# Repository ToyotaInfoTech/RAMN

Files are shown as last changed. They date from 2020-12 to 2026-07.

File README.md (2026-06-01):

# RAMN



RAMN (Resistant Automotive Miniature Network) is a miniature CAN/CAN-FD testbed of four Electronic Control Units (ECUs) consiting solely of Printed Circuit Boards. The ECUs can be programmed to emulate the same network traffic as [PASTA](https://github.com/pasta-auto/PASTA1.0), another project from our team. RAMN is powered over USB and can be recognized as a standard CAN adapter. It can be connected in closed-loop with the autonomous driving simulator [CARLA](https://github.com/carla-simulator/carla). What happens to the virtual vehicle has an impact on the physical CAN/CAN-FD bus, and vice versa. RAMN can be expanded with many stackable expansions, ranging from external quadSPI memories to Trusted Platform Modules (TPMs).

Please check the [Documentation](https://ramn.readthedocs.io/) for demonstrations and details.



## Fabricating RAMN boards

This project is open-source and RAMN boards can be fabricated by most PCB assembly prototyping services.

We have setup 're-orders' at PCBWay. 
Please [see the docs 'PCB Ordering' for more details](https://ramn.readthedocs.io/page/hardware/Fabrication/ordering.html).
You can also request a prototype from any PCB manufacturer, using the Gerber files and BOM in the Hardware folder. 

Feel free to [contact us](mailto:camille.gay@toyota.global) if you need assistance to fabricate or sell RAMN boards.

Because component availability is subject to change, we are periodically updating the hardware.
The original RAMN hardware data is available in misc/RAMN_V1_reference_PCB.zip, and is recommended for academic purposes.

## Project structure
### Hardware folder
Contains design files, from KiCAD project files to Gerber files and BOM.

### Scripts folder

Contains various scripts to interact with the ECUs:
- Driving Simulator
- Diagnostics (UDS/KWP2000/XCP)
- Hardware Bootloader
- Connection to a virtual CAN Network

### Firmware folder
Contains firmware source code for RAMN's ECUs.

## License
Please check the LICENSE.md file for more details.

## Contact
Feel free to [contact us](mailto:camille.gay@toyota.global) if you have questions.
Videos available [here](https://twitter.com/ramn_auto).

Copyright (c) 2026 TOYOTA MOTOR CORPORATION. ALL RIGHTS RESERVED.

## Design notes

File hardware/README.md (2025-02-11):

Please [see the docs 'Hardware' for more details](https://ramn.readthedocs.io/page/hardware.html).

# Creating New Orders from Updated Design Files

The PCBWay re-orders in the docs are based on the design files in this repo at commit dca0831d852cdd53b45b3e2c7c4c0430066c91ad . When changes are made to the design files here and new orders need to be made, the following procedure should be followed to created updated versions of the files in `orders/`:

[Install `kikit`](https://yaqwsx.github.io/KiKit/latest/installation/intro/) and run the script `make_orders.{bat|sh}` here from within KiCad 7.0 shell or [KiCad 7.0](https://yaqwsx.github.io/KiKit/latest/installation/intro/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) and follow the manual steps required printed to the console.

# Design Files

This project contains KiCAD projects for RAMN's hardware.

'Mainboard':
* 0_ramn

and 'Expansions':
* 1_screens
* 2_chassis
* 3_powertrain
* 4_body
* 5_debugger

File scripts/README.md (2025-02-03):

# Scripts

## Content

This folder contains various scripts to interact with RAMN over USB.

- the **build** folder contains scripts to automatically compile firmware for all 4 ECUs.
- the **carla** folder contains scripts to connect RAMN to the driving simulator CARLA.
- the **diagnostics** folder contains scripts to interact with RAMN's ECU over UDS, KWP and XCP.
- the **firmware** folder contains most recently built firmware files.
- the **settings** folder contains environment settings (e.g., serial port name, paths, etc.).
- the **STBootloader** folder contains scripts to interact with STM32 hardware bootloader.
- the **tests** folder contains scripts to perform reliability tests.
- the **vcand** folder contains scripts scripts to connect RAMN to a socketCAN virtual network (Linux only).

## Usage

Modify files in the **settings** folder to match your environment. After that, it should be possible to run the scripts without any argument.

*Copyright (c) 2025 TOYOTA MOTOR CORPORATION. ALL RIGHTS RESERVED.*

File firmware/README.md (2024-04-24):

# RAMN Firmware

This folder contains the firmware for RAMN V1. 
Documentation is available [here](https://ramn.readthedocs.io/en/latest/).

Copyright (c) 2024 TOYOTA MOTOR CORPORATION. ALL RIGHTS RESERVED.

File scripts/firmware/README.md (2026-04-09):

# Firmware

This folder contains firmware files for RAMNs ECUs. By default, this folder is used as output for the **build** scripts, and as input by the reprogram/verify **diagnostics** scripts.

## Variant firmware

Pre-built `.hex` files for firmware variants are available in subdirectories:

| Directory | Description |
|---|---|
| `gsusb/`  | GS_USB (candleLight) mode enabled on ECU A |
| `kwp/` | KWP2000 protocol enabled |
| `uart/` | UART enabled (CDC & USB disabled) |
| `watchdog/` | Hardware watchdog enabled |
| `no_uds/` | UDS and reprogramming disabled |
| `no_extras/` | J1979, MiniCTF, CHIP8, screen, SPI disabled |
| `no_debug/` | USB debug, joystick, screen, CHIP8, runtime stats disabled |
| `no_dynamic_bitrate/` | Dynamic CAN bitrate switching disabled |

Each subdirectory contains `ECUA.hex` through `ECUD.hex` for that variant configuration.
These files are automatically updated by CI on every push to `main`.

*Copyright (c) 2021 STMicroelectronics. All rights reserved.*
*Copyright (c) 2021 TOYOTA MOTOR CORPORATION. ALL RIGHTS RESERVED.*

**This software component is licensed by ST under BSD 3-Clause license, the "License"; You may not use this file except in compliance with the License. You may obtain a copy of the License at: opensource.org/licenses/BSD-3-Clause**

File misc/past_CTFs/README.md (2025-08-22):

# PAST CTFs DATA

This folder contains data to replay past CTFs that used RAMN as a platform for some of their challenges.

Write-ups are available in [RAMN's documentation](https://ramn.readthedocs.io/en/latest/ctf_writeups.html). 

# Recommended Order

If you are new to CTFs, we recommend that you tackle past CTFs in the following order:

- Automotive CTF Japan 2024 (Mostly Easy to Medium).
- Automotive CTF 2024 (Mostly Medium to Difficult).
- CHV2024 (Mostly Difficult to Very Difficult).
- ESV2025 (Mostly Difficult, not automotive related).
- ESV2024 (Mostly Very Difficult, not automotive related).

# Required Tools

A few challenges may require external hardware to complete (such as a CAN adapter, a UART/SPI/I2C/JTAG adapter, or a logic analyzer).
You can identify such challenges by their tags (e.g., "Hardware", "UART", "I2C", etc.).

# How To Flash CTF Firmware

Replace ``scripts/firmware`` with the ``firmware`` folder inside the CTF folder that you want to replay, then reflash the board using the scripts in ``scripts/STbootloader``.
On Linux, you may need to convert the ECUA.hex file to a .bin file (e.g., using ``objcopy -I ihex -O binary ECUA.hex ECUA.bin``).

The CTF firmware for ECU A may not have the abilitity to flash other ECUs, therefore **you must flash ECU B/C/D first, then flash ECU A**
(ECU A must be flashed with the original firmware to enable it to flash other ECUs).

# How To Revert RAMN to its Original Firmware

Firmware files have been recompiled in order to allow ECU A to go back to DFU mode and allow USB reflashing (a feature that was disabled during actual events).
To reset your RAMN board to the original firmware, revert ``scripts/firmware`` to its original content, then use the scripts in  ``scripts/STbootloader`` to reflash the ECUs.
**You must reflash ECU A first**.

**The ESV firmware does not start in slcan mode - you must first open a USB serial terminal and type ``selfdestruct``, which will put ECU A back in DFU mode**.

# About Memory Protection

To prevent flag dumping, STM32's (temporary) memory protection was typically activated for every ECU during the events. 
You can enable memory protection with the following commands, but note that **this is not required.** 

```
python ..\canboot.py AUTO B -rp
python ..\canboot.py AUTO C -rp
python ..\canboot.py AUTO D -rp --reset
```

You can use ``scripts/STbootloader/windows/Unlock_BCD.bat`` to remove that protection.
A JTAG adapter is required if you want to enable/disable memory protection for ECU A.

# About File Attachments

Some challenges have ECU firmware with redacted flags as an attachment.
As explained above, ECU A firmware was recompiled to allow it to revert to DFU mode. However, attachments correspond to the original firmware used in the event.
As a result, the redacted firmware files provided as attachments may not exactly match the flashed firmware files.

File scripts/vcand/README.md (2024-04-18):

# RAMN VCAND

This folder contains experimental scripts to connect RAMN to a socketCAN virtual CAN Network, while keeping the original serial interface accessible.

This feature is only available on Linux. It is similar to [slcand](https://github.com/linux-can/can-utils/blob/master/slcand.c), but with additional features:
- Supports CAN-FD
- Can forward the original serial I/O to one or two virtual serial port(s) (e.g., */dev/pts/x*)

Refer to [RAMN's documentation](https://ramn.readthedocs.io/) for details.

# Other

*Copyright (c) 2024 TOYOTA MOTOR CORPORATION. ALL RIGHTS RESERVED.*

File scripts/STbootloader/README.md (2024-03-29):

# Canboot

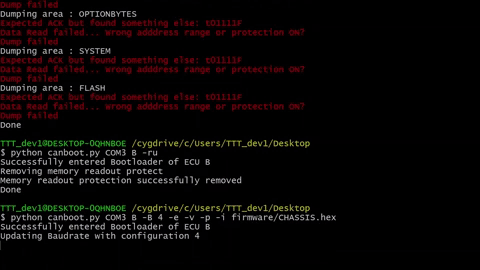
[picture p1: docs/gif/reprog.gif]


Canboot is a tool written in python to reprogram RAMN's ECUs over CAN using STM32's built-in CAN or CAN-FD bootloader. 

It can be used to reprogram ECUs B, C, and D. 

ECU A can be reprogrammed using DFU over USB.

Check the [Documentation](https://ramn.readthedocs.io/en/latest/hardware/Fabrication/flashing.html) for details.

## Usage

Usage is described in the help command of the script.

```
$python canboot.py --help
```

Helper scripts are located in **linux** and **windows** folder, to reprogram ECUs with the firmware files located  in the **firmware** folder. They require to input the serial port manually.

## Details

Microcontrollers of the STM32L5 family can be reprogrammed over CAN-FD based on STMicroelectronics [AN5405](https://www.st.com/resource/en/application_note/dm00660346-fdcan-protocol-used-in-the-stm32-bootloader-stmicroelectronics.pdf).  

Microcontrollers of the STM32L4 family can be reprogrammed over CAN based on STMicroelectronics [AN3154](st.com/resource/en/application_note/cd00264321-can-protocol-used-in-the-stm32-bootloader-stmicroelectronics.pdf). Script for classic CAN is located in the BETA folder.

Microcontrollers of the STM32L4/STM32L5 can be reprogrammed over USB (DFU) based on STMicroelectronics [AN3156](https://www.st.com/resource/en/application_note/cd00264379-usb-dfu-protocol-used-in-the-stm32-bootloader-stmicroelectronics.pdf).

## DFU (ECU A)

Script ECUA_goToDFU.py can be used to ask ECU A to go into DFU mode.

```
$python ECUA_goToDFU.py <serial_port>
```

ECU A can then be reprogrammed on Linux with dfu-util, or on Windows with STM32_Programmer_CLI.exe

### Linux

```
$dfu-util  -d 0x0483:0xdf11 -c1 -a0 -D ECUA.bin --dfuse-address 0x08000000:leave	
```

### Windows

```
$STM32_Programmer_CLI.exe -c port=usb1 pid=0xdf11 vid=0x0483 -d ECUA.hex --verify --start 0x08000000 
```

## Other

*Copyright (c) 2024 TOYOTA MOTOR CORPORATION. ALL RIGHTS RESERVED.*

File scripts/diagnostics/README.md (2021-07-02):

# Diagnostics Tools

This folder contains various Python scripts to interact with RAMN's Diagnostics interface: UDS, KWP2000 and XCP.

## Usage

Modify either **settings/linux.ini** or **settings/windows.ini** based on your platform.

Scripts may be run without arguments.

## Example Scripts

### UDS

Following example scripts can be used to test UDS features:

- **UDS_DumpMemory.py** dumps RAMN's ECUs' readable areas of memory (RAM and FLASH)  into a single hex file, and various .bin files located in individual folders.
- **UDS_LoadTest.py** sends large ISO-TP frames back and forth between RAMN's ECUs to ensure that high speed communication is reliable.
- **UDS_PrintInfo.py** prints information of RAMN ECUs that can be obtained with ReadDataByIdentifier (VIN, Firmware Compile Time, Microcontroller Serial Number, Memory CRC, etc.).
- **UDS_Reprogram.py** reprograms RAMN's ECUs with the firmware files, which path is provided in the .ini fils.
- **UDS_Verify.py** verifies that the firmware files which path is provided in the .ini file, are correctly flashed in RAMN's ECUs.
- **UDS_WriteVIN.py** writes the VIN provided inside the python script in RAMN's ECUs.

### KWP2000

Following example scripts can be used to test KWP2000 features:

- **KWP_DisableNormalTransmission.py** disables periodic sending of CAN messages for RAMN ECUs.
- **KWP_EnableNormalTransmission.py** re-enables periodic sending of CAN messages for RAMN ECUs. Especially, it may prove useful if a previous script that turned off communications was interrupted before it was able to re-enable communications.
- **KWP_TesterPresent.py** sends and receives a Tester Present Frame.

### XCP

Following example scripts can be used to test XCP features:

- **XCP_DumpMemory.py** uses the SET_MTA and UPLOAD commands to dump readable areas of RAMN ECU's memory. Areas dumped are identical to those dumped by **UDS_DumpMemory.py**.
- **XCP_ReadECUInfo.py** uses XCP commands to readout XCP information from RAMN's ECUs.

### CAN

Following script is provided for convenience:

- **CAN_ResetRXFilter.py** resets the CAN filter of ECU A. Can be useful if a script that uses a specified filter was interrupted before it had to reset the filter itself.

## Other

*Copyright (c) 2021 TOYOTA MOTOR CORPORATION. ALL RIGHTS RESERVED.*

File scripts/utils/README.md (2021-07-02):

# Utils

This folder contains various helper scripts used by other scripts.

*Copyright (c) 2021 TOYOTA MOTOR CORPORATION. ALL RIGHTS RESERVED.*

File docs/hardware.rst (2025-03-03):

.. _hardware:

Hardware
========

This page gives details about RAMN's hardware.
If you need help designing your own hardware expansion, check the :ref:`creating_expansion` section.

.. toctree::
   :maxdepth: 2

   hardware/overview
   hardware/expansions
   hardware/fabrication
   hardware/schematics

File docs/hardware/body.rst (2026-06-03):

.. _body_expansion:

Body
====

The BODY expansion is the expansion associated with ECU D, and is used to realize two simple functions usually in the BODY domain of a car:

* Engine Key
* Lights

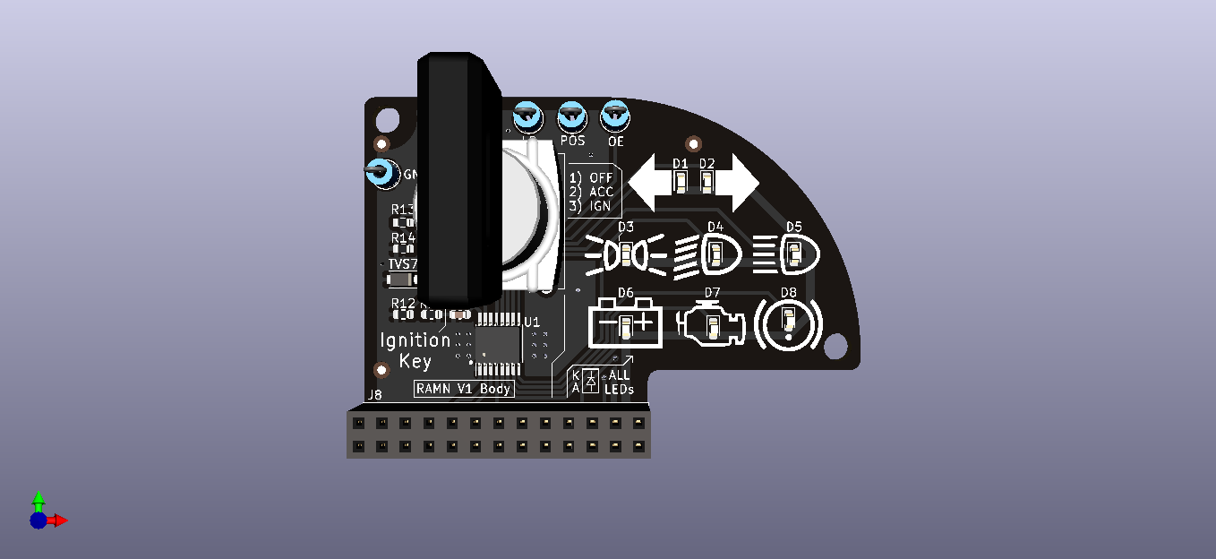
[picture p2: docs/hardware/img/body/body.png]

   
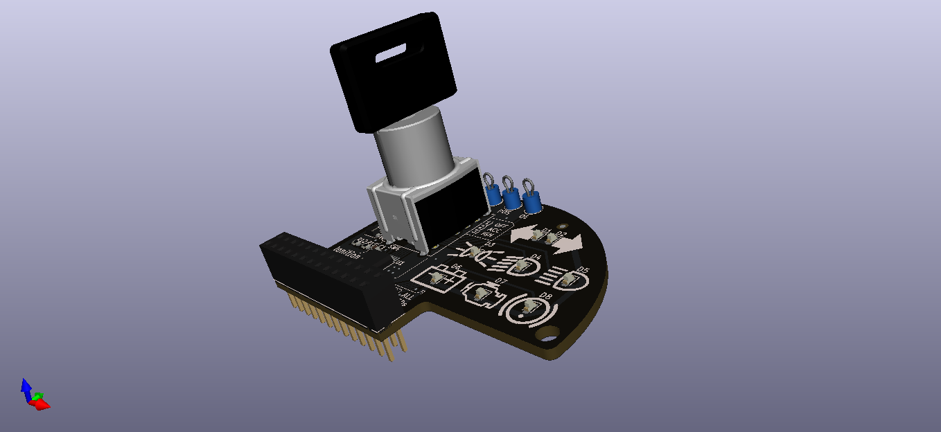
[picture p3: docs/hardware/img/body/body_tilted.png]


Engine Key
----------

The Engine key has three positions which are assigned to:

* Engine OFF
* Accessory
* Ignition

The engine key is simulated by a `SK14EG13 <https://www.nkkswitches.com/pdf/SK_PCBmountMiniature.pdf>`_ from NKK switches. The SK14EG13 is an `SP3T switch <https://en.wikipedia.org/wiki/Switch#Contact_terminology>`_ (Single Pole, Triple Throw).
The schematic is therefore rather simple:

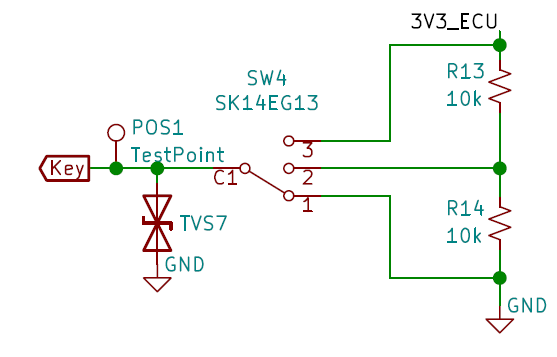
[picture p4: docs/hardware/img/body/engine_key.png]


	Schematic of the Engine Key circuitry

The rotation of the key selects a point from a `voltage divider <https://en.wikipedia.org/wiki/Voltage_divider>`_ (Position 1 -> 0V, Position 2 -> 1.65V, Position 3 -> 3.3V), which is measured by an ADC on the ECU.
A `TVS diode <https://en.wikipedia.org/wiki/Transient-voltage-suppression_diode>`_ is used for ESD protection, since the key is expected to be manipulated by the user.

Lights
------

The lights are simulated by 8 LEDs (D1~D8) located near silkscreen markings resembling dashboard symbols:

* Left Turn Indicator *(D1 - Output 6)*
* Right Turn Indicator *(D2 - Output 7)*
* Tail Lamp *(D3 - Output 3)*
* Low Beam *(D4 - Output 4)*
* High Beam *(D5 - Output 5)*
* Battery Warning *(D6 - Output 0)*
* Check Engine *(D7 - Output 1)*
* Parking Brake *(D8 - Output 2)*

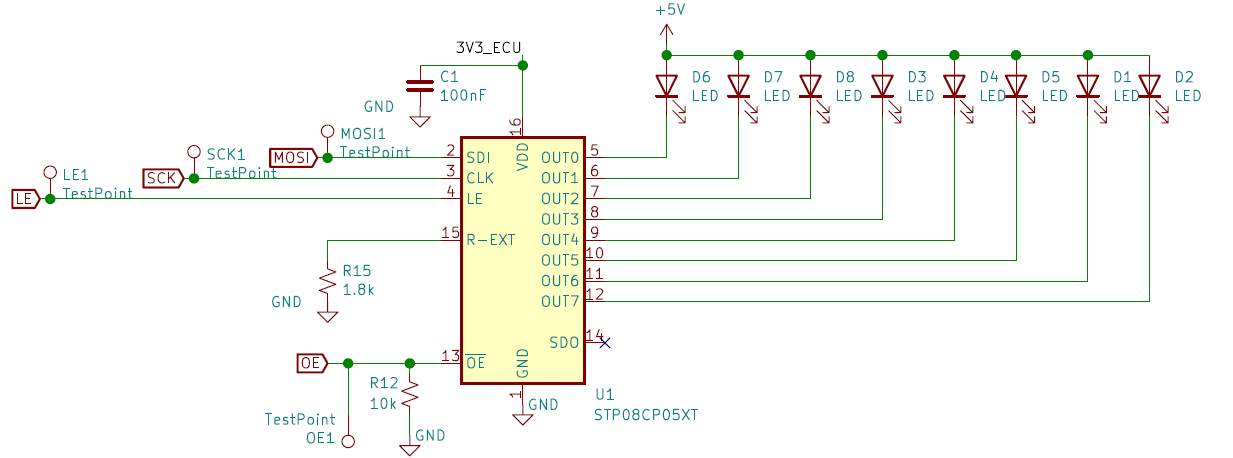
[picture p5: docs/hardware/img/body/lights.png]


	Schematic of the Lights circuitry

The LEDs are driven by a `STP08CP05 <https://www.st.com/resource/en/datasheet/stp08cp05.pdf>`_ IC. The STP08CP05 is an LED driver controlled by a simple `shift-register <https://en.wikipedia.org/wiki/Shift_register>`_ circuit. In practice, the STP08CP05 is controlled by the SPI output of ECU D, and is multiplexed with other SPI devices. The SPI signals can easily be accessed through external probes.

Communications are done in 3.3V, but the LEDs are powered from the 5V line. R15 is used to set the current (~10mA). 

The Output Enable (OE) pin is pulled-down, so the STP08CP05 is active from start-up, which may result in some flickering when powering-up. This behavior is preferable to losing a GPIO from the ECU.

LEDs are in a 0603 package. LEDs in this type of package are available in many colors.

.. note:: Although LEDs are available in many different colors, LEDs of different color typically require different currents to reach the same intensity (even if they come from the same series). When selecting LEDs of different colors, please check the recommended current and ensure they are close enough.

Pinout
------

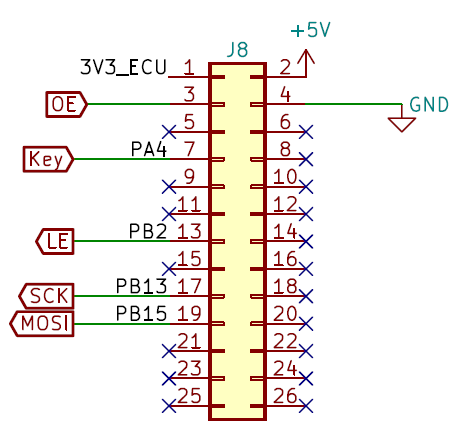
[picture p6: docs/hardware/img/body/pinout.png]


	Pinout of the BODY expansion's connector

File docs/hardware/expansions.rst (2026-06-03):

.. _expansions:

Expansion Port
==============

The ECU expansion port is a 26-pin socket:

- RAMN's main PCB main uses **M20-7831346** connectors (2.54mm pitch, two 13-pin rows).
- ECU A expansion (connected vertically) uses an **Amphenol 68021-226HLF** connector.
- ECU B, C, and D expansions (connected horizontally) use **SAMTEC SSQ-113-03-G-D** connectors (SSQ-113-23-L-D, SSQ-113-23-F-D, SSQ-113-23-T-D should also be compatible).

All ECUs share a common hardware peripheral configuration, so that programming is easier and misconfigurations are less likely to happen.
For example, the PA1 pin is always configured as an ADC. In the chassis expansion, it is connected to the steering wheel potentiometer.
In the powertrain expansion, it is connected to the brake potentiometer. Each expansion has different sensors and circuitry, but the ECUs still share the same peripheral configuration.
This also means that binary inputs (such as the side-brake) are treated as ADC inputs instead of simple GPIO inputs.

Designing a Custom Expansion
----------------------------

You can use **SAMTEC SSQ-113-03-G-D** connectors to create new expansions stackable with other expansions (see :ref:`expansions_demo`), as long as you avoid conflicts.
To get started, we recommend that you make a copy of the debugger expansion in the `hardware/V1_revB/5_debugger` folder and modify it with `KiCAD <https://www.kicad.org/>`_.
This expansion uses the stackable **SAMTEC SSQ-113-03-G-D** connector, and already features all possible signals - simply delete what you do not need.

The following pins are connected to power supplies:

- **Pin 1:** 3V3 (unique per ECU).
- **Pin 2:** 5V (directly connected to USB, common to all ECUs).
- **Pin 4:** Ground.

The following pins are **actively used** by the original RAMN expansions:

- **Pin 3  (PA1):** ADC (ECU B, C, D) - *connected but unused by ECU D*.
- **Pin 7  (PA4):** ADC (ECU B, C, D).
- **Pin 8  (PA5):** ADC (ECU B, C).
- **Pin 13 (PB2):** CS pin for SPI2 communications (ECU A display or ECU D LED driver).
- **Pin 16 (PB12):** GPIO output, ST7789 display DC pin (ECU A) or LED driver LE pin (ECU D).
- **Pin 17 (PB13):** SPI2 SCK (ECU A, D).
- **Pin 18 (PB14):** SPI2 MISO (ECU A) - *currently unused but reserved for future use*.
- **Pin 19 (PB15):** SPI2 MOSI (ECU A, D).

The following pins are always **free and can be used to create new expansions** compatible with any RAMN ECU.
**Some pins are pre-configured for your convenience, but you may use them in any configuration you want:**

- **Pin 5 (PA2):** 	free, pre-configured as LPUART1_TX.
- **Pin 6 (PA3):** 	free, pre-configured as LPUART1_RX.
- **Pin 9 (PA6):** 	free.
- **Pin 10 (PA7):** 	free.
- **Pin 11 (PB0):** 	free.
- **Pin 12 (PB1):** 	free.
- **Pin 14 (PB10):** 	free, pre-configured as I2C2_SCL.
- **Pin 15 (PB11):** 	free, pre-configured as I2C2_SDA.
- **Pin 20 (PA8):** 	free, pre-configured as additional SPI CS pin.

Although **PB13**, **PB14**, and **PB15** are already used, SPI protocol supports multiplexing, so you can reuse them for your expansion too, but only for SPI communications.
You only need to assign one **CS pin** per SPI device that you want to connect, and reuse the already defined **SPI2 SCK (PB13)**, **SPI2 MOSI (PB15)**, and **SPI2 MISO (PB14)** pins.
Note that for ECU A and D, you will need to share the SPI bandwidth, but it is possible to limit the original expansions' bandwidth to a minimum).

**If you need help selecting pins, read** :ref:`creating_expansion`.
Refer to the `STML552 datasheet <https://www.st.com/resource/en/datasheet/stm32l552cc.pdf>`_ (Table 21) for pin capabilities.
Typically, you can use the following interfaces:

- **LPUART1** (UART interface).
- **I2C2** (I2C interface, master or device).
- **SPI2** (SPI interface. On ECU A and D, you must share the bus with the existing application).
- **OCTOSPI1** (**NOT** regular SPI, but an interface typically used for external flash).
- **ADCs** (Analog-to-digital converters)
- **Timers/PWMs** (input or output).
- **GPIOs** (input or output).
- **External interrupts**.

.. warning::

	Although most interfaces are available simultaneously, there are a few conflicts, so remember to check for compatibility issues (see :ref:`creating_expansion`):
	
	- OCTOSPI1 cannot be used simultaneously with I2C2.
	- For ECU A and D, SPI2 can only be used in master mode.
	- If you want to use the (currently unused) SD Card reader on ECU A's screen expansion, you need to use PB10 as the SD Card SPI CS pin.

If the available pins are not enough, **consider making expansions compatible with only one ECU** (e.g., you can make an expansion that reassigns **PA1**, **PA2** and **PA5**, but that expansion will only be compatible with ECU A, and you will need to use a different peripheral configuration for ECU A).

.. warning::

	Avoid drawing more than a few mA from the 3V3 pin, because it is directly connected to the power supply of the ECU, which has limited capacity.
	Instead, you should draw power from the 5V pin, which is directly connected to the USB 5V line.

.. _expansion_pinout:

Pinout
------

The expansion port pinout is shown below.

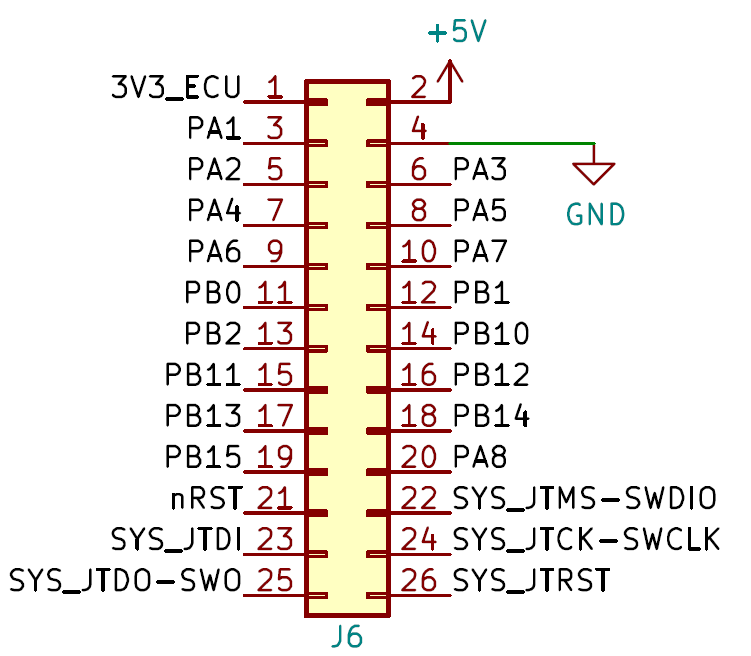
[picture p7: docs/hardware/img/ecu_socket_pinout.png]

   
   ECUs expansion port connections.

The pinout is the same for all ECUs. They are oriented differently depending on their location on the board.
Refer to the following KiCAD screenshots to ensure that you have the correct orientation.

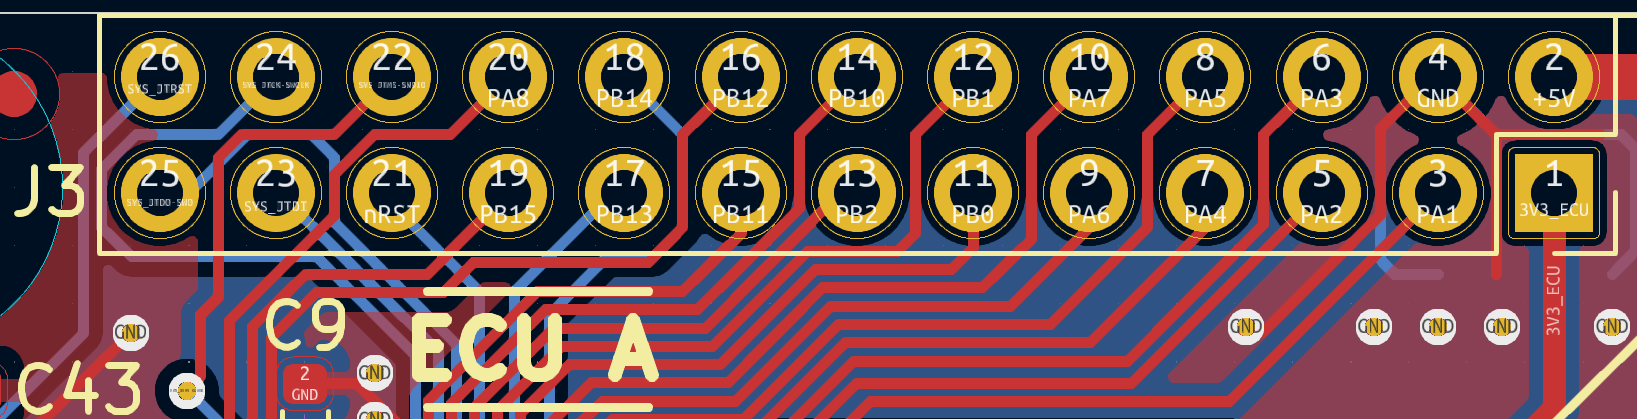
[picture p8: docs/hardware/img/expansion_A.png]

   
   Layout of ECU A's expansion port.

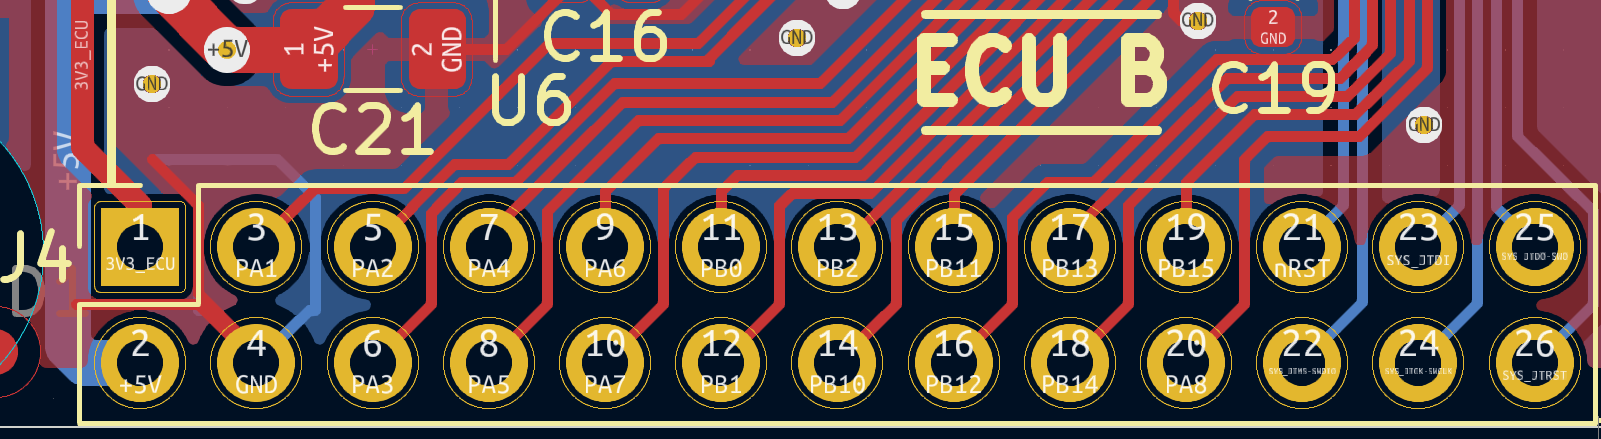
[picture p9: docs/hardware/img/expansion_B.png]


   Layout of ECU B's expansion port.

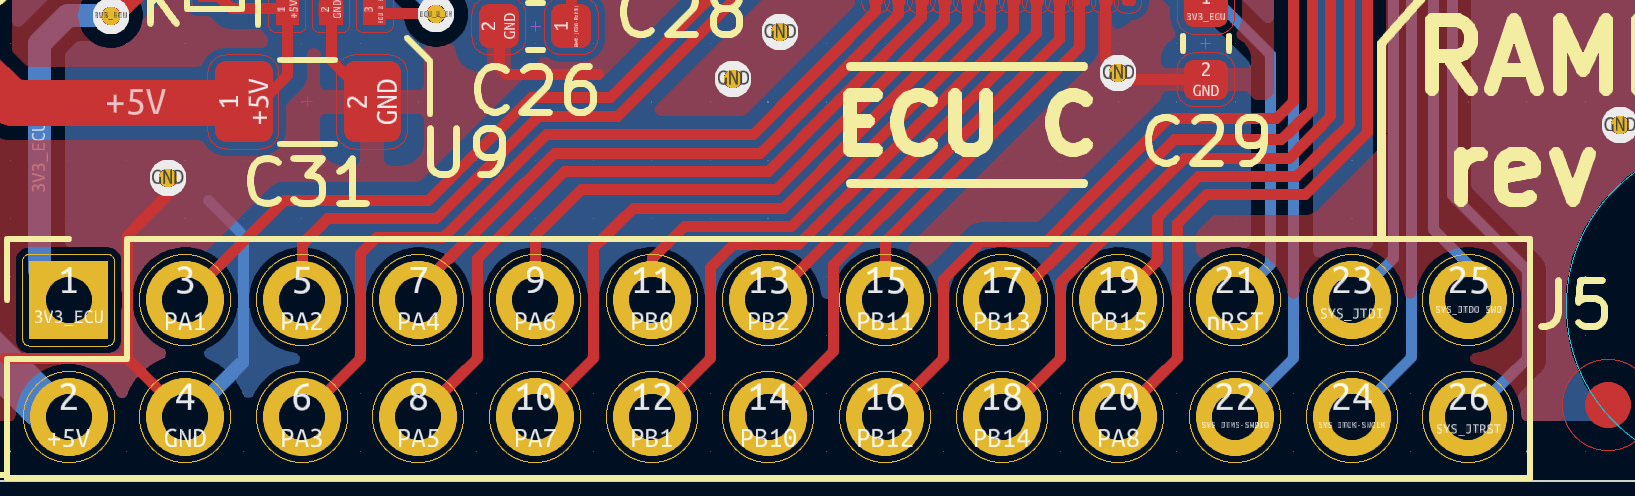
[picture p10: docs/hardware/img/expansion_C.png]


   Layout of ECU C's expansion port.

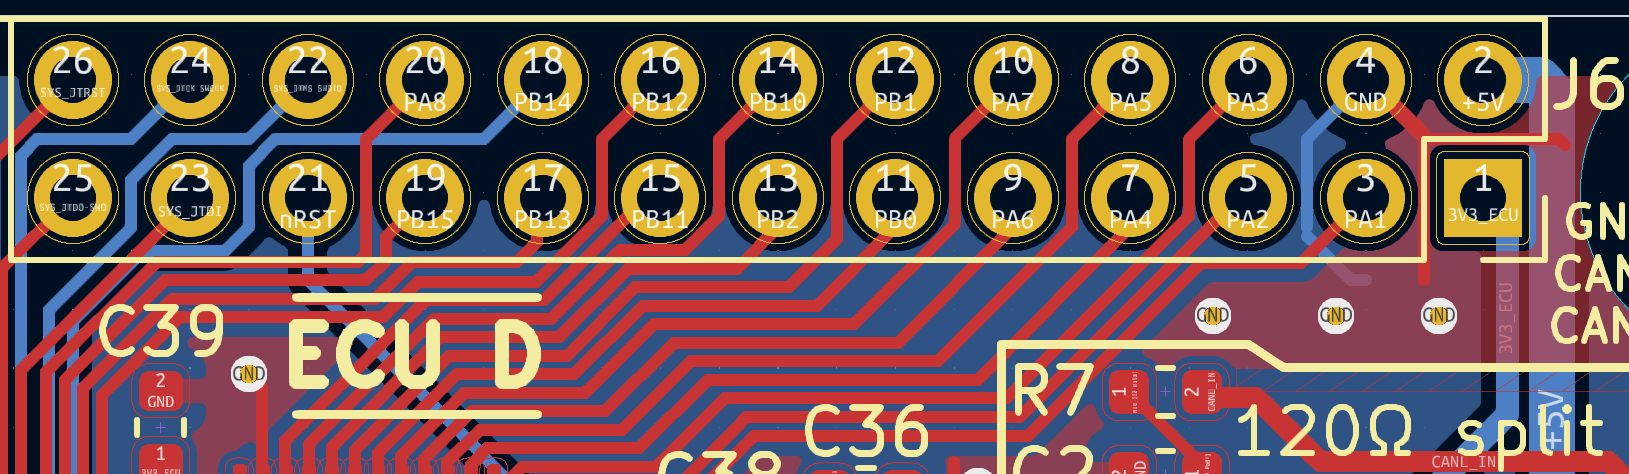
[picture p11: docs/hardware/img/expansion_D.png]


   Layout of ECU D's expansion port.

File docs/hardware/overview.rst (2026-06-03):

.. _hardware_overview:

Overview
========

CAD Software
------------

PCBs are designed using `KiCAD <https://kicad.org/>`_, which is an open-source tool for PCB design.
Design files can be found in the `hardware/V1_revB` folder of the `Github repository <https://github.com/ToyotaInfoTech/RAMN>`_:

- `0_ramn` contains design data for RAMN's main PCB.
- `1_screens` to `5_debuggers` contain design data for RAMN's expansions.



   PCB CAD view of RAMN in KiCAD

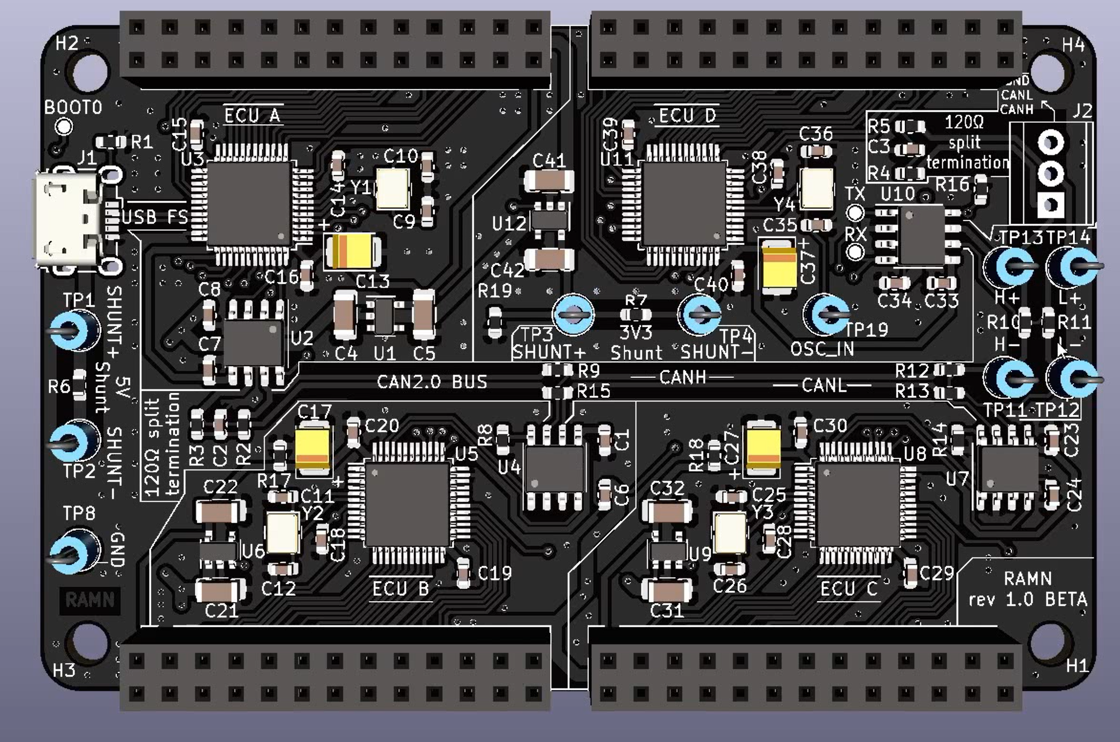
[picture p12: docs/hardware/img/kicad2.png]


   3D view of RAMN in KiCAD

Design
------

RAMN's main board is a credit-card size PCB with 4 ECUs, a CAN FD bus and a USB port.

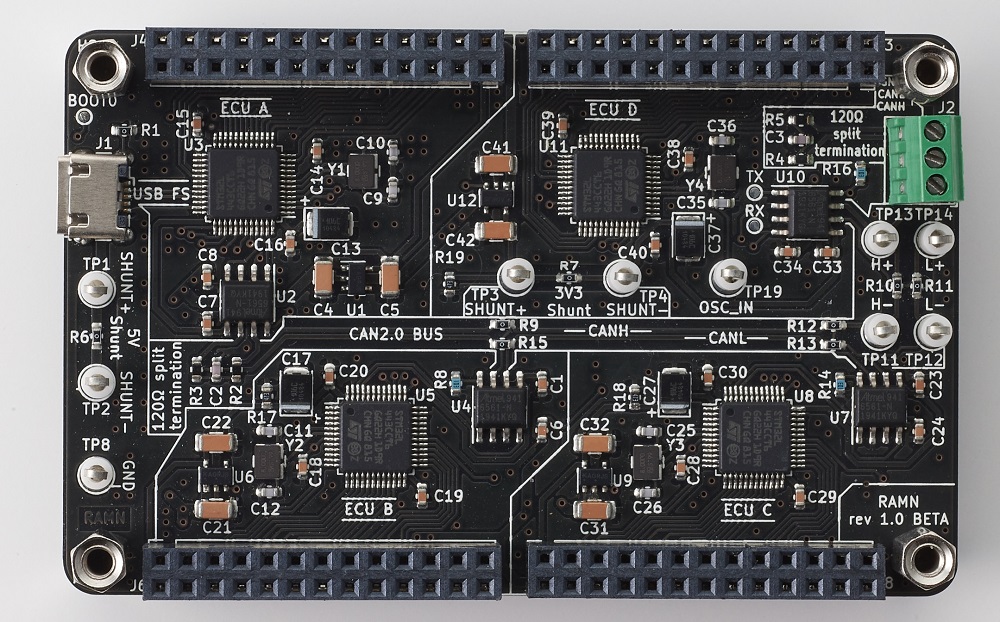
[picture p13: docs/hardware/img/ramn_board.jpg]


   Main board of RAMN

RAMN's main board can be expanded with expansions boards to add features such as sensors and actuators.

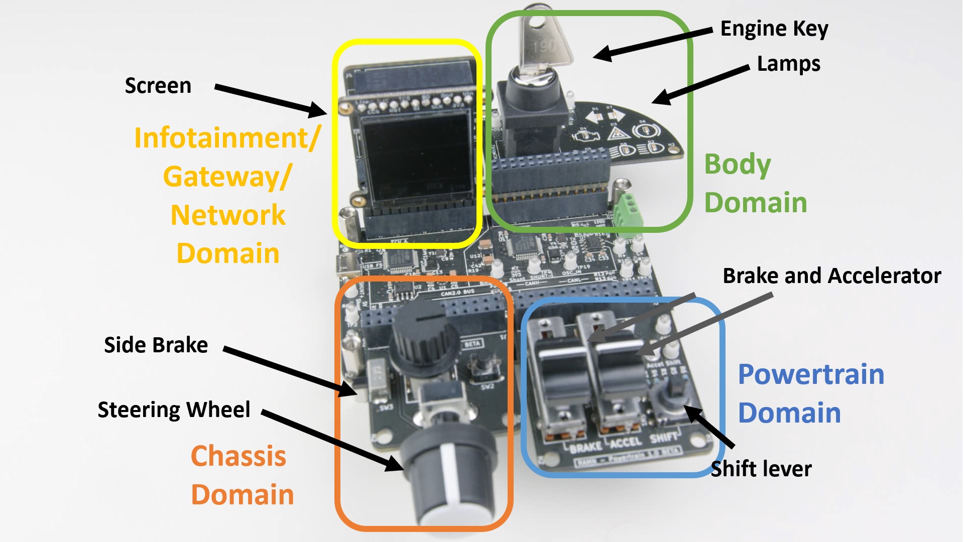
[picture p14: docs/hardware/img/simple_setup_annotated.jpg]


   Simple setup of RAMN with 4 expansions: SCREENS (GATEWAY), CHASSIS, POWERTRAIN, BODY.

ECUs (Electronic Control Units)
*******************************

There are 4 ECUs on RAMN (ECU A, ECU B, ECU C, and ECU D), and they all share a common design:

* :ref:`An individual power supply <powersupply>`
* :ref:`A Microcontroller <microcontroller>`
* :ref:`A CAN FD transceiver <canphy>`
* :ref:`An expansion port <expansions>`

ECU A additionally features a USB connection. The USB port is the main 5V power supply for the whole board, and is also used as a means to reprogram all ECUs.
ECU A has 6 `GPIOs <https://en.wikipedia.org/wiki/General-purpose_input/output>`_ that are used to control:

* The power supply of ECU B, ECU C, and ECU D
* The boot mode (BOOT0 pin) of ECU B, ECU C, and ECU D

ECU D has an additional `shunt resistor <https://en.wikipedia.org/wiki/Shunt_(electrical)#Use_in_current_measuring>`_ and clip-on probes for easier measurements.

CAN/CAN FD bus
**************

RAMN features a `CAN FD <https://en.wikipedia.org/wiki/CAN_FD>`_ bus that connects the 4 ECUs and is terminated on both sides by `120 ohm split-terminations <https://e2e.ti.com/blogs_/b/industrial_strength/posts/the-importance-of-termination-networks-in-can-transceivers>`_.

**By default, RAMN only uses classic CAN messages and can be used with classic CAN controllers.**

The CAN FD bus features `shunt resistors <https://en.wikipedia.org/wiki/Shunt_(electrical)#Use_in_current_measuring>`_ and clip-on probes for easier measurements as well.

The CAN FD bus can be accessed from outside through a `terminal block <https://en.wikipedia.org/wiki/Screw_terminal>`_.

Block Diagrams
**************

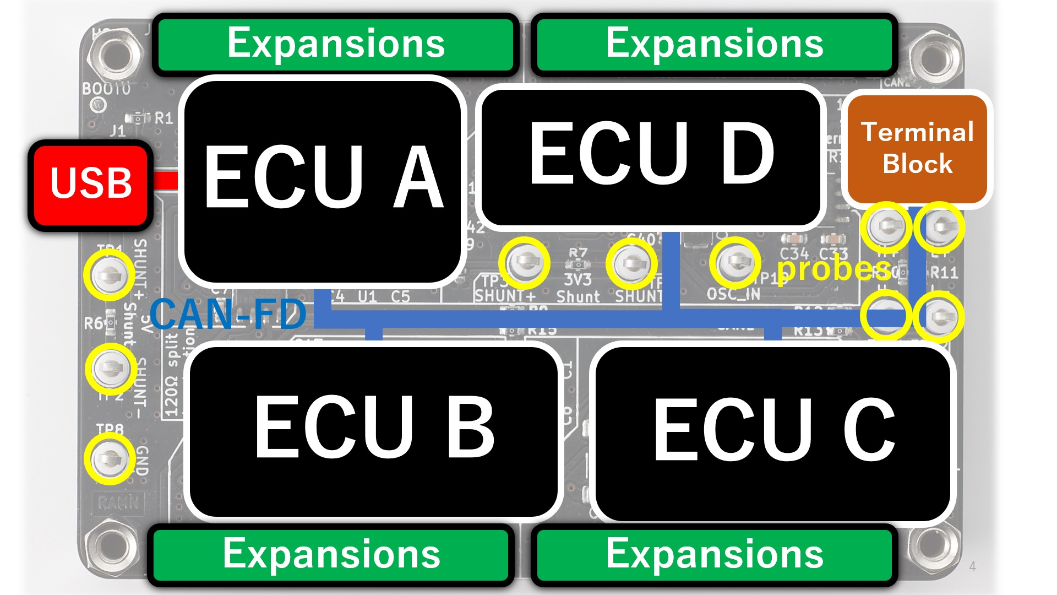
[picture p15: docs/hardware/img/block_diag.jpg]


   Simple Block diagram of RAMN's main board.

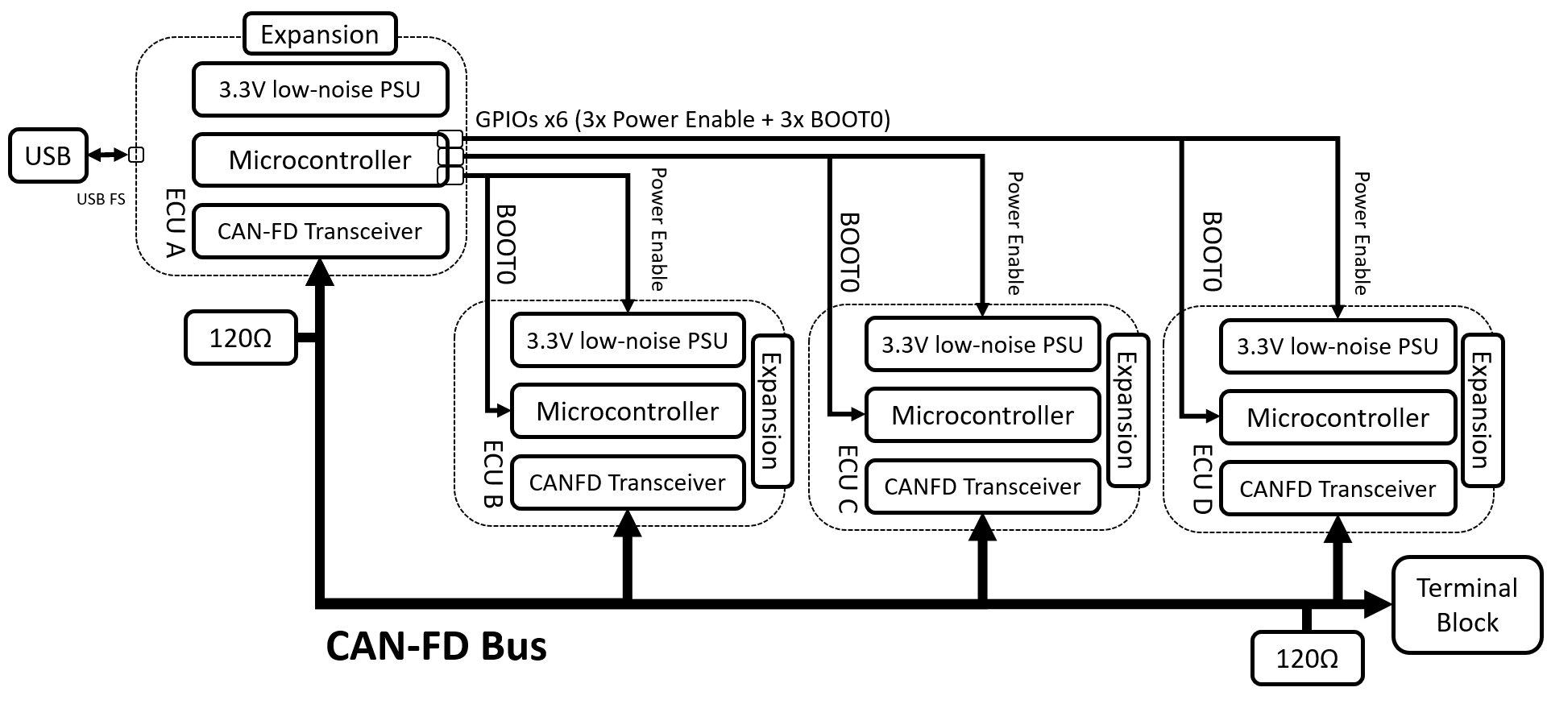
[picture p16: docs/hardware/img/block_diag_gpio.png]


   Block Diagram of RAMN showing connection between ECUs.

Hardware Design Rules
---------------------

Guidelines
**********

RAMN aims to promote education and research in automotive systems. To stay close to automotive electronics, we use AEC-Qxxx grade 0 (or equivalent) components for the ECU network board. To keep the board small and affordable, many protections (e.g. ESD protection, pull-up/pull-down resistors, etc.) are omitted, and the board would not meet reliability levels required in safety-critical systems.



   Picture of RAMN PCB's front side, before components soldering.

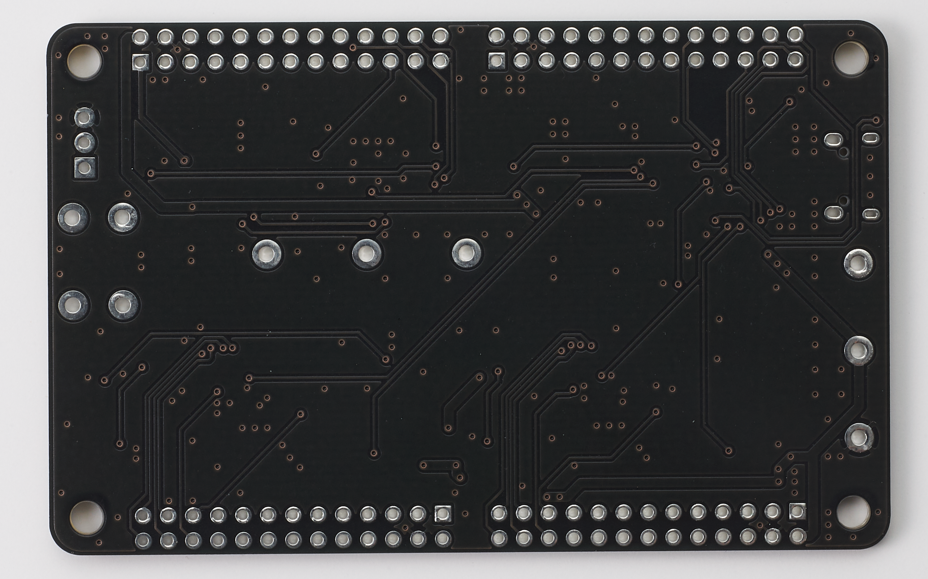
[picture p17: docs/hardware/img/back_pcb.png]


   Picture of RAMN's PCB's back side, before components soldering.

All boards are designed using only two layers, with all components on the same side. 
The boards have large manufacturing tolerances (e.g. large track width and clearance), and we restrict components to those with visible external pins, unless there really is no viable alternative.
All those elements ensure that the PCBs can be manufactured and assembled at a low cost. The board is also accessible to hobbyists who would like to fabricate and solder the board themselves.



   Design tolerances for RAMN's PCB.

.. _impedance_matching:

Impedance Matching
******************

Since frequencies involved in RAMN are relatively low, proper impedance matching is not a high priority. However, good design guidelines are followed when possible.

CAN/CAN-FD Bus
^^^^^^^^^^^^^^

Although the quality of the CAN/CAN-FD bus line is limited by the tight layout, the many connections, and the use of only 2 layers, we tried to keep a 120 ohm differential impedance on the CAN-FD bus.
More precisely, we used a trace width of 0.45mm and a spacing of 0.2mm, which according to `EEWeb's Edge Coupled Microstrip Impedance calculation tool <http://eeweb.com/tools/edge-coupled-microstrip-impedance/>`_, should lead to a 120 ohm differential impedance on a standard 35um copper 1.6mm FR-4 thick layout.

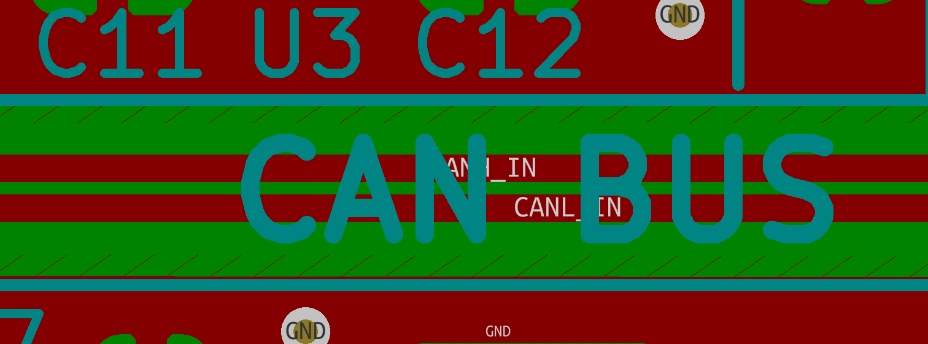
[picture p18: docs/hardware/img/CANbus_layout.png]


   Layout of the CAN-FD bus.

USB
^^^

For the USB line, no impedance matching is attempted. Instead, we follow `FTDI's recommendations for USB hardware design <http://ftdichip.com/Documents/AppNotes/AN_146_USB_Hardware_Design_Guidelines_for_FTDI_ICs.pdf>`_:

* Equal length for D+ and D-
* Ground plane under the D+ and D-
* Etc.

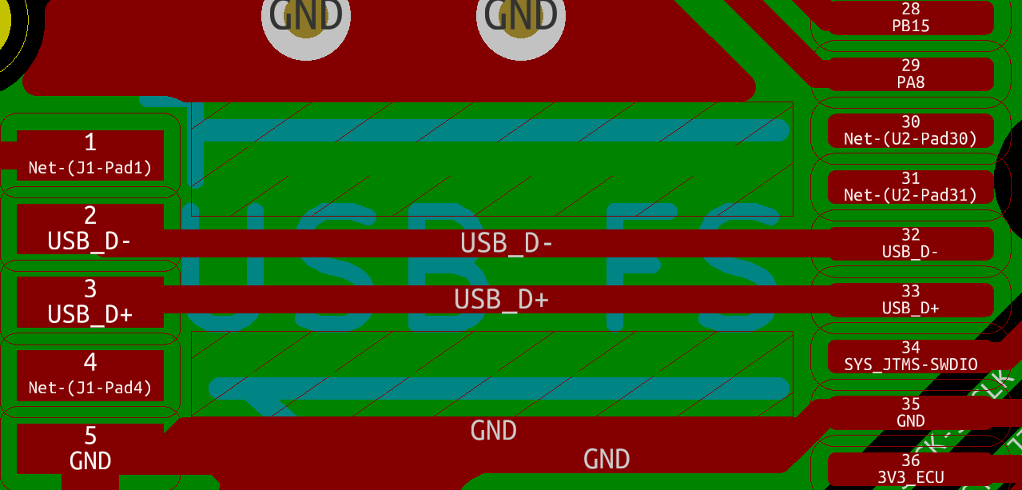
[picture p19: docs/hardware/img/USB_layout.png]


   Layout of the USB connection.

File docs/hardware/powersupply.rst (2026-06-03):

.. _powersupply:

Power Supply
============

All ECUs have their own independent power supply, but all power supplies share this common design.

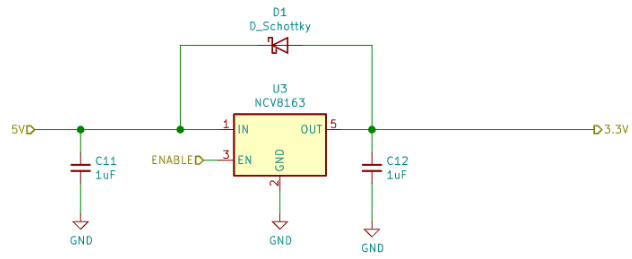
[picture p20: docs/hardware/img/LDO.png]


   Power supply used by ECUs. 

The power supply block transforms the USB 5V power supply into a 3.3V power line that is used to power the STM32L5 microcontroller of the ECU.

This operation is achieved using an `NCV8163 <https://www.onsemi.com/pdf/datasheet/ncv8163-d.pdf>`_, an `LDO <https://en.wikipedia.org/wiki/Low-dropout_regulator>`_ from ON Semiconductor.
The NCV8163 only requires 1uF capacitors at its input and output. It also features an **ENABLE** pin, which can be used to power ON and OFF ECUs individually.

The NCV8163 is an Ultra-Low Noise regulator qualified for automotive use, making it a perfect choice for studying side-channel analysis of ECUs. 
While it is designed to handle a maximum 250 mA output current, the small package (TSOP-5) and the layout of RAMN make it unlikely that it could handle the power dissipation associated with high currents. As such, the NCV8163 is only used to power the microcontroller of the ECU. 

.. warning:: Although the 3.3V line is available on the expansions pin header of each ECU, it is not advised to draw too much current from it. 
   When a 3.3V power supply is needed on an expansion board, we usually add another NCV8163 dedicated to it, ensuring stacking many boards would not lead to over-temperature conditions.

During our evaluation tests, we did not notice abnormal temperature increase, even at full CPU speed and many peripherals activated. The NCV8163 features protection against current overload, output short-circuit and overheating.
According to the `datasheet's recommendations <https://www.onsemi.com/pdf/datasheet/ncv8163-d.pdf#page=14>`_, we added an external Schottky diode to protect the NCV8163 against reverse currents. 

.. note::  Except for ECU A, all power supplies have their ENABLE pin pulled-down (= power supply OFF). ECU A must actively enable the power supply of ECU B, C, and D. ECU B, C, and D will stay unpowered if ECU A is not programmed correctly.

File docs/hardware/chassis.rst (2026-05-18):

Chassis
=======

The CHASSIS expansion is used to simulate some functions usually found in the Chassis domain of a car:

* Steering Wheel
* Parking Brake

Although not traditionally part of the Chassis domain, the lighting switch is also present in the Chassis domain.

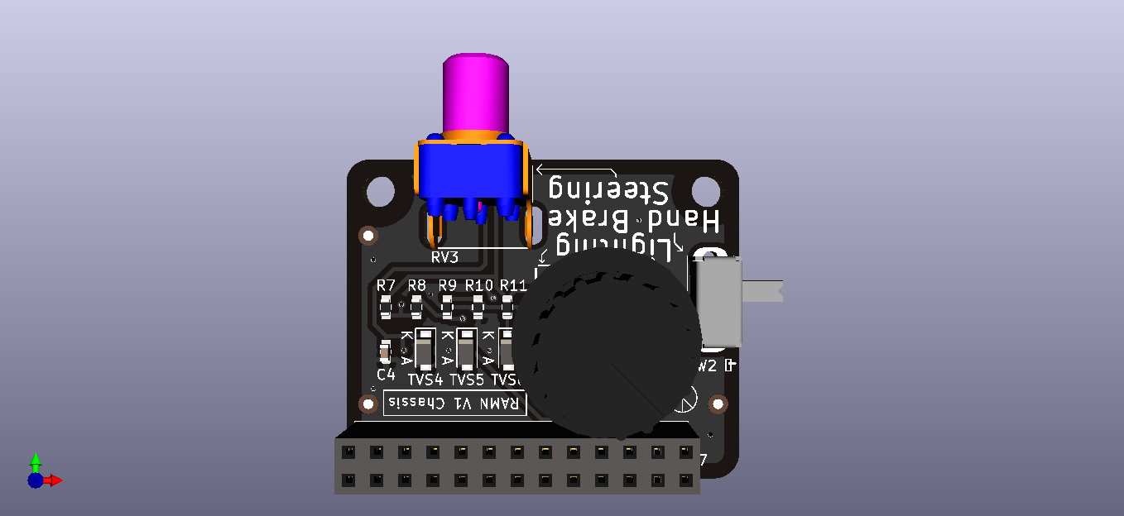
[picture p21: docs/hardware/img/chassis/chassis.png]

   
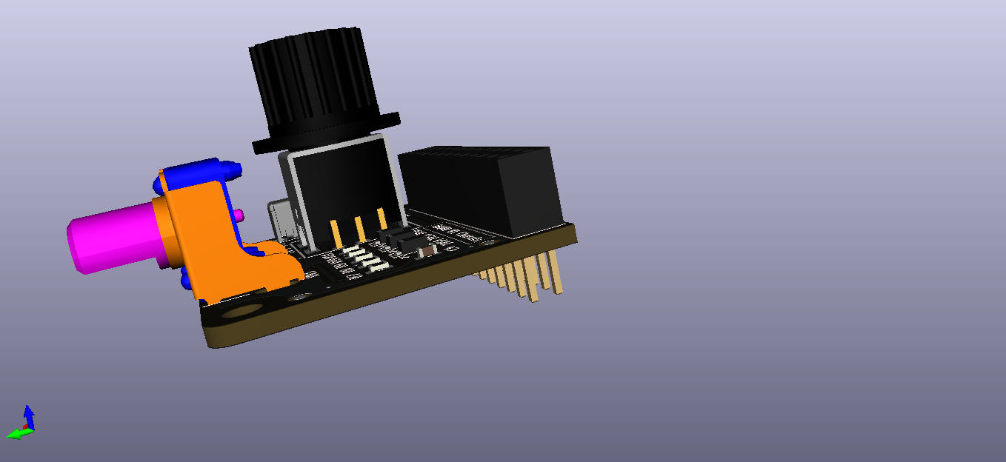
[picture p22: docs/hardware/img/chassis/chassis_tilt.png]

   
Steering Wheel
--------------

The Steering wheel is simulated by a rotating potentiometer. A `TVS diode <https://en.wikipedia.org/wiki/Transient-voltage-suppression_diode>`_ is used for ESD protection, and a capacitor also protects the ECU input from chattering.

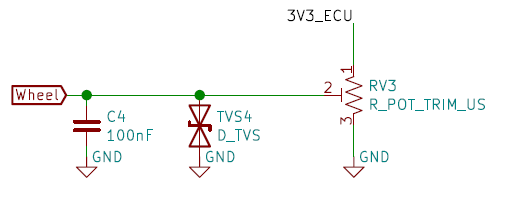
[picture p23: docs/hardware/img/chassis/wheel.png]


	Schematic of the Steering wheel circuitry
	
Parking Brake
-------------

The parking brake is simulated by a pulled-up sliding switch. A `TVS diode <https://en.wikipedia.org/wiki/Transient-voltage-suppression_diode>`_ is used for ESD protection.

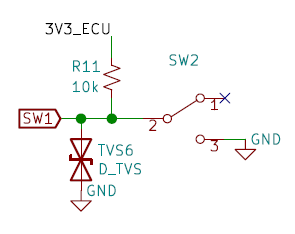
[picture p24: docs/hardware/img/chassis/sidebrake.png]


	Schematic of the Parking Brake circuitry
	
Lighting Switch
---------------

The lighting switch is simulated by a rotating switch from the `NR01 series <https://www.nkkswitches.com/pdf/NR01%20Rotaries.pdf>`_ of NKK switches. A `TVS diode <https://en.wikipedia.org/wiki/Transient-voltage-suppression_diode>`_ is used for ESD protection.
The rotation of the switch selects a point from a `voltage divider <https://en.wikipedia.org/wiki/Voltage_divider>`_ , which is measured by an ADC on the ECU.



	Schematic of the Lighting switch circuitry

Pinout
------



	Pinout of the CHASSIS expansion's connector

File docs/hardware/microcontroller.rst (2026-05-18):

.. _microcontroller:

Microcontroller
===============

.. _microcontroller_sel:

Microcontroller selection
-------------------------

The microcontrollers compatible with the most recent RAMN firmware are:

- **STM32L562CET6** (512kB flash, with hardware cryptography).
- **STM32L552CET6** (512kB flash, no hardware cryptography).
- **STM32L552CCT6** (256kB flash, no hardware cryptography).

Because STM32L552CCT6 only has 256kB flash, it does not support UDS reprogramming, but it supports other reprogramming interfaces.
The same firmware is used for all the microcontrollers above; RAMN automatically detects how much flash is available, and does not use hardware cryptography.

**RAMN's firmware does not support STM32L4 microcontrollers anymore**, but the PCB is still compatible with them. 
Old source code for STM32L4 family, used in the BETA version of RAMN, is available on request but is not maintained and has very limited features.

**RAMN is not "officially" compatible with STM32U5 microcontrollers**.
If you want to use STM32U5 microcontrollers, the only change needed is to update the PCB to add capacitors to the PB11 pins (which became "VCAP" in STM32U5 series).
The source code is mostly compatible, but many of the code generation features used with STM32L5 are unavailable with STM32U5, so some porting work is needed.
**Binary files are not compatible (you cannot flash an STM32L5 firmware to a STM32U5 device)**.
Feel free to contact us if you need guidance on how to use STM32U5 microcontrollers.

.. note:: For `STM32L microcontrollers <https://www.st.com/resource/en/datasheet/stm32l562ce.pdf#page=336>`_, the last four letters of the part number are used to specify:

   * Pin count (C -> 48 pins)
   * Flash Memory size (C -> 256 KB, E -> 512 KB)
   * Package ( T -> LQFP)
   * Temperature range (3 -> from -40 to 125 degrees C, 6 -> from -40 to 85 degrees C)

   RAMN's PCB requires the microcontrollers to be in a LQFP48 package.

Surrounding circuitry
---------------------



   Circuitry surrounding the ECUs' microcontroller.
   
As much as possible, we try to follow the `hardware design guidelines <https://www.st.com/resource/en/application_note/dm00532722-getting-started-with-stm32l5-series-hardware-development-stmicroelectronics.pdf>`_ of STMicroelectronics. 
The microcontroller VDD pins are connected to individual 100nF `decoupling capacitors <https://en.wikipedia.org/wiki/Decoupling_capacitor>`_, and a common 10uF capacitor. The RST pin is also connected to a 100nF capacitor.
To save space, the VDDA pin is **NOT** connected to external decoupling capacitors and ferrite beads. Similarly, VBAT does not feature a decoupling capacitor.

Clock
*****

A crystal from the NX3225GD is selected as the clock source of the microcontroller. The `NX3225GD family <https://www.ndk.com/en/products/search/crystal/1189074_1494.html>`_ is automotive-grade, is 	present on the `STM32 compatible crystals list <https://www.st.com/resource/en/application_note/cd00221665-oscillator-design-guide-for-stm8afals-stm32-mcus-and-mpus-stmicroelectronics.pdf>`_ and has also been selected on some `Nucleo designs <https://www.st.com/resource/en/user_manual/dm00231744-stm32-nucleo32-boards-mb1180-stmicroelectronics.pdf>`_ .
NX3225GD crystals are widely available in 8MHz and 10MHz versions. RAMN can be used with both, but because of the internal PLL circuitry, the 8MHz does not allow reaching the maximum system clock of 110MHz for the STM32L5 family. Therefore, the 10MHz crystal is preferred.

The NX3225GD crystal has a load capacitance of 8pF, which is relatively low compared to similar products. Assuming a stray capacitance of 3pF, two external 10pF capacitors were selected to approximate a 8pF load (3 + 10/2 = 8).

Although not ideal, the layout follows best practice by keeping the crystal close to the microcontrollers, and shielding the clock lines from other signals.



   Clock circuitry on every ECU.

Boot Selection Resistors
************************

There are boot selection resistors, because RAMN used to be compatible with both STM32L4 and STM32L5, which have different boot sequences.

On STM32L4 and STM32L5 families, the BOOT0 pin is used by default to specify in which mode the microcontroller should start.
Resistors R8 and R9 can be used to select the BOOT0 pin state of ECU A. Only ONE of those resistors should be populated at a time.



   Boot mode selection resistors of ECU A.

The `boot patterns <https://www.st.com/resource/en/application_note/cd00167594-stm32-microcontroller-system-memory-boot-mode-stmicroelectronics.pdf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>`_ are different for STM32L4 (Pattern 6) and STM32L5 (Pattern 12)

STM32L4 will start the embedded bootloader when the flash memory is unprogrammed. This means a freshly-made board can directly be programmed over USB, no matter the state of BOOT0.
Therefore, we use R9 to pull the BOOT0 pin down, and R8 is not populated. On the first connection, ECU A will start in DFU mode and be ready for programming over USB. Once ECU A is programmed, and because BOOT0 is pulled down, the board will launch the programmed firmware from the next reboot.

STM32L5 will **NOT** start the embedded bootloader even if the flash memory is unprogrammed. To ensure a fresh board can be programmed over USB, we therefore need to use R8 to pull the BOOT0 pin up and force the ECU to start in DFU bootloader. R9 is left unpopulated.
This means that ECU A will **always** start in STM32 bootloader mode, until the option bytes are overwritten with new values forcing another boot process.

The BOOT0 pin of ECU A can be accessed externally through a test pad next to the USB port.
However, the BOOT0 pin is ignored by ECU A once a valid firmware has been flashed.



   ECU A Boot0 test pad.

The BOOT0 pin of ECUs B, C, and D are controlled by ECU A. ECU A should ensure the BOOT0 pin of each ECU is properly set before activating its power supply.

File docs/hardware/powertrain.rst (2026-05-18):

.. _powertrain_details:

Powertrain
==========

The POWERTRAIN expansion is used to simulate some functions usually found in the Powertrain domain of a car:

* Accelerator
* Brake
* Shift lever


   

   
Accelerator
--------------

The accelerator is simulated by a sliding potentiometer. A `TVS diode <https://en.wikipedia.org/wiki/Transient-voltage-suppression_diode>`_ is used for ESD protection, and a capacitor also protects the ECU input from chattering.



	Schematic of the Accelerator circuitry
	
Brake
-----

The brake is simulated by a sliding potentiometer, with the same circuitry as the accelerator. A `TVS diode <https://en.wikipedia.org/wiki/Transient-voltage-suppression_diode>`_ is used for ESD protection, and a capacitor also protects the ECU input from chattering.



	Schematic of the Brake circuitry
	
Shift lever
-----------

The shift lever is simulated by a 4-direction joystick, with a center-push function. The selected component is a `SKRHADE010 <https://tech.alpsalpine.com/prod/e/html/multicontrol/switch/skrh/skrhade010.html>`_ from Alps Alpine.

We originally selected the SKQUCAA010, also from Alps Alpine, which is easier to manipulate, but that part is reaching its `EOL <https://en.wikipedia.org/wiki/End-of-life_product>`_ and might not be easy to find soon.

The motion of the joystick selects a point from a `voltage divider <https://en.wikipedia.org/wiki/Voltage_divider>`_ , which is measured by an ADC on the ECU. A `TVS diode <https://en.wikipedia.org/wiki/Transient-voltage-suppression_diode>`_ is used for ESD protection.



	Schematic of the Shift Lever circuitry

Pinout
------



	Pinout of the POWERTRAIN expansion's connector

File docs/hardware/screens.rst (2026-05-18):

Screens (Gateway/Infotainment)
==============================

The SCREENS expansion is used to add a screen to an ECU. Although it can be used on any ECU, it is by default the expansion we use for ECU A (Gateway ECU). 


   

   
This expansion features various `pin sockets <https://en.wikipedia.org/wiki/Pin_header>`_ to connect screens from `Adafruit <https://www.adafruit.com/>`_.
Our preferred choice is the 240x240 TFT color screen `Adafruit 4313 <https://www.adafruit.com/product/4313>`_, since it has a good balance between size, readability, and cost.

We selected those screens mainly because they can be powered by 5V but controlled by 3.3V logic, without external components.

.. warning:: We only tested screens for the J5 pin sockets. Other screens are not guaranteed to work.

Compatible Screens
------------------

J5
******

* `Adafruit 4383 <https://www.adafruit.com/product/4383>`_
* `Adafruit 4313 <https://www.adafruit.com/product/4313>`_
* `Adafruit 4311 <https://www.adafruit.com/product/4311>`_
* `Adafruit 3533 <https://www.adafruit.com/product/3533>`_



J2 (Untested)
*************

* `Adafruit 1431 <https://www.adafruit.com/product/1431>`_
* `Adafruit 1673 <https://www.adafruit.com/product/1673>`_

J3 (Untested)
*************

* `Adafruit 4086 <https://www.adafruit.com/product/4086>`_
* `Adafruit 4197 <https://www.adafruit.com/product/4197>`_
* `Adafruit 4098 <https://www.adafruit.com/product/4098>`_
* `Adafruit 4196 <https://www.adafruit.com/product/4196>`_
* `Adafruit 3625 <https://www.adafruit.com/product/3625>`_

J4 (Untested)
*************

* `Adafruit 326 <https://www.adafruit.com/product/326>`_
* `Adafruit 938 <https://www.adafruit.com/product/938>`_

Pinout
------



	Pinout of the SCREENS expansion's connector

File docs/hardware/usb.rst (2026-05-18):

USB
==========

USB is used for two purposes:

* Power supply of 5V to all ECUs and expansions.
* Communication between ECU A and USB host.

Designing a device suitable for `USB-IF certification <https://www.usb.org/compliance>`_ requires following `many guidelines <https://www.ftdichip.com/Documents/AppNotes/AN_146_USB_Hardware_Design_Guidelines_for_FTDI_ICs.pdf>`_.
Since RAMN is not meant to be used as a "proper" USB device (such as a keyboard, mouse, etc.) we do not attempt to fulfill all USB-IF requirements. Concretely, this means there is no "VBUS filter" on the board (ferrite beads, etc.)

The USB connection circuit simply features an RC filter between SHIELD and GROUND. A `Shunt resistor <https://en.wikipedia.org/wiki/Shunt_(electrical)#Use_in_current_measuring>`_ can be used for simple power analysis. It is also possible to replace the shunt resistor with a `polyfuse <https://en.wikipedia.org/wiki/Resettable_fuse>`_.



   USB connection circuitry.
   
.. warning:: Unless you replace the shunt resistor by a fuse, RAMN assumes that the USB host is protected against failures of its loads (short-circuits, etc.). There is no special ESD protection except for a simple RC filter.

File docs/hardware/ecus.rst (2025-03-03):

ECUs
====

There are 4 ECUs on RAMN's main board, and they all share a common design and pin assignment, which is detailed below.

.. toctree::
   :maxdepth: 3
   
   powersupply
   microcontroller
   canphy



   Annotated close-up picture of ECU C.

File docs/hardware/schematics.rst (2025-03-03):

.. _schematics_details:

Schematics Details
==================

.. toctree::
   :maxdepth: 1
   :caption: RAMN main board:

   ecus
   canbus
   usb

.. toctree::
   :maxdepth: 1
   :caption: Expansions:

   screens
   chassis
   powertrain
   body
   debugger

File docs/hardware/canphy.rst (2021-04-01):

.. _canphy:

CAN-FD Transceiver
==================

All ECUs feature the same CAN-FD PHY (Physical layer) design, which is a simple CAN-FD transceiver IC, supported by bypass capacitors. The transceiver draws its power from the 5V line (VDD), but uses 3.3V for communication (Vio).



   CAN-FD PHY used by ECUs. 
   
Most CAN transceiver ICs use identical packages and layout, and are therefore interchangeable. We built prototypes with either of the following components:

* `ATA6561-GAQW-N <https://ww1.microchip.com/downloads/en/DeviceDoc/20005991B.pdf>`_ (BETA). It is qualified for automotive use (AEC-Q100), but its bitrate is limited to 5 Mbps.
* `MCP2558FD-H/SN <https://ww1.microchip.com/downloads/en/DeviceDoc/20005533A.pdf>`_ (V1). It has a maximum bitrate of 8 Mbps, but is still pending AEC-Q100 qualification (?). 

MCP2558FD-H/SN is our preferred choice, since it has a higher maximum bitrate.

The PHY Chip features a "STBY" (Standby) or "S" (Silent) pin to disable the transceiver:

* When STBY/S is HIGH, the transceiver is disabled and the ECU is unable to communicate on the CAN-FD bus.
* When STBY/S is LOW, the transceiver is enabled and the ECU can communicate on the CAN-FD bus

The STBY/S pin features an `internal pull-up <https://en.wikipedia.org/wiki/Pull-up_resistor>`_, meaning that the STBY/S pin must be actively set to LOW to enable communications. 
On a typical design, it is preferable to leave STBY/S pulled-up to make sure an unprogrammed ECU will not interfere with the CAN-FD bus. 
However, since RAMN uses the CAN-FD bus to program the ECUs from their (unprogrammed) factory state, the STBY/S pin is pulled-down externally, to allow the hardware built-in bootloader to communicate over CAN-FD.

.. note:: When an ECU is not used, It is preferable to program it to disable its CAN-FD transceiver.

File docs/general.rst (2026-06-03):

General Information
===================
	
What is RAMN?
-------------



RAMN (Resistant Automotive Miniature Network) is a credit-card-sized ECU testbed for safely studying and researching automotive systems.

RAMN is a set of PCBs (Printed Circuit Boards) that can be used together to simulate a CAN or CAN-FD network of ECUs (Electronic Control Units).

Main Features
-------------

ECU Network Simulation
**********************

RAMN simulates a CAN/CAN-FD network of 4 ECUs.
By default, network traffic specifications only use classic CAN messages, and are identical to those of `PASTA <https://github.com/pasta-auto/PASTA1.0>`_. 



Interactive
***********

RAMN can be expanded with boards using Arduino-style pin headers. You can add sensors and actuators, and physically interact with the ECUs.



Plug and Learn
**************

RAMN implements the slcan protocol over USB. It is recognized as a standard CAN-to-USB adapter. No need to buy and connect other tools, just plug RAMN into a USB port to get started.



.. _expansions_demo:

Expansions
**********

You can stack expansion boards to add new features, such as Trusted Platform Modules (TPM), external memories, and JTAG debuggers.



Drive it
********

RAMN can be connected in closed-loop with the open-source autonomous driving simulator `CARLA <https://carla.org/>`_. Values from the virtual world, such as car speed and throttle control, take a physical form on the CAN/CAN-FD bus and inside the ECUs. You can drive the car yourself, or let a self-driving algorithm do the job.



Programmable
************

All four ECUs can be reprogrammed over USB using the microcontrollers’ built-in hardware bootloader: no need for a JTAG programmer.



Easy Layout
************

RAMN only consists of Printed Circuit Boards designed with high tolerances. PCBs only have two layers, with SMD components on the same side. All components can be soldered by hand, which makes RAMN accessible to beginners in electronics.



Built with Open-Source Tools
****************************

All PCBs are designed with the open-source CAD tool `KiCad <https://kicad.org/>`_. The firmware of the microcontrollers is based on the open-source RTOS `FreeRTOS <https://www.freertos.org/>`_, and the open-source library STM32 HAL.



Usage Examples
--------------

We make RAMN open source in the hope of facilitating education and research of automotive systems. RAMN could be used:

* When providing training in electronics and automotive systems.
* When developing and evaluating automotive technologies.
* For research, especially if temperature and manufacturing tolerances matter.
* For CTF and bug bounty programs that require hardware.
* And more!
	
Education
*********

RAMN tries to employ as many popular technologies as possible – not just CAN/CAN-FD. Expansion boards feature clip-on probes to observe important signals, and can be used to study analog circuits, SPI, I2C, UART, etc.



Research
*********

RAMN has the size of a credit card. It is inexpensive and is ideal for situations that require many boards, for example when evaluating the impact of manufacturing tolerances on a technology, or when subjecting the testbed to conditions likely to break it.
Real ECUs are different from popular development boards because they are designed to resist the harsh environment in which they operate. RAMN is mostly made of automotive-grade components that are designed to operate from -40 to 150 degrees Celsius. The microcontrollers are not automotive grade, but they can operate from -40 to 85 degrees Celsius. RAMN tries to keep a balance between open-source, cost, and fidelity to real ECU networks. The expansion boards are not automotive grade.
A terminal block at the end of the CAN/CAN-FD bus lets you add other nodes. It can be used to develop and evaluate ECUs. One limitation though: the CAN/CAN-FD bus is terminated, so it cannot be connected to a real car.

Contact
-------

Refer to the contact section of the `RAMN Github repository <https://github.com/ToyotaInfoTech/RAMN?tab=readme-ov-file#contact>`_.

License
-------

RAMN is open-source, with permissive licenses. Please check the `license file <https://github.com/ToyotaInfoTech/RAMN/blob/main/LICENSE.md>`_ for more information.



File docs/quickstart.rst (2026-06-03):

.. _quickstart_guide:

Quick Start Guide
=================

Understanding The Board
-----------------------

To start using RAMN, you need the main board, with the four ECUs on it.

You can identify the ECUs on the board from the silkscreen:

- ECU A is at the top left, next to the USB connector.
- ECU B is below ECU A.
- ECU C is to the right of ECU B.
- ECU D is to the right of ECU A.



Adding Expansions
-----------------

To physically interface with the ECUs, you can add expansions to each ECU.
These expansions should be connected as shown in the animation below.

.. note::
    If you do not plan to use the controls (for example, if you only want to try UDS commands), the expansions are not required.



You can look at the silkscreen to identify the role of each control:

- ECU A has a screen on which it can display information about the CAN bus.
- ECU B has a rotating potentiometer to simulate the steering wheel, a two-position switch to simulate the parking brake, and a rotating four-position switch to simulate the lighting controls.
- ECU C has a sliding potentiometer to simulate the accelerator pedal, another sliding potentiometer to simulate the brake pedal, and a joystick to simulate the gear stick. This joystick can be pressed up/down to request a gear change, right/left to control the turn indicators, and middle-pressed to simulate a horn press.
- ECU D has an engine key and eight LEDs. The engine key has three positions: OFF, ACC (Accessory), and IGN (Ignition).

.. _try_out_controls:

Trying Out Controls
-------------------

Before going any further, you should verify that your board works correctly. Connect your board to the USB port of your computer, or to a USB power supply that can provide more than 300mA. The status of each control should be displayed at the bottom of the screen of ECU A.
Move each control and verify that its status is updated on the screen (and LEDs, when applicable).
If that is not the case, you may need to reflash your board (See :ref:`flashing`).
The LEDs on ECU D's expansion simulate a simple dashboard. They can help you verify that each control is working correctly.
By default, the CAN bus is always active when the power is on, so you may leave the controls in whatever state you prefer (e.g., engine key OFF).

You can switch between ECU A's screens by pressing LEFT or RIGHT on ECU C's "SHIFT" joystick.
On some screens, you can further interact by pressing UP, DOWN, or CENTER.

- LED D1 is the left turn indicator. It should start blinking if you left-press the joystick of ECU C.
- LED D2 is the right turn indicator. It should start blinking if you right-press the joystick of ECU C.
- LED D3, D4, and D5 represent the clearance light, the lo-beam, and the hi-beam, respectively. They should light up in order when you turn the lighting control switch on ECU B.
- LED D6 is the "battery" indicator. By default, it is ON when the engine key is either on "ACC" or "IGN".
- LED D7 is the "check engine" indicator. By default, it is ON when the self-driving algorithm is used and the steering wheel potentiometer is not centered. It is used to indicate that the self-driving algorithm commands are currently ignored, and the current position of the steering wheel potentiometer is applied instead.
- LED D8 is the "parking brake" LED. It is ON when the parking brake is active. Contrary to a real vehicle, this LED is also ON when the brake pedal is pressed.

.. note::
    Although the "battery" and "check engine" are scary in a real vehicle, they do not indicate a problem or failure with your RAMN board.

.. warning::
    If the screen does not say "STEER 0%" when you center the steering wheel, it means that you have installed a logarithmic firmware for a board with linear potentiometers, or vice-versa.
    The board is still usable as is, but you will probably need to update the firmware of ECU B if you want to drive a vehicle in the simulator.

The caps of the Lighting switch and Steering potentiometer may fall off during rough handling - be sure not to lose them. 
Be also careful with the screen, which is rather fragile.

Choosing Your CAN Adapter & Tools
---------------------------------

To interact with RAMN's CAN bus, you have two options for adapters:

1. Use your own adapter, e.g., publicly available CAN adapters such as CANtact, and software such as savvyCAN.
2. Use RAMN built-in adapter (RAMN itself acts as an "slcan" adapter over USB, so if your software is compatible with slcan you do not need to connect any hardware).

And also two options for (software) tools:

1. Use your own tools, e.g., SavvyCAN, BUSMaster, scapy-automotive, your own python-can scripts.
2. Use the Linux command line tools (i.e. can-utils).

If you want to use your own adapter, you only need to connect the "CANH" and "CANL" wires of your adapter to the terminal block of the CAN bus of RAMN, located at the top right of the board.
Each pin of the terminal block consists of a large round hole, and a smaller rectangular hole. You should insert the wire that you want to connect in the round hole, and an internal spring will lock it in place.
To remove a wire, insert something in the rectangular hole (e.g., a precision screw driver) and pull the wire.
The terminal block has three pins, and the corresponding signals are labeled on the silkscreen next to it:

- Top pin is GND (Ground).
- Middle pin is CANL (CAN Low).
- Bottom pin is CANH (CAN High).

You only need to connect the CANH and CANL pins of RAMN to the CANH and CANL pins of your CAN adapter.
After that, you should be ready to use your favorite set of tools. The CAN bus is always active as long as the RAMN board is powered.

The rest of this documentation focuses on the built-in RAMN adapter and built-in Linux tools.

Using Built-in Tools
--------------------

To get started with CAN bus analysis on RAMN, we recommend that you prepare a Linux environment (virtual or native) with can-utils.

.. _install_linux:

Preparing a Linux Machine with can-utils
^^^^^^^^^^^^^^^^^^^^^^^^^^^^^^^^^^^^^^^^

Windows
"""""""

On Windows, we recommend that you install VirtualBox and use a Linux distribution image.
A common choice by car enthusiasts is Kali Linux\ [#f1]_.

- `Download and install VirtualBox <https://www.virtualbox.org/wiki/Downloads>`_.
- `Download a Kali Linux Pre-built Virtual Machine <https://www.kali.org/get-kali/#kali-virtual-machines>`_.
- Unzip the 7z image using `7zip <https://www.7-zip.org/>`_.
- Double-click the vbox file to open it with VirtualBox. If you encounter USB issues, open Settings > USB and try USB 2.0 or USB 3.0 (virtual machine must be powered off).
- Login with username kali (password kali).

From here, you should be able to follow the Linux instructions below.

.. [#f1] If you cannot (or will not) run Linux in a VM for can-utils, we recommend learning and using the platform-independent python-can which will work on all (python) platforms, including Windows.

Linux
"""""

- Open a terminal window (e.g., right-click the desktop and click "Open Terminal here").
- Type the following commands to install can-utils:

.. code-block:: bash

    $ sudo apt-get update
    $ sudo apt-get install can-utils

.. _end_install_linux:

USB Connection
^^^^^^^^^^^^^^

Connect your board to your computer using a USB cable. On Windows, it should appear as a "USB Serial Device" (or Composite Device) and be attributed a COM port number (e.g., COM1).
If that is not the case, you may need to install `STM32 Virtual COM Port Drivers <https://www.st.com/en/development-tools/stsw-stm32102.html>`_.

Once the board is recognized by Windows, you must forward the USB port to Virtual Box. Select Devices > USB and click Toyota Motor Corporation RAMN.
You can open Devices > USB > USB Settings..., then click the + icon to add RAMN so that Virtual Box will always automatically forward the USB port.

On Linux, RAMN should appear at the end of the dmesg command, and be attributed a device file (typically, /dev/ttyACM0).
If you encounter issues, see :ref:`unreliable_usb`.

Starting slcand
^^^^^^^^^^^^^^^

By default, RAMN acts as an slcan adapter. You can use the slcand command to start RAMN as a native Linux CAN interface.

.. code-block:: bash

    $ sudo slcand -o -c /dev/ttyACM0 && sudo ip link set up can0

Replace /dev/ttyACM0 with the device file that was attributed by your computer.

After executing this command, you should be able to see the CAN interface as "can0" using ifconfig:

.. code-block:: bash

    $ ifconfig

Observing CAN Traffic with Cansniffer
^^^^^^^^^^^^^^^^^^^^^^^^^^^^^^^^^^^^^

To observe the most recent CAN message for each identifier and highlight bit changes, you can use the following command:

.. code-block:: bash

    $ cansniffer -c can0

The first two bytes of each message represent the status of something on the board. Try moving controls and observe how these values change.
The following two bytes represent a message counter, and the last four bytes represent the CRC32 of the first four bytes.

Dumping CAN Traffic
^^^^^^^^^^^^^^^^^^^

If you want to see all CAN frames instead of the most recent frame for each identifier, you can use the candump command.

.. code-block:: bash

    $ candump can0

This command will dump all CAN frames, which can be overwhelming.
You can use filters to only display specific CAN IDs. To add a filter, add ",<filter>:<mask>" after the name of your can interface.
For example, to only display ID 0x150, use the following command:

.. code-block:: bash

    $ candump can0,150:7ff

This command should only show CAN frames with ID 0x150. Move the lighting control switch on ECU B expansion and observe how the first byte changes.
This should allow you to understand how ECU B transmits the status of this switch on the CAN bus.

Sending CAN Frames
^^^^^^^^^^^^^^^^^^

You can use the cansend command to send CAN messages.
Make sure the lighting LEDs (LEDs D3 to D5 on the Body ECU expansion) are OFF by moving the Lighting controls switch on ECU B to the leftmost position.
You can send the following message to "spoof" the lighting controls:

.. code-block:: bash

    $ cansend can0 150#02
    $ cansend can0 150#03
    $ cansend can0 150#04

You should be able to briefly control the status of LEDs on the Body expansion from your terminal.
But only briefly, because ECU B is still sending CAN frames, overwriting your CAN messages. In fact, you may see an error message on ECU A indicating anomalies with the CAN bus, because two ECUs are sending CAN frames with the same ID.
To address this issue, you need to prevent ECU B from sending CAN messages. A quick method to do this is to use UDS.

Sending UDS Commands
^^^^^^^^^^^^^^^^^^^^

`UDS <https://en.wikipedia.org/wiki/Unified_Diagnostic_Services>`_ is a set of standard diagnostic commands that can be sent using the `ISO-TP <https://en.wikipedia.org/wiki/ISO_15765-2>`_ transport layer.
You can use the isotpsend, isotprecv, and isotpdump commands to easily interact with these layers.

Type the following command to dump CAN messages containing UDS commands:

.. code-block:: bash

    $ candump can0,7e0:7F0

This command will dump messages with IDs ranging from 0x7e0 to 0x7eF, which correspond to the IDs used by the UDS layer of RAMN.
It should show nothing now as no UDS messages are being sent.

Open another terminal, and type the following command:

.. code-block:: bash

    $ isotpdump -s 7e1 -d 7e9 -c -u -a can0

This command will dump and parse UDS commands for ECU B, which accepts commands at ID 0x7e1 and answers at ID 0x7e9.
This command should also show nothing for now.

Open yet another terminal, and type the following command:

.. code-block:: bash

    $ isotprecv -s 7e1 -d 7e9 -l can0

This command will receive and display the answers to the UDS commands that you send to ECU B.

Finally, open a fourth terminal and type the following command to send your first UDS command to ECU B:

.. code-block:: bash

    $ echo "3E 00" | isotpsend -s 7e1 -d 7e9 can0

This command sends the 2-byte command "3E 00" to ECU B, which corresponds to the "Tester Present" command.
This is an optional command to let the ECU know that you are currently diagnosing it and that it should wait for your commands.
You should see on your "isotprecv" terminal that ECU B has answered "7E 00", which means the command was accepted.
You can look at your "isotpdump" terminal and observe the corresponding interaction in color (red is the request, blue is the answer).
If you look at your "candump" terminal, you will observe the corresponding CAN messages. Notice that they are actually 3-bytes long: this is because the first byte is used to specify the length of the UDS payload, which is 2 bytes.

You can use UDS to send and receive large payloads. For example, use the "Read Data By Identifier" service (0x22) to ask the ECU its compile time (argument 0xF184):

.. code-block:: bash

    $ echo "22 F1 84" | isotpsend -s 7e1 -d 7e9 can0

You should see in your "isotprecv" terminal that you have received a large answer, that should be interpreted by your "isotpdump" terminal.
In your "candump" terminal, you can observe that many CAN messages have been exchanged. This corresponds to the ISO-TP layer, which allows sending large messages using only CAN frames with less than 8 bytes each.
Isotpdump, isotpsend, and isotprecv make this layer transparent to you.

Finally, you can use RAMN custom routine controls (UDS service 0x31) to ask ECU B to stop sending CAN messages (Routine 0x0200).

.. code-block:: bash

    $ echo "31 01 02 00" | isotpsend -s 7e1 -d 7e9 can0

Move the lighting switch and observe how the LEDs of ECU D do not change anymore.
You can now control the lighting switch with the following commands, without ECU B being in your way.

.. code-block:: bash

    $ cansend can0 150#02
    $ cansend can0 150#03
    $ cansend can0 150#04

Congratulations, you are now a CAN bus expert. Follow the full :ref:`userguide` to learn more.

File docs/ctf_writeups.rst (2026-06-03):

.. _ctf_writeups:

CTF Write-ups
=============

This page contains write-ups of past CTFs featuring RAMN. 
You can download past CTF firmware and challenge prompts from the `misc folder <https://github.com/ToyotaInfoTech/RAMN/tree/main/misc/past_CTFs>`_ of the GitHub repository.
Feel free to contact us to add or remove your own write-ups.

DEFCON Embedded Systems Village 2024
------------------------------------

Participant Write-ups:

-  https://justinapplegate.me/2024/esvctf-playagame/

DEFCON Car Hacking Village 2024
-------------------------------

Flag format is flag{xxxx}. Ten RAMN boards were made available on a table at the CHV.
It was specified that each ECU had a different diagnostics interface (either USB, UDS, KWP2000, or XCP).
It was noted that the Flash address range is 0x08000000-0x08040000 and that the RAM address range is 0x20000000-0x20040000.

This page contains simple write-ups. A jupyter notebook with very detailed solutions is available `in the misc folder <https://github.com/ToyotaInfoTech/RAMN/tree/main/misc/jupyter_notebooks>`_. 

[A] Secret Menu
^^^^^^^^^^^^^^^

.. code-block:: text

	Challenge Description: Look away while I input my password!
	Attachment: ECUA_REDACTED.elf

It can be immediately identified that ECU A is the one with the USB diagnostics interface because it is the only one with USB.
By browsing screens, we can identify that there is a debug screen waiting for a secret code.



We can load the provided firmware file in Ghidra. Because it is a .elf file with debug symbols, it is easy to reverse engineer.

Using Window > Defined Strings and looking for the "Awaiting secret code" string, then following references, we can identify that the debug mode is unlocked when the DEBUG_MODE_UNLOCKED variable is set to 1.

Following WRITE references, we can identify that this variable is set to 1 if the verify_secret_input function returns 1.


   
By analyzing the verify_secret_input function, we can identify which RAMN inputs will unlock the debug mode.



With help from cansniffer (or RAMN's CAN RX MONITOR screen), we can identify which CAN ID corresponds to each control, by physically moving controls and observing which CAN ID has a payload that changes accordingly.
We can then set RAMN's inputs as specified by the verify_secret_input.



The debug screen now shows that a new USB command interface can be accessed by typing "#", and that the current username has an incorrect CRC.


   
By typing "#" then "help" in the USB interface, we find that there is a "username" command that accepts one argument.  

By entering "default_user" into https://crccalc.com/ and finding the algorithm that yields C862ED4F, we identify that the CRC algorithm used is CRC-32/ISO-HDLC.
The flag can be retrieved by inputting a username with a CRC of 0xDA5D344D, which can be computed using tools such as `CRC RevEng <https://reveng.sourceforge.io/>`_ or `crchack <https://github.com/resilar/crchack>`_.





[B] Sit Next To Me
^^^^^^^^^^^^^^^^^^

.. code-block:: text

	Challenge Description: You wouldn't download a byte. 
	(Note: Flag will be transmitted once on ID 0x777 when the challenge is solved.)
	
It can be identified that ECU B has an active XCP interface (at CAN IDs 0x552/0x553) by using scanning tools such as caringcaribou:

.. code-block:: bash

	caringcaribou xcp discovery -autoblacklist 10
	


Further probing with caringcaribou reveals that CAL/PAG resource is available but requires authentication.

.. code-block:: bash

	caringcaribou xcp info 0x552 0x553


	
The command ``caringcaribou xcp commands 0x552 0x553`` can be used to identify that available commands are GET_STATUS, SYNCH, GET_SEED, UNLOCK, SET_MTA, UPLOAD, and DOWNLOAD.

It can be inferred from the prompt and from the information gathered so far that the flag will be transmitted with CAN ID 0x777 if the DOWNLOAD command (0xF0) is used - but this command requires authentication (using GET_SEED and UNLOCK).
	
We can use SET_MTA and UPLOAD commands to dump memory from the ECU. It can be observed with ``caringcaribou xcp dump 0x552 0x553 0x08000000 256`` that the flash range is not accessible, but that the RAM range is accessible (e.g., with ``caringcaribou xcp dump 0x552 0x553 0x20000000 256``). Note that some versions of caringcaribou might have bugs that will prevent this command from succeeding.

Caringcaribou does not support XCP authentication, so next steps should be done by directly sending CAN messages, following XCP specifications. A seed can be requested with ``cansend can0 552#f80001``.



This reveals that the seed is 6 bytes.
We can use the dump command to dump the full RAM address range (0x20000000-0x20040000) and search for the seed in it.
**Caringcaribou shouldn't be used (without modification) because it resets the XCP connection with each command, which resets the seed. The seed may be found at several locations (e.g., in the TRNG buffer), so all locations should be checked.**

To dump the RAM with XCP, we can use SET_MTA (0xF6) and UPLOAD (0xF5). For example, to dump 6 bytes from 0x20000000, we use:

.. code-block:: bash

	cansend can0 552#f6000020000000
	cansend can0 552#f506

Each successive call to UPLOAD will dump the next addresses (e.g., address 0x20000006 for the example above).
By dumping the whole RAM for different seeds, we can identify that the seed is consistently located near 0x20033f50.
It can also be observed that there is another 6-byte variable that changes just next to it. This can be identified as the potential expected answer to the seed. There is no authentication attempt limit, so we are free to try different permutations.



Flag can be read by requesting a seed, dumping the RAM to read the expected answer, unlocking the ECU with that answer, and using the DOWNLOAD command to ask the ECU to transmit the flag.



[C] Come again?
^^^^^^^^^^^^^^^

.. code-block:: text

	Challenge Description: The 2000s called; they want their ECU back.

The challenge prompt suggests that ECU C uses KWP2000. We can use caringcaribou to find ECUs using UDS and KWP2000:

.. code-block:: bash

	caringcaribou uds discovery --autoblacklist 10
	

	
From RAMN's documentation, we can identify that 7e3 corresponds to ECU D's UDS interface and that 7e6 corresponds to ECU C's KWP2000 interface (and this can be confirmed by reading info with ReadDataByIdentifier).
For this challenge, we focus on 7e6/7ee (ECU C's KWP2000 interface).

Caringcaribou's service discovery reveals that many services are available:

.. code-block:: bash

	caringcaribou uds services 0x7e6 0x7ee



The presence of service 0x1a indicates that this interface is KWP2000 and not UDS. Service 0x29 does not correspond to AUTHENTICATION, because this is not a UDS interface (and we technically shouldn't be using caringcaribou for it).

Trying to read all DIDs with ReadDataByIdentifier reveals that DID 0x0000 returns a "Security Access Denied". It can be inferred that the goal of the challenge is to bypass that security access.


   
Trying to request a seed with the default session will return error 0x80, which for KWP2000 means that the service is not supported in current session.
We can bruteforce all sessions and observe that session 0x92 (KWP2000 extended session) is available.
We may however get other errors when requesting Security Access seeds: either "Time delay not required" (meaning we have to wait for the bruteforce protection timer to expire) or "Subfunction not supported".

By bruteforcing all security levels, we observe that security level 0x05 exists and returns a 16-bit seed:



We can request as many seeds as we like, and they appear to be random.
Because the seed is only 16-bit long, bruteforcing appears to be the easiest approach.
However, the ECU will limit the number of attempts:



Fortunately, it can be observed by poking around that the ECU resets the number of attempts whenever the "Diagnostic Session Control" service is called to request a new session, allowing us to try as many attempts as we want without having to reset the ECU.

We can therefore use the following script, which repetitively asks for a new seed and tries the answer "1234" (and should be stopped once it eventually gets lucky and unlocks the ECU).

.. code-block:: bash

	timeout 1000s bash -c 'while [ $SECONDS -lt 1000 ]; \
	do \
	echo "10 92" | isotpsend can0 -s 7e6 -d 7ee; \
	echo "27 05" | isotpsend can0 -s 7e6 -d 7ee; \
	echo "27 06 12 34" | isotpsend can0 -s 7e6 -d 7ee; \
	sleep 0.001
	done' 
	
(Note that this script is very slow but functional; it was expected from participants to write a more efficient script.)
After a few minutes, the ECU should be unlocked and the flag can be read with ReadDataByIdentifier with DID 0x0000:

.. code-block:: bash

	echo "22 00 00" | isotpsend can0 -s 7e6 -d 7ee



[D] Light the way
^^^^^^^^^^^^^^^^^

.. code-block:: text

	Challenge Description: These LEDs were made for lighting.
	(Hint: dumpable firmware size is 0x0c548 bytes, don't spend your time looking for more.)
	
From the previous challenges, we know that ECU D has a UDS interface at 7e3/7eb.
We can use caringcaribou to scan available services:
	
.. code-block:: bash

	caringcaribou uds services 0x7e3 0x7eb



We can use the dump_dids module to read all DIDs:

.. code-block:: bash

	caringcaribou uds dump_dids 0x7e3 0x7eb
	

   
We can observe that WriteDataByIdentifier is active, and that the only DID that can be written to is DID 0x0207, with what appears to be an address in RAM.
We can try slightly modifying that value, and we observe that the LEDs on RAMN change as a result.
Because DID 0x206 says "LED CONTROL POINTER", and because the prompt and title suggest that the LEDs are involved, we can understand that this DID is used to specify the address in memory that is displayed on the LEDs.
We can also observe that it is possible to make that value point to flash addresses.

.. code-block:: bash

	echo "2E 02 07 20 02 00 00" | isotpsend can0 -s 7e3 -d 7eb 
	echo "2E 02 07 08 00 00 04" | isotpsend can0 -s 7e3 -d 7eb
	
We can therefore expect to be able to display the value of the flag, byte by byte, on the RAMN LEDs.
However, we still do not know the address of the flag.

We can observe that the REQUEST_UPLOAD and TRANSFER_DATA are active, which allow us to dump the firmware (see :ref:`request_upload`). The size of the firmware is specified in the challenge prompt: 0x0c548 bytes.

After dumping the firmware, we can open it in Ghidra (using the same settings as the one provided for ECUA_REDACTED.elf). Searching for "flag", we can find the string ``Loaded FLAG from private flash at address %p``, where %p is replaced by "0x0803e000".
We can therefore conclude that the flag is at 0x0803e000, and all we need to do is dump it byte by byte using the Write Data By Identifier service (The documentation can immediately identify which LED represents which bit, see :ref:`body_expansion`).

.. code-block:: bash

	# Point LEDs to first byte of flag
	echo "2E 02 07 08 03 e0 00" | isotpsend can0 -s 7e3 -d 7eb
	# Read byte by looking at the 8 LEDs on RAMN
	
	# Point LEDs to second byte
	echo "2E 02 07 08 03 e0 01" | isotpsend can0 -s 7e3 -d 7eb
	# Read next byte
	# etc...

Flag: flag{BEST_LIGHT_SHOW_IN_VEGAS}.

Automotive CTF Japan 2024
-------------------------

Participant Write-ups:

- https://laysakura.github.io/2024/09/14/automotive-ctf-2024-japan-final/ (JP)
- https://qiita.com/kusano_k/items/140d08521b9667cd6ab9 (JP)
- https://blog.hamayanhamayan.com/entry/2024/09/14/112907 (JP)
- https://emeth.jp/diary/2024/09/automotive-ctf-japan-writeup/ (JP)

Block Harbor VicOne Automotive CTF 2024
---------------------------------------

Flag format is bh{xxxx}. Each of the six teams was provided with two RAMN sets with CTF firmware, and there was an available reference RAMN with standard firmware shared between participants.
The letter in brackets in the challenge title indicates in which ECU the flag is located.

[FILE] SWD 1 (6 solves)
^^^^^^^^^^^^^^^^^^^^^^^

Intended difficulty: Easy.
Tags: Forensics.

.. code-block:: text

	The attached file is a logic analyzer capture of a RAMN ECU reprogramming session using an ST-LINK V2… 
	Can you figure out the plaintext (not obfuscated) flag embedded in firmware?

The provided file is a logic analyzer capture (from a Scanaquad SQ200).

.. code-block:: text

	Time;CH 1 SWCLK;CH 2 SWDIO
	0.000000000;1;1
	0.594872000;0;1
	0.594878000;1;1
	...

It can be loaded in tools such as PulseView to be decoded (the correct CSV format should be entered in the import options).
Once loaded, the signals can be decoded with the SWD protocol analyzer (as hinted by the title).



The decoded data can be exported in a text file.
Simply searching for the string "bh{" (62 68 7B in hex) in little-endian (7B6862) reveals the flag in plaintext.


   
Flag: bh{an4lyst_s3ssION_Ro4d}.
	
[FILE] SWD 2 (3 solves)
^^^^^^^^^^^^^^^^^^^^^^^

Intended difficulty: Very Difficult. 
Tags: Forensics, Reverse.	

.. code-block:: text

	The firmware of challenge “SWD 1” broadcasts two flags every second in plaintext over CAN, using the same function. 
	CAN ID 0x12345678 is used to broadcast the (non-obfuscated) flag of "SWD 1".
	The flag of this challenge is the one transmitted with ID 0x7777.
	(Note: Flash starts at 0x08000000, RAM at 0x20000000. Reset_Handler() is at 0x08001570).

This challenge follows SWD 1.
The first step is to extract the full firmware from the logic analyzer capture. This can be done by looking for “W AP4” commands (which indicate the address), and for “W APc” commands (which indicate the data to write at that address). 
Players must write a script to reconstruct a binary file of the firmware (Code FLASH starts at 0x08000000; data is written in 32-bit little-endian chunks).



After the firmware file is reconstructed, it can be loaded in Ghidra. Memory map must be set according to prompt for easier analysis.
	

   
Searching for 0x12345678 reveals the function that sends the flags. This can be used to understand that the second flag (when not obfuscated) is located at 0x20030020.	



There is only one other reference to 0x20030020 - it can be inferred that this is the function that loads the flag in it.


   
This reveals the function that deobfuscates the flag. 


   
Which core part was originally in C:

.. code-block:: C

	uint8_t SECRET_KEY[] = "dw\x01ss1";
	flag_addr[i] = (obfuscated_flag[i] ^ SECRET_KEY[i % key_length]) -  SECRET_KEY[i % key_length];
   
The only remaining step is to identify where the obfuscated flag is.
It is known from previous steps that 0x20037750 is where the obfuscated flag is in RAM.
The challenge prompt provides the location of the Reset_Handler() function:   
   


It can be deduced that the RAM default values are loaded from FLASH 0x0800ab94 to RAM 0x20037750 (the obfuscated flag coincidentally happened to be at the first address of the .data section, just before the flag of SWD1):



The steps above can be used to deobfuscate the flag as bh{pr0duct_AMB1tion}.

[D] Follow Me (6 solves)
^^^^^^^^^^^^^^^^^^^^^^^^

Intended difficulty: Easy. 
Tags: Hardware.

.. code-block:: text

	ECU D's LEDs are flickering when the engine key is on the “IGN” (rightmost) position. 
	We hope that you brought a logic analyzer to debug that…

LEDs are controlled by ECU D's SPI interface, and the SPI signals have clearly marked probes on the Body PCB.
Observing the SPI signal with a logic analyzer shows that ECU D normally updates the status of LEDs every 10 ms.	
	

   
When the engine key is on the IGN position, it can be seen that there is a burst of data before the transmission of LED status - which is the flag in plaintext ASCII.



Flag: bh{TREE_FORMS_WIND}.

[D] I2C (4 solves)
^^^^^^^^^^^^^^^^^^^

Intended difficulty: Medium. 
Tags: Hardware.

.. code-block:: text

	This flag will be transmitted every second on CAN with ID 0x778
	if you can send any byte to ECU D on its I2C interface (port I2C2, address 0x63).
	Note: I2C pins have internal pull-up resistors. 

This challenge requires the player to read the `STM32L5x2 datasheet <https://www.st.com/resource/en/datasheet/stm32l552cc.pdf>`_ and identify possible pins for the I2C2 port.
	
SDA could be at PF0, PB11, or PB14; SCL could be at PF1, PB10, or PB13.
PB13 is already used by the SPI interface of the "Follow Me" challenge, and PF0/PF1 are not available on the 48-pin package used by RAMN.
This only leaves SDA:PB11/SCL:PB10 and SDA:PB14/SCL:PB10 as possible configurations to try on the board (with the former being the correct one).
This can be attempted with any I2C tool, such as an FT2232H board configured in I2C mode.
	
.. code-block:: python

	from pyftdi.i2c import I2cController

	i2c = I2cController()
	i2c.configure('ftdi://ftdi:2232h/1',frequency=10000)
	slave = i2c.get_port(0x63)
	print(slave.exchange([0xFF], 1))

Which triggers the transmission of the flag.


   
Flag: bh{INFAMOUS_REMAKE}.
	
[D] Forgotten Field (4 solves)
^^^^^^^^^^^^^^^^^^^^^^^^^^^^^^

Intended difficulty: Medium/Difficult. 
Tags: CAN, Hardware.

.. code-block:: text

	Many tools consider that a CAN frame consists of arbitration, control, and data fields. 
	ID 0x607 thinks they should check some more.

The challenge prompt suggests that there is a "forgotten field" not displayed by most CAN tools such as candump.
A quick look at the CAN page on `Wikipedia <https://en.wikipedia.org/wiki/CAN_bus#/media/File:CAN-bus-frame-with-stuff-bit-and-correct-CRC.png>`_ shows that this is likely a reference to the CRC field (further hinted by the "check some" in the prompt).

The solution is therefore to look at the CRC field of CAN frames with ID 0x607.
The easiest way to do this is by looking at the CAN frames with a logic analyzer (it is easier if you turn off other ECUs, and look at the TX pin of ECU D directly instead of CANH/CANL).
An alternate way to solve this is to reconstruct CAN frames based on the data from candump (note that you must reproduce bit-stuffing before computing the CRC15 of the CAN protocol).


   
The flag is simply the CRC of the CAN frames (one byte per frame): bh{LAGGING_BEHIND}.  



[C] CVE-2017-14937 (4 solves)
^^^^^^^^^^^^^^^^^^^^^^^^^^^^^

Intended difficulty: Easy. 
Tags: CAN, Hardware.

.. code-block:: text

	Go write something at 0x1111 and read something at 0x0000.
	
As the title implies, this challenge is a simple reproduction of CVE-2017-14937. CVE-2017-14937 details how the ECU's Security Access service can be used to unlock the ECU.
Once the ECU is unlocked, the player only needs to use the WriteDataByIdentifier service to write any data at DID 0x1111, which will allow them to read the flag using the ReadDataByIdentifier service with DID 0x0000.

Detailed participant write up available `here <https://laysakura.github.io/2024/10/24/automotive-ctf-2024-world-final/#c-cve-2017-14937>`_.

Flag: bh{SUP3RS0NIc}.
	
[B] Rush Hour (3 solves)
^^^^^^^^^^^^^^^^^^^^^^^^

Intended difficulty: Medium. 
Tags: CAN, Hardware.

.. code-block:: text

	We added a UDS disable feature to ECU B to prevent you from reading the flag. 
	Note: Flag is redacted in attached firmware - you must extract the flag from an actual RAMN board.
	
This challenge provides ECU B's firmware (with a redacted flag) as an attachment. The firmware is in .elf format, with debug symbols, making it easy to reverse engineer.
(Another reason to provide the firmware in .elf format was to make it easier to know correct Ghidra settings for challenges where only a .hex file was provided).

Searching for the flag reveals that it can be read using the ReadDataByIdentifier UDS service with DID 0x0001 (appearing as 0x100 in Ghidra because of ARM32's endianness).
	

	
However, as specified in the challenge prompt, there is a global variable UDS_ENABLE that prevents the player from using UDS when it is set to 0.
	

	
The player should notice that the default value of this variable is 1 (meaning UDS is available) but that it is set to 0 during boot.	
	

		
Because it is set to 0 AFTER the CAN peripheral has been activated, there is a 10 ms window during which UDS can be used.
The solution is therefore to spam the request while the ECU is booting.


		
Flag: bh{Sl0W_Down_Every0ne}.
	
[A] slcan’t (2 solves)
^^^^^^^^^^^^^^^^^^^^^^

Intended difficulty: Medium. 
Tags: CAN, USB.

.. code-block:: text

	Why does ramn_utils.c need such a large ascii_hashmap? 
	We could use all those unused bytes to store a flag instead…

The table ascii_hashmap in ramn_utils.c (the code for which is available on GitHub) is used to convert ASCII hexadecimal strings to bytes. 
Because hexadecimal characters only consist of "0 to 9", "A to F", and "a to f", the table is mostly filled with 0x00.

.. code-block:: C

	static const uint8_t ascii_hashmap[] =
	{
			0x00, 0x00, 0x00, 0x00, 0x00, 0x00, 0x00, 0x00, // ........
			0x00, 0x00, 0x00, 0x00, 0x00, 0x00, 0x00, 0x00, // ........
			0x00, 0x00, 0x00, 0x00, 0x00, 0x00, 0x00, 0x00, // ........
			0x00, 0x00, 0x00, 0x00, 0x00, 0x00, 0x00, 0x00, // ........
			0x00, 0x00, 0x00, 0x00, 0x00, 0x00, 0x00, 0x00, //  !"#$%&'
			0x00, 0x00, 0x00, 0x00, 0x00, 0x00, 0x00, 0x00, // ()*+,-./
			0x00, 0x01, 0x02, 0x03, 0x04, 0x05, 0x06, 0x07, // 01234567
			0x08, 0x09, 0x00, 0x00, 0x00, 0x00, 0x00, 0x00, // 89:;<=>?
			0x00, 0x0a, 0x0b, 0x0c, 0x0d, 0x0e, 0x0f, 0x00, // @ABCDEFG
			0x00, 0x00, 0x00, 0x00, 0x00, 0x00, 0x00, 0x00, // HIJKLMNO
			0x00, 0x00, 0x00, 0x00, 0x00, 0x00, 0x00, 0x00, // PQRSTUVW
			0x00, 0x00, 0x00, 0x00, 0x00, 0x00, 0x00, 0x00, // XYZ[\]^_
			0x00, 0x0a, 0x0b, 0x0c, 0x0d, 0x0e, 0x0f, 0x00, // `abcdefg
			0x00, 0x00, 0x00, 0x00, 0x00, 0x00, 0x00, 0x00, // hijklmno
			0x00, 0x00, 0x00, 0x00, 0x00, 0x00, 0x00, 0x00, // pqrstuvw
			0x00, 0x00, 0x00, 0x00, 0x00, 0x00, 0x00, 0x00, // xyz{|}~.
			0x00, 0x00, 0x00, 0x00, 0x00, 0x00, 0x00, 0x00, // ........
			0x00, 0x00, 0x00, 0x00, 0x00, 0x00, 0x00, 0x00, // ........
			0x00, 0x00, 0x00, 0x00, 0x00, 0x00, 0x00, 0x00, // ........
			0x00, 0x00, 0x00, 0x00, 0x00, 0x00, 0x00, 0x00, // ........
			0x00, 0x00, 0x00, 0x00, 0x00, 0x00, 0x00, 0x00, // ........
			0x00, 0x00, 0x00, 0x00, 0x00, 0x00, 0x00, 0x00, // ........
			0x00, 0x00, 0x00, 0x00, 0x00, 0x00, 0x00, 0x00, // ........
			0x00, 0x00, 0x00, 0x00, 0x00, 0x00, 0x00, 0x00, // ........
			0x00, 0x00, 0x00, 0x00, 0x00, 0x00, 0x00, 0x00, // ........
			0x00, 0x00, 0x00, 0x00, 0x00, 0x00, 0x00, 0x00, // ........
			0x00, 0x00, 0x00, 0x00, 0x00, 0x00, 0x00, 0x00, // ........
			0x00, 0x00, 0x00, 0x00, 0x00, 0x00, 0x00, 0x00, // ........
			0x00, 0x00, 0x00, 0x00, 0x00, 0x00, 0x00, 0x00, // ........
			0x00, 0x00, 0x00, 0x00, 0x00, 0x00, 0x00, 0x00, // ........
			0x00, 0x00, 0x00, 0x00, 0x00, 0x00, 0x00, 0x00, // ........
			0x00, 0x00, 0x00, 0x00, 0x00, 0x00, 0x00, 0x00  // ........
	};
	
	inline uint8_t ASCIItoUint8(const uint8_t* src)
	{
		return (ascii_hashmap[src[0]] << 4) + (ascii_hashmap[src[1]]);
	}

The challenge prompt suggests that the flag is located in that table.
Reading the source code shows that ASCIItoUint8 is used by the 't' command of the `slcan protocol <https://www.lawicel.com/can232/can232_v1.pdf>`_ when requesting the transmission of a CAN message using the slcan interface.

.. code-block:: C

	CANTxData[i++] = ASCIItoUint8(&USBRxBuffer[offset]);

The format of a transmit slcan command is t<id><dlc><data>.
A simple method to dump one byte from the table is to execute the slcan command t00210<index> to force ECU A to transmit the byte at <index> with CAN ID 0x002.
By repeating this command and observing the CAN bus at the same time (from an external CAN adapter), we can dump the entirety of the table - in which the flag is located.	

.. code-block:: python

	for i in range(0x100):
		command = bytes('t00210'.encode()) + (bytes([i])) + bytes('\r'.encode())
		ser.write(command)
		
.. code-block:: bash

	python -m can.logger -i pcan -c PCAN_USBBUS1 --filter 0x002:0x7FF


	
Flag: bh{B4RK_B0RK_bOrK}.

[C] DID not done (2 solves)
^^^^^^^^^^^^^^^^^^^^^^^^^^^

Intended difficulty: Medium/Difficult. 
Tags: UDS.

.. code-block:: text

	Flag is a 26-byte string at 0x0803e000 but Read Memory By Address won't let me read it :(

The challenge prompt gives the address and size of the flag.
Scanning the UDS services of ECU C reveals that the service DynamicallyDefineDataIdentifier is active.
This service can therefore be used to define a dynamic DID (which should be in the 0xF300-0xF3FF range according to UDS standard) at 0x0803e000 (with size 26).
The flag can then be obtained by reading that DID using ReadDataByIdentifier.

.. code-block:: bash   
   
   echo "2c 02 F3 00 14 08 03 e0 00 1A" | isotpsend can0 -s 7e2 -d 7ea 	
   echo "22 F3 00" | isotpsend can0 -s 7e2 -d 7ea 

Flag: bh{TAKE_THE_LONG_WAY_HOME}.
	
Participant `write-up available here <https://laysakura.github.io/2024/10/24/automotive-ctf-2024-world-final/#c-did-not-done>`_.

[A/C] Ramen Clicker (1 solve)
^^^^^^^^^^^^^^^^^^^^^^^^^^^^^

Intended difficulty: Medium/Difficult. 
Tags: CAN, Hardware.

.. code-block:: text

	My high score is 0x9000.

The screen displays a "Ramen clicker" game, which counts up each time the SHIFT joystick is center-pressed.
The prompt suggests that the flag is displayed if the counter goes over 0x9000.


   
By observing the CAN bus, it can be observed that there is no authentication between ECU A and ECU C, therefore it is trivial to spoof the state of the joystick.
Using cansniffer, we can observe that 045#0106 corresponds to "joystick pressed" and 045#0101 corresponds to "joystick released" (first byte corresponds to gear status and can be ignored).

Trying to spoof these messages will however trigger the following screen:


  
The anti-cheat system is not punishing, and the game can be restarted without a power reset.
Because the firmware isn't provided, it is not clear what triggers the anti-cheat system.
However, because there is no proper authentication, we know that it should be possible to impersonate ECU C, as long as the impersonation is not obvious.

The first step is to exclude ECU C (normally transmitting the joystick messages) from the CAN bus, which can be done for example by:

- Using the expansion header of ECU C to short the reset pin (21) to the ground pin (4) (jumping wires were provided for that purpose).
- Using the USB serial interface to shut down ECU's C power supply.

After that, the player can just send 045#0106 and 045#0101 to increment clicks.

Note: The anti-cheat system is triggered when ECU A does not receive a message with CAN ID 045 for more than 500 ms, or when ECU A receives a message with ID 001 (ECU C sends a message with ID 001 to warn ECU A when it itself receives a message with ID 045 and therefore knows that someone is cheating). There is no message frequency checking.
It is not necessary to know these exact conditions, the player only needs to attempt a relatively clean transition between normal traffic and compromised traffic.

.. code-block:: bash

	#Turn off ECU C or hold it in reset mode, then immediately execute
	timeout 1000s bash -c 'while [ $SECONDS -lt 1000 ]; \
	do \
	cansend can0 045#0106; \
	cansend can0 045#0101; \
	done'

An alternative solution is to physically press the button 0x9000 times.

Flag: bh{N1NN1KUM4SHIMA5HI}.

[D] Security Access 1 (1 solve)
^^^^^^^^^^^^^^^^^^^^^^^^^^^^^^^

Intended difficulty: Very Difficult. 
Tags: Reverse, UDS, Hardware.

.. code-block:: text

	The attached file corresponds to the firmware of ECU D, with all its flags redacted.
	Try to extract the real value of bh{XXXXXXXXXXXXXXXXXXX} from your RAMN hardware.

The attached file is a .hex file, with no debug symbols and therefore a bit difficult to reverse engineer.
The .hex file is common for challenges "Security Access 1" and "Security Access 2".
A superficial analysis with Ghidra (loaded in ARM v8 LE mode) reveals that, as the title suggests, flags can be read with ReadDataByIdentifier (DID 0x0001 and DID 0x0002) after Security Access is performed (for levels 0x01 and 0x03, respectively).

Following references leads us to the Security Access algorithm.



Security Access check for "Security Access 1" is performed by FUN_0900be24, which can be identified as "memcmp" by AI tools such as ChatGPT.
We can conclude that 08002310h is where the address of the expected 16-byte (static) password is.


   
08002310h contains 0BF974C0h, but that address cannot be found in the firmware file.

Based on the address map of the `reference manual <https://www.st.com/resource/en/reference_manual/dm00346336-stm32l552xx-and-stm32l562xx-advanced-arm-based-32-bit-mcus-stmicroelectronics.pdf>`_, we can observe that 0BF974C0h is in the System memory bootloader area (in ROM). 
The trick is to identify that this value is in system memory and is therefore common to all STM32L552 microcontrollers (at least from the same batch), so it can be read from another ECU. Therefore, the password could be read:

- By using the ReadMemoryByAddress UDS Service of ECU C (which is not disabled, contrary to ECU D).
- Or, by using one of the many memory dump methods (UDS, FDCAN Bootloader, JTAG, etc.) of an unlocked RAMN with standard firmware (which was made available to participants).

With ECU C UDS:

.. code-block:: bash   
   
	echo "23 14 0B F9 74 C0 10" | isotpsend can0 -s 7e2 -d 7ea



With JTAG on ECU D of a reference RAMN:



Flag can be obtained by sending that password and reading DID 0x0001.   
   
.. code-block:: bash   
   
   echo "27 01" | isotpsend can0 -s 7e3 -d 7eb
   echo "27 02 40 49 6E 74 65 72 6E 61 6C 20 46 6C 61 73 68 20"  | isotpsend can0 -s 7e3 -d 7eb
   echo "22 00 01"  | isotpsend can0 -s 7e3 -d 7eb
   

   
Flag: bh{We_hAve_HSM_4t_Home}.

[D] Security Access 2 (1 solve)
^^^^^^^^^^^^^^^^^^^^^^^^^^^^^^^

Intended difficulty: Very Difficult. 
Tags: Reverse, UDS.

.. code-block:: text

	Same as “Security Access 1”, but you are looking for bh{YYYYYYYYYYYYYYYYYYY}.

Following the same steps as "Security Access 1", we can identify the function that checks the password.



This function compares the provided password to four 32-bit values, based on a function that uses as a parameter the strings "HAPPY HAPPY HAPPY HAPPY", "HAPPY HAPPY HAPPY", "HAPPY HAPPY", and "HAPPY" (with their respective size).

Following references, and with help from ChatGPT, we can identify that:

- FUN_080013a8 function reads from 080013b8h (which value is 20032A14h).
- 20032A14h is initialized by FUN_0800139c with parameter 20032820h.
- 20032820h is loaded from 08000c64h, which value is 40023000h.

Therefore, the password is read in 32-bit chunks from 40023000h. Reading the `reference manual <https://www.st.com/resource/en/reference_manual/dm00346336-stm32l552xx-and-stm32l562xx-advanced-arm-based-32-bit-mcus-stmicroelectronics.pdf>`_ again, we can identify that this address corresponds to a Special Function Register of the CRC engine peripheral.
Although we could follow references to reverse engineer the parameters of the engine (initialized at FUN_08003580), there are no attempt limits, therefore we can also simply try all common CRC32 algorithms (with different endianness).

We can use https://crccalc.com/ with the default STM32 CRC engine algorithm (CRC-32/MPEG-2), which gives us 0x14b311c9, 0x6442CA33, 0xC25DE077, and 0x6DA5F0C1, and corresponds to the correct password.

.. code-block:: bash   
   
    echo "27 03" | isotpsend can0 -s 7e3 -d 7eb
    echo "27 04 C9 11 B3 14 33 CA 42 64 77 E0 5D C2 C1 F0 A5 6D" | isotpsend can0 -s 7e3 -d 7eb
    echo "22 00 02"  | isotpsend can0 -s 7e3 -d 7eb



Flag: bh{Thanks_P3riPH3Rals!}.

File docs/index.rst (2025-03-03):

.. RAMN: Resistant Automotive Miniature Network documentation

Documentation of RAMN: Resistant Automotive Miniature Network 
=============================================================



.. toctree::
   :maxdepth: 2

   general 
   hardware
   firmware
   scripts
   quickstart
   userguide
   minictf
   ctf_writeups

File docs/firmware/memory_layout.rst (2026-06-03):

.. _memory_layout:

Memory Layout
=============

RAMN ECUs have three main memory regions: 

- **FLASH** (256kB or 512kB depending on the microcontroller), starting at 0x08000000.
- **INSECURE_RAM** (192kB, corresponding to **SRAM1**), starting at 0x20000000.
- **RAM** (64kB, corresponding to **SRAM2**), starting at 0x20030000.

If you run out of memory, see :ref:`about_memory`.

Memory Protection
-----------------

It is possible to **temporarily** protect **FLASH** and **RAM** from JTAG memory access (for example, if you want to use RAMN for a Capture The Flag event and need to protect its memory, but do not want to permanently lock your device).
You can use the RDP option byte (with level 1), which can be reversed at any time to allow ECU reprogramming.
**When a temporary memory protection is removed, firmware is automatically erased.**

**However, it is not possible to protect INSECURE_RAM without permanently disabling JTAG (RDP protection level 2).**

If you want to enable memory protection, see :ref:`memory_protection`.

.. note:: If you do not plan to use any of the memory protection features, you can (and should) replace the content of ``STM32L5_FLASH.ld`` with ``STM32L5_FLASH_INSECURE.ld``, which only defines one large 256kB RAM region (considered insecure) when compiling.

FLASH
-----

RAMN's ECUs make use of the dual bank architecture of the STM32L5. The memory layout of the FLASH memory is as below (if the microcontroller only has 256kB of memory, only the left part is present).



	Memory Layout of RAMN's ECUs
		
ECU firmware only uses one of the two flash banks at a time. The bank is divided in two parts:

- The Firmware Area, which holds the code currently being executed.
- The EEPROM Emulation Area, which holds data such as VIN, DTC, and other dynamic data.

When reprogramming the ECU **over UDS (NOT over other interfaces)**, the ECU will actually copy the new firmware, as well as the current EEPROM, to the inactive bank.
Once the copy is completed, the ECU will switch the **SWAP_BANK** Option Bytes to swap the two banks, effectively updating the firmware run by the ECU.

.. warning:: Swapping banks may confuse many external tools, such as STM32CubeIDE or STM32CubeProgrammer. Before using those tools, you should ensure that the **SWAP_BANK** Option Byte is unchecked.

If you do not need EEPROM emulation and want to use the entirety of the flash for your own application, you can disable the ``ENABLE_EEPROM_EMULATION`` flag in ``ramn_config.h``. Then you can modify ``STM32L5_FLASH.ld`` and replace ``LENGTH = 248K`` with ``LENGTH = 256K``.

Similarly, if you do not need UDS reprogramming and your microcontroller has 512kB flash (microcontroller reference ending with CET6), you can also disable the ``ENABLE_UDS_REPROGRAMMING`` flag in ``ramn_config.h`` and use ``LENGTH = 512K``.
You will also need to make sure that the **SWAP_BANK** Option Byte is unchecked in STM32CubeProgrammer (see :ref:`optionbyte_check`).

When you disable the ``ENABLE_UDS_REPROGRAMMING`` flag, ECUs will not accept UDS reprogramming, but ECUs will still be reprogrammable using JTAG or the STM32 bootloader interface (in `scripts/STbootloader`).

.. _ram_details:

RAM
---

Regions
^^^^^^^

STM32L5 microcontrollers have two RAM areas: SRAM1 and SRAM2.
**SRAM1 cannot be protected** unless JTAG is **permanently** disabled, so it will always be readable unless you are willing to permanently lock your device. 
SRAM2, however, can be temporarily protected.

As a result, RAMN defines the RAM and INSECURE_RAM regions. By default, variables are put in the RAM region. However, that region is only 64kB.
To avoid filling it too quickly, variables that are large but do not hold critical data are put in the INSECURE_RAM region.
This is done typically for USB, SPI, and CAN buffers, which only hold data that could be read by accessing those interfaces anyway.
Concretely, this can be done by adding ``__attribute__ ((section (".buffers")))`` to the variable declarations.

.. warning:: INSECURE_RAM has the "NOLOAD" parameter set, meaning you cannot initialize them when you declare them (e.g., if you write ``__attribute__ ((section (".buffers"))) uint8_t example = 1``, example will not hold 1 but it will hold whatever was in memory during boot). You can disable this behavior by removing ``(NOLOAD)`` in ``STM32L5_FLASH.ld``, but this will result in the generation of very large .bin files.

Heaps and Stacks
^^^^^^^^^^^^^^^^

Because RAMN relies on FreeRTOS, there are two heaps and several stacks:

- **STM32 main Heap and Stack** (**._user_heap_stack**, defined in ``STM32L5_FLASH.ld``).
- **FreeRTOS Heap** (**ucHeap** in **.bss**), used to dynamically allocate tasks.
- **FreeRTOS Stacks** (**Timer_Stack.0**, **Idle_stack.2**, and an **independent stack** for each task, in **.bss**).

If you run out of memory or encounter stack overflows, make sure that you identify which heap/stack can be made smaller and which heap/stack should be made bigger.

Memory Analysis
---------------

You can observe RAMN's memory usage by building the project and selecting **"Window"** > **"Show View"** > **"Build Analyzer"** (you may need to select **"File"** > **"Refresh"** then click the refresh icon in the build analyzer window to have it displayed correctly).
This will show you what percentage is currently in use. 


   
You can select the "Memory Details" tab to have a better overview of which variables are using space.
If you need more memory, there are suggestions of variables to make smaller in the :ref:`about_memory` section.
   


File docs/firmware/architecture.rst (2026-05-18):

.. _architecture:

Firmware Architecture
=====================

ECU A, B, C and D share a common architecture, with the exception that ECU A also has USB enabled. On this page, we detail the architecture of the firmware for each ECU, starting with the simpler ECU B, C, and D.

ECU B, C, and D
---------------

Firmware of ECU B, C and D contains six tasks:

- The CAN Receive Task, which receives and processes CAN messages through a `Stream Buffer <https://www.freertos.org/RTOS-stream-buffer-example.html>`_ filled by the CAN-FD peripheral Interrupt Service Routine (ISR).
- The Diag RX Task, which receives and processes full (reconstructed) diagnostic messages through a `Stream Buffer <https://www.freertos.org/RTOS-stream-buffer-example.html>`_ filled by the CAN Receive Task.
- The main Periodic Task, which is executed periodically at a specified interval (typically, 10ms). It is responsible for updating various modules of the firmware. Periodic CAN message transmissions are requested by this task.
- The Diag TX Task, which is responsible for fragmenting and sending diagnostic answers, with specified Flow Control settings.
- The CAN Send Task, which is responsible for sending CAN messages requested through a `Stream Buffer <https://www.freertos.org/RTOS-stream-buffer-example.html>`_. Messages may be requested by any other task that needs to communicate over CAN.
- The Error Handling Task, which is woken up when an error needs to be processed and reported.



	Architecture of firmware of ECU B, C, and D.

ECU A
-----

Firmware of ECU A is identical to ECU B, C, and D, but with two additional tasks:

- The USB Receive Task, which receives USB commands and processes them
- The USB Send Task, which sends requested data (again, through a `Stream Buffer <https://www.freertos.org/RTOS-stream-buffer-example.html>`_) over USB.

With ECU A, diagnostic commands may also be sent over USB instead of CAN.



   Architecture of firmware of ECU A.

Additional Tasks
----------------

In recent versions, new tasks have been added to allow users to easily implement their custom tasks.
ECU A can (optionally) use these tasks to implement a gs_usb (candlelight) device.

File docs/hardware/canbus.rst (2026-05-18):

CAN/CAN-FD Bus 
==============

When simplified, the layout of the CAN bus can be approximated by the following figure.



   Simplified layout of the CAN/CAN-FD bus.
   
.. note:: Please refer to the :ref:`impedance_matching` section for information about impedance matching of the CAN/CAN-FD bus.

The CAN-FD bus is terminated on both sides by `120-ohm split-terminations <https://e2e.ti.com/blogs_/b/industrial_strength/posts/the-importance-of-termination-networks-in-can-transceivers>`_.



   Terminator used at each end of the CAN/CAN-FD bus.

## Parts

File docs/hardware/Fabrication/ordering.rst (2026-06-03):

PCB Ordering
============

The version of RAMN hardware in active development (on the `main branch <https://github.com/ToyotaInfoTech/RAMN/tree/main/hardware>`_) is aimed at ease of fabrication and cost.
The original version of RAMN is archived and is available in the `misc folder <https://github.com/ToyotaInfoTech/RAMN/tree/main/misc>`_.
This archived version uses some parts which are not easy to source anymore from turnkey fabrication services and/or are not cost effective for orders by RAMN users.

- If your goal is to make a RAMN cheaply and easily, use the information on this page.
- If your goal is to obtain the exact original hardware (e.g., for academic settings), download `RAMN_V1_reference_PCB.zip <https://github.com/ToyotaInfoTech/RAMN/blob/main/misc/RAMN_V1_reference_PCB.zip>`_ and send it to a PCB assembly prototyping service.

.. warning:: 

	**This page is provided for convenience only. We cannot guarantee the quality of your order**.

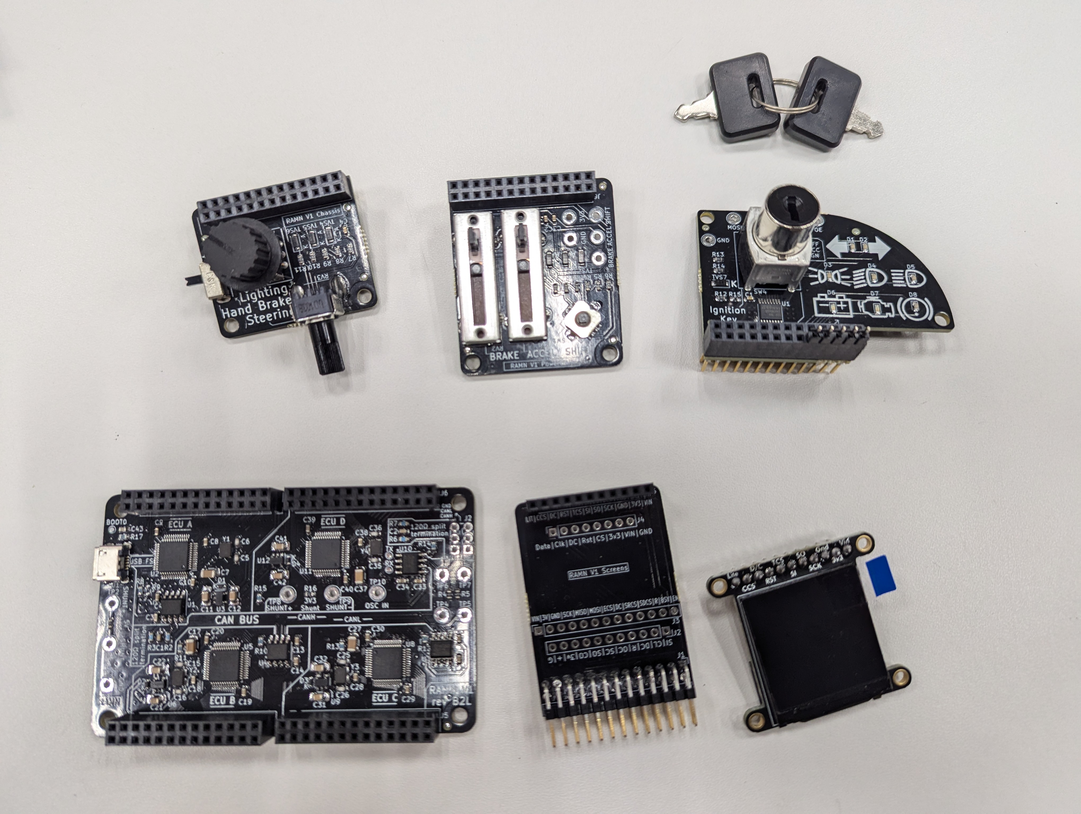
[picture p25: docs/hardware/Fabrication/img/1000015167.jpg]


The design files are complete enough that you can fabricate and/or assemble your own RAMN and expansions from any PCB prototyping service.

For convenience, there are two 're-orders' that can be made from PCBWay to get your own RAMN: 

1. The `mainboard <https://www.pcbway.com/project/shareproject/https_github_com_ToyotaInfoTech_RAMN_mainboard_ONLY_0dae9b72.html>`_.
2. The `expansions <https://www.pcbway.com/project/shareproject/https_github_com_ToyotaInfoTech_RAMN_pods_ONLY_3ff2c7a7.html>`_ (excluding the optional debugger expansion).

The mainboard is usable for many applications all by itself, but acquiring the expansions is required for changing the simulated vehicle state e.g. driving the car in CARLA.

On PCBWay, you have two purchase options:

- **PCB+Assembly**: you'll get PCBs with components already soldered (**pictures below**).
- **Only PCB**: you must order components in the BOM and solder them yourself (cheaper option).

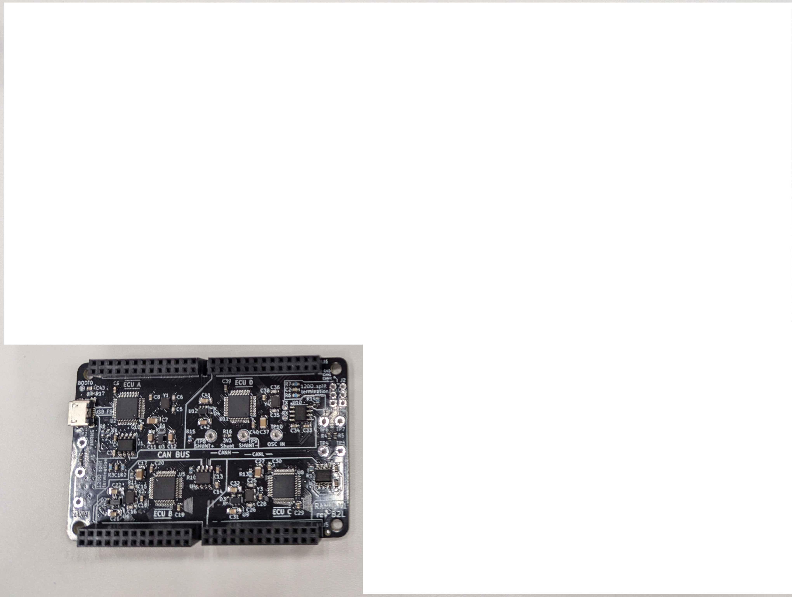
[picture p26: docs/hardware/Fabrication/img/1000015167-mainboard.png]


.. button-link:: https://www.pcbway.com/project/shareproject/https_github_com_ToyotaInfoTech_RAMN_mainboard_ONLY_0dae9b72.html
    :color: primary
    :expand:

    Mainboard from PCBWay



.. button-link:: https://www.pcbway.com/project/shareproject/https_github_com_ToyotaInfoTech_RAMN_pods_ONLY_3ff2c7a7.html
    :color: secondary
    :expand:

    Expansions Panel from PCBWay

The bill of materials used in the above orders was tailored to match
the components that are available from PCBWay, and some parts are
removed (marked DNP) to reduce costs (e.g. test points).
See :ref:`additional_components` for a list of optional components you may want.

.. warning::

	The PCBWay re-order uses **STM32L562CET6** microcontrollers. These microcontrollers feature a **hardware cryptographic engine**, which means that they may be subject to import/export restrictions.
	If these restrictions apply to you, you should request to replace **STM32L562CET6** with **STM32L552CET6**, which is the same microcontroller but without the cryptographic engine (see :ref:`microcontroller_sel`).
	RAMN's firmware does not use this engine.

Parameters
----------

You should keep most of the default parameters: 

- **FR4 material**
- **2 layers**
- **1.6mm thickness**
- **1oz (35um) copper**

You should be able to select any surface finish, although we suggest that you stay away from any solution with lead.
**"HASL lead free"** is typically the cheapest solution without lead, but may tarnish over time.
We typically use **"Immersion gold (ENIG)"**, and haven't tried other surface finishes ourselves.

**"Solder Mask"** corresponds to the color of the board, and **"Silkscreen"** corresponds to the color of the text and lines.
You can select any color you like, although you should ensure enough contrast to read the text (e.g., do not select white soldermask with white silkscreen).

With PCBWay, we recommend that you select one of these colors for the soldermask: **green, red, yellow, blue, purple, or matte green**.
If you select a **black, white, or matte black** soldermask, PCBWay may warn you that the soldermask constraints of RAMN cannot be respected (the soldermask spacing between microcontroller pins and USB connector pins is 0.20mm, but PCBWay asks for at least 0.22mm).
If you want to use one of these colors anyway, it is typically OK to ask PCBWay to ignore the issue, or to remove problematic soldermask themselves. This will however slightly increase the probability of soldering issues.

.. note::

	To avoid fabrication issues, it is recommended that you copy the content of the :ref:`componentorientation` Section in the order's details.

Ordering Fewer Than a Quantity of Five (5)
------------------------------------------

The PCBWay ordering system might make it seem like ordering 5 or more RAMN is required; however, only (bare) PCBs must be ordered at a minimum of 5. It is possible to order as little as 1 assembled mainboard and/or expansions panel.
If you only want 1 RAMN, you can set "5" in the number of PCBs, and "1" in the number of assemblies, as shown in the screenshot below.

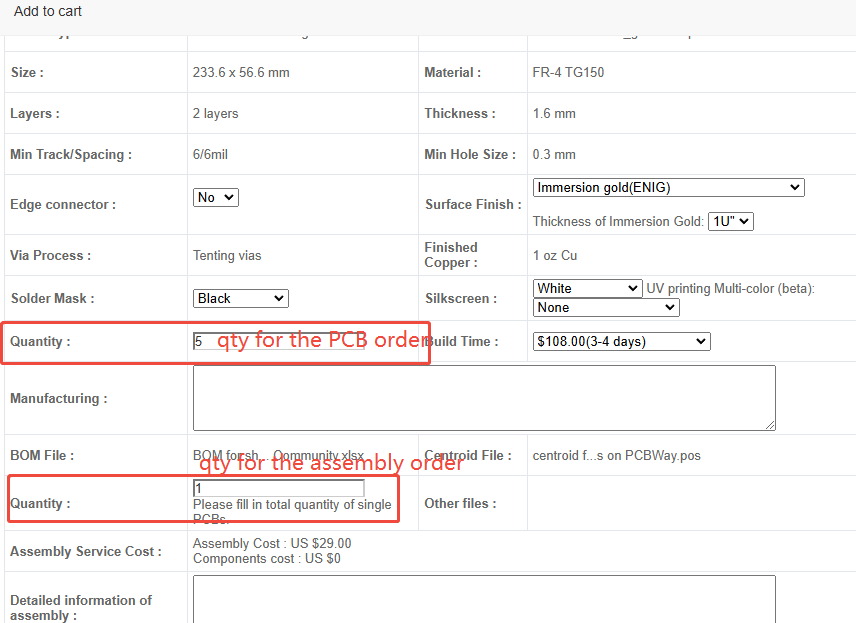
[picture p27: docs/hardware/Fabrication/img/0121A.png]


The more boards you order, the cheaper they become.
If you order 5 assembled RAMN sets, the expected cost is approximately 210 USD per full RAMN set (assuming a green soldermask and ENIG surface finish, and without the optional debugger expansion).
If you order only one set, that cost however becomes 430 USD. If you order 100 sets, it becomes about 140 USD.

.. _additional_components:

Additional Components
---------------------

The following components are not in the PCBWay order, because they are not absolutely needed.
If you want them, consider requesting them to PCBWay or ordering them separately yourself:

- 1x Micro type B USB cable: any maker, but avoid power-only cables.
- 1x Terminal block (for external CAN/CAN-FD tools): **Phoenix Contact 1770966**.
- Test probes: **Vero Technologies 20-313143** (as many as you need).
- 1x Steering wheel potentiometer knob: **Davies Molding 1231-M**.
- 4x Hex spacers: **Keystone 24313** (male) and **Keystone 24390** (female) (8 pieces total).

Only the terminal block requires soldering.
Note that the Davies Molding 1300-F knobs used in the original RAMN are **not** compatible with the current order on PCBWay.

Production Notes
----------------

.. _componentorientation:

Component Orientation
#####################

You can identify the correct orientation of each component from the pictures above, or from the :ref:`schematics_details` page.

.. warning:: 

	Although there are silkscreen markings to indicate the correct orientation of each component, the two following components are susceptible to being soldered with the wrong orientation by the fab and therefore require extra attention:

	- SW1 (Shift Joystick): the notch should be on the opposite side of the silkscreen word "SHIFT" (see :ref:`powertrain_details`).
	- SW3 (Lighting Switch): see pictures below.
	
	.. table:: Incorrect lighting switch orientation (leftmost, rightmost, without cap)
	   :align: center

	   +---------------------------+---------------------------+---------------------------+
	   | 
	   |    :width: 200px          |    :width: 200px          |    :width: 200px          |
	   +---------------------------+---------------------------+---------------------------+
	   
	.. table:: Correct lighting switch orientation (leftmost, rightmost, without cap)
	   :align: center

	   +-----------------------------+-----------------------------+-----------------------------+
	   | 
	   |    :width: 200px            |    :width: 200px            |    :width: 200px            |
	   +-----------------------------+-----------------------------+-----------------------------+

Below are clarifications based on past questions from fabs:

- Orientation of D8 on 4_body PCB is as specified by the graphics at the bottom-right of the PCB's silkscreen (same orientation for all LEDs; K up and A down). The dot near the bottom of D8 is just art, it does not indicate the cathode.
- Y1, Y2, Y3, Y4 do not have orientation (they are passive crystals, despite their unusual footprint).

BOM Component References
########################

Expansions (1_screens to 5_debugger) use non-overlapping references and can easily be panelized together.
The main board (0_ramn) has components references that overlap with the expansions, and some fabs may refuse panelization because of that reason.

Notes from Past Issues
######################

ECU A's screen (external-1 in BOM) is rather fragile and requires careful handling and packaging.

We have had past production issues with badly soldered potentiometers (RV1 and RV2).
Similarly, we have had one rare occurrence of a defective SW2 (OS102011MA1QN1), probably also due to bad soldering.
We have had one report of SW3 (on the Chassis Expansion Board) being soldered with the wrong orientation.

Those components therefore require extra attention during soldering and quality check.

Alternative Components
----------------------

Components availability and cost may vary.

- **RK09D1110C0R** may not be easily available.
  **RK09K1110B26** and **RK09K1110A2S** are acceptable alternative, but they may need small adjustments to prevent the knob from hitting the edge of the PCB. The knob may also come off more easily as a result.
- **SSQ-113-23-G-D** can be replaced with **SSQ-113-23-L-D**, **SSQ-113-23-F-D**, or **SSQ-113-23-T-D**.
  They can also be replaced with **4UCON TECHNOLOGY 18507**, but those have softer pins, which are more prone to bending.
- LEDs can be replaced with **SML-D12P8WT86**, **SML-D12D1WT86**, and **SML-D12V1WT86** (depending on color). If you use other LEDs, make sure they have a similar nominal current.

3D-Printed Base and D-Pad
-------------------------

User 0xRM shared .stl design data on `Thingiverse <https://www.thingiverse.com/thing:7275735>`_ for an unofficial, custom 3D-printed base and joystick D-pad (shift lever) for RAMN.

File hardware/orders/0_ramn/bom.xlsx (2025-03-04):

 |  |  | RAMN 50PCS BOM
Item # | *Designator | *Qty | Manufacturer | *Mfg Part # | Description / Value | *Package/Footprint | Type | Your Instructions / Notes | Accept Substitutes? | PCBWay Update
1 | C1 C2 | 2 | MURATA | GCM188R91H472KA37D | CAP CER 4700PF 50V X7R 0603 | 0603 | SMD |  | Y
2 | C11 C12 C21 C22 C31 C32 C41 C42 | 8 | MURATA | GCM31CL81H105KA55L | CAP CER 1UF 25V X7R 1206 | 1206 | SMD |  | Y
3 | C3 C4 C8 C9 C10 C13 C14 C18 C19 C20 C23 C24 C28 C29 C30 C33 C34 C38 C39 C40 C43 | 21 | MURATA | GCM188R71H104KA57J | CAP CER 0.1UF 50V X7R 0603 | 0603 | SMD |  | Y
4 | C5 C6 C15 C16 C25 C26 C35 C36 | 8 | MURATA | GCM1885C1H100JA16J | 10 pF ±5% 50V Ceramic Capacitor C0G, NP0 0603 (1608 Metric) | 0603 | SMD |  | Y
5 | C7 C17 C27 C37 | 4 | MURATA | GRT31CR6YA106KE01L | CAP CER 10UF 6.3V X7R 1206 | 1206 | SMD |  | Y
6 | R8 R10 R11 R12 R13 R14 R15 R17 | 8 | KOA | RK73H1JTTD1002F | RES 10K OHM 1% 1/10W 0603 | 0603 | SMD |  | Y
7 | R1 R4 R5 R16 | 4 | KOA | RK73Z1JTTD | RES SMD 0 OHM JUMPER 1/10W 0603 | 0603 | SMD |  | Y
8 | R2 R3 R6 R7 | 4 | KOA | RK73H1JTTD60R4F | RES 60.4 OHM 1% 1/8W 0603 | 0603 | SMD |  | Y
9 | ~~R9~~ | ~~1~~ | ~~未実装~~ | ~~RK73Z1JTTD~~ | ~~RES SMD 0 OHM JUMPER 1/10W 0603~~ | ~~0603~~ | ~~SMD~~ | ~~DNP~~
10 | J1 | 1 | Wurth | 629105150521 | CONN RCPT USB2.0 MICRO B SMD R/A | SMD | SMD |  | Y
~~11~~ | ~~J2 ~~ | ~~1~~ | ~~Phoenix Contact~~ | ~~1770966~~ | ~~Terminal Block 3pin~~ | ~~3POS~~ | ~~PTH~~ | ~~DNP~~
12 | J3 J4 J5 J6 | 4 | Harwin | M20-7831346 | WR-PHD 2.54 MM DUAL SOCKET HEADER 2x13 26POS | 26POS | PTH |  | Y
13 | ~~TP1 TP2 TP3 TP4 TP5 TP6 TP7 TP8 TP9 TP10 ~~ | ~~10~~ | ~~Vero Technologies~~ | ~~20-313143~~ | ~~Test probe~~ | ~~1POS~~ | ~~PTH~~ | ~~DNP~~
14 | U1 U4 U7 U10 | 4 | Microchip | ATA6561-GAQW-N | 1/1 Transceiver CANbus 8-SOIC | 8-SOIC | SMD |  | Y
15 | U2 U5 U8 U11 | 4 | STMicroelectronics | STM32L562CET6 | ARM® Cortex®-M33 STM32L5 Microcontroller IC 32-Bit Single-Core 110MHz 512KB (512K x 8) FLASH 48-LQFP (7x7) | 48-LQFP | SMD |  | Y
16 | U3 U6 U9 U12 | 4 | On Semi | NCV8163ASN330T1G | Linear Voltage Regulator IC Positive Fixed 1 Output 250mA 5-TSOP | 5-TSOP | SMD |  | Y
17 | Y1 Y2 Y3 Y4 | 4 | NDK | NX3225GD-10.000M-STD-CRA-3 | 10 MHz ±50ppm Crystal 8pF 300 Ohms 2-SMD, No Lead | 2-SMD | SMD |  | Y
18 | D1 D2 D3 D4 | 4 | On Semi | RB520S30T1G | Diode 30 V 200mA Surface Mount SOD-523 | SOD-253 | SMD |  | Y

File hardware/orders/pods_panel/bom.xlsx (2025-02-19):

 | PCBWay BOM Template heading
Item # | *Designator | *Qty | Manufacturer | *Mfg Part # | Description / Value | *Package/Footprint | Type | Your Instructions / Notes
 | Screen pod
 | Reference Designator | Requested Quantity 1 | Manufacturer Name | Manufacturer Part Number | Description | Package / Footprint | Type (PCBWay: SMD, PTH) | PCBA Instructions/Notes | Accept Substitutes?
101 | N/A | 1 | Adafruit Industries LLC | 4313 | 1.3" 240X240 WIDE ANGLE TFT LCD | N/A | PTH |  | Y
102 | J1 | 1 | Amphenol ICC (FCI) | 68021-226HLF | CONN HEADER R/A 26POS 2.54MM | 26POS | PTH |  | Y
103 | J5 | 1 | Harwin Inc. | M20-7821146 | CONN RCPT 11POS 0.1 TIN PCB | 11POS | PTH |  | Y
104 | ~~J3~~ | ~~1~~ | ~~Sullins Connector Solutions~~ | ~~PPPC131LFBN-RC~~ | ~~CONN HDR 13POS 0.1 GOLD PCB~~ | ~~13POS~~ | ~~PTH~~ | ~~DNP~~ | ~~Y~~
105 | ~~J4~~ | ~~1~~ | ~~Harwin Inc.~~ | ~~M20-7820842~~ | ~~CONN RCPT 8POS 0.1 GOLD PCB~~ | ~~8POS~~ | ~~PTH~~ | ~~DNP~~ | ~~Y~~
106 | ~~J2~~ | ~~1~~ | ~~Harwin Inc.~~ | ~~M20-7821146~~ | ~~CONN RCPT 11POS 0.1 TIN PCB~~ | ~~11POS~~ | ~~PTH~~ | ~~DNP~~ | ~~Y~~
 | Chassis Pod
 | Reference Designator | Requested Quantity 1 | Manufacturer Name | Manufacturer Part Number | Description | Package / Footprint | Type (PCBWay: SMD, PTH) | PCBA Instructions/Notes | Accept Substitutes?
201 | R7, R8, R9, R10, R11 | 5 | Stackpole Electronics Inc | RMCF0603FT10K0 | RES 10K OHM 1% 1/10W 0603 | 0603 | SMD |  | Y
202 | C4 | 1 | Samsung Electro-Mechanics | CL10B104KB8NNWC | CAP CER 0.1UF 50V X7R 0603 | 0603 | SMD |  | Y
203 | J7 | 1 | Samtec Inc. | SSQ-113-03-G-D | CONN RCPT 26POS 0.1 GOLD PCB Contact Length - Post 10mm | 26POS | PTH | DO NOT CUT PINS | Y
204 | RV3 | 1 | Alps Alpine | RK09K1110A0J | 10k Ohm 1 Gang Linear Panel Mount Potentiometer None 1.0 Kierros 0.05W, 1/20W PC Pins, Board Locks | 3POS | PTH |  | Y
205 | SW2 | 1 | C&K | OS102011MA1QN1 | Slide Switch SPDT Through Hole, Right Angle 100MA 12V | 3POS | PTH |  | Y
206 | SW3 | 1 | NKK Switches | NR01104ANG13-2A | Rotary Switch 4 Position SP4T 0.4VA (AC/DC) 28 VAC Through Hole 4POS 0.4VA 28V | 4POS | PTH |  | Y
207 | TVS4, TVS5, TVS6 | 3 | Rohm Semiconductor | SMF5V0TR | 9.2V Clamp 21.7A Ipp Tvs Diode Surface Mount PMDU | 2-SMD | SMD |  | Y
 | Powertain Pod
 | Reference Designator | Requested Quantity 1 | Manufacturer Name | Manufacturer Part Number | Description | Package / Footprint | Type (PCBWay: SMD, PTH) | PCBA Instructions/Notes | Accept Substitutes?
301 | R1, R2, R3, R4, R5, R6 | 6 | Stackpole Electronics Inc | RMCF0603FT10K0 | RES 10K OHM 1% 1/10W 0603 | 0603 | SMD |  | Y
302 | C2, C3 | 2 | Samsung Electro-Mechanics | CL10B104KB8NNWC | CAP CER 0.1UF 50V X7R 0603 | 0603 | SMD |  | Y
303 | J6 | 1 | Samtec Inc. | SSQ-113-03-G-D | CONN RCPT 26POS 0.1 GOLD PCB Contact Length - Post 10mm | 26POS | PTH | DO NOT CUT PINS | Y
304 | RV1, RV2 | 2 | Bourns | PTA1543-2010CIB103 | 10 kOhms 0.05W, 1/20W Through Hole Slide Potentiometer Top Adjustment Type | 3POS | PTH |  | Y
305 | SW1 | 1 | Alps Alpine | SKRHAAE010 | SWITCH Joystick, 2 - Axis Digital (Mechanical Switch) Output 50MA 12V | 6-SMD | SMD |  | Y
306 | ~~Brake, Accel, Shift, GND, 3V3~~ | ~~5~~ | ~~Vero Technologies~~ | ~~20-313143~~ | ~~Test probe~~ | ~~1POS~~ | ~~PTH~~ | ~~DNP~~ | ~~Y~~
307 | TVS1, TVS2, TVS3 | 3 | Rohm Semiconductor | SMF5V0TR | 9.2V Clamp 21.7A Ipp Tvs Diode Surface Mount PMDU | 2-SMD | SMD |  | Y
 | Body pod
 | Reference Designator | Requested Quantity 1 | Manufacturer Name | Manufacturer Part Number | Description | Package / Footprint | Type (PCBWay: SMD, PTH) | PCBA Instructions/Notes | Accept Substitutes?
401 | C1 | 1 | Samsung Electro-Mechanics | CL10B104KB8NNWC | CAP CER 0.1UF 50V X7R 0603 | 0603 | SMD |  | Y
402 | R12, R13, R14 | 3 | Stackpole Electronics Inc | RMCF0603FT10K0 | RES 10K OHM 1% 1/10W 0603 | 0603 | SMD |  | Y
403 | R15 | 1 | YAGEO | RC0402FR-071K8L | RES 1.8K OHM 1% 1/16W 0402 | 0402 | SMD |  | Y
404 | D1, D2, D3, D4, D5, | 5 | Rohm Semiconductor | SML-D12P8WT86 | Green 560nm LED Indication - Discrete 2.2V 0603 (1608 Metric) | 0603 | SMD |  | Y
405 | D6, D7 | 2 | Rohm Semiconductor | SML-E12D8WT86 | Orange 605nm LED Indication - Discrete 2.2V 0603 (1608 Metric) | 0603 | SMD |  | Y
406 | D8 | 1 | Rohm Semiconductor | SML-D12U1WT86 | Red 620nm LED Indication - Discrete 2.2V 0603 (1608 Metric) | 0603 | SMD |  | Y
407 | J8 | 1 | Samtec Inc. | SSQ-113-03-G-D | CONN RCPT 26POS 0.1 GOLD PCB Contact Length - Post 10mm | 26POS | PTH | DO NOT CUT PINS | Y
408 | ~~MOSI, SCK, LE, GND, KEY, OE ~~ | ~~6~~ | ~~Vero Technologies~~ | ~~20-313143~~ | ~~Test probe~~ | ~~1POS~~ | ~~PTH~~ | ~~DNP~~ | ~~Y~~
409 | SW4 | 1 | NKK Switches | SK14DG13 (OR SK14EG13) | SWITCH KEYLK 3POS SP3T 0.4VA 28V | 3POS | PTH |  | Y
410 | U1 | 1 | STMicroelectronics | STP08CP05XTTR | IC LED DRVR LIN 100MA 16HTSSOP | 16-TSSOP | SMD |  | Y
411 | TVS7 | 1 | Rohm Semiconductor | SMF5V0TR | 9.2V Clamp 21.7A Ipp Tvs Diode Surface Mount PMDU | 2-SMD | SMD |  | Y

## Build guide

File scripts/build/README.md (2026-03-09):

# Build tools

## Content

This folder contains various scripts for headless builds of RAMN ECUs' firmware.

### Script naming convention

- `BUILD_Clean_{Release,Debug}.{sh,bat}` — Clean-build all ECUs locally
- `BUILD_{Release,Debug}.{sh,bat}` — Incremental-build all ECUs locally
- `docker_BUILD_Clean_{Release,Debug}.{sh,bat}` — Clean-build all ECUs via Docker
- `docker_BUILD_{Release,Debug}.{sh,bat}` — Incremental-build all ECUs via Docker
- `_build_ecu.sh` — Inner build script (called by the above); quiet by default (shows only the *Build Finished* summary line on success, full output on failure). Pass `--no-quiet` for full verbose output (used by CI). All wrapper scripts forward extra arguments (e.g. `--no-quiet`) to `_build_ecu.sh`
- `_version.sh` / `_version.bat` — Centralized STM32CubeIDE version config

## Usage

### Docker builds (recommended)

Run one of the `docker_BUILD_*.sh` (Linux/macOS) or `docker_BUILD_*.bat` (Windows) scripts.
Recommended: **docker_BUILD_Clean_Release.sh**.

Override the Docker image version via environment variable:

    DOCKER_STM32CUBEIDE_TAG=7.0 bash scripts/build/docker_BUILD_Clean_Release.sh

### Local builds

Requires STM32CubeIDE installed locally. For Windows, modify **_version.bat** to point to your
STM32CubeIDE install path, and ensure **../settings/FIRMWARE_WORKSPACE.txt** contains the workspace path.

For Linux/macOS, ensure `stm32cubeide` and `headless-build.sh` are in your PATH, then
run one of the `BUILD_*.sh` scripts.

## Version configuration

All scripts share version settings from `_version.sh` (Docker/Linux) and `_version.bat` (Windows).
Update these files when upgrading STM32CubeIDE.

*Copyright (c) 2021 TOYOTA MOTOR CORPORATION. ALL RIGHTS RESERVED.*

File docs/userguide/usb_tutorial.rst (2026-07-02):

.. _usb_tutorial:

Interacting with USB
====================

RAMN's ECU A features a USB connector that implements a virtual serial port.
That serial port can turn ECU A into a USB to CAN adapter using standard :ref:`slcan_commands`.
This is how the programs that we used so far in this guide were able to read and receive CAN messages with RAMN's USB port.

RAMN's USB port also implements various :ref:`custom_usb_commands` that can be used to perform actions not covered by the slcan protocol, such as disabling the power supply of a specific ECU.
Custom commands compatible with slcan are not very user-friendly; however, it is possible to use a :ref:`usb_cli` that resembles a traditional Linux interface instead.

If you are not familiar with serial terminals, keep in mind the following items:

- When using RAMN's slcan interface, you need to specify "CR" as the endline character ('\\r').
- You must ensure that the serial port of RAMN is not being used by any other program (virtual machine or programs accessing CAN). **This includes "slcand" used previously in this user guide**. If you cannot access the USB serial interface, try unplugging and replugging the USB cable (and do not run slcand after).
- By default, you should not expect any serial interface to support the "backspace" character. If you made a mistake while typing a command, you need to restart from the beginning. RAMN's :ref:`usb_cli` supports backspaces to be more user-friendly.

.. warning::

	Commands that change CAN settings (e.g., CAN filters or CAN baudrate) typically require that you reopen the CAN peripheral (e.g., by using the command ``O``).

Opening a terminal
------------------

Windows
^^^^^^^

A serial port can be accessed on Windows using a program such as `TeraTerm <https://teratermproject.github.io/index-en.html>`_ or `Putty <https://www.putty.org/>`_.
We use TeraTerm in this guide.

Connect RAMN to a USB port of your computer. Open TeraTerm, select "Serial", then press OK to open the serial port.
If you see several COM ports, identify which COM port is assigned to RAMN by finding the one that appears and disappears when you plug and unplug RAMN.
If you do not see any COM port, verify that it is not currently being forwarded to a virtual machine.
If you do not see a COM port but a "DFU" device, it means that you need to flash the board first (see :ref:`flashing_scripts`).

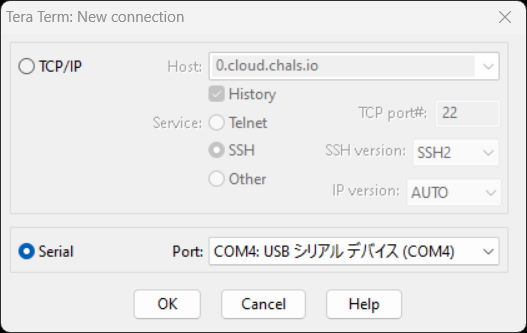
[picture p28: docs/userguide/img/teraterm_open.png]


After opening the port, select "Setup -> Terminal..." in the top menu bar, and change the following settings:

- Select "CR+LF" in the New-Line Receive options. This will ensure that slcan answers will appear on different lines.
- Check "Local echo" if you want the terminal to also display what you are typing.

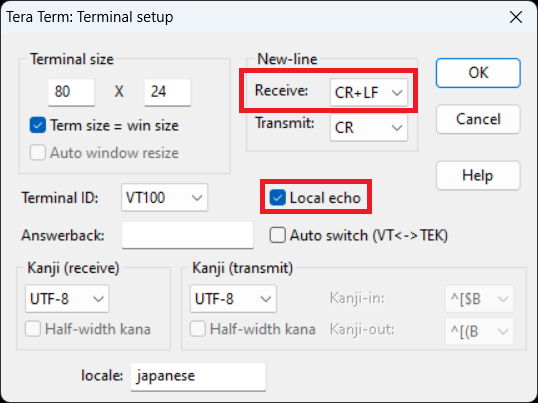
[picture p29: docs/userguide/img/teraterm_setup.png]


You should then be able to type serial commands and observe their answers on your terminal.

Linux
^^^^^

If you prefer to use Linux, you need to use a terminal that handles "CR-endline" devices well.
We recommend that you use picocom, which you can install with the following command:

.. code-block:: bash

    $ sudo apt-get install picocom

Identify what name was assigned to your device with the command ``dmesg`` (find which device appears when you plug in your RAMN board).
It is typically given a name such as "dev/ttyACM0".
You can open RAMN's serial port using the following command:

.. code-block:: bash

    $ picocom --imap crcrlf --echo /dev/ttyACM0

From there, you should be able to interact with RAMN directly in your terminal.
Type control A then control Q to exit the interface and revert to your normal Linux terminal.

.. _slcan_commands:

Slcan Commands
--------------

You can find a list of slcan commands in the original `LAWICEL's CAN232 manual <https://www.canusb.com/files/can232_v3.pdf>`_.
RAMN's implementation is slightly simplified in order to tolerate more mistakes from users.
Some slcan commands are not implemented or are slightly modified to better be suited for STM32's CAN FD controllers.

Slcan commands are sent only with ASCII characters; a byte of raw data is actually represented by two hexadecimal ASCII characters\ [#f1]_.

A successful slcan command will be answered by optional arguments and a "CR" character (ASCII 13).
A failed slcan command will be answered by a "BELL" character (ASCII 7), which in TeraTerm should be accompanied by an error sound.

Version - "V"
^^^^^^^^^^^^^

You can get the software version of your slcan adapter using the ``V`` command:

.. parsed-literal::

    V



Serial Number - "N"
^^^^^^^^^^^^^^^^^^^

Similarly, you can get the hardware serial number with the ``N`` command:

.. parsed-literal::

    N



This number corresponds to a "N" to which is concatenated the 12-byte unique device ID of the STM32 microcontroller of ECU A.

Open - "O"
^^^^^^^^^^

You can start forwarding CAN messages to the serial interface by typing ``O`` (capital letter o) in your terminal and pressing ENTER.
This command has no argument.

.. parsed-literal::

    O

This command should show you the current CAN traffic, confirming that you have a working board.

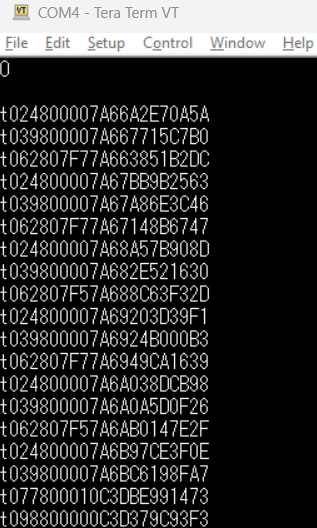
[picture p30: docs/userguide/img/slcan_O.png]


Close - "C"
^^^^^^^^^^^

You can stop the traffic from the previous command by using the command ``C``, which closes the port.
It has no argument.

.. parsed-literal::

    C

Listen - "L"
^^^^^^^^^^^^

The ``O`` command sets up the CAN controller in normal mode, which means that you are able to also send CAN messages.
The ``L`` command allows you to use the "Listen-only" mode of the CAN controller, preventing you from sending CAN messages and inadvertently impacting ongoing CAN traffic.

.. parsed-literal::

    L

Set Baudrate (identifier) - "S"
^^^^^^^^^^^^^^^^^^^^^^^^^^^^^^^

The ``S`` command allows you to change the baudrate of the CAN controller.
You need to reopen the port (e.g., with ``O`` or ``L`` commands) afterwards to validate the change.
The ``S`` command uses a 1-digit identifier to specify the baudrate. See :ref:`slcan_baudrate` for a list of these identifiers.

For example, you can use this command with baudrate identifier 6, which refers to RAMN's default 500 kbps:

.. parsed-literal::

    S6

Note that RAMN automatically assumes a 500 kbps baudrate, so you actually do not need to execute this command.

Set Baudrate (identifier) - "s"
^^^^^^^^^^^^^^^^^^^^^^^^^^^^^^^

If your desired baudrate does not have an identifier, you can change the baudrate with the ``s`` command instead.
You cannot provide a baudrate directly, instead you must provide the bit timings for the CAN controller.
Refer to :ref:`bit_timings` to understand how bit timings work.

You must provide two bytes to this function: TSEG1 and TSEG2, assuming a 40 MHz clock.
For example, to set up a 500 kbps baudrate directly, you can use this command:

.. parsed-literal::

    s3C13

which will set TSEG1 to 0x3C (60) and TSEG2 to 0x13 (19), following the example in :ref:`bit_timings`.

Transmit - "t" and "T"
^^^^^^^^^^^^^^^^^^^^^^

You can use ``t`` to send a CAN frame with a **standard** identifier, and ``T`` to send a CAN frame with an **extended** identifier.
You must provide the CAN ID, DLC, and payload, in order.

You must provide 3 digits for standard identifiers, and 8 digits for extended identifiers.
The number of digits is fixed, so you must pad with zeroes if necessary.
The DLC is only **one digit**. The payload comes after the DLC, in hexadecimal.

For example, you can send a CAN frame with standard identifier 0x024, DLC 2, and binary data "0x11 0xFF" with the following command:

.. parsed-literal::

    t024\ **2**\ 11FF

To transmit a CAN frame with an **extended identifier**, use the "T" command instead:

.. parsed-literal::

    **T00000**\ 024211FF

Note that there is no "receive" command: when the CAN adapter receives a CAN message, it forwards it to the USB serial interface using the ``t`` and ``T`` commands, but you are receiving them instead of transmitting them.

Transmit RTR - "r" and "R"
^^^^^^^^^^^^^^^^^^^^^^^^^^

The commands ``r`` and ``R`` are used similarly to ``t`` and ``T``, but for RTR commands, respectively for standard and extended identifiers.
You should not provide a payload to this command, but you still need to provide a one-digit DLC.

For example, to transmit an RTR request with standard identifier 0x701 and DLC 8:

.. parsed-literal::

    r7018

And to send the same frame with an extended identifier instead:

.. parsed-literal::

    R7018

If you type this without filters, it will however be difficult to observe the answer from ECU B.

Set Filter - "m" and "M"
^^^^^^^^^^^^^^^^^^^^^^^^

Hardware filters can be set using the ``M`` and ``m`` commands: ``M`` selects the value and ``m`` selects the mask.
Refer to :ref:`can_filters` to understand how CAN filters work by default.

The format is slightly different from the format in the original specifications.
**Filters apply independently to standard and extended identifiers.**

If you want to apply filters for standard identifiers, use a three-digit argument.
For extended identifiers, use an eight-digit argument.

For example, to apply filter value "701" and mask "7ff" (to only receive ID 0x701), use:

.. parsed-literal::

    M701
    m7FF

This will however not allow you to filter extended identifiers.
If you also want to receive the same ID but with an extended identifier, you need to also set the same filter for extended identifiers:

.. parsed-literal::

    M00000701
    m7FFFFFFF

You need to apply this filter by opening the CAN peripheral again (e.g., ``O`` or ``L``).
You should be able to see that after applying this filter, you can send an RTR frame and observe the answer directly in the terminal:

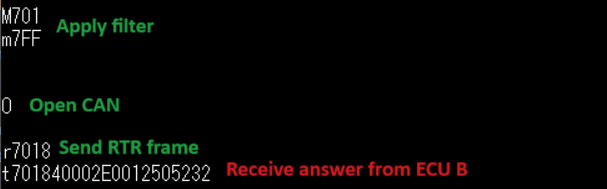
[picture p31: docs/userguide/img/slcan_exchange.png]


The last command should be received on the terminal, not sent by yourself.

.. warning::
    Software tools (such as candump) typically use software filters instead of hardware filters for slcan frames.
    If you apply a filter in hardware, it will likely stay until the next reset and may not be overridden by filter settings in your CAN software tools.

Filter Type - "W"
^^^^^^^^^^^^^^^^^

RAMN uses by default the "value and mask" filter explained in :ref:`can_filters`.
You can use the slightly modified command "W" to specify a different filter type.

- W0 uses the "RANGE" filter type of STM32, which specifies a range of IDs that you want to receive.
- W1 uses the "DUAL" filter type of STM32, which specifies two IDs that you want to receive.
- W2 uses the "value and mask" filter (default, also used when an invalid argument is provided).
- W3 uses the "RANGE NO EIDM" STM32 filter type.

Provide the first argument to the filter with the "M" command, and the second argument with the "m" command.

For example, Use "W0" to specify directly a range of IDs that you want to receive.
If you want to receive IDs from 0x700 to 0x703, you can use:

.. parsed-literal::

    W0
    M700
    m703

which is more human-readable than the "value and mask" equivalent.
Again, this only applies to standard identifiers, so you must also use m00000700 and M00000703 to also receive extended identifiers.

Read Status - "F"
^^^^^^^^^^^^^^^^^

This command returns one byte (as two hexadecimal characters) to report the status of the CAN controller.
Refer to the `CAN232 datasheet <https://www.canusb.com/files/can232_v3.pdf>`_ (F[CR] command) for the meaning of each bit.
The "arbitration lost" flag is not supported.

This command is implemented for compatibility with slcan, but it is recommended that you use the custom command "E" to read STM32 controller flags directly instead.

Enable Timestamps - "Z"
^^^^^^^^^^^^^^^^^^^^^^^

You can enable timestamps with ``Z1`` and disable them with ``Z0``.
Timestamps are added at the end of each frame as a 2-byte value (four digits) that is incremented every millisecond and overflows at 0xEA60 (60000).
Note that these are not technically real "CAN hardware" timestamps, they are software timestamps using a timer of freeRTOS.

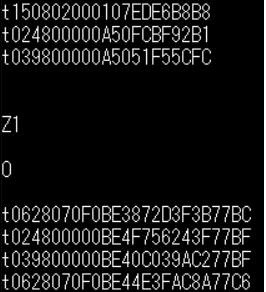
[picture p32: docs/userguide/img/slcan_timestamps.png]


Unsupported commands
^^^^^^^^^^^^^^^^^^^^

The following slcan commands are not supported by RAMN: "X", "U", "P", "A", "Q". This should however not prevent you from using RAMN with most tools, such as slcand.

.. _custom_usb_commands:

Custom RAMN commands
--------------------

Read Error Flags - E
^^^^^^^^^^^^^^^^^^^^

This command dumps all possible CAN errors and CAN protocol status registers of STM32's CAN FD controller.
See ``RAMN_DEBUG_DumpCANErrorRegisters`` in `ramn_debug.c` for the meaning of each bit.

Read FIFO Status - q
^^^^^^^^^^^^^^^^^^^^

This command dumps all possible FIFO status variables.
See ``reportFIFOStatus_USB`` in `main.c` for the meaning of each bit.

Read CAN Statistics - I
^^^^^^^^^^^^^^^^^^^^^^^

This command dumps CAN statistics, such as the number of messages received and transmitted.
See ``RAMN_DEBUG_ReportCANStats`` in `ramn_debug.c` for the meaning of each bit.

Set Bit timings with Prescaler - k
^^^^^^^^^^^^^^^^^^^^^^^^^^^^^^^^^^

This command can be used to set nominal bit timings with a 2-byte prescaler.
Its format is  ``kxxxxyyzz``, where xxxx is the prescaler, yy is TSEG1, and zz is TSEG2.
For example, to set a 500 kbps baudrate, instead of using TSEG1 = 69 and TSEG2 = 20, you could use a prescaler of 2 with TSEG1 = 30 (0x1E) and TSEG2 = 9 (0x9):

.. parsed-literal::

    k00021E09

Set Synchronization Jump Width - G
^^^^^^^^^^^^^^^^^^^^^^^^^^^^^^^^^^

This command allows you to set the Synchronization Jump Width (SJW) parameter of the CAN FD controller.
You can use ``Gxx`` to provide only the nominal SJW (xx), or ``Gxxyy`` to provide both nominal (xx) and data SJW (yy).

For example, use the following command to set the nominal SJW to 10 (0x0A):

.. parsed-literal::

    G0A

You can for example observe how using a large SJW allows you to tolerate more timing errors.
For example, if you type:

.. parsed-literal::

    G01
    s3C12

and set up a wrong baudrate of 506.3 kbps with a small SJW of 1, you will not observe any message, but only CAN errors.
However, if you reset the board and set up a baudrate of 506.3 kbps with a large SJW of 16, you should be able to observe RAMN's 500 kbps traffic without errors:

.. parsed-literal::

    G10
    s3C12

Enable Auto-Retransmission - a
^^^^^^^^^^^^^^^^^^^^^^^^^^^^^^

The ``a`` command can be used to enable automatic CAN message retransmission.
When enabled, if ECU A fails to transmit a message, it will automatically retransmit it.
Use ``a0`` to disable it and ``a1`` to enable it.

Open in restricted mode - l
^^^^^^^^^^^^^^^^^^^^^^^^^^^

The ``l`` command (lowercase l) can be used to start the CAN peripheral in "restricted operations" mode, where the peripheral will be able to acknowledge CAN frames but not be able to transmit frames or error/overload frames.
It is different from the listen-only mode (``L``) because this mode does acknowledge CAN frames.

Custom CAN FD commands
----------------------

The following custom commands can be used to use CAN FD with RAMN's ECU A. Note that these settings only apply to ECU A, not to other ECUs.
Refer to :ref:`can_fd` to learn more about CAN FD.

Frame mode - f
^^^^^^^^^^^^^^

Use f to select in which mode the FD CAN peripheral should be opened:

- ``f0`` for classic CAN mode
- ``f1`` for CAN FD mode without Bitrate switching
- ``f2`` for CAN FD mode with Bitrate switching

Enable ISO mode - i
^^^^^^^^^^^^^^^^^^^

Use ``i0`` to set up the peripheral in non-ISO CAN FD mode, and ``i1`` in ISO CAN FD mode.

Set Data bit timings - K
""""""""""""""""""""""""

Use ``Kxxyyzz`` to set xx as the prescaler, yy as TSEG1 and zz as TSEG2.
Note that for this command, the prescaler is only one byte.

For example, to use a 2 Mbps data baudrate, use:

.. parsed-literal::

    K010F04

Send CAN FD frame without BRS - 0
^^^^^^^^^^^^^^^^^^^^^^^^^^^^^^^^^

Start a frame with ``0`` to specify that you want to execute the rest of the command as CAN FD **without** BRS.
For example, use the following command to send a **CAN FD frame without Bitrate Switching**, with CAN ID 0x24, DLC 2, and payload 0x01FF.

.. parsed-literal::

   0t024201FF

You can also use the same prefix for the ``r``, ``t``, and ``T`` command.

Send CAN FD frame with BRS - 1
^^^^^^^^^^^^^^^^^^^^^^^^^^^^^^

Similarly, start a frame with ``1`` to specify that you want to execute the rest of the command as CAN FD **with** BRS.
For example, use the following command to send a **CAN FD frame with Bitrate Switching**, with CAN ID 0x24, DLC 2, and payload 0x01FF.

.. parsed-literal::

   1t024201FF

You can also use the same prefix for the ``r``, ``t``, and ``T`` command.

Include ESI bit - v
^^^^^^^^^^^^^^^^^^^

Use ``v0`` and ``v1`` to enable or disable the addition of an "i" at the end of CAN FD frames that have the "ESI" flag set as "PASSIVE".

Custom ECU control commands
---------------------------

Display Help - H
^^^^^^^^^^^^^^^^

This command returns a link to RAMN's documentation. It can also be called with ``h`` and ``?``.

Get Random Byte - j
^^^^^^^^^^^^^^^^^^^

This command returns a random **byte** from ECU A's True Random Number Generator.

Get Random Integer - J
^^^^^^^^^^^^^^^^^^^^^^

This command returns a random **integer** from ECU A's True Random Number Generator.

Enable Debug logs - d
^^^^^^^^^^^^^^^^^^^^^

This command enables debug logs: errors will be displayed in a human-readable manner.
Type ``d1`` to enable debug logs and ``d0`` to disable them.

Dump Status on Errors - @
^^^^^^^^^^^^^^^^^^^^^^^^^

The command ``@1`` will automatically dump the CAN FIFO status and CAN Error status registers when an error is detected.
It can be disabled with ``@0``.

Restart in DFU Mode - D
^^^^^^^^^^^^^^^^^^^^^^^

This command can be used to restart the microcontroller in DFU mode, in order to reflash it over USB (see :ref:`embedded_bootloader` for details).
Use ``DzZ`` to execute it.

Start ECU bootloader - p
^^^^^^^^^^^^^^^^^^^^^^^^

This command can be used to restart ECU B, C, or D in bootloader mode, in order to reflash them over CAN FD (from ECU A's USB; see :ref:`embedded_bootloader` for details).
Use ``pB`` to start ECU B in bootloader mode, ``pC`` for ECU C, and ``pD`` for ECU D.

Reset - n
^^^^^^^^^

The command ``n`` will perform a reset for all ECUs.

Enable Power Supply - y
^^^^^^^^^^^^^^^^^^^^^^^

This command can be used to independently enable or disable the power supplies of ECU B, C, and D, respectively.
Its format is ``yxz``, where x is the ECU name and z is the power supply status (0 or 1).
For example, type the following command to disable ECU D's power supply.

.. parsed-literal::

   yD0

You should be able to see the LEDs turning off. Type the following command to enable ECU D's power supply again:

.. parsed-literal::

   yD1

Enable All Power Supplies - Y
^^^^^^^^^^^^^^^^^^^^^^^^^^^^^^

This command is similar to the previous command, but applies to ECU B, C, and D almost simultaneously.
Use ``Y0`` to disable all their power supplies, and ``Y1`` to re-enable them.

Send UDS Message - %
^^^^^^^^^^^^^^^^^^^^^

The command ``%`` can be used to send UDS message over USB to ECU A, without using CAN.
Simply provide the size and the UDS payload in an hexadecimal string. The size should be provided first with three digits.
For example, use the following command to send a "Tester Present" UDS command (2-byte payload) of "3E00":

.. parsed-literal::

   %0023E00



Enter Command Line Interface - #
^^^^^^^^^^^^^^^^^^^^^^^^^^^^^^^^

Type ``#`` to enter a more user-friendly :ref:`usb_cli`.
Contrary to the direct slcan serial interface, it supports backspace characters and provides more human-readable command names.

Exit Command Line Interface - b
^^^^^^^^^^^^^^^^^^^^^^^^^^^^^^^

The command ``b`` can be used to exit the :ref:`usb_cli` and ensure that the device is currently accepting slcan commands.
It is available both in normal slcan mode and in the Command Line Interface mode.

Display freeRTOS Stats - X
^^^^^^^^^^^^^^^^^^^^^^^^^^

The command ``X`` can be used to display freeRTOS runtime stats, including CPU usage and stack usage.
Note that statistics start from boot and are never reset (therefore, CPU usage only represents the overall average from boot time).

Internal commands
^^^^^^^^^^^^^^^^^

The following commands are used internally by RAMN's scripts:

- The ``c`` command (either ``c0`` to enable it or ``c1`` to disable it) is used to activate the device in "CARLA" mode, where it periodically updates the driving simulator about the CAN bus status with serial packets.
- The ``u`` command is an update command used to synchronize a driving simulator and the RAMN board.
- The ``w`` command is used to apply new CAN peripheral settings without opening the slcan port.

.. _usb_cli:

Command Line Interface
----------------------

RAMN's Command Line Interface (CLI) provides the same custom features as offered over CAN, but in a more user-friendly manner.
Simply type the ``#`` custom slcan command to open it.
Then, you can type regular commands, such as "help" to display a help page.

You can for example type ``play 1`` to start a Chip-8 game on it, or ``theme 3`` to change the screen's theme to theme number 3.
You can also type ``trafficmode j1939`` (or ``trafficmode default``) to switch the CAN traffic profile of all ECUs at runtime (see :ref:`traffic_modes`).
If you type an invalid command, you will get a human-readable error message instead of just a "BELL" sound.

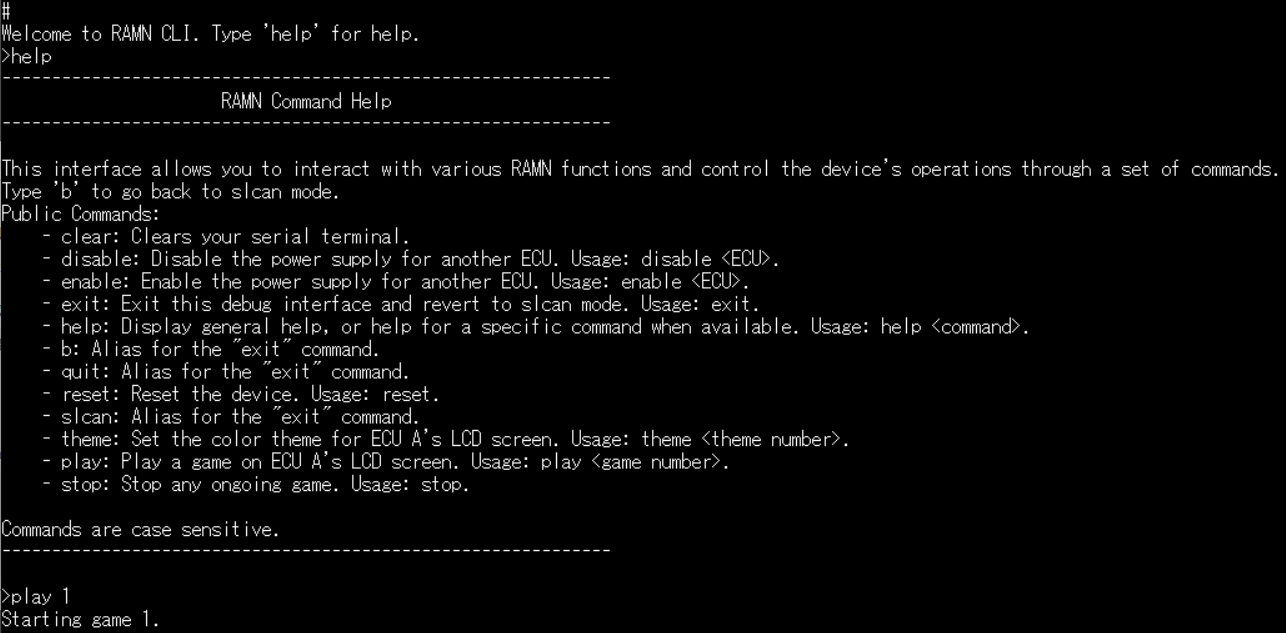
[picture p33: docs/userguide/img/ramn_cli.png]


.. rubric:: Footnotes

.. [#f1] For example, to send "7F" to represent the byte 0x7F, you actually send the ASCII characters 0x37 ("7") and 0x46 ("F") in binary data.

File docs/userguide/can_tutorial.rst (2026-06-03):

.. _interacting_with_CAN:

Interacting with CAN
====================

Introduction
------------

`Controller Area Network (CAN) <https://en.wikipedia.org/wiki/CAN_bus>`_ is the most popular communication protocol found in vehicles.
It uses **only two wires, common to all ECUs**: CAN High (CANH) and CAN Low (CANL).
CAN only supports broadcasting, with no built-in security mechanisms: any ECU can send any message, and all ECUs connected to the same CAN bus will receive the same messages.
A CAN frame is simply a bitstream of zeroes and ones, with a fixed nominal baudrate (typically 500 kbps in modern vehicles).

A CAN frame contains:

- An **arbitration identifier** (often called **CAN ID** or just **ID**), which length can be 11 bits (*standard identifier*) or 29 bits (*extended identifier*).
- Bit Flags: **RTR** (Remote Transmission Request) and **IDE** (Identifier type).
- The payload data size (Data Length Code, **DLC**), ranging from 0 to 8 bytes.
- The actual payload **Data**.

ECUs are typically assigned arbitration identifiers that they use to periodically broadcast data, with different periods.
For example, with RAMN, ID 0x24 (transmitted every 10 ms) represents the brake pedal status, and ID 0x1B8 (transmitted every 100 ms) represents the engine key status.

Lower IDs have a higher priority: if two ECUs attempt to transmit at the same time, the ECU transmitting the higher ID will yield the bus and wait for another opportunity.
This ensures that the most important messages are always transmitted first.
If a message has a low ID, you can assume that it is important.

In addition to periodic CAN messages, ECUs may receive and transmit aperiodic messages, such as diagnostic messages.
ECUs may implement diagnostic interfaces defined by standard documents:

- `Unified Diagnostic Services (UDS) <https://en.wikipedia.org/wiki/Unified_Diagnostic_Services>`_
- `Keyword Protocol 2000 (KWP2000) <https://en.wikipedia.org/wiki/Keyword_Protocol_2000>`_
- `Universal Measurement and Calibration Protocol (XCP) <https://en.wikipedia.org/wiki/XCP_(protocol)>`_

Because CAN frames can only hold small payloads of 8 bytes or less, it is challenging to transmit large data (such as ECU firmware files) using CAN.
The XCP protocol is built around this limitation; however, UDS and KWP2000 rely on an intermediary **transport layer** called `ISO-TP (ISO 15765-2) <https://en.wikipedia.org/wiki/ISO_15765-2>`_.
The ISO-TP layer divides large payloads (up to 4095 bytes for the original version, and up to 4294967295 bytes for recent versions) into several CAN frames, and adds a flow control mechanism to ensure that they can be reconstructed by a receiver.

There are recent evolutions of the CAN protocol developed to enable higher bandwidths:

- `Controller Area Network with Flexible Data-Rate (CAN FD) <https://en.wikipedia.org/wiki/CAN_FD>`_
- `CAN XL <https://www.can-cia.org/can-knowledge/can/can-xl/>`_

In fact, RAMN's ECUs use CAN FD, but by default they only use classic CAN frames to stay compatible with popular tools not compatible with CAN FD.

Refer to the :ref:`advanced_can` section to learn about other CAN concepts that you may encounter but are not strictly required to continue this guide.

Connecting to CAN
-----------------

To connect to a CAN bus, you only need to connect the CANH and CANL wires of a CAN receiver to the CANH and CANL wires of the CAN bus.
In a real vehicle, this would typically be done using the `On-board Diagnostics (OBD-II) data link connector <https://en.wikipedia.org/wiki/Data_link_connector>`_ found below the instrument cluster.
Experimenting on a real vehicle does come with risks: you probably do not want to risk damaging a vehicle that you still intend to drive on public roads for years to come.
`RAMN <https://github.com/ToyotaInfoTech/RAMN>`_ was designed to replace a real vehicle with a simple four-ECU network embedded in a small form factor, in order to encourage education and research in automotive systems.

RAMN has a built-in USB to CAN adapter.
**Connecting RAMN to your computer is equivalent to connecting a USB to CAN adapter to the OBD-II port of a vehicle, but without the risks.**

CAN only supports broadcast transmissions: all ECUs always see the same traffic.
Whatever you receive over CAN is exactly what every other ECU sees; ECUs typically employ CAN filters to process only the messages that they need.

With CAN, you can:

- Connect to and disconnect from a CAN bus at any time (Hot plug/unplug).
- Observe CAN traffic between ECUs without employing man-in-the-middle techniques such as ARP poisoning.

Observing CAN on a Computer
---------------------------

Computers typically do not have a built-in CAN interface, and a special interface is therefore needed for them to connect to a CAN bus.

There are many USB-CAN adapters available on the market.
If you own such an adapter, you can connect it to RAMN's terminal block and get started with your experiments, following whatever guide that came with it.

The rest of this guide will assume that you use RAMN's built-in USB to CAN adapter.
RAMN implements the "slcan" protocol, also known as the "LAWICEL" or "Serial" protocol, which is supported by many CAN analysis software tools.

When using RAMN as your USB to CAN adapter, you will need to specify "*slcan*" as the interface type, and RAMN's serial port as the channel (typically, *COMx* or */dev/ttyACMx*).

Simple Examples
^^^^^^^^^^^^^^^

Python-CAN (Windows, Linux)
"""""""""""""""""""""""""""

Make sure that you have installed python on your computer (see :ref:`analysis_environment`).
Connect your board to your computer, open Windows's Device Manager, and find what new device appears in "Ports (COM & LPT)".
RAMN should typically be assigned a COM port number, such as "COM1".

On Linux, you should be able to find the device name (typically, /dev/ttyACM0) by executing the command ``dmesg`` and looking at the last lines (if you are using a VM, make sure that the USB device is forwarded to it).

Open a command window (open Powershell or press Windows+R on Windows) and execute the following command to observe the latest CAN frame for each CAN ID:

.. code-block:: bash

    $ python -m can.viewer -i slcan -c COM1

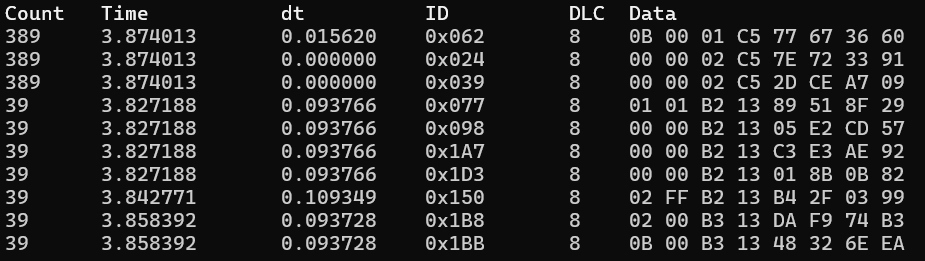
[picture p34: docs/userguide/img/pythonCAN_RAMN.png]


This may require that you install python modules with the command :code:`python -m pip install "python-can[viewer]"`.
Press Q to quit. From here, you should be able to directly use `python-can scripts <https://python-can.readthedocs.io/en/stable/scripts.html>`_ with RAMN.
If you encounter issues, see :ref:`unreliable_usb`.

SavvyCAN (Windows, Linux)
"""""""""""""""""""""""""

If you are not comfortable with command lines, you can try `SavvyCAN <https://www.savvycan.com/>`_ as an alternative for a tool with a GUI.
Simply download the latest SavvyCAN binary and install it.
(On Linux, download the .AppImage file and make it executable by typing :code:`chmod +x file.AppImage` then execute it by typing :code:`./file.AppImage`)

- Open the application and press "Connection -> Open Connection Window" in the top bar.
- Select "Add New Device Connection".
- Select LAWICEL/ SLCAN Serial.
- Enter the correct serial port (e.g., /dev/ttyACM0 or COM1).
- Use the default Serial Port Speed.
- **Input the correct CAN Bus Speed (by default, 500000)**.
- Press "Create New Connection".
- (Optional: press "Save Bus Settings")

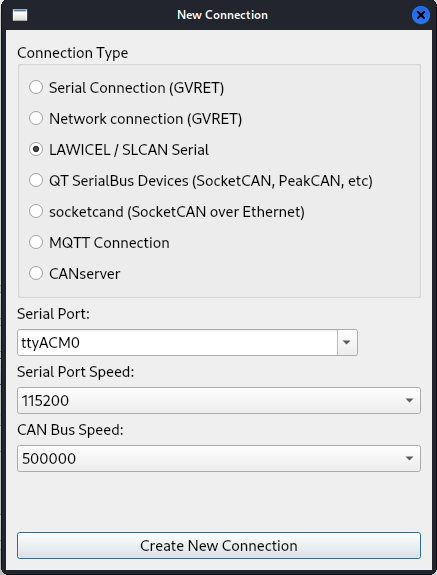
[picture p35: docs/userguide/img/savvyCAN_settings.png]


It is important that you select the correct CAN Bus Speed (and do not mistake it with Serial Port Speed).
You can then close the window, and you should be able to observe CAN messages.

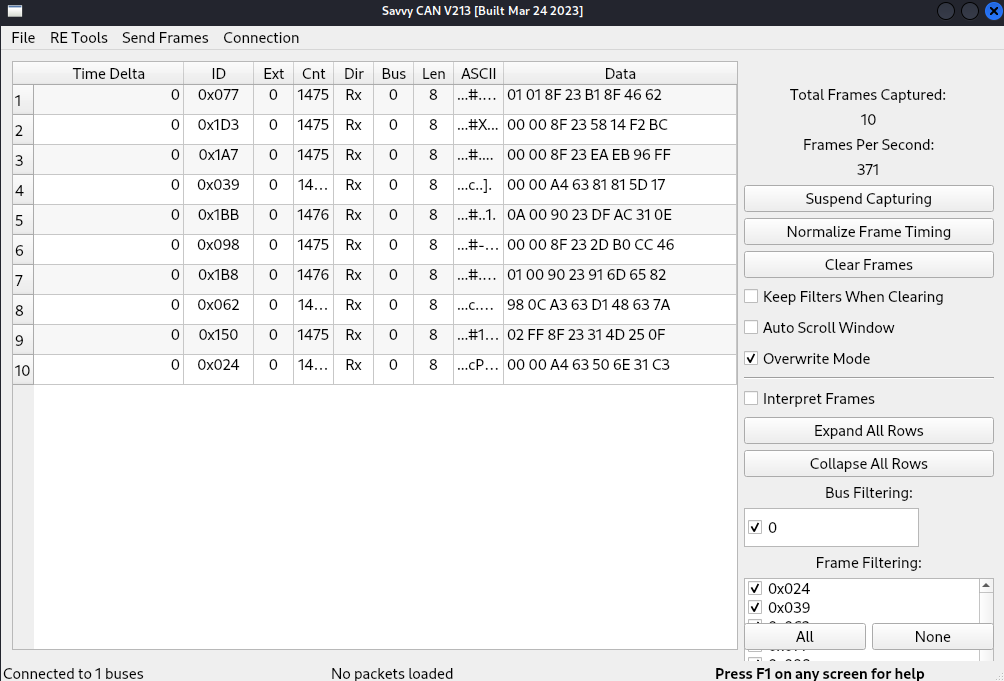
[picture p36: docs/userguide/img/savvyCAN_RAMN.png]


Refer to the `SavvyCAN documentation <https://www.savvycan.com/docs/>`_ for how to use the software.

Interfacing with Linux
----------------------

For the rest of this guide, we will focus on Linux and the `can-utils package <https://github.com/linux-can/can-utils>`_, often used by car enthusiasts.
Linux supports CAN as a standard interface, which means you can use it like any other linux interface.

.. _use_slcand:

Converting slcan to socketCAN
^^^^^^^^^^^^^^^^^^^^^^^^^^^^^

You can identify which name was given to your RAMN's slcan (serial port) by typing :code:`dmesg` and looking for the most recent device added, which should start with "*/dev/ttyACM*".
If you do not see any device, make sure that your RAMN is connected over USB, and that the USB device is forwarded to your VM (if applicable).

Some tools, such as wireshark, may not directly support slcan, but may support interfaces such as socketCAN.
For these tools, you can execute the following command to convert an slcan interface (e.g., /dev/ttyACM0) to a socketCAN interface (e.g., can0):

.. code-block:: bash

    $ sudo slcand -o -c /dev/ttyACM0 && sudo ip link set up can0

After executing this command, you should be able to see a new "can0" interface with the :code:`ifconfig` command.
This should allow you to use tools from the can-utils package, which are detailed in the following section.
In some environments, you may encounter issues with the command above.
If that is the case, try using a different name for the CAN interface, e.g., use "slcan0" instead of "can0" for all following commands.

.. code-block:: bash

    $ sudo slcand -o -c /dev/ttyACM0 && sudo ip link set up slcan0

On Linux, only one program can open a serial device at once, but several programs can open a CAN interface.
This means that if you use slcan directly, you will only be able to execute one CAN command at a time, but if you use socketCAN, you will be able to execute several commands in parallel.
In general, if a tool supports both socketCAN and slcan, you should use socketCAN.

.. note::
    When using a serial port with slcan, you may be asked for two baudrates/bitrates: the one for the serial port, and the one for the CAN bus.
    The baudrate of the serial port does not matter because it is virtual; however, the baudrate of the CAN bus matters and should be set correctly (by default, 500000 bps).

.. warning::
    Before starting slcand, make sure that no other program is currently using RAMN's serial port.
    When you use slcand, the serial port will always be busy and will not be accessible by other programs, such as TeraTerm.
    You can shutdown slcand and release the serial port with the following command:

    .. code-block:: bash

        $ sudo killall -w slcand

.. _slcan_baudrate:

CAN Baudrate
^^^^^^^^^^^^

You can change the CAN baudrate of your slcan adapter using the -s option, with an integer that corresponds to the following baudrates:

- 0 - 10000 bps
- 1	- 20000 bps
- 2	- 50000 bps
- 3	- 100000 bps
- 4	- 125000 bps
- 5	- 250000 bps
- 6	- 500000 bps (RAMN's default)
- 7	- 800000 bps
- 8	- 1000000 bps

For example, ``sudo slcand -o -c -s8 /dev/ttyACM0`` will open RAMN with a 1000000 bps CAN baudrate.
**Note that this only applies to the adapter (ECU A) and not other ECUs, so by default this should only display CAN errors.**
If you want to use another baudrate than the default 500000 bps, you must either reflash all ECUs, or use the UDS Link Control service (see :ref:`diag_tutorial`).

RAMN's vcand scripts
^^^^^^^^^^^^^^^^^^^^

The slcand command has two disadvantages:

- It does not support CAN FD.
- It monopolizes RAMN's serial port and prevents you from sending serial commands.

You can use `RAMN's vcand scripts <https://github.com/ToyotaInfoTech/RAMN/tree/main/scripts/vcand>`_ to create virtual additional serial interfaces and to convert a serial interface to a **CAN FD** socketCAN interface.

Refer to :ref:`vcand` for usage.

Note that as of 2024, these scripts are implemented in python and are not optimized for low CPU usage.

Experimenting with CAN on Linux
-------------------------------

Cansniffer
^^^^^^^^^^

cansniffer is probably the first command that you will want to try on a new network.
It allows you observe the **most recent frame** for each CAN identifier, and to highlight bit changes in color.

You can launch it with the following command:

.. code-block:: bash

    $ cansniffer -c can0

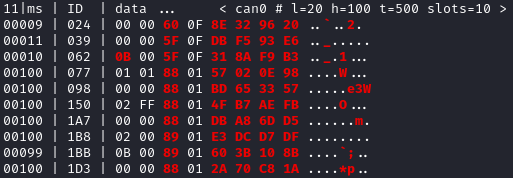
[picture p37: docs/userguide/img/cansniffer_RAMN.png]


To quit, press "q" then ENTER, or press "Control+C".

If you prefer to observe CAN messages in binary format, you can use the -B (or -b) option:

.. code-block:: bash

    $ cansniffer -B -c can0

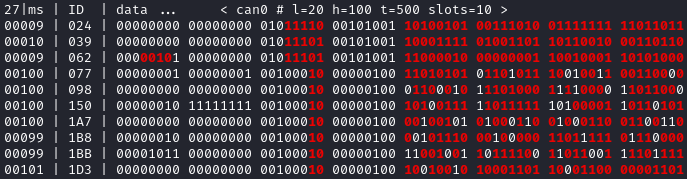
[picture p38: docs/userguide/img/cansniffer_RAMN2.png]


Once cansniffer is launched, you can still type commands, listed in cansniffer's help page (type commands directly in cansniffer's window and press ENTER).

On a modern automotive network, you will probably be overwhelmed with information, because there should be many CAN messages with many byte changes, even though the vehicle is in an idle state.
This is because CAN messages may implement complex algorithms, and include volatile fields such as message counters, Cyclic Redundancy Checks (CRCs) and Message Authentication Codes (MACs).

A useful command to filter volatile fields is the "#" (notch) command, which allows you to ask cansniffer to stop highlighting byte changes that have already been observed.
This allows you to make later changes (when you move RAMN's controls) more obvious.

Try typing the "#" commands several times in a row, without touching the controls.
You should observe that less and less bits get highlighted in color.
Then, move the brake controls on RAMN's board and observe cansniffer: the 2-byte payload of the brake message sent by ECU B should be highlighted and easy for you to spot.
You should also observe that one other bit from another CAN message is flipping when you move the brake pedal between and 0% and 100%: this bit corresponds to the status of the brake LED of ECU D (if that is not the case, verify that the Hand Brake is at the bottom position).
Because ECUs interact with each other, you cannot assume that a single control impacts only a single CAN message, and identifying the purpose of CAN messages can be tricky.

.. note::
    - For analog controls, you may observe that the last bits are changing even when the controls are not moved. This is caused by the analog noise of the sensors.
    - Integers may be represented with the Big Endian or Little Endian format. RAMN relies on ARM microcontrollers, which use Little Endian. This means that a payload may appear in the "wrong order" on cansniffer: for example, a value of 0x0FFF may appear as 0xF0FF.

If you want to filter out some messages from cansniffer, you can use the "-" command (e.g., "-024" to hide message 0x024).
You can also use the "n" command to filter all messages, then use the "+" command to add a message to observe (e.g., "+024" to only show message 0x024).
Use the "a" command to display all messages again.

Candump
^^^^^^^

Although cansniffer is a great tool to have an overview of a CAN bus traffic, it only displays the latest frame for each identifier.
To observe all CAN frames, in the same order in which they appeared, you can use candump instead.

.. code-block:: bash

    $ candump can0

Press Control+C to exit. You can use the -tz option to add timestamps, and the -a option to add ASCII output.

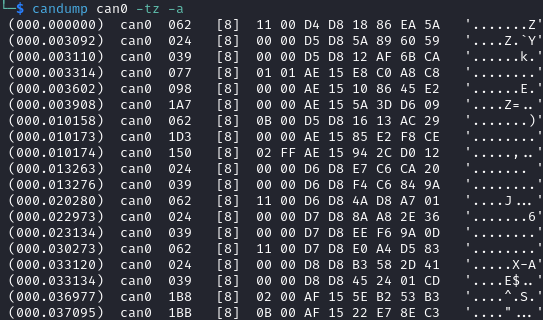
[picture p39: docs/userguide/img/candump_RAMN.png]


Not all messages have the same period, so you will observe some messages more frequently than others.
There are two main use cases for candump:

- To record a CAN traffic, for example to analyze it later offline (e.g., if you must share your RAMN board with someone else).
- To analyze the flow of specific CAN messages.

To record a CAN traffic to a file, you can use the -l option:

.. code-block:: bash

    $ candump -l can0

This will record the CAN traffic to a file, with an auto-generated name. If you want to specify the file name, use -f <filename> instead (this may only work on recent versions).

On a real network, you will probably observe so many frames that the output of candump will be too much to process.
Typically, you will want to identify interesting identifiers using cansniffer, then analyze them further with candump using filters.
Refer to the :ref:`can_filters` section for more information about filters.

You can apply a filter in candump by adding ",<value>:<mask>" after the interface name, with values in hexadecimal. For example:

.. code-block:: bash

    $ candump can0,1BB:7FF

You should observe on RAMN that although the output of candump is overwhelming, the output of the command above is not.
You can add several filters to candump, for example to observe IDs 0x1BB and ID 0x1D3, use:

.. code-block:: bash

    $ candump can0,1BB:7FF,1D3:7FF

This can be useful to identify relationships between CAN messages, for example:
place the brake pedal at zero, and the Hand Brake at the bottom position. This should ensure that the brake LED is OFF.
When you move the Hand Brake switch, you should observe that the brake LED lights up.
You can observe on cansniffer that two CAN IDs (0x1BB and 0x1D3) have a payload that changes as a result.
Because the LED and the switch are located on different ECUs, you can infer that one CAN message probably indicates the status of the brake LED and the other indicates the status of the switch, but
you do not know which one is which, because they appear to change simultaneously in cansniffer.

If you use the command above while moving the switch, you can observe that 0x1D3 changes value before 0x1BB does,
allowing you to deduce that 0x1D3 represents the value of the switch and 0x1BB represents the status of LEDs (which changes as a consequence of the reception of message 0x1D3).

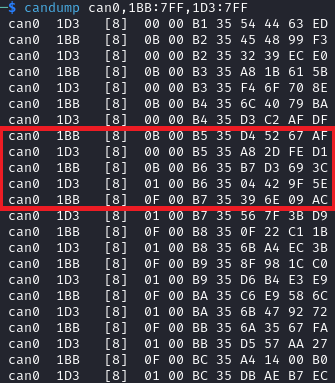
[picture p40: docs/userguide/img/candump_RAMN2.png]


Cansend
^^^^^^^

Cansend allows you to send CAN messages, using a CAN ID and a payload as arguments (in hexadecimal).

For example, to send a message with CAN ID 0x123 and a one-byte payload of 0xFF, use:

.. code-block:: bash

    $ cansend can0 123#FF

Using cansend, you can for example test the theory that 0x1BB represents the LEDs status and 0x1D3 represents the hand brake switch status.
Record a message from 1BB when the Hand Brake is at the ON position (top position), then move the Hand Brake to the OFF position (bottom position).
Make sure the brake pedal is at 0% and does not interfere with the brake LED.

You can replay a CAN message (in this example, with payload 07008A756501D87F) using cansend:

.. code-block:: bash

    $ cansend can0 1bb#07008A756501D87F

By sending this message, you are telling all ECUs "the brake LED is on", but that in itself does not turn the LED on.
However, if you record a message with CAN ID 0x1D3 when the hand brake is ON and send it again when the hand brake is off, you should observe that the brake LED briefly lights up:

.. code-block:: bash

    $ cansend can0 1d3#01008A754AC9B735

This is because this message says "The Hand Brake switch is ON", which itself causes ECU D to light up the brake LED.
However, it only lights up temporary because ECU B is still transmitting messages (telling ECUs that the Hand Brake switch is OFF), immediately overwriting whatever value you have sent.

You can use simple bash scripts to automate some transmissions, for example, if you want to send a message 100 times in a row:

.. code-block:: bash

    $ for i in {1..1000}; do cansend can0 1d3#01008A754AC9B735; done

Or if you want to flood the CAN bus with the same message for 2 seconds:

.. code-block:: bash

    $ timeout 2s bash -c 'while true; do cansend can0 1d3#01008A754AC9B735; done'

.. warning::
    If you send CAN messages normally transmitted by another ECU, and that other ECU is still actively transmitting, you may generate CAN errors.
    If you cause too many errors, you may force ECUs to disconnect from the CAN bus (see :ref:`can_errors`).
    By default, only a power reset will let ECUs reconnect, but you can configure RAMN's ECUs to auto-reconnect.

You can also use cansend to send messages with the RTR bit flag set, using *"<can id>#R<dlc>"* as its argument.
RAMN's ECU B, C, and D will answer to CAN RTR frames with IDs 0x701, 0x702, and 0x703 (respectively) with their hardware serial number.

You can display these messages in candump with:

.. code-block:: bash

    $ candump can0,700:7f0 -a

And, in another terminal, you can send the RTR frames:

.. code-block:: bash

    $ cansend can0 701#R8
    $ cansend can0 702#R8
    $ cansend can0 703#R8

Which should yield the following result:



Canplayer
^^^^^^^^^

You can "replay files" (i.e., send all CAN messages observed in a log file) generated by candump using canplayer.
You need to specify two interfaces as arguments: the interface from which you want to read messages in the file, and the interface on which you want to send the same messages.
Typically, you will want to use the same:

.. code-block:: bash

    $ canplayer -I <file> can0=can0

If you get errors, try executing ``$ sudo ifconfig can0 txqueuelen 10000``.

Here, we specify can0=can0 because we want to read messages on interface can0 (in the file) and replay them on can0 (actual hardware).

Canplayer is useful when you want to repeat a specific sequence of CAN messages, for example to repeat a UDS command that is fragmented in many CAN messages.
Canplayer is also useful when you want to isolate an ECU from the CAN bus on which it is normally connected.
Many ECUs will go to sleep if they do not detect normal CAN traffic, so using canplayer in an infinite loop ("-l i" option) can prevent it:

.. code-block:: bash

    $ canplayer -I <file> -l i can0=can0

Modern ECUs may not react well to canplayer because they have a message authentication mechanism preventing ECUs from accepting replayed messages.

Wireshark (Linux)
^^^^^^^^^^^^^^^^^

If you are familiar with wireshark, you can launch it and directly observe your socketCAN interface (e.g., you can directly open can0).
You should be able to apply usual Wireshark filters, and Wireshark should be able to parse complex CAN traffic such as UDS commands.

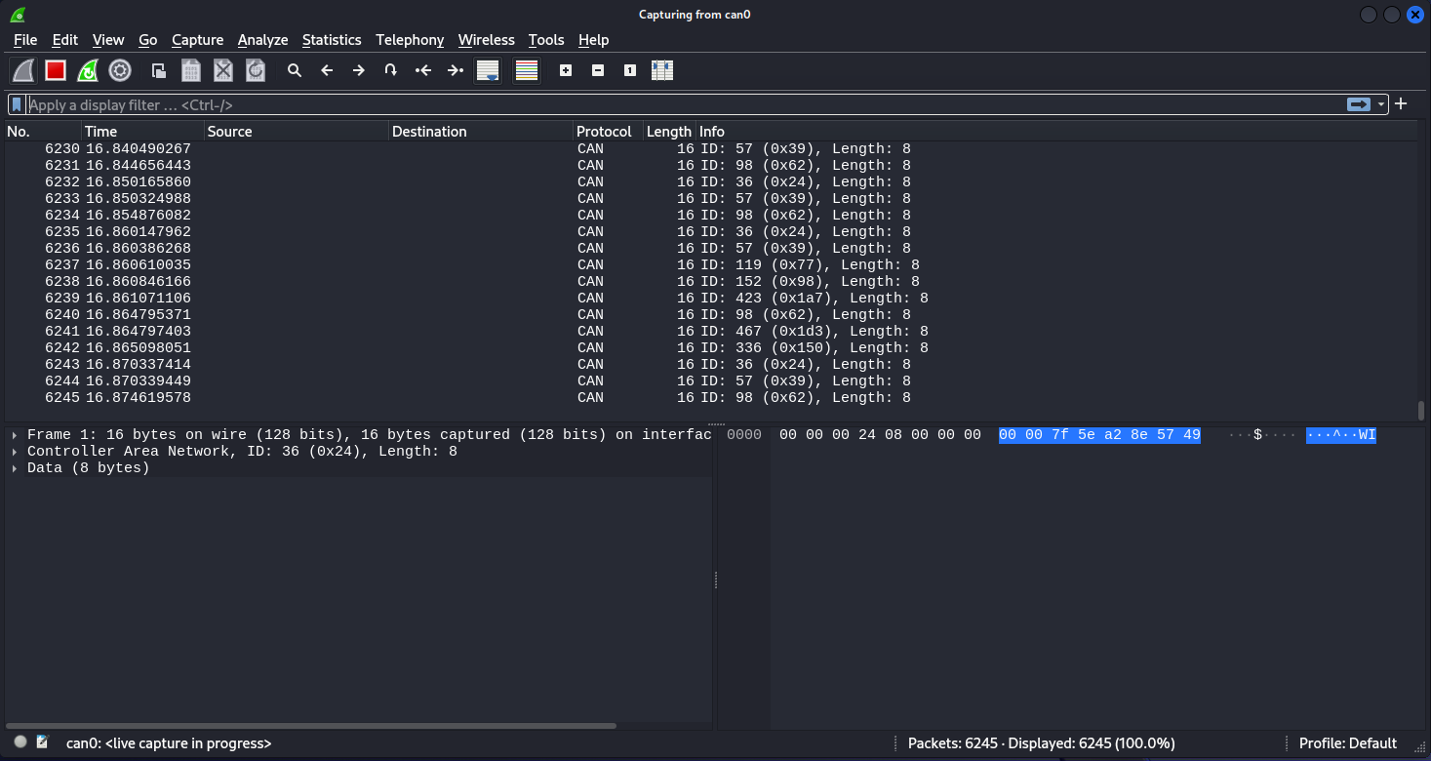
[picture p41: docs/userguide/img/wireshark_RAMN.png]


.. _advanced_can:

(Slightly) Advanced CAN concepts
--------------------------------

CAN Bus Termination
^^^^^^^^^^^^^^^^^^^

For `impedance matching <https://en.wikipedia.org/wiki/Impedance_matching>`_,
CAN requires that two resistors of 120 ohm be connected between each end of the CANH and CANL wires (which are common to all ECUs).
These resistors are present on RAMN, so if you use an external tool, make sure that it does not have termination resistors (usually by removing a jumper, or flipping a switch).

Dominant and Recessive Bits
^^^^^^^^^^^^^^^^^^^^^^^^^^^

CAN only requires two wires: CANH and CANL, common to all ECUs.
To transmit a "zero" bit, a CAN transceiver generates a voltage difference of 2V between CANH and CANL (**dominant bit**).
To transmit a "one" bit, a CAN transceiver does nothing (**recessive bit**), which results in a 0V voltage difference between CANH and CANL.

If two transceivers attempt to transmit simultaneously a different bit, that bit will have the value of the dominant bit, which is 0.

Flags and Other CAN Bus Fields
^^^^^^^^^^^^^^^^^^^^^^^^^^^^^^

The CAN ID and the payload are the most important fields of a CAN frame, but other fields are present:

- The Start of Frame (SOF) bit is the first bit of every CAN frame. It is used to synchronize receivers.
- The Remote Transmission Request (RTR) bit is a bit to request the transmission of a specific CAN ID. It is however not used in practice.
- The Identifier Extension Bit (IDE) bit specifies whether the identifier size is 11 bits or 29 bits.
- The Data Length Code (DLC) field specifies the size of the payload. It is a 4-bit field and can therefore range from 0 to 15, but only CAN FD supports payloads larger than 8.
- The Cyclic Redundancy Check (CRC) bits are used to verify the integrity of the frame.
- The Acknowledgment bits are used **by receivers** to signal that a CAN frame was correctly received.
- The End of Frame (EOF) and InterFrame Spacing (IFS) fields are a period of silence after Acknowledgment.

These fields sometimes have delimiters and reserved bits around them.

Bit Stuffing
^^^^^^^^^^^^

CAN frames are transmitted as a bitstream with a nominal bitrate.
To ensure that enough voltage transitions, necessary for clock synchronization, are observed on the CAN bus, CAN employs a bit stuffing mechanism:

- If a frame has five successive 0, a 1 must be inserted after the 5th bit.
- If a frame has five successive 1, a 0 must be inserted after the 5th bit.

For example, if a CAN controller wants to send the identifier 0x3E0 (0001111100000 in binary), the bitsteam of the identifier would be 00011111\ **0**\ 00000\ **1**.

Bit stuffing and destuffing are done in hardware, so unless you watch CAN voltages with a logic analyzer, you will not be aware of bit stuffing.
Bit stuffing does not apply to the fields after the CRC.

.. _can_errors:

Error Frames and Bus Off
^^^^^^^^^^^^^^^^^^^^^^^^

If something is wrong with a CAN frame (wrong bit stuffing, wrong CRC, etc...), that problem will be detected by ECUs on the bus.

The default behavior of ECUs is to assume "I am correct and the CAN bus is wrong" and destroy the current CAN frame for everyone ("Error active").
Concretely, if an ECU detects an error, it immediately signals it by transmitting an Error Frame, which consists of six consecutive dominant bits (zeroes).
Because these bits are dominant, they necessarily overwrite whatever transmission is ongoing, and because six successive zeroes are a violation of bit stuffing, it ensures that all other ECUs (that may not be aware of the error) also detect an error.

ECUs have internal counters that they increase when they detect errors, and decrease when they detect a valid frame.
If these counters reach a certain threshold, they start to assume "I may be the cause of CAN errors" and stop destroying frames with active Error Frames (they become "Error passive").

If errors continue, the ECU will consider that it should enter the "bus off" state, and disconnect from the CAN bus.
You will encounter bus off problems if you set the wrong baudrate for your CAN receiver.

Follow `this link <https://www.csselectronics.com/pages/can-bus-errors-intro-tutorial>`_ to learn more about CAN Errors. Errors defined by the CAN protocol are:

- **Bit Error**: (transmitter only) an ECU attempted to transmit a bit, but a different bit was observed on the bus.
- **Stuff Error**: bit stuffing was not done correctly.
- **CRC Error**: CRC did not match the expected value.
- **Form Error**: a fixed bit did not have the expected value (e.g., ECU observed a zero for the first EOF bit, but that bit is always supposed to be a one).
- **Acknowledgment error**: (transmitter only) the ACK bit was not observed as dominant (nobody acknowledged). See the section below for details.

Similar to Error Frames are **Overload Frames**. They have the same form as Error Frames, however they do not increment the error counters.
They can only be sent during the transmission of the IFS field (the "intermission"), either because an ECU wants extra time to process a frame, or because an ECU detected a violation of the intermission by another ECU.

.. warning::

	By default, RAMN ECUs have the "auto-retransmission" CAN setting enabled. This means that the ECUs will be very quick to enter bus off mode in case of problem (e.g., short-circuit) as they will reattempt transmission immediately after an error and quickly reach counter limits.
	You can change this behavior by changing ``hfdcan1.Init.AutoRetransmission = ENABLE;`` to ``hfdcan1.Init.AutoRetransmission = DISABLE;`` (in ``main.c``) and recompile the firmware.
	Alternatively, you can use the ``AUTO_RECOVER_BUSOFF`` config flag to automatically recover from bus off events.

Acknowledgment
^^^^^^^^^^^^^^

CAN frames have an "ACK" bit, which is always dominant, and which must be transmitted by all **receivers** to confirm that they received the frame correctly.
It is important to note that this bit (and this bit only) is **transmitted by receivers (plural)**, not the transmitter of the frame.

The ACK bit must always be sent by receivers, even if they have filters activated and they do not care about the frame that they just received.

Some CAN controller have a listen-only mode, which typically will not acknowledge frames.
A consequence of the acknowledgement mechanism is that a CAN bus must always have **at least two active ECUs**.

.. _can_filters:

CAN Filters
^^^^^^^^^^^

Because the CAN protocol only allows broadcasting frames, ECUs are overloaded with messages that they do not need.
As a result, CAN controllers often have many options to set up various CAN filters, to only receive message with identifiers that they care about.

Modern microcontrollers accept various filter types, but traditionally a filter is defined with a **value** and a **mask**.
Tools such as candump accept filters in the format "<value>:<mask>".
The **mask** indicates which bits of the identifier you care about (1 means you care, 0 means you do not), and the **value** indicates what those bits should be (either 0 or 1).

Let us consider the case of an acceptance filter for standard identifiers, which are 11 bits long.
Both the mask and value are the same length as the identifiers.

A mask of 0x7FF would be 11111111111 in binary, and would indicate that you care about **all the bits** in the identifier.
As a result, the CAN filter will only accept messages for which the identifier is exactly the same as the value.
For example, filter "1BB:7FF" used with candump will only display CAN messages with ID 0x1BB.

.. code-block:: text

    value: 00110111011 (0x1BB)
    mask:  11111111111 (0x7FF)
    ---------------------
    ID:    00110111011 (0x1BB only)

A mask of 0x000 would be 00000000000 in binary, and would indicate that you care about **none of the bits** in the identifier.
This means that the CAN filter will accept every identifier (CAN controllers may require different filters for extended and standard identifiers, so you may still be rejecting extended identifiers).

if you start candump with the filter "1BB:000", it will display all IDs - the 1BB does not have any impact here, because the mask says that no bit matters.
This mask is identical to "000:000" and "FFF:000".

.. code-block:: text

    value: 00110111011 (0x1BB)
    mask:  00000000000 (0x000)
    ---------------------
    ID:    ??????????? (any)

Masks do not have to be either 0x000 or 0x7FF, you can use them to specify more advanced conditions.

For example, you can use 001:001 (care about only the last bit, which should be 1) to only show odd identifiers, or 000:001 (care about only the last bit, which should be 0) to only show even identifiers.

.. code-block:: text

    value: 00000000001 (0x001)
    mask:  00000000001 (0x001)
    ---------------------
    ID:    ??????????1 (any value ending with 1)

.. code-block:: text

    value: 00000000000 (0x000)
    mask:  00000000001 (0x001)
    ---------------------
    ID:    ??????????0 (any value ending with 0)

To specify a range, you can use a mask that starts with 1s and ends with 0s. One common filter that you will want to remember is 7e0:7F0.
This filter indicates that you want to display can IDs ranging from 0x7e0 to 0x7ef, which correspond to UDS diagnostic messages in RAMN.

.. code-block:: text

    value: 11111100000 (0x7e0)
    mask:  11111110000 (0x7f0)
    ---------------------
    ID:    1111110???? (any byte from 11111100000 to 11111101111, i.e., 0x7e0 to 0x7ef)

.. _bit_timings:

Bit Timings
^^^^^^^^^^^

A CAN bus has a single, fixed nominal baudrate, which is often 500 kbps in modern vehicles.
Most CAN tools will allow you to specify the baudrate of the CAN bus immediately, but others may ask you for concrete bit timings.

Theory
""""""

The CAN protocol divides a single bit into several **time quanta**.
A **time quantum** corresponds to the **period of the clock of the CAN controller**.
RAMN's CAN controllers use a clock of 40 MHz, therefore the associated time quantum is 25 ns.

CAN controllers consider that a **bit** is the sum of **four segments**, each made of several time quanta:

- The Synchronization Segment.
- The Propagation Segment.
- The Phase Buffer Segment 1.
- The Phase Buffer Segment 2.

ECUs all rely on different clocks, which are imperfect and slightly desynchronized.
CAN controllers can adjust the length of a CAN frame bit by adjusting the length of Phase Buffer Segment 1 and Phase Buffer Segment 2 dynamically.
The Synchronization Jump Width (SJW) parameters specify how wide these adjustments can be.

The sample point corresponds to the end of phase buffer segment 1 and the start of phase buffer segment 2.
It is the point in time where the CAN signal voltage is physically observed by the CAN receiver.
If it is too early, you risk reading the voltage before it has stabilized (e.g., because of `ringing <https://en.wikipedia.org/wiki/Ringing_(signal)>`_).
If it is too late, you risk reading the next bit.
The sample point is typically recommended to be between 75% and 90%.

Practice
""""""""

The synchronization segment is always one time quantum long.
In practice, the propagation segment and phase Buffer Segment 1 are often merged into a single segment.
Therefore, STM32 CAN controllers (and any CAN controller in general) will ask you for two values that decide the baudrate:

- TSEG1: size of the propagation segment + phase buffer 1 segment.
- TSEG2: size of the phase buffer 2 segment.

You need to select TSEG1 and TSEG2 so that:

.. math::

    Multiplier = 1 + T_{SEG1} + T_{SEG2}

where multiplier is the ratio between your CAN bit time and your CAN controller time quantum.

For example, if your CAN controller has a clock of 40 MHz (time quantum of 25 nanoseconds) and you want a CAN baudrate of 500 kbps (bit time of 2 microseconds),
your multiplier is:

.. math::

    Multiplier = {\frac{40000000 Hz}{500000 Hz} = \frac{2 \mu s}{25 ns} = 80}

Therefore, you can select any TSEG1 and TSEG2 as long as:

.. math::

     {T_{SEG1} + T_{SEG2} = Multiplier - 1 = 79}

RAMN uses TSEG1 = 60 and TSEG2 = 19. The sample point is therefore located at 76% (60 + 1 divided by 80).
However, it could use other pairs, e.g., TSEG1 = 69 and TSEG2 = 10, and it would still have the exact same baudrate.

For the SJW value, start with the lowest value and increase it if you encounter CAN errors.

.. _can_fd:

CAN FD
^^^^^^

`Controller Area Network with Flexible Data-Rate (CAN FD) <https://en.wikipedia.org/wiki/CAN_FD>`_ is a recent evolution of CAN that allows for higher bandwidths.
RAMN is compatible with CAN FD. This section summarizes the minimum you should know when using CAN FD instead of CAN.

Although CAN FD controllers understand and can transmit classic CAN frames, **classic CAN controllers do not understand CAN FD frames and will therefore destroy them**.
If you want to transmit a CAN FD frame, you need to ensure that all ECUs on the bus are compatible with CAN FD (which is the case for RAMN by default).

CAN FD allows for a maximum payload of 64 bytes. The DLC field size (4 bits) is unchanged, and DLCs above 8 represent specific sizes:

- DLC of 9 means the payload size is 12.
- DLC of 10 means the payload size is 16.
- DLC of 11 means the payload size is 20.
- DLC of 12 means the payload size is 24.
- DLC of 13 means the payload size is 32.
- DLC of 14 means the payload size is 48.
- DLC of 15 means the payload size is 64.

CAN FD introduces "bit rate switching": CAN controllers can increase the baudrate (i.e., shorten the bit time) when transmitting data.
Bit rate switching happens when the Bit Rate Switch (BRS) flag is set.
Therefore, CAN FD controllers will ask for two different sets of bit timings: "Nominal" and "Data".

CAN FD adds an "Error State Indicator" bit flag in CAN FD frames, which is used to specify whether the transmitter of the frame is currently in active or passive error mode (see :ref:`can_errors`).

There is no RTR flag in CAN FD.

There are actually `two versions of CAN FD <https://can-newsletter.org/engineering/standardization/141209_iso-can-fd-or-non-iso-can-fd>`_: "ISO CAN FD" and "non-ISO CAN FD", non compatible to each other due to small protocol differences.

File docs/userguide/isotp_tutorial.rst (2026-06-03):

.. _interacting_isotp:

Interacting with ISO-TP
=======================

As explained in :ref:`interacting_with_CAN`, ECUs often offer diagnostic features over CAN, following the requirements of several standard documents:

- `Unified Diagnostic Services (UDS) <https://en.wikipedia.org/wiki/Unified_Diagnostic_Services>`_
- `Keyword Protocol 2000 (KWP2000) <https://en.wikipedia.org/wiki/Keyword_Protocol_2000>`_
- `Universal Measurement and Calibration Protocol (XCP) <https://en.wikipedia.org/wiki/XCP_(protocol)>`_

Diagnostics involve large data transfers between a client (the diagnostic tool) and a server (the ECU), e.g., to send a new firmware file to an ECU.
CAN frames can only hold a payload up to 8 bytes (64 bytes for CAN FD), therefore it is preferable to use a transport layer to enable the transfer of larger payloads.
`ISO-TP (ISO 15765-2) <https://en.wikipedia.org/wiki/ISO_15765-2>`_ (sometimes referred to as CAN-TP) is a transport layer designed to facilitate such transfers.

ISO-TP Basics
-------------

ISO-TP (ISO 15765-2) is the transport layer used by UDS and KWP2000. It allows the transfer of payloads of up to 4095 bytes.
It works by using the first byte(s) of every CAN frame as a header, not dissimilar to how, for example, the IP protocol occupies the first bytes of an Ethernet frame.

ISO-TP is typically used to establish a one-to-one communication channel: one client and one server.
The client sends requests by sending CAN frames with a specific (static) identifier, and the server responds by sending CAN frames with another specific (static) identifier.
For example, RAMN's ECU B listens to CAN frames with the ID 0x7e1 (transmitted by a diagnostic tool) and interprets them as ISO-TP frames, and answers to them by transmitting CAN frames with the ID 0x7e9.
This is called **normal addressing**, however there are other types of addressing (See :ref:`isotp_addressing`).

ISO-TP headers use a **dynamic size** header (Protocol Control Information, PCI).
The type of header is defined by the first nibble (**the first four bits**) of the header.
There are four types of headers:

- **Single Frame [SF, first byte is 0X]**: this is a one-byte header for ISO-TP payloads that are 7 bytes or less.
- **First Frame [FF, first byte is 1X]**: this is a two-byte header that **starts** the transmission of ISO-TP payloads that are 8 bytes or more.
- **Consecutive Frame [CF, first byte is 2X]**: this is a one-byte header that **continues** a transmission started by a "First Frame" header.
- **Flow Control Frame [FC, first byte is 3X]**: this is a three-byte header used by the **receiver** to control the speed of the ISO-TP transfer.

Although ISO-TP features a flow control mechanism, it does not include an "acknowledgment" mechanism to confirm that a frame was reconstructed correctly.
CAN frames representing ISO-TP data may be padded with arbitrary values (common padding values include 0xCC, 0xAA, and 0x00) so that they are always 8-byte long.

Single Frame
""""""""""""

Single Frames (header format "0X") are simple ISO-TP frames: their header indicates that the entirety of the ISO-TP payload is contained within the CAN frame, after the header.
This implies that the ISO-TP frame is 7 bytes or less, otherwise the payload and its one-byte header would not fit in a single CAN frame.

The value of the second nibble represents the length of the ISO-TP payload.
For example, "01" represents an ISO-TP payload of one byte, and "05" represents an ISO-TP payload of five bytes.

With Single Frames, there is no need for flow control, so the Single Frame represents the whole ISO-TP transfer.
As an example, if a diagnostic tool wants to transmit the ISO-TP payload "00 11 22 33 44" (5 bytes) to ECU B, it would send the following CAN frame:

.. parsed-literal::

    ID: 0x7e1  DLC: 6  Payload: **05** 00 11 22 33 44

Note that the ISO-TP payload size is **5 bytes**, but the associated CAN frame is **6 bytes**, because one byte of the CAN frame is used as a header.

First Frame and Consecutive Frame
"""""""""""""""""""""""""""""""""

First Frames (header format "1XXX") and Consecutive Frames (header format "2X") are used together to transfer payloads larger than 7 bytes.
The First Frame specifies the length of the ISO-TP payload, and **includes the first 6 bytes** of that payload.
The second nibble of the first byte, concatenated with the second byte of the header, represents the length of the payload.
For example, a header of "10 09" represents an ISO-TP frame of nine bytes, and "1F FF" represents an ISO-TP frame of 0xFFF (4095) bytes.

Consecutive Frames contain the rest of that payload.
The second nibble of the header byte is an index to ensure that the payload can be reconstructed in order.

As an example, if a diagnostic tool wants to transmit the ISO-TP payload "00 11 22 33 44 55 66 77 88 99 AA BB CC DD" (14 bytes) to ECU B, it would send the following CAN frames:

.. parsed-literal::

    ID: 0x7e1  DLC: 8  Payload: **10 0E** 00 11 22 33 44 55
    ID: 0x7e1  DLC: 8  Payload: **21** 66 77 88 99 AA BB CC
    ID: 0x7e1  DLC: 2  Payload: **22** DD

Note that this represents the entirety of what is sent by the diagnostic tool, but for frames larger than 7 bytes, the diagnostic tool actually  **must wait for Flow Control Frames**, described below.

Flow Control Frame
""""""""""""""""""

Flow Control Frames (header format "3XYYZZ") are sent by the ISO-TP **receiver** to control the speed of transfer. Because they are sent by the receiver, they are transmitted on a different CAN ID than other frames.
A Flow Control Frame will at least always be found as an answer to a "First Frame".

A Flow Control frame has the format "3X YY ZZ", containing the following parameters:

- **Flag [X, 4 bits]**: This contains actual flow control data. 1 is for "Continue", 2 is for "Wait", and 3 is for "Abort".
- **Block Size [YY, 8 bits]**: This specifies how many frames the client should send before waiting for another Flow Control Frame. 0 means "send everything without waiting".
- **Separation Time minimum (STmin) [ZZ, 8 bits]**: this specifies how long the client should wait between frame transmissions. 0 means "send as fast as possible", values between 1 to 127 specify a delay in milliseconds. 0xF1 to 0xF9 are used to specify large delays between 100 and 900 milliseconds. Values in between are reserved by the standard.

Modern ECUs will often answer to a "First Frame" with "30 00 00", which means "send everything at maximum speed" - in that case, this would be the only Flow Control frame in the exchange.

If the ECU answered "30 00 F9" instead, the client would also send all frames without waiting for a Flow Control Frame, but it would wait 900 milliseconds between each frame.

If the ECU answered "30 01 00", the client would send the first "Consecutive Frame" and wait for another Flow Control Frame before proceeding.

Examples
""""""""

Below is an example of a full ISO-TP transfer:

.. parsed-literal::
    ID: 0x7e1  DLC: 8  Payload: **10 0E** 00 11 22 33 44 55 ("I want to send a 14-byte payload, here are the first bytes")
    ID: **0x7e9**  DLC: 3  Payload: **30 00 00** ("Send the rest without waiting, at maximum speed")
    ID: 0x7e1  DLC: 8  Payload: **21** 66 77 88 99 AA BB CC ("Here is the second part")
    ID: 0x7e1  DLC: 2  Payload: **22** DD ("Here is the third part")

Note that there is no acknowledgment at the end.
If the ECU used a Block Size different from zero, the same data exchange would be as below.

.. parsed-literal::
    ID: 0x7e1  DLC: 8  Payload: **10 0E** 00 11 22 33 44 55 ("I want to send a 14-byte payload, here are the first bytes")
    ID: **0x7e9**  DLC: 3  Payload: **30 01 00** ("Send one CAN frame and wait")
    ID: 0x7e1  DLC: 8  Payload: **21** 66 77 88 99 AA BB CC ("Here is the second part")
    ID: **0x7e9**  DLC: 3  Payload: **30 01 00** ("Send one CAN frame and wait")
    ID: 0x7e1  DLC: 2  Payload: **22** DD ("Here is the third part")

ISO-TP on Linux
---------------

The package can-utils proposes `various tools <https://github.com/linux-can/can-utils/blob/master/README.md>`_ to interact with ISO-TP.
There are three commands that you will probably want to use: **isotpsend** to send ISO-TP frames, **isotprecv** to receive ISO-TP frames, and **isotpdump** to dump and interpret ISO-TP traffic.
In addition, you can still use the basic commands introduced in the previous guide (See :ref:`interacting_with_CAN`).

UDS commands are presented in detail in another section.
This section will mostly use the basic UDS command "3E 00", which should be answered by an ECU with "7E 00". We will send it to ECU B, which uses the ID 0x7e1 to receive commands and ID 0x7e9 to answer them.
Any other random commands, likely invalid, should be answered by "7F <first byte you sent> <error code byte>" to indicate an error with your command.

candump
"""""""

When experimenting with ISO-TP, you will probably want to display the raw CAN traffic.
This can be done using candump with the correct filters.
For example, if you want to display CAN frames for the ISO-TP traffic of ECU B, you should only display CAN frames with IDs 0x7e1 and ID 0x7e9:

.. code-block:: bash

    $ candump can0,7e1:7ff,7e9:7ff

If you want to display all ISO-TP frames typically found in modern vehicles, you can filter frames with an ID between 0x7e0 and 0x7f (See :ref:`can_filters`):

.. code-block:: bash

    $ candump can0,7e0:7f0

When experimenting with ISO-TP, it is recommended that you always keep a terminal with this command executed, so that you can observe CAN frames directly.

cansend
"""""""

Although it is not recommended, there is nothing preventing you to create ISO-TP header and sending CAN frames manually.
To send the ISO-TP payload "3E 00" to ECU B, you can type:

.. code-block:: bash

    $ cansend can0 7e1#023E00

On your candump terminal, you should observe two messages:

- Your request ("3E 00", transmitted by you on ID 0x7e1).
- The answer from the ECU ("7E 00", transmitted by ECU B on ID 0x7e9).



Notice that the CAN frames have a DLC (payload size) of 3, but the ISO-TP payload is 2 bytes - because the first byte of the CAN payload is used to indicate the size of the ISO-TP payload.
Notice also that your request CAN message does not specify what the answer CAN ID is - this is statically set, unlike source and destination ports in other protocols such as TCP.

If you ignore the Flow Control Frames and just hope that you get the timing right, you can also directly send fragmented frames.
For example, to send payload 00 11 22 33 44 55 66 77 (8 bytes), you can type:

.. code-block:: bash

    $ cansend can0 7e1#1008001122334455 && cansend can0 7e1#216677

And observe the answer in candump.



Although there may be error messages at the layer above ISO-TP (such as the "7F 00 31" UDS error message in the screenshot above),
**there are no error messages at the ISO-TP layer**.
If you make mistakes when formatting an ISO-TP frame, the ECU will simply not answer.
For example, the ECU does not answer to the wrongly formatted requests below, and does not report the errors.





ECUs typically have a very fast timeout for ISO-TP requests, and will close the transfer if frames are not send fast enough.
It is recommended that you do not format ISO-TP frames yourself, but use a tool such as **isotpsend** instead.

isotpsend
"""""""""

The command isotpsend allows you to send an arbitrary payload to an ISO-TP server.
As arguments, you need to provide the can interface, the source CAN ID (the one used by the client to transmit data), and the destination CAN ID (used by the server to transmit Flow Control Frames).
The payload must be provided as stdin, byte by byte. This can be done in Linux using the echo command.
For example, use the following command to send the two-byte ISO-TP payload "3E 00" to ECU B:

.. code-block:: bash

    $ echo "3E 00" | isotpsend -s 7e1 -d 7e9 can0



This is the exact same CAN traffic as the previous one with candump, except this time you do not need to add the header yourself. You do however need to provide the destination ID because isotpsend waits for Flow Control Frames.

.. note::
    Note that the "source" corresponds to the ID that the target ECU listens to - which may feel a bit counterintuitive to some. The analogy to the TCP protocol's "source" and "destination" is limited: for ISO-TP, "source" and "destination" IDs are a static pair.
    If you want to talk to another ECU, you need to change **both** the source and destination.

You can send payloads of up to 4095 bytes with isotpsend without worrying about ISO-TP formatting. For example:

.. code-block:: bash

    $ echo "00 11 22 33 44 55 66 77 88 99 AA BB CC DD EE FF 00 11 22 33" | isotpsend -s 7e1 -d 7e9 can0

Should show the traffic shown in the screenshot below.



If you just want to test an ISO-TP link and do not care about the payload, you can use the -D option to ask isotpsend to generate a payload of a specific size for you.
You can also use the -f function to force the value (in ns) of the Separation Time of the client.
For example, use the following command to generate a 100-byte payload and send it with a delay of 1 s between transmissions:

.. code-block:: bash

    $ isotpsend -s 7e1 -d 7e9 -D 100 -f 1000000000 can0

You should be able to observe a slow transmission in your candump terminal.

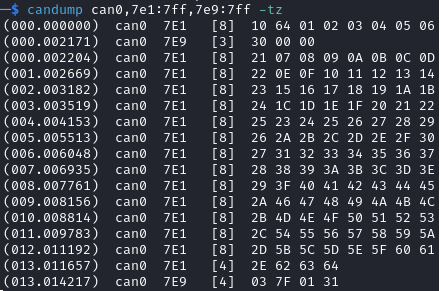
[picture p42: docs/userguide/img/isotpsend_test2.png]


isotprecv
"""""""""

The command isotpsend does not listen to answers from the server (the ECU). For this, you need to use isotprecv in another terminal with the same parameters:

.. code-block:: bash

    $ isotprecv -s 7e1 -d 7e9 can0

This will receive one payload and close, but you can use the -l option to listen to multiple ISO-TP payloads:

.. code-block:: bash

    $ isotprecv -s 7e1 -d 7e9 -l can0

If you open one of these commands in a terminal, and use isotpsend in another terminal, you should be able to see the ECU's answers to your ISO-TP payloads in the isotprecv terminal. For example, type the following command in another terminal:

.. code-block:: bash

    $ echo "3E 00" | isotpsend -s 7e1 -d 7e9 can0

and observe the isotprecv terminal, which should show the answer from the ECU.



.. warning::

    Do not switch the source and destination when using isotprecv and isotpsend - they should be using the same arguments.
    If you use ``isotprecv -s 7e9 -d 7e1 can0`` instead, you will not listen to ECU B's answers, but you will be pretending to be ECU B and be listening to the same commands as it does.
    Typically, source IDs are lower than destination IDs in real ECUs, therefore:

        - If the first parameter is lower than the second parameter, you are listening to the ECU's answers (typical usage).
        - If the second parameter is lower than the first parameter, you are pretending to be an ECU (e.g., if you want to develop an ECU simulator).

Note that the request is not displayed in isotprecv, only the answer. You can use isotpdump to display both requests and answers in the same terminal.

isotpdump
"""""""""

The command isotpdump will display both requests and answers in the same window.
Similarly to candump, it is recommended that you keep a terminal opened with it.

Use the following command to dump the traffic between you and ECU B:

.. code-block:: bash

    $ isotpdump -s 7e1 -d 7e9 -c can0

The -c option adds color to messages, to easily differentiate requests (in red) from answers (in blue).

If you type the following isotpsend command in another terminal, you should be able to observe ISO-TP traffic.

.. code-block:: bash

    $ echo "3E 00" | isotpsend -s 7e1 -d 7e9 can0



You can use the options -a to add ASCII display, and -u to interpret the payload as UDS traffic:

.. code-block:: bash

    $ isotpdump -s 7e1 -d 7e9 -c can0 -a -u



Contrary to candump, isotpdump gets rid of the header for you so you can easily identify the actual ISO-TP payload.
However, it still displays CAN frames one by one. This can be a bit overwhelming with large payloads, for example:

.. code-block:: bash

    $ isotpsend -s 7e1 -d 7e9 can0 -D 200

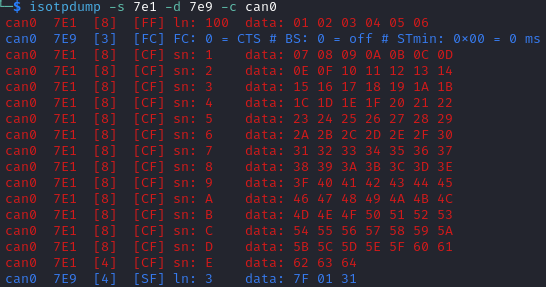
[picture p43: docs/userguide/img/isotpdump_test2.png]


isotpsniffer
""""""""""""

If you only want to see the reconstructed payload, you can use isotpsniffer instead.
You can use it with the syntax below:

.. code-block:: bash

    $ isotpsniffer -s 7e1 -d 7e9 can0 -c

which should only display the reconstructed payload, e.g., when using isotpsend with a large payload:

.. code-block:: bash

    $ isotpsend -s 7e1 -d 7e9 can0 -D 100



isotpperf
"""""""""

You can measure the performance of the ISO-TP connection using isotpperf, e.g., with ECU B:

.. code-block:: bash

    $ isotpperf -s 7e1 -d 7e9 can0

This will display ongoing transfers and measure how long they take.

You can try various transfers when forcing the STmin value locally with the -f option. Open another window and type the following commands to send payloads with the maximum size and different timings:

.. code-block:: bash

    $ isotpsend -s 7e1 -d 7e9 can0 -f 100000 -D 4095
    $ isotpsend -s 7e1 -d 7e9 can0 -f 1000000 -D 4095
    $ isotpsend -s 7e1 -d 7e9 can0 -f 10000000 -D 4095



isotpserver
"""""""""""

If you want to access an ECU's ISO-TP server over an IP network, you can use isotpserver.
For example, if you want to forward ISO-TP traffic from ECU B (ISO-TP pair 0x7e1/0x7e9) to IP port 7777, you can use the following command:

.. code-block:: bash

    $ isotpserver -s 7e1 -d 7e9 -l 7777 can0

.. warning::
    This command lets anyone who can access your IP server communicate with ECU B. Only use this if you know what you are doing.

You can connect to this port using for example netcat:

.. code-block:: bash

    $ nc localhost 7777

You can send ISO-TP frames as ASCII embedded in <>, for example if you type "<3E00>" and press ENTER, you should receive "<7E00>" in the same terminal.



This command can be useful to share one ECU remotely with multiple people.
However, note that ISO-TP answers (and answers only) will be broadcast to all clients.
You can also use the **isotptun** command to create an IP over ISO-TP tunnel.

(Slightly) Advanced ISO-TP concepts
-----------------------------------

Physical and Functional Addressing
""""""""""""""""""""""""""""""""""

There are two types of addressing:

- Physical Addressing
- Functional Addressing

In Normal addressing, a diagnostic tool only talks to one ECU at a time.

In Functional addressing, a diagnostic tool can talk to a group of ECUs simultaneously.
It is only supported for Single Frames, which do not require flow control and can therefore easily be received by several receivers at once.
A functional address often used by ECUs is 0x7DF, as defined by `OBD-II PIDs <https://en.wikipedia.org/wiki/OBD-II_PIDs>`_.

.. _isotp_addressing:

Addressing
""""""""""

There are different types of addressing defined in ISO-TP:

- **Normal Addressing**: the address IDs are fully contained in the CAN Identifier (e.g., 0x7e1 and 0x7e9 for ECU B). It works with both standard (11-bit) and extended (29-bit) CAN identifiers.
- **Normal Fixed Addressing**: this is a subformat of normal addressing, only for 29-bit extended identifiers, where addresses must follow the `J1939 format <https://www.csselectronics.com/pages/j1939-explained-simple-intro-tutorial>`_.
- **Extended Addressing**: The first byte of the CAN payload is used as an additional address byte. This means that the header size becomes two bytes for Single Frames and Consecutive Frames, three for First Frames, and four for Flow Control Frames.
- **Mixed Addressing**: a mix of normal fixed addressing and extended addressing.

CAN FD
""""""

The newer version of ISO-TP makes use of the extra bandwidth provided by CAN FD (See :ref:`can_fd`).
Concretely:

- Single Frames can hold a payload of up to 62 bytes. To use this, the first byte of the CAN frame should be "00", and the following byte should indicate the ISO-TP payload size (up to 62 bytes, because the first two bytes are occupied by the header).
- Fragmented frames (First Frames + Consecutive Frames) can hold a payload of up to 4 Gigabytes in size. To use this, the first two bytes should be "1000", and the four following bytes should indicate the ISO-TP payload size.

Troubleshooting
"""""""""""""""

If you encounter timeout issues (error messages such as "read socket t: Connection timed out"), it indicates that the connection is unreliable, i.e., either that:

- ECU A (your USB to CAN adapter) is not fast enough to transfer data from USB to CAN.
- Your PC is not sending the correct data over USB.

If ECU A is the problem, it should display an error message on its screen.

If you are using a virtual machine, its USB settings may not be reliable enough.
In VirtualBox, go to Settings -> USB and check "USB 3.0 (xHCI) Controller" (make sure your virtual machine is shut down).

If it still fails, try using the -f option with isotpsend to force it to slow down, e.g., with "-f 100000".

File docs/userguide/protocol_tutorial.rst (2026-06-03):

.. _protocol_tutorial:

The CAN Protocol in Depth
=========================

.. warning::

	This section is still a work in progress. Please make sure you have the latest RAMN firmware from Github, and contact us if you notice issues.

Introduction
------------

Up to this point, we have treated the CAN protocol as a transparent layer: we can "magically" exchange messages between ECUs using tools such as *cansend* and *candump*.
In this tutorial, we experiment with the CAN protocol at the physical level, and interact directly with the bitstream of the CAN bus.

If you have not already, you should read the :ref:`advanced_can` section (although you may skip the "CAN filters" and "bit timings" part).

Quick Practical Refresher
^^^^^^^^^^^^^^^^^^^^^^^^^

Below is a quick (slightly simplified) refresher about the CAN bus that may help you understand this tutorial.

- CAN Frames are `NRZ bitstreams <https://en.wikipedia.org/wiki/Non-return-to-zero>`_ (simple streams of 0s and 1s) with a common nominal baud rate (typically 500kbps).
- Check Wikipedia for the  `standard CAN frame format <https://en.wikipedia.org/wiki/CAN_bus#Base_frame_format>`_ and `extended CAN frame format <http://en.wikipedia.org/wiki/CAN_bus#Extended_frame_format>`_. Valid frames start with one 0 (SOF) and end with eleven 1s (ACK delimiter, EOF, IFS).
- **Dominant/Recessive**: A 0 bit is *dominant* and a 1 bit is *recessive*. If several ECUs simultaneously transmit a bit, the resulting bit is 0 if any ECU transmits 0, and 1 only if all ECUs transmit 1.
- **Bit stuffing**: To help synchronize clocks, from the SOF bit to CRC0 bit (included), if there are five successive identical bits (00000 or 11111), then one bit of the opposite value is inserted after.
- **Acknowledgement**: The ACK bit of a CAN frame is set to 0 by the ECU(s) that receive the frame (**not** the one transmitting the frame).
- **Error Flag**: Six successive 0 bits (which violate bit stuffing and should always trigger an error detection) represent an *Active Error Flag*. When other ECUs detect an error, they will in turn send their own *Active Error Flag*. Depending on the error detection timing, the total "superposed" *Active Error Flag* can be any size between six and twelve 0 bits.
- **Error Frame**: The *Error Flag* above, along with an 8-bit recessive *Error Delimiter* and a 3-bit recessive *Interframe Space*, represent an *Error Frame*.
- **Overload Frame**: If an *Error Frame* is sent during the *Interframe Space* (IFS) field of a CAN frame (the very last bits), it actually represents an *Overload Frame*. It signals that an ECU needs time to process a frame and is not considered a real "error".
- **Error Active**: The normal operation mode of CAN controllers is the **Error Active** mode, where they actively transmit **Active Error Flags** to destroy and report invalid CAN frames.
- **Error Passive**: ECUs maintain both a *Receive Error Counter* (REC) and *Transmit Error Counter* (TEC), that are increased and decreased following certain rules. Above a certain number of errors, to avoid destroying CAN traffic with *Active Error Flags* by mistake, ECUs will enter **Error Passive** mode, where they only send *Passive Error Flags* (six recessive 1 bits instead of dominant 0 bits) and wait longer between transmissions. If the TEC reaches 256, the ECU disconnects itself from the bus ("**bus-off**").
- **Bus idle**: This is the condition when no CAN frame is being actively transmitted (normally, just after the IFS0 bit).   
   
The Physical Layer
^^^^^^^^^^^^^^^^^^

The block diagram of the four ECUs of RAMN and their connection to the CAN bus is shown below.
It is important to note that **All ECUs are connected to a common CAN bus** ("bus topology").

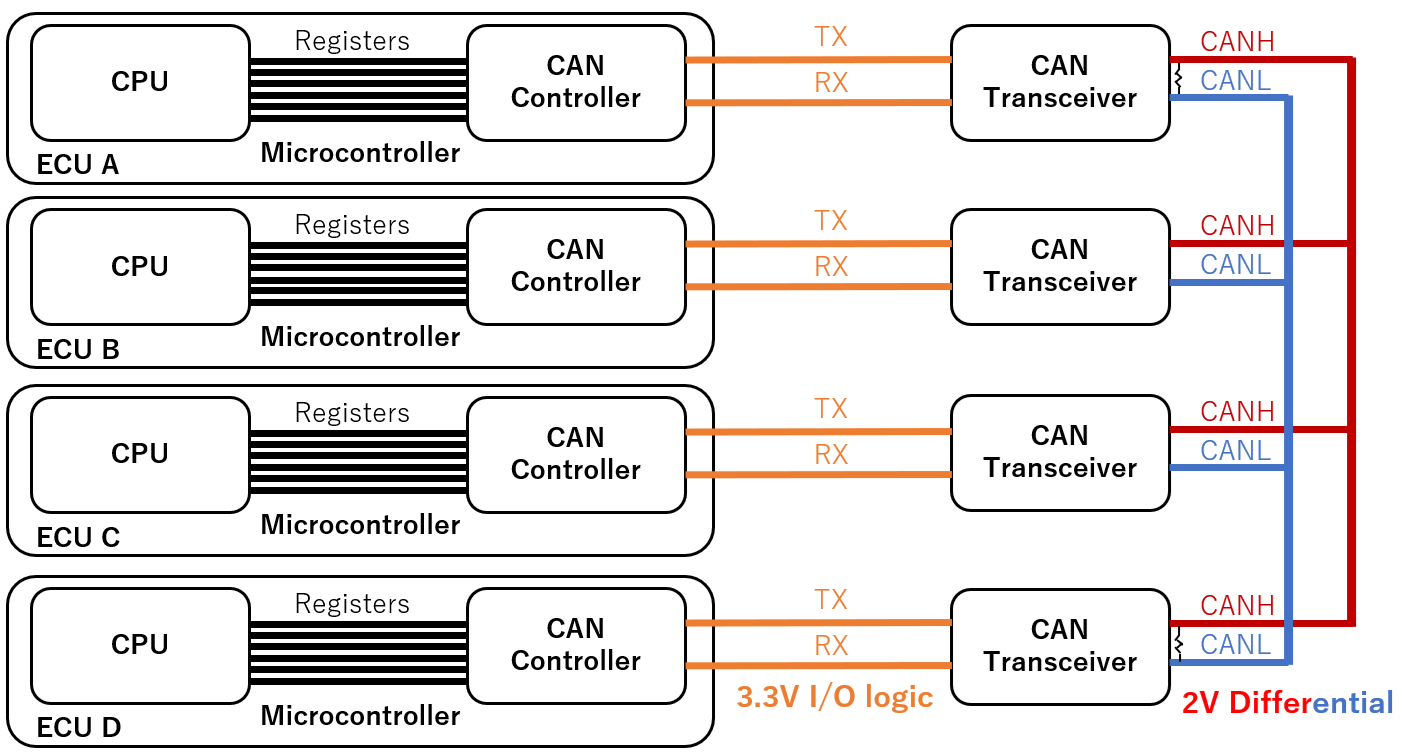
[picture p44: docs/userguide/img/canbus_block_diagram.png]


Dominant and Recessive
^^^^^^^^^^^^^^^^^^^^^^

Ultimately, the CAN bus is a simple serial bus: the bits representing a CAN frame are sent one by one according to a fixed clock (500 kbps for RAMN).
Arbitrarily, a "0" bit is represented by a "**dominant**" signal, and a "1" bit is represented by a "**recessive**" signal.

A CAN bus is a pair of wires: **CANH** (*CAN High*) and **CANL** (*CAN Low*). 

- A 2V voltage difference between **CANH** and **CANL** represent a **"dominant"** state.
- A 0V difference between **CANH** and **CANL** represent a **"recessive"** state.

This is called **differential signaling**, and its main purpose is to protect the signals from interferences: if a perturbation affects **CANH** (and results for example in a +1V voltage spike), then it is likely to also affect **CANL** (also experiencing a +1V spike), and as a result the **CANH-CANL voltage difference remains unchanged**.
The reason **CANH** and **CANL** wires are typically twisted together is to ensure this coupling physically.
Note that the "recessive" status is also the status of the bus when it is idle: a period of inactivity can technically be seen as a long streak of "1" bits.

Because all ECUs are connected to the same CAN bus, it is likely that different ECUs may attempt to transmit a different bit at the same time.
The "dominant/recessive" mechanic is here to handle those **collisions**: a dominant bit always win over a recessive bit:

- The CAN bus is only in the recessive state if **all ECUs** are sending a recessive bit.
- The CAN bus is in the dominant state if **any ECU** (one or more) is sending a dominant bit.

In other words, 0 always wins over 1 on a CAN bus.
This explains why lower arbitration IDs have a higher priority: If one ECU attempts to transmit the arbitration ID 0x000 and another ECU attempts to transmit IDx7FF, then the 0s will win and ECUs will see ID 0x000 on the CAN bus.
The ECU transmitting ID 0x7FF can detect that it lost arbitration (because the CAN bus did not match the bitstream that it was sending), but the ECU transmitting 0x000 does not even know that another ECU was also trying to transmit at the same time (assuming they are perfectly synchronous).
(Note that the ECU losing arbitration gives up at the first mismatching bit and does not attempt to transmit the other bits).

Electronic Components
^^^^^^^^^^^^^^^^^^^^^

To communicate on a CAN bus, an ECU needs at least at **CAN controller** and a **CAN transceiver**. 

The role of the CAN controller is to handle the logic of the CAN protocol: bit stuffing, arbitration, error frames, etc.
The CAN controller is however simple at the physical level: it only understands 3.3V Input/Output signals (**CAN RX** and **CAN TX**).
For the vast majority of cases\ [#f1]_, **the CAN controller is internal to the microcontroller of the ECU** (and is therefore referred to as "CAN peripheral"). You can learn more about RAMN's ECU's internal CAN controller by reading `AN5348 <https://www.st.com/resource/en/application_note/an5348-introduction-to-fdcan-peripherals-for-stm32-mcus-stmicroelectronics.pdf>`_.
Note that this CAN controller supports CAN FD, but we only consider CAN for this tutorial.

The role of the CAN transceiver is to handle the physical layer: it translates the 3.3V RX/TX signals of the CAN controller to CANH/CANL 2V-differential signals, and allow the reliable connection of many nodes on a common bus (you cannot just connect CAN TX and CAN RX pins together).
Depending on component availability, RAMN may use the `MCP2558FD <http://ww1.microchip.com/downloads/aemDocuments/documents/OTH/ProductDocuments/DataSheets/20005533A.pdf>`_ or the `ATA6561 <https://ww1.microchip.com/downloads/aemDocuments/documents/OTH/ProductDocuments/DataSheets/20005991B.pdf>`_.
At a high level, the role of the CAN transceiver is purely to ensure the reliability of the CAN bus signals\ [#f2]_. However, CAN transceivers may include some additional functions.
For example, the ATA6561 is able to enter a "standby mode" to save power during periods of bus inactivity. Modern CAN transceivers such as the `TJA115x family <https://www.nxp.com/docs/en/fact-sheet/SECURCANTRLFUS.pdf>`_ offer security features to protect from certain known attacks on the CAN bus.

.. note::

	CAN Transceivers typically feature a "dominant timeout" function: the transceiver will disconnect itself from the CAN bus if it detects that the CAN controller is asserting a dominant state for too long (~1.9ms for the MCP2558FD, up to 3ms for the ATA6561). Concretely, it means very low baud rates cannot be achieved, and the CAN controller cannot transmit absolutely anything it wants.

As a result, the life of a CAN frame is as below:

- The CPU of an ECU decides the content (arbitration ID, data, etc.) of a CAN frame.
- The CPU uses various registers to request the transmission of the CAN frame to its CAN controller.
- The CAN controller generates the bitstream of the CAN frame (including bit stuffing).
- The CAN controller monitors the status of the CAN bus using its RX pin and waits for an opportunity to transmit ("bus idle").
- The CAN controller uses its TX pin to transmit its CAN frame. It uses the RX pin simultaneously to ensure the transmission was successful, and goes back to the previous step if it was not.

During this process, the CAN transceiver does the translation between the 3.3V RX/TX signals and the differential CANH/CANL signals.

.. [#f1] On other hardware platforms, you may encounter external CAN controllers (such as the `MCP2518FD <https://ww1.microchip.com/downloads/aemDocuments/documents/OTH/ProductDocuments/DataSheets/External-CAN-FD-Controller-with-SPI-Interface-DS20006027B.pdf>`_. This may notably be the case if an ECU needs many CAN controllers.
.. [#f2] In fact, if you did not care about reliability, you could replace the CAN transceiver with `a resistor and some diodes <https://community.st.com/t5/stm32-mcus-products/on-board-communication-via-can-without-transceiver/td-p/152684>`_.

.. note:: 

	RAMN features probes to connect to CANH and CANL, and ECU D has debug traces with 'Test Points' to connect to its CAN RX and CAN TX pins. You can solder flying leads ('wires') to these test points to gain access to the logic-level signals which are perfect for a logic analyzer. You can also use an SOIC-8 'test clip' on the CAN transceiver chips to easily gain access to the same.

	Should you choose to connect a logic analyzer to CANH/CANL on your RAMN, you need to configure it properly (note that **you do not need a logic analyzer for this tutorial**, but you may want to connect one to observe the CAN bus with your own tools).
	Technically, the "common-mode" voltage of a CAN bus (the voltage of CANH/CANL relative to ground during a recessive state) is not guaranteed to be fixed, so you should use a logic analyzer with differential inputs.
	In practice, however, nothing is likely to perturb that voltage on a RAMN board, so you can consider the following:

	- CANH is 2.5V during a one, 3.5V during a zero.
	- CANL is 2.5V during a one, 1.5V during a zero.
	- CAN RX/TX are 3.3V during a one, 0V during a zero.
	- For differential inputs: CANH-CANL is 0V during a one, 2V during a zero.

	If you connect a logic analyzer with a CAN protocol decoder, make sure that your decoder has the correct definition for zero and one (since it depends on where and how you connect, you may need to invert it).
	Consult the CAN transceiver datasheets to know the variation ranges (for example, according to the datasheets, CANH/CANL difference can vary between 1.5V and 3V).

Preliminary Experiments
-----------------------

Before interacting with the 1s and the 0s of the CAN bus, we recommend that you become familiar with some useful RAMN features and some quirks of the CAN bus.
For the rest of this tutorial, we will make heavy uses of RAMN's CLI. If you have not yet, make sure that you are able to send and receive commands as explained in the :ref:`usb_tutorial` section.
You do not need to be familiar with the slcan commands, only with the :ref:`usb_cli`.

Power Supply Control
^^^^^^^^^^^^^^^^^^^^

Connect to your RAMN over USB and use the shift lever joystick to switch to the "CAN RX Monitor" screen (press joystick to the right once).
On this screen, you can see recent CAN messages for each identifier.

Open a serial terminal, configure it correctly, and use the '#' command to enter the CLI mode.
You can use the ``enable`` and ``disable`` commands to control the power supply of ECU B, C, and D.
Try to disable ECU B and observe the traffic.

.. code-block:: text

	#
	disable B
	
You should be able to observe something obvious: if you turn off the power supply of an ECU, it will stop transmitting its messages, so that arbitration IDs that it normally transmits will disappear from the CAN bus.

.. note::

	In general, you should not assume that if an arbitration ID disappears when an ECU is disconnected, then it was necessarily transmitted by that ECU: indeed, some ECUs only transmit some (periodic) messages as a response to other (periodic) messages.
	However, that is not the case for RAMN, so you can safely assume that if an arbitration ID disappears when the ECU is powered-off, then the ID is transmitted by that ECU. If you ever forget which ECU sends which arbitration IDs, simply disable/enable it and observe the difference.

Next, try to disable ECU C:

.. code-block:: text

	disable C
	
Now, try moving the shift lever joystick again, and notice that the screen will not change. Obviously again, if you disable ECU C, the sensors handled by ECU C will not work anymore.
If for some reason, ECU C enters the "bus-off" mode, then the controls will not work either, even though ECU C is powered on.
If you ever need to change screen while experimenting (e.g., because you want to move to the CAN stats screen), make sure ECU C is powered on with the enable command, and reset it if needed.

The command accepts several ECUs at once. For example, If you want to make sure only ECU D is enabled, you can use:

.. code-block:: text

	disable BC
	enable D

If you need to reset an ECU, you can use the ``reset`` command, for example:

.. code-block:: text

	reset D

Acknowledgement and Auto-Retransmission
^^^^^^^^^^^^^^^^^^^^^^^^^^^^^^^^^^^^^^^

At this stage, only ECU A and ECU D are powered on, and you should only observe IDs 0x1B8 and 0x1BB on the screen, both transmitted by ECU D.
The content of those CAN messages is constantly changing (with changing parts highlighted in white).
If you remember, a CAN bus needs to have at least one active receiver to send the **Acknowledgement (ACK)** bit of a CAN frame.
Right now, ECU B and C have been disabled, so only ECU A is able to acknowledge. What happens if we ask ECU A to stop acknowledging frames?

We cannot disable the power supply of ECU A (it is the one answering to you over USB), however, we can ask ECU A to enter a **listen-only mode** in which it does not acknowledge frames, using the ``can ack 0`` command.

.. code-block:: text

	can ack 0
	
Observe ECU D LEDs: you should observe that the **Check Engine LED is now lit**.
Observe ECU A's screen: there is **only one message** being sent (with ID 0x1B8), and its content is **not changing anymore**.
Wait for about 30 seconds, and you should observe that the LED is now blinking, and no message is visible on the CAN RX Monitor screen.

What is happening here? First, you need to understand what the Check Engine LED indicates:

- **The Check Engine LED will be lit when ECU D detects a CAN error**.
- **The Check Engine LED will blink when ECU D enters the bus-off mode** and disconnects from the CAN bus.

.. note::

	The Check Engine LED will light up if **any CAN error is detected**, and will not turn off unless you reset the ECU (with ``reset D``) or reset the CAN peripheral of ECU D (with ``resetcan D``, which only works if ECU D is not in bus-off mode).
	
	The Check Engine LED **does not represent** the value of CAN error counters (REC and TEC), which automatically go back to zero when errors do not happen.

When you prevent ECU A from acknowledging CAN frames, no ECU is left to acknowledge ECU D's CAN frames. 
As a result, ECU D encounters a CAN error when transmitting its CAN frame.
By default, **auto-retransmission** is on. As a result, ECU D is endlessly trying to send its CAN frame and is effectively **spamming** the bus with the same CAN frame, that it is waiting for someone to acknowledge.
Later in this tutorial, we will observe in detail what is happening, but for now you should be aware of this tendency to spam the bus until success when auto-retransmission is on.

There is a failsafe in RAMN to prevent the ECU from spamming the bus. As a result, ECU D ultimately disconnects itself, but note that this is not a **mandatory behavior** from CAN specifications.

Changing CAN Parameters
^^^^^^^^^^^^^^^^^^^^^^^

It is possible to change some settings of RAMN's ECU CAN controllers over UDS, using the ``uds`` command.
UDS routine control 0x0222 can be used with three 1-byte parameters to change:

- The **Bus-off auto-recovery** parameter (default:0): if set to 1, the ECU will immediately reset its CAN controller when entering bus-off mode (non-standard behavior)
- The **CAN frame auto-retransmit** parameter (default:1): if set to 0, the ECU CAN controller will not reattempt failed CAN transmissions.
- The **Transmit Pause** parameter (default:0): if set to 1, the ECU CAN controller will add a transmission delays between CAN frames (non-standard behavior).

Before you change parameters, you need to make sure that the target ECU is not in bus-off mode. You can do so by reenabling acknowledgements from ECU A and resetting ECU D:

.. code-block:: text

	can ack 1
	reset D

Then, for example, you can enable bus-off auto-recovery, disable auto-retransmission, and disable transmit pause with:

.. code-block:: text

	uds D 31010222010000

The ``010000`` here represents 01 for bus-off auto-recovery, 00 for auto-retransmission, and 00 for transmit pause.

.. warning::

	Many commands may not work properly if ECU A is in listen-only mode, so always remember to leave that mode with ``can ack 1``.

Now, try to put ECU A in silent mode with:

.. code-block:: text

	can ack 0
	
You should observe:

- That the screen freezes for about 1.6 seconds (no message is received).
- After that, message 1B8 is transmitted periodically again, but not message 1BB.

The first observation is caused by the **Error Active/Error Passive mechanism** of the CAN bus: ECU D will actively destroy 16 frames (1 per 100ms) with **Active Error Flags**, then it will enter **Error Passive mode** and stop sending **Active Error Flags**.
The STM32 CAN peripheral in listen-only mode does not care about the ACK field, so once ECU D enters **Error Passive** mode and stops sending **Active Error Flags**, ECU A starts accepting the not-ACKed CAN frames.
Note that technically ECU D is still sending **Passive Error Flags**, but from ECU A's point of view, they are indistinguishable from a regular "End of Frame (EOF)" field, which also consists of recessive bits.

The second observation is that ECU D always fails to send the 0x1BB frames, which normally always follow 0x1B8.
Why? Because STM32 CAN peripherals are **very quick to abandon transmission**:

- Transmission will be aborted if arbitration is lost (as per standard), but it will not be automatically reattempted (even though no CAN error happened).
- Transmission will be aborted if the previous frame encountered an error (and the CAN peripheral need time to process it).

As a result, you should keep in mind that **when auto-retransmission is off, you should expect some valid frames to not be transmitted** (and it can be a little counterintuitive sometimes).

.. note::

	The first observation is relevant to security: a CAN error on a CAN frame does not mean that the content of that frame cannot be read and processed by other ECUs in listen mode. 
	Although the CAN frame sent by ECU D is technically invalid (because it was not acknowledged), it is still processed by ECU A and displayed on its screen. If ECU A were not in listen mode then the atomic broadcast property of CAN would guarantee that since the frame was not acknowledged, it is not received by any node on the bus.

The "silence" and "talk" Commands
^^^^^^^^^^^^^^^^^^^^^^^^^^^^^^^^^

If you want to make an ECU stop transmitting CAN frames but still want it to acknowledge CAN frames, you can use the ``silence`` and ``talk`` commands instead of ``disable`` and ``enable`` commands.
For example:

.. code-block:: text

	silence BC
	talk D 

Will make it so that only ECU D attempts CAN transmissions, but ECU B and C are still there to acknowledge CAN frames and monitor the CAN bus (and generate Error Flags if necessary).

.. _bitbang_module:

RAMN's Bitbang Module
---------------------

What is Bitbanging
^^^^^^^^^^^^^^^^^^

In order to interact directly with the bitstream of the CAN bus with ECU A, we use a method called **bitbanging**: we reconfigure ECU A's microcontroller so that CAN TX and CAN RX become general purpose input/output pins ("GPIO").
We use timers and dedicated software loops that directly reads and write to these pins (You can check the `source code here <https://github.com/ToyotaInfoTech/RAMN/blob/main/firmware/RAMNV1/Core/Src/ramn_bitbang.c>`_).

This is illustrated in the figure below:

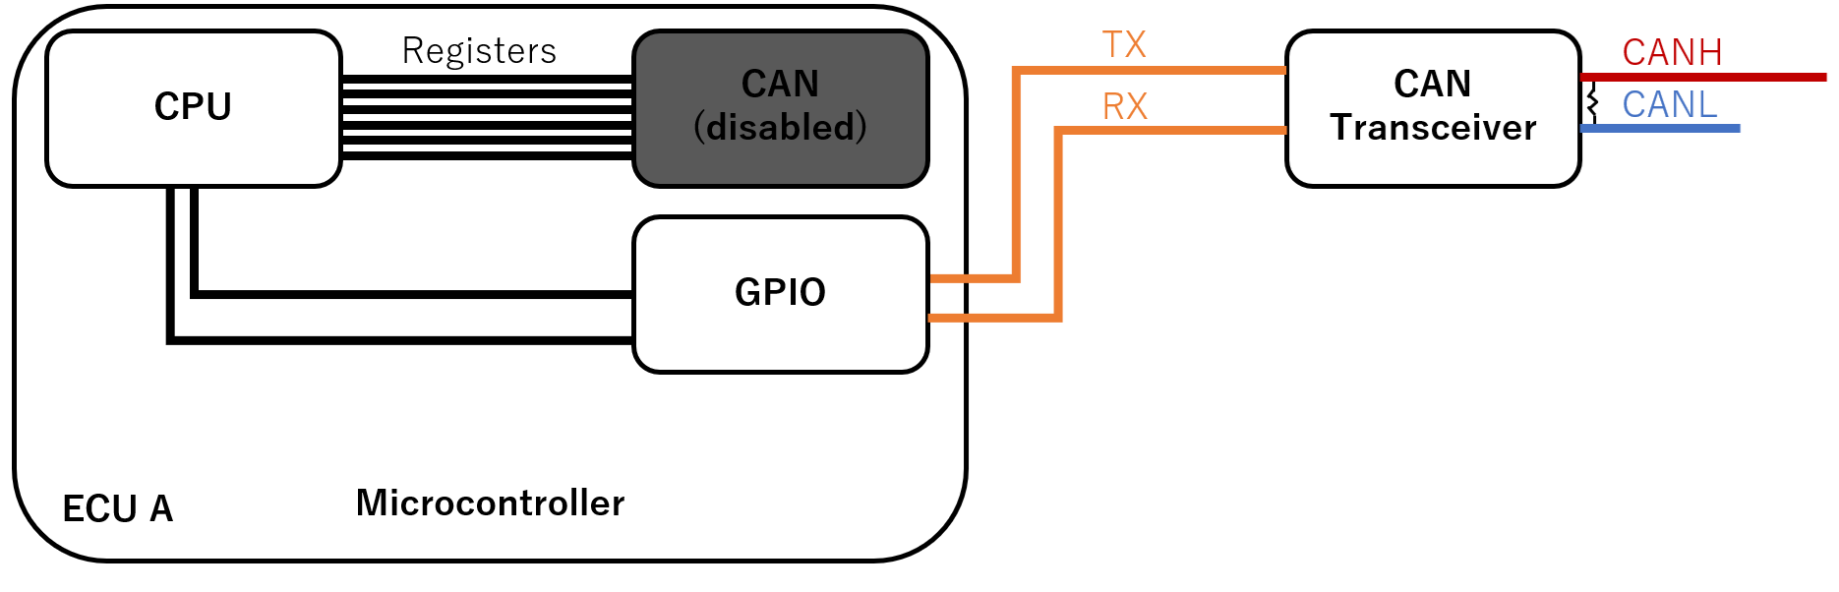
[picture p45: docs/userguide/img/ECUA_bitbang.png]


This approach has several limitations:

- The timing is not perfect: the microcontroller is doing its best but cannot be as fast and accurate as a dedicated peripheral or FPGA.
- ECU A will stop acknowledging CAN frames (unless you reprogram it to), so for most scenarios you will need to ensure that at least two ECUs are powered on.
- ECU A will stop all its normal activities (such as updating its screen) when in bitbang mode.

But this approach also yields benefits derived from the fact that the ECU A no longer has to 'follow the rules' of CAN -- as we will see.

The bitbang commands all start with ``bitbang`` (or ``bb`` as a shortcut).
Type ``bb help`` for a list of supported commands.

.. code-block:: text

	#
	bb help
	
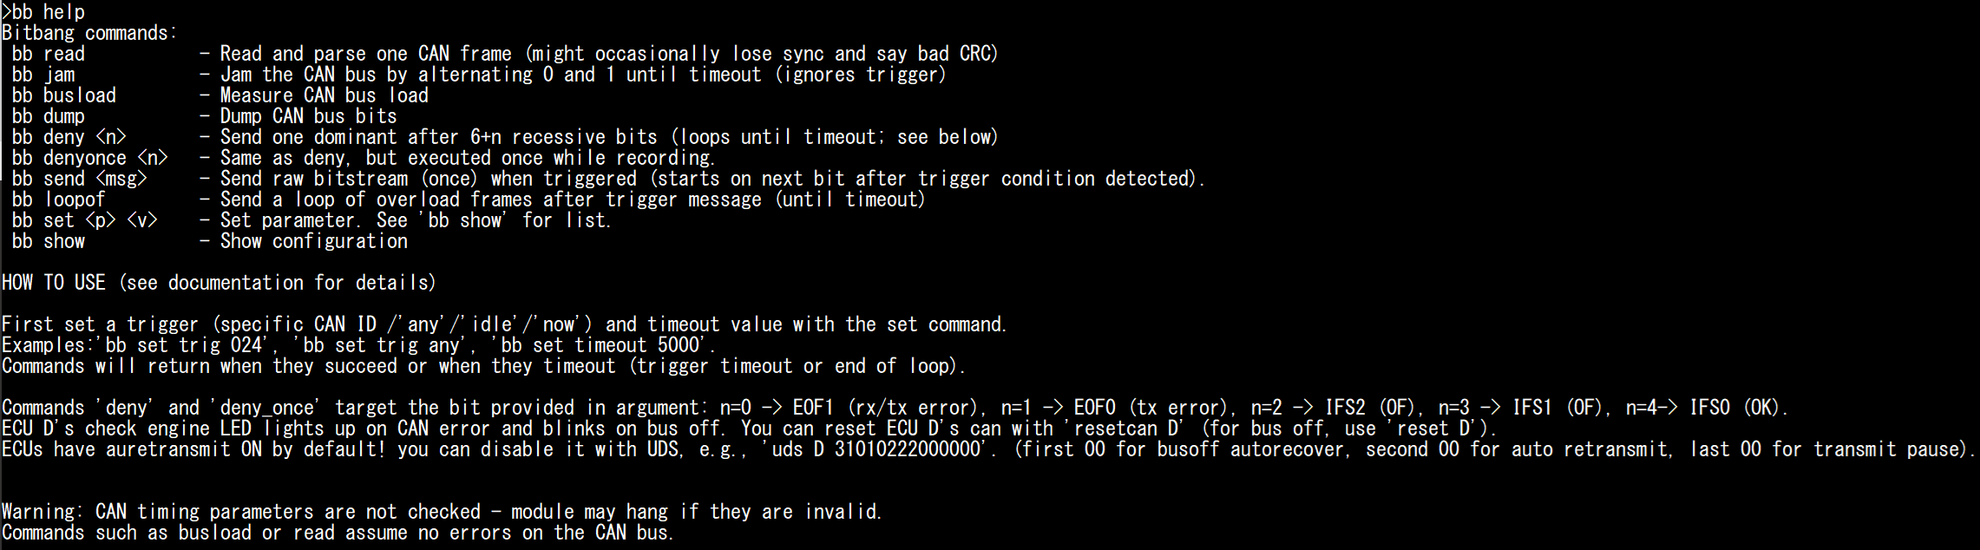
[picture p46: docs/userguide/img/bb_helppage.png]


Interpreting the Bitstream
^^^^^^^^^^^^^^^^^^^^^^^^^^

First, reset the board to make sure it is in a known state, then enter the CLI mode again:

.. code-block:: text

	#
	reset
	#

You can use the ``bb read`` (or ``bitbang read``) command to read CAN messages. By default, the module will dump and interpret the first CAN frame that it finds.
Try to read several messages:

.. code-block:: text

	bb read
	bb read

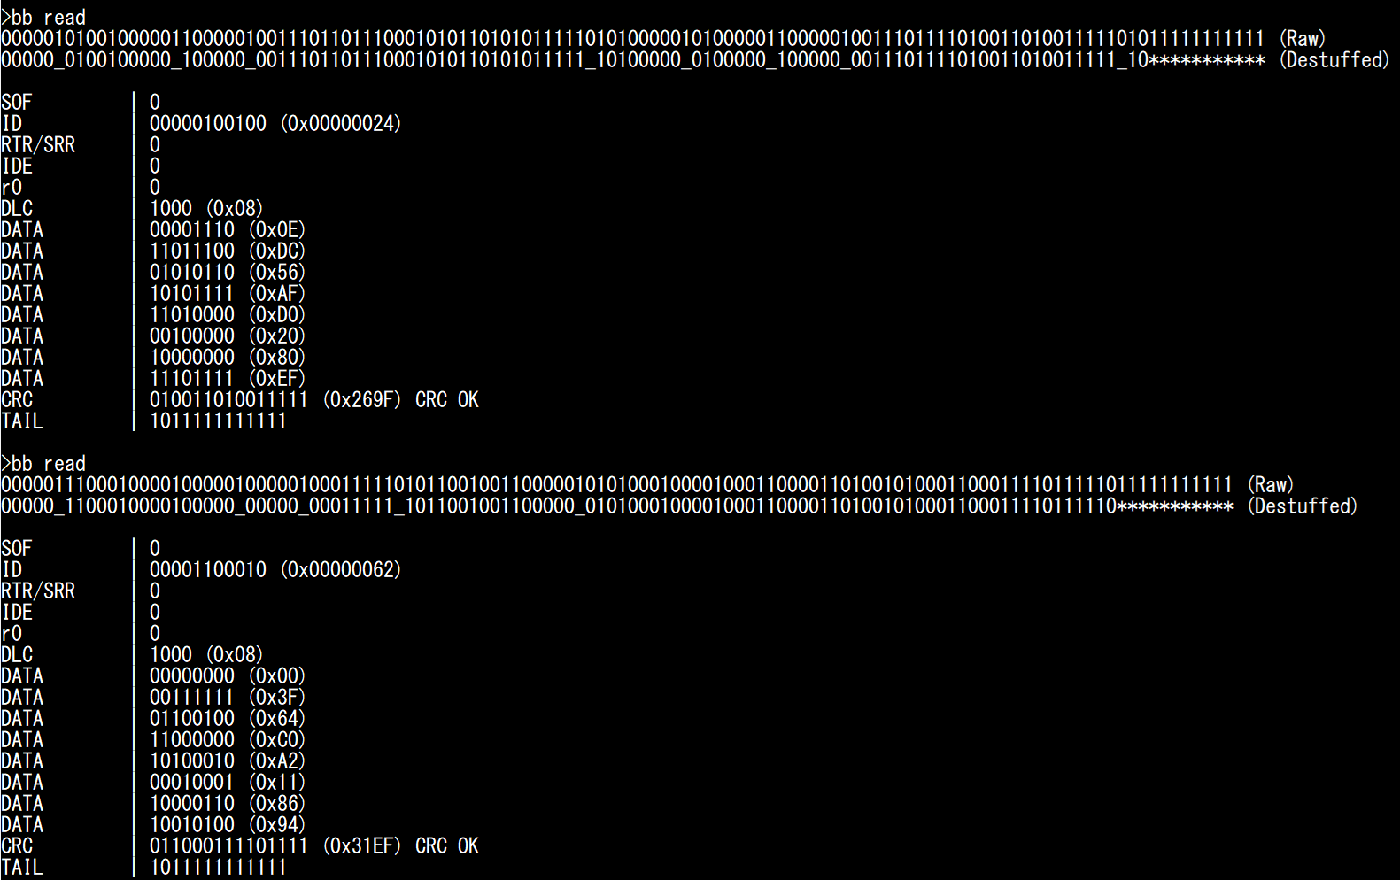
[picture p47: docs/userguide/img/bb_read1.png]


You can observe the **raw bitstream** and the same **bitstream after removing bit stuffing**: stuffed bits are replaced by "_", and the trailing "1"s (EOF and IFS) are replaced by \*.
The module also details the value of each bitfield.

The last bits (CRC Delimiter, ACK, ACK delimiter, EOF, and IFS) are merged in a single field that we call "Tail" (not a standard term).
During normal conditions, it should be equal to 1011111111111: "1" for CRC Delimiter, "0" for ACK, and "1"s for ACK delimiter, EOF and IFS.
Any other value would indicate an Acknowledgement error, CRC error, or overload condition.

.. warning::

	You might occasionally see "BAD CRC" when reading messages. This is likely a limitation of the bitbang module, not an actual CRC mistake on the CAN bus, which is extremely rare.

.. note::

	Bit stuffing is performed between the SOF and CRC0 bits. CRC0 is followed by CRC Delimiter (always "1"). You can observe where bit stuffing stops on the screenshot above:

	- For the first message, there is a 5-bit "1" streak that ends at CRC0. The CAN controller stuffed a "0" between CRC0 and CRC Delimiter.
	- For the second message, there is a 5-bit "1" streak that ends at CRC Delimiter: this is outside the bit stuffing zone and the CAN controller did **not** stuff a bit between CRC Delimiter and ACK bit. 

You can modify some bitbang module parameters.
Type ``bb show`` to see the list of possible settings.

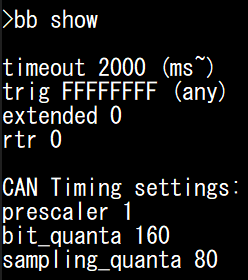
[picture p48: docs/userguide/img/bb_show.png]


You can modify these parameters using the ``bb set`` command.

If you ever need to modify the baud rate of the CAN bus, you can modify the **prescaler**, **bit_quanta**, and **sampling_quanta** settings:

- **prescaler** corresponds to the clock divider used for the bitbang module timer (80 MHz).
- **bit_quanta** corresponds to the number of clock cycles needed to achieve the desired baud rate (160 for 500kbps when **prescaler** is 1).
- **sampling_quanta** corresponds to the clock cycle where the bitbang module actually reads the CAN bus (preferably, half of **bit_quanta** to aim for the middle). Do note that this is to leave enough processing time to swap arbitrary bits; the recommended sampling point for regular operations is 87.5% and not 50%.

Although it should not be necessary, if you encounter too many issues with this module you can try compensating for small clock errors by using ``bb set bit_quanta 159`` or ``bb set bit_quanta 161``.

You can also modify the following settings:

- **trig**: the arbitration ID that will trigger the bitbang module. You can use a specific ID (e.g., "1BB"), **"any"** (any ID), **"now"** (trigger immediately), or **"idle"** (trigger when bus idle is detected).
- **extended** and **rtr**: set those to one if you are looking for frames with the IDE or RTR bit sets.
- **timeout**: when to stop the bitbang command. This may apply either to a trigger wait timeout, or to leave a bitbang commands that loops.

Try replacing the trigger and see if you can read less frequent frames such as "1BB", which you are unlikely to catch with the "any" trigger.

.. code-block:: text

	bb set trig 1bb
	bb read
	
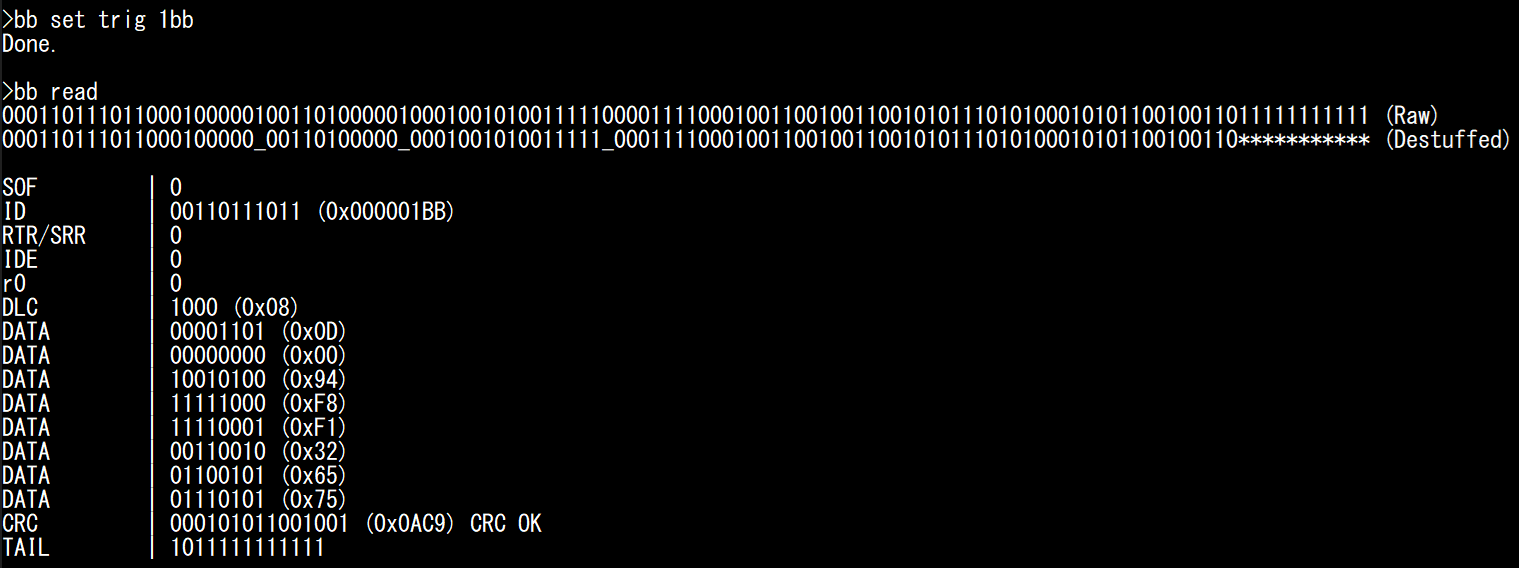
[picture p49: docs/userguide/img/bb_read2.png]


.. _saving_frames:

Saving CAN Frames to Replay Later
^^^^^^^^^^^^^^^^^^^^^^^^^^^^^^^^^

Later in this tutorial, we will want to transmit our own CAN frames, mostly to check if other ECUs received it correctly.
For this, we can use ID 0x24 (brake pedal signal): when the brake pedal is at 0%, ECU D's Stop LED should be off, and when it is at 100%, ECU D's lamp should be on.
Saving those CAN frames would therefore provide us with a convenient way to verify if a CAN message was received by ECU D or not, by replaying them and observing if the LED lights up or not.

First, make sure the Stop LED is turned off: release ECU B's handbrake and put ECU C's brake pedal at 0%. Then, set 024 as the trigger and record two bitstreams (first at 0%, then at 100%).

.. code-block:: text

	bb set trig 024
	* manually set brake to 0% *
	bb read
	* manually set brake to 100% *
	bb read
	
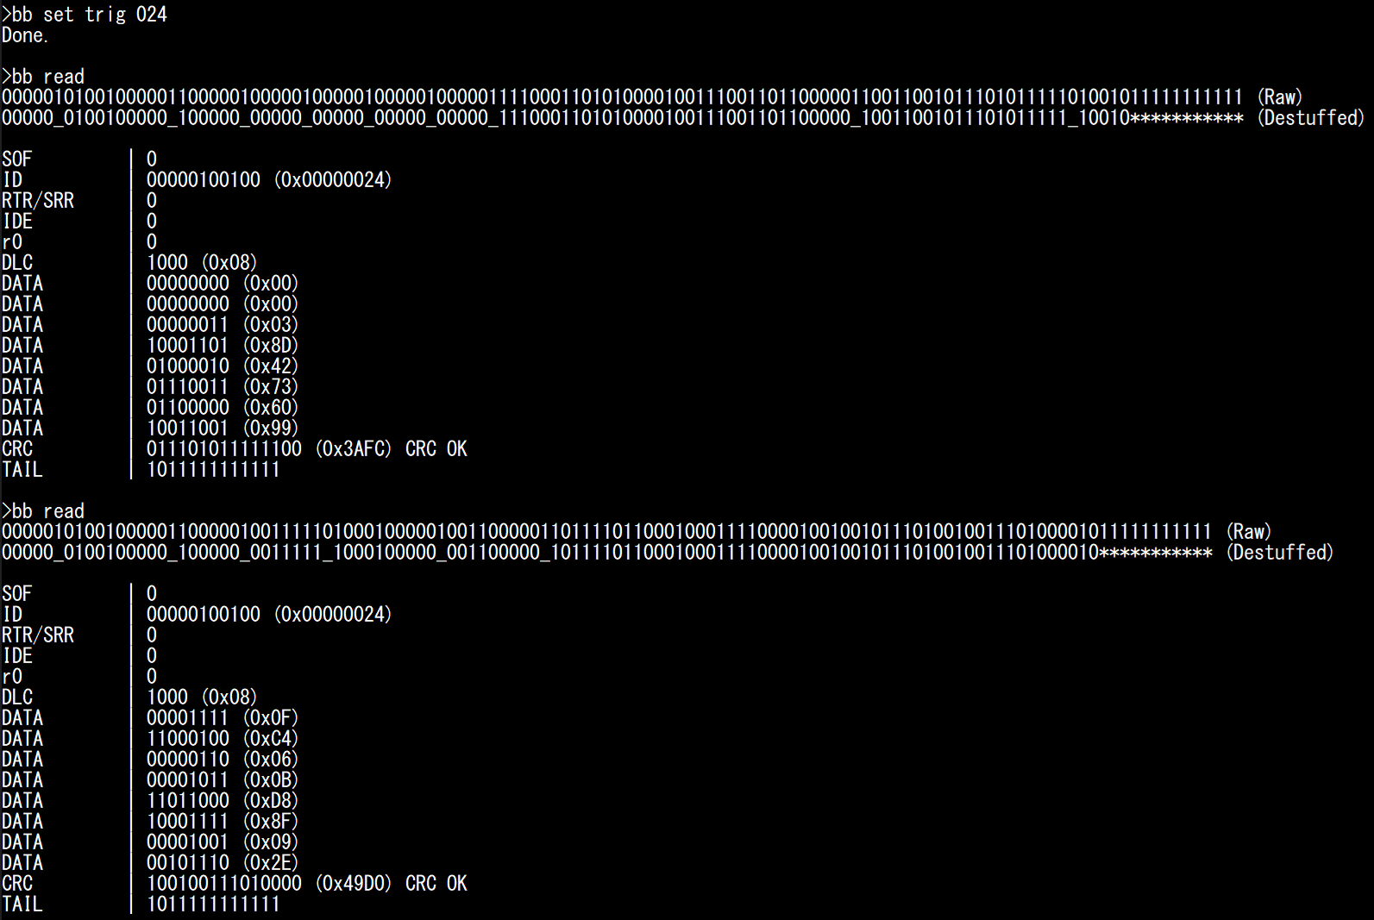
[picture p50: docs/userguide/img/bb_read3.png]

	
**Make sure you get CAN messages with correct CRC values** (It should say "CRC OK"). You should observe that the first two DATA bytes should be close to 0000 for 0%, and close to 0FFF for 100% (it is 0FC4 on the screenshot above).	

Note that, technically, it is better to replace the ACK bit (first 0 from the end) by 1, because we want other ECUs to set it to 0 themselves to confirm reception, however nobody will complain if you acknowledge your own messages.

You can use the following raw bitstreams later, to replay the brake message.

.. code-block:: text
	
	- Brake at   0%, w/ ACK: 000001010010000011000001000001000001000001000001111000110101000010011100110110000011001100101110101111101001011111111111
	- Brake at   0%: NO ACK: 000001010010000011000001000001000001000001000001111000110101000010011100110110000011001100101110101111101001111111111111
	- Brake at 100%, w/ ACK: 000001010010000011000001001111101000100000100110000011011110110001000111100001001001011101001001110100001011111111111
	- Brake at 100%: NO ACK: 000001010010000011000001001111101000100000100110000011011110110001000111100001001001011101001001110100001111111111111 

The Shape of the Traffic
^^^^^^^^^^^^^^^^^^^^^^^^

Now that you know what individual CAN frames look like, it is time to see how these fit into a common CAN bus.

You can use the ``bb dump`` command to dump the CAN bitstream, without trying to interpret it.
You can use any trigger you want, but we recommend use the "now" trigger to start dumping as soon as possible, which should be a random timing.

Reset the board and try the ``bb dump`` command (with the "now" trigger) several times.

.. code-block:: text

	reset
	#
	bb set trig now
	bb dump
	bb dump

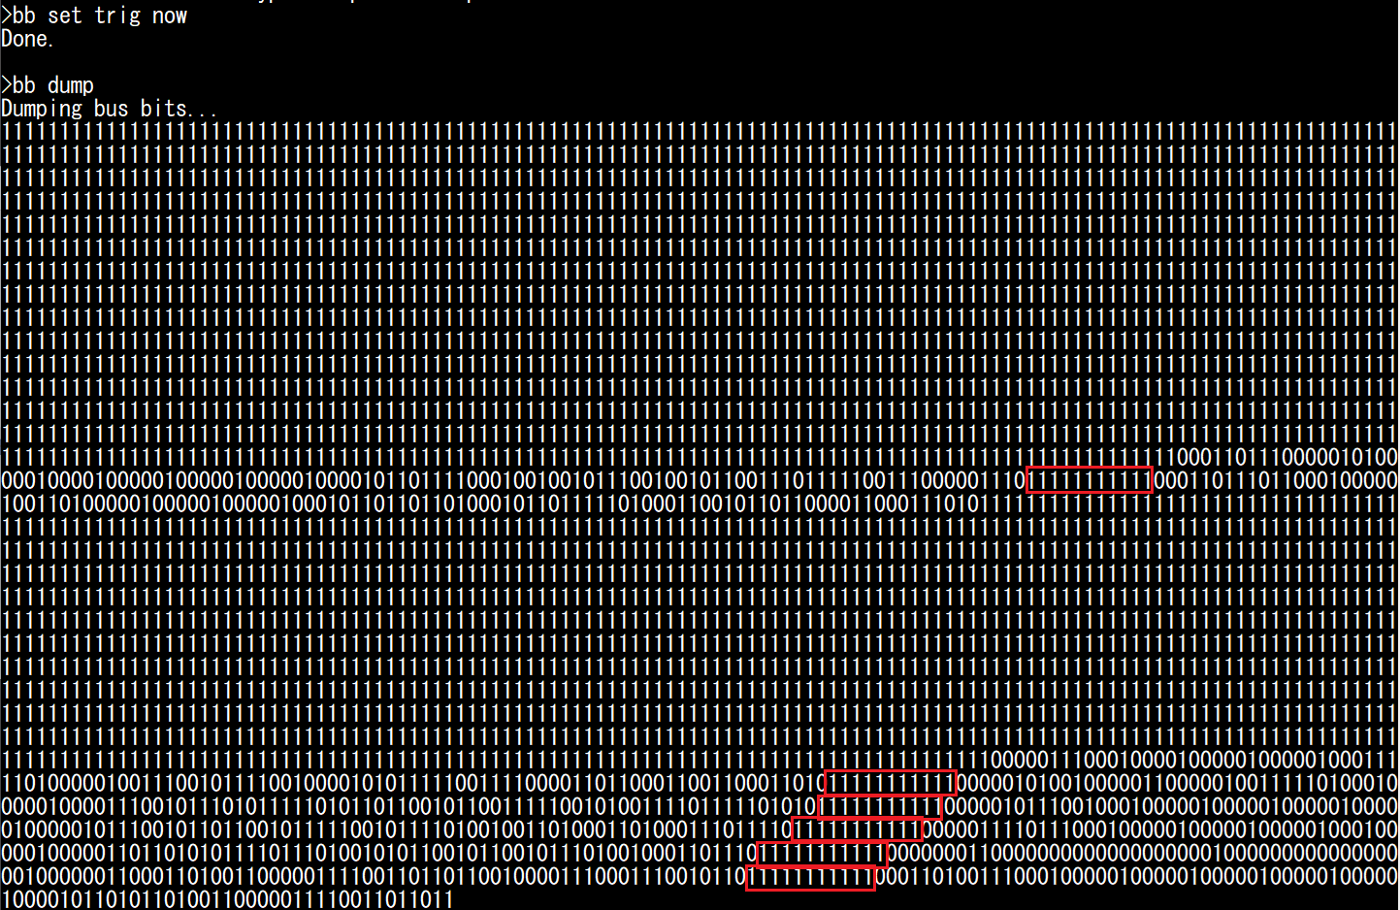
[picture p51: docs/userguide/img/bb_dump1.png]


Under normal conditions, **CAN frames should always be separated by at least 11 recessive bits**.
Streaks of 11 recessive bits are highlighted in red in the screenshot above, and you should quickly learn to recognize this delimiter between frames.

You should be able to make the following observations:

- Most of the time, the bus is idle and nothing is happening (we read long trails of "1"s).
- A CAN transmission is rarely alone, but immediately followed by other frames.

There are two reasons that you will often see those "bursts" of messages, instead of individual random frames:

- ECUs tend to send several CAN frames with the same timer, so CAN frames end up queued for transmission at the same time. This is not true for all ECUs, but this is true for RAMN ECUs.
- RAMN ECUs have a similar boot time, so they tend to start in a synchronize state. Due to clock inaccuracies, they do eventually slowly drift away.

For the second point, you can mitigate it by using the ``randomize`` command (which is not a ``bb`` command): it will reset ECUS B/C/D with a random delay to prevent synchronization.
You can try it for yourself and see how the shape of the traffic differs each time (use ``bb set trig 024`` to always trigger on the same ID).

Bus Load
^^^^^^^^

The percentage of time during which CAN transmissions are occurring (from SOF to IFS0) corresponds to what is called the **bus load**.
Because all messages must share the same CAN bus, the total bus load of a CAN bus corresponds to the sum of the contribution of each message (from each ECU).
Naturally, messages with fast periods (such as 10 ms for the brake and accelerator of ECU C) contribute more than messages with slow periods (such as 100 ms for ECU D's messages).
Because of bit stuffing, the length of a CAN frames is not fixed (read this `Wikipedia article <https://en.wikipedia.org/wiki/CAN_bus#Bit_stuffing>`_ for exact boundaries).

You can read several messages with ``bb read``, and you'll observe that they are mostly about 120-bit long.
With a bit time of 2 µs (corresponding to a 500kbps baud rate), we can estimate the duration of a RAMN ECU CAN frame to be about 240 µs.

You can measure the busload using ``bb busload``.
This command will measure the busload for the duration of the **timeout** parameter.

If you want to know the bus load contribution of ECU D, you can silence ECU B and C and measure what the bus load is. You can repeat this for each ECU. You can increase the timeout value for more accurate measurements.

.. warning::

	You must use ``silence`` and ``talk`` for this, and not ``disable`` and ``enable``: remember that you need some ECUs to be active to acknowledge the CAN frames.

You can measure the bus load when each ECU is active individually, and when they are all active at the same time, using the following commands:

.. code-block:: text

	reset
	#
	bb set trig now
	silence BCD
	talk B
	bb busload
	silence BCD
	talk C
	bb busload
	silence BCD
	talk D
	bb busload
	talk BCD
	bb busload

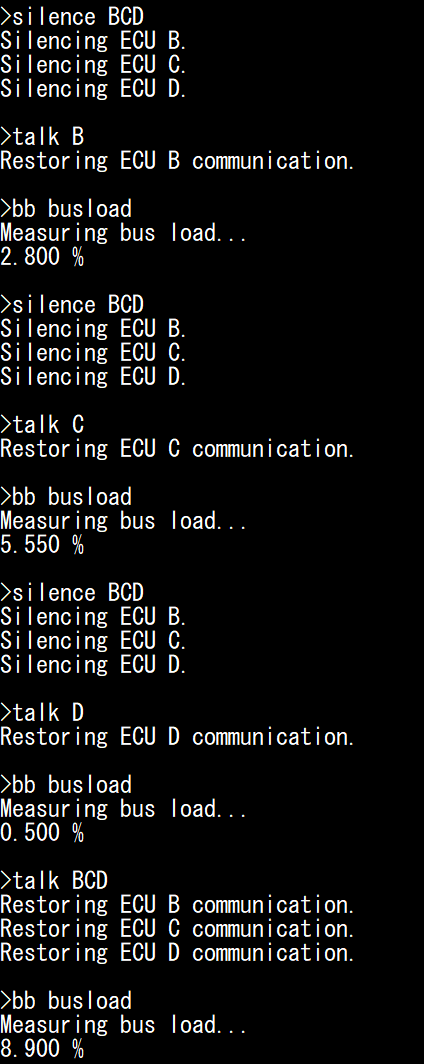
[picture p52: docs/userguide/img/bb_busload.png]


You can confirm these values are within the expected range: for example, ECU D sends two messages (ID 0x1B8 and ID 0x1BB) with an 8-byte payload, every 100 ms. Assuming the 240 µs bitstream length discussed above, this means ECU D is transmitting a message during approximately 0.240+0.240/100 = 0.48% of the time. 

.. note:: 

	💪 If you're looking for a small challenge, you may try to find yourself the shortest and longest possible valid CAN frames bitstreams (by influencing bit stuffing with your data).

Transmit Pause
^^^^^^^^^^^^^^

You can observe the impact of the **"Transmit Pause"** parameter previously discussed, using the ``uds`` command.
You should set the trigger on message 024, so you can observe the burst of CAN frames sent by ECU C (at least two frames).

.. code-block:: text

	silence BD
	talk C
	uds C 31010222000101
	bb set trig 024
	bb dump

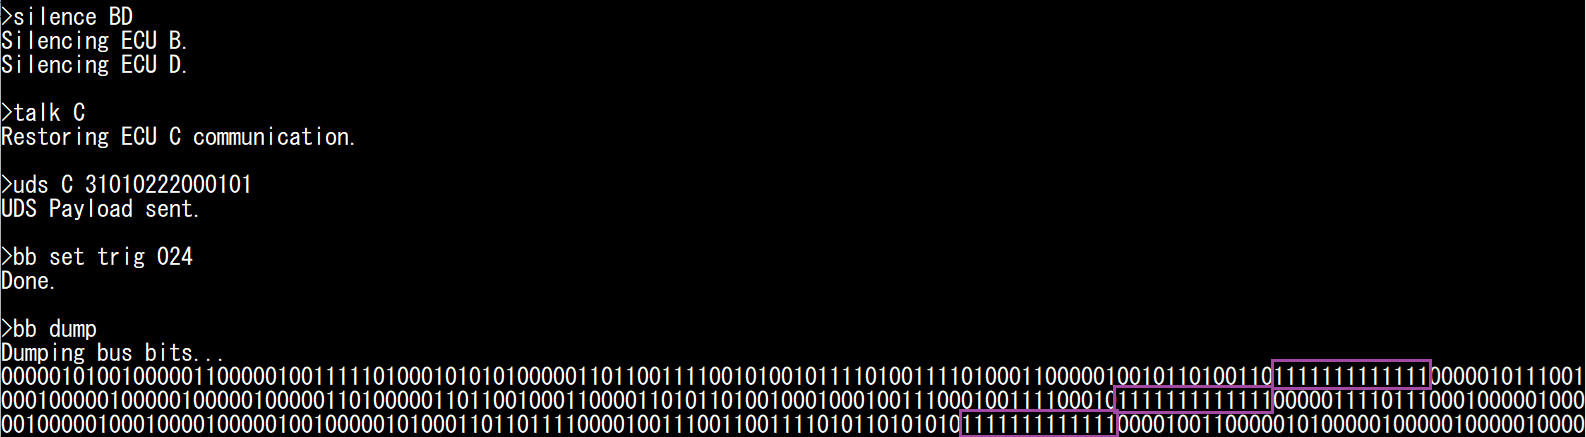
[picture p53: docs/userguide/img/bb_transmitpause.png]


You should observe that ECU C's CAN frames are now separated by 13 recessive bits instead of 11, indicating a 2-bit pause.

Screaming ECUs and the "Error Passive" Punishment
^^^^^^^^^^^^^^^^^^^^^^^^^^^^^^^^^^^^^^^^^^^^^^^^^

Earlier, we observed the "**spamming behavior**" of ECUs when auto-retransmission is enabled and there is no acknowledgement.
Now, we can see what happens at the bitstream level.

Reset the board to ensure auto-retransmission is enabled. Then, disable ECU B and C to only leave ECU D active on the CAN bus.
Set the trigger to "any" to catch the first message.

.. code-block:: text

	reset
	#
	disable BC
	bb set trig any
	bb dump
	
You should obtain a pattern similar to the screenshot below.

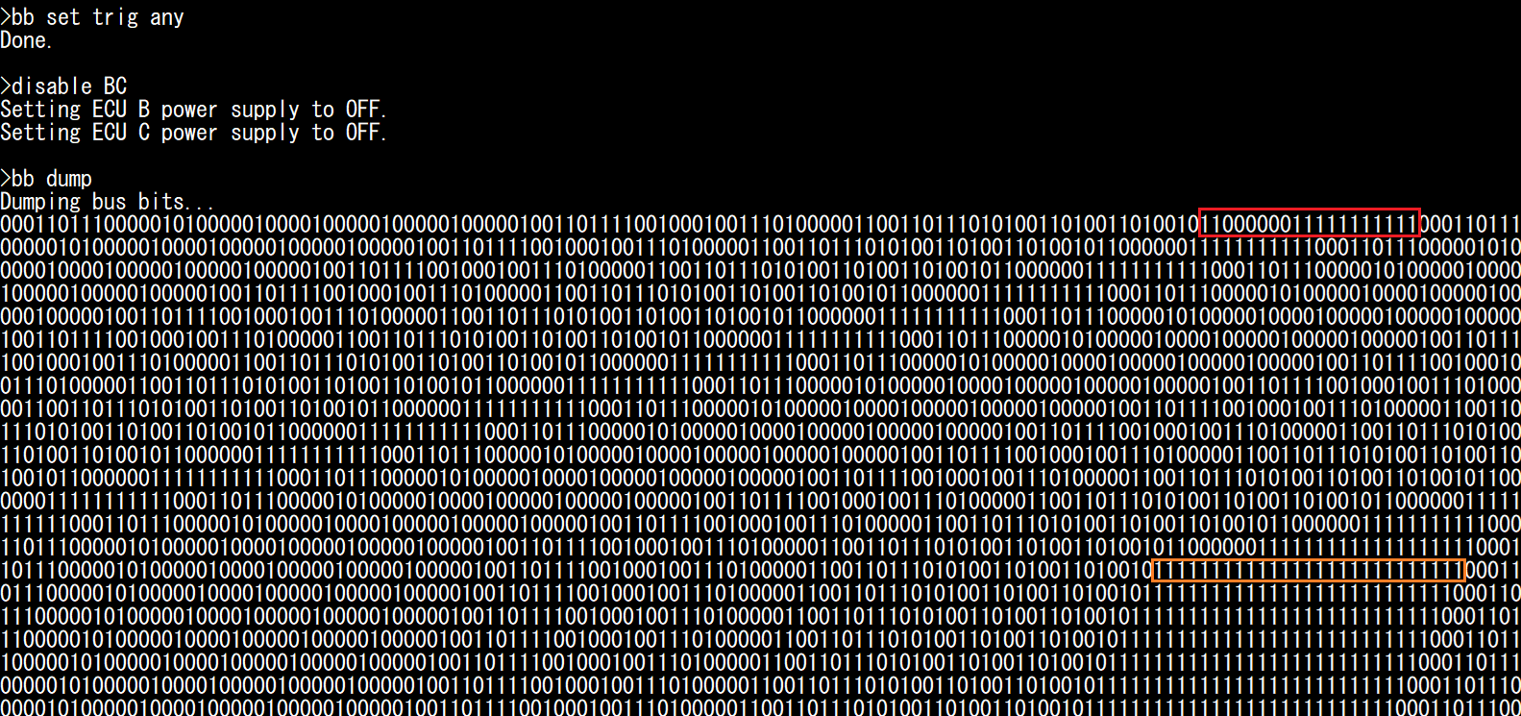
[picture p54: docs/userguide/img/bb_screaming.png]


What is happening here?

As soon as you start the ``bb dump`` command, ECU A enters bitbang mode and there is nobody left on the CAN bus to acknowledge ECU D's CAN frames. 
Until then, ECU A was acknowledging them, so you can assume ECU D has a Transmit Error Counter (TEC) equal to 0.
You can see at the end of the first frame the bit string "1100000011111111111" (highlighted in red).
The first 1 corresponds to the CRC delimiter. The second 1 corresponds to the ACK bit, that nobody set to 0.
ECU D detected this, and as a result transmitted six 0s, which is an **Error Flag** (and you should become familiar with spotting them).
ECU D then waited 11 recessive bits before attempting transmission again.
ECU D repeated this for 15 attempts. At the 16th attempt, the TEC became too high and ECU D entered **Error Passive** mode:

- It waits an additional 8 recessive bits before attempting retransmissions.
- It stops sending **Active Error Flags** (six 0s) and replace them with **Passive Error Flags** (six 1s).

As a result, you can see the 111111111111111111111111111 pattern (highlighted in orange) repeated a lot. It corresponds to:

- 1 CRC delimiter
- 1 (recessive) ACK slot
- 6 Error Flag bits
- 8 EOF
- 3 IFS
- 8 additional bit wait time.

This sums up to a total of 27 recessive bits.
On your screen, you may see an additional 1 to 4 more recessive bits corresponding to CRC0, CRC1, etc. if they happened to be equal to 1.

.. note::

	If you are curious, you can also execute ``bb busload`` and you should observe that the bus load is now 85%, even though only ECU D is active.
	This is a bit inaccurate, because the ``bb busload`` command assumes a regular CAN bus traffic, which is not our case here.
	The actual bus load corresponds to about 125/133 (~94%), corresponding to an 8-bit idle time for a repeated 125-bit frame (same length as before, but we replace the 1-bit ACK delimiter by the 6-bit Passive Error Flag).
	**Thanks to the Error Passive mode, other CAN frames (including those with lower priority over our repeated frame) can win arbitration and still have a window to be transmitted.**
	This is not particularly useful in this case (because if another ECU were active, the ACK error would not exist), but it is useful for other conditions that may cause an ECU to repeatedly fail.

Sending Arbitrary Bitstreams
^^^^^^^^^^^^^^^^^^^^^^^^^^^^

It is now time to send our own custom bitstreams.
Start by resetting the board, and ensure that the Stop LED of ECU D is off (release ECU B's handbrake and move ECU C's brake pedal to 0%).
Then, silence ECU B, C, and D, so that you are the only one transmitting CAN frames.

.. code-block:: text

	reset
	#
	silence BCD
	
Now, use ``bb set trig idle`` to trigger the transmission on bus idle condition, and use ``bb send <arbitrary_bitstring>`` to send the raw bitstreams that you recorded previously (preferably after manually setting the ACK bit slot to 1).

.. code-block:: text

	bb set trig idle
	bb send 000001010010000011000001001111101000100000100110000011011110110001000111100001001001011101001001110100001111111111111
	
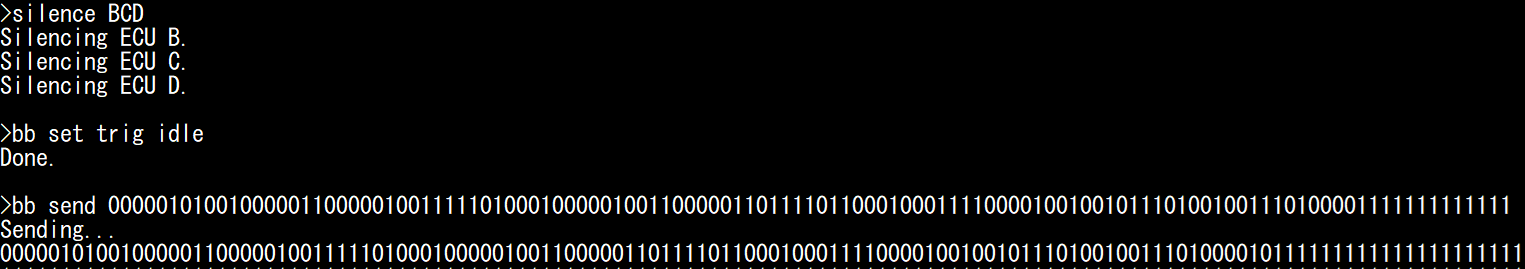
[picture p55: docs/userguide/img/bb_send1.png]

   
You should observe that the Stop LED will light up, confirming that ECU D received your message.
If you look at the CAN bus status, you will also observe that other ECUs replaced your ACK 1 by an ACK 0, meaning they received your message correctly.
Try sending the brake 0% message to turn off the Stop LED again.

.. code-block:: text

	bb send 000001010010000011000001000001000001000001000001111000110101000010011100110110000011001100101110101111101001111111111111

.. _generating_error:

Generating CAN Errors
^^^^^^^^^^^^^^^^^^^^^

Now comes the fun part: you can swap some bits and observe **how** and **when** Error Flags are generated.
If you struggle to identify bitfields in the bit streams, refer to the screenshots in the :ref:`saving_frames` section.

To begin, disable ECU B and C to make sure only ECU D is influencing the CAN bus. Then, ask ECU D to stay silent so that only we are transmitting on the CAN bus (and ECU D only either acknowledges or reports an error).

.. code-block:: text

	disable BC
	silence D
	
When you swap bits of your own bit stream, you may generate different types of error, that are detected at a different timing:

- You may violate the bit stuffing rule ("**Bit Stuffing Error**").
- You may swap a reserved bit which **must** be set to a specific value ("**Form Error**").
- You may swap a bit that leads to an invalid CRC ("**CRC Error**").

Bit Stuffing Errors and Form Errors are detected and reported immediately; CRC Errors are reported after the CRC field.

First, let us start with bit stuffing. Let us observe what happens when we send a string of six zeroes.

.. code-block:: text

	bb set trig idle
	bb send 000000
	
.. note::

	Remember that "1" is recessive and corresponds to "do nothing", so the three commands below are equivalent:
	
		.. code-block:: text

			bb send 000000
			bb send 00000011111111111
			bb send 00000011111111111111111111111111111111111111111111111111111111
		
	We never need to send a trail of 1s at the end, but sometimes we will anyway, in order to highlight the fact that other ECUs transmitted a 0 when we were transmitting a 1.


   
We observe twelve consecutive 0s: the first six 0s sent by ourselves, and the second six 0s sent by ECU D as an Error Flag.
Those 12-bit dominant bits, along with 11 recessive EOF and IFS bits, form the longest possible "valid" **Error Frame** (technically, IFS is not part of that frame and is a separate "silent time", but most people will lump them together).
If you look at ECU D, you should observe that the Check Engine LED is now lit: ECU D is aware of the error.
   
.. note::

	Generating CAN bus errors will increment the CAN Errors counters. If you wish to reset those counters, you must reset the ECU (using for example "reset D"), and silence ECU D again:
	
	.. code-block:: text

		reset D
		silence D

Swapping Some Bits
^^^^^^^^^^^^^^^^^^

It is important that you pay attention to bit stuffing so that the errors that you generate are not all plain-and-simple "Bit Stuffing errors".

This requires careful attention: your swapping may have removed the need for a stuffed bit further down the line that you need to remove yourself, or added the need for a stuffed bit that you need to add yourself.
We demonstrate a few cases, using the 100% brake message above.

First, reset ECU D to make sure it is in Error Active mode:

.. code-block:: text
	
	reset D
	silence D

We can try to see what happens when we send a "r0" reserved bit with a value of "1" instead of "0".
For this case, we do not bother sending the full bit stream, because we expect the error to be detected immediately after r0 and want to observe it without impacting the bus ourselves.

If we send the following message:

.. code-block:: text

	bb set trig idle
	bb send 00000101001000011
	

   
We observe that ECU D destroys the message as soon as the r0 bit is detected as wrong. This results in an Active Error Flag of six 0s (all sent by ECU D), which is the shortest possible Error Flag.
Contrarily to the previous case, none of the 0s are set by ourselves.

Finally, let us observe what happens on "non-reserved" fields, by swapping a bit in the DATA field (offset 54), that does not influence bit stuffing.
For reference, we can first send the original non-swapped message.

.. code-block:: text

	bb send 000001010010000011000001001111101000100000100110000011011110110001000111100001001001011101001001110100001111111111111
	bb send 000001010010000011000001001111101000100000100110000010011110110001000111100001001001011101001001110100001111111111111

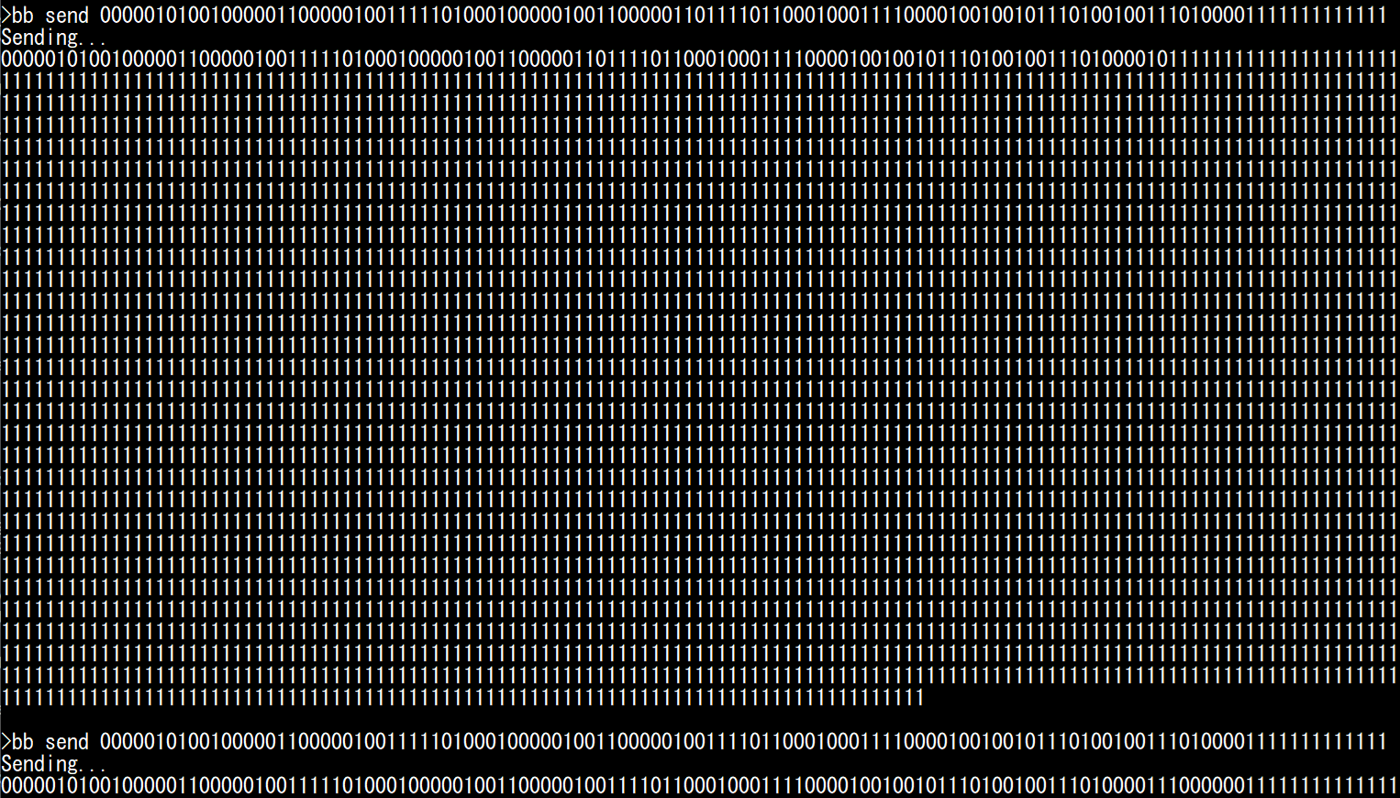
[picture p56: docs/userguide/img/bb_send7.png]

   
Interestingly, we observe that when we swap a bit in the data field (and the CRC is not valid anymore, but bit stuffing is still valid), the ECU will not ACK the message, wait for the ACK delimiter, then sends a 6-bit Active Error Flag.
This means the error is detected and reported significantly later than in the previous cases.

.. note::

	Security Professionals: you may wonder what happens if we change the DLC field to something above 8, with a valid CRC.
	You do not need bitbanging for this: STM32's FDCAN peripheral will happily transmit and receive such CAN frames, but will simply consider the size to be 8 bytes.

Forcing Error Passive mode
^^^^^^^^^^^^^^^^^^^^^^^^^^

By reusing the Error Flag of the :ref:`generating_error` section, we can generate 16 valid Error Frames with the following command:	

.. code-block:: text

	reset
	#
	disable BC
	silence D
	bb set trig idle
	bb send 00000011111111111111111000000111111111111111110000001111111111111111100000011111111111111111000000111111111111111110000001111111111111111100000011111111111111111000000111111111111111110000001111111111111111100000011111111111111111000000111111111111111110000001111111111111111100000011111111111111111000000111111111111111110000001111111111111111100000011111111111111111

Execute it 8 times and observe what happens when you execute it a 9th time (and generate more than 128 errors):

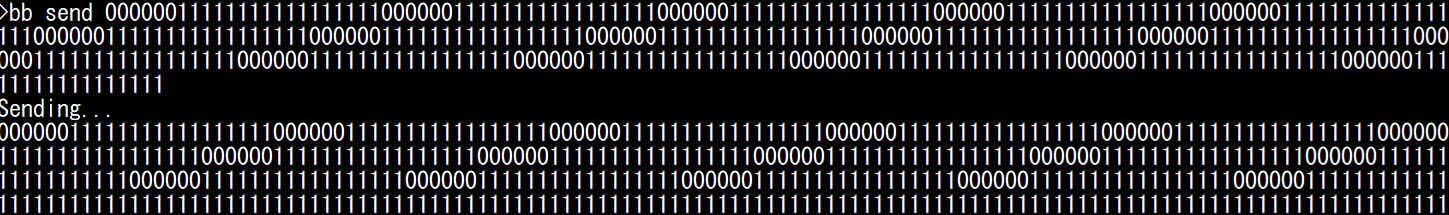
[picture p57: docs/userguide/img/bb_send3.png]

   
We can observe that ECU D enters Error Passive mode and stop sending Error Flags after 128 receive errors (significantly more errors than when transmitting).
You can keep transmitting Error Frames, but ECU D will not enter bus-off mode, because it is not transmitting any frame so its TEC counter is still at 0.
   
.. note::
   
	If you want to make the process above shorter, you can play the **Error Frame Inception game**: generate a bit stuffing error, which triggers an Error Frame from ECU D, then send a dominant bit during the EOF field of that frame to trigger a Form Error, which triggers a new Error Frame that we can repeatedly target.
	Each time, we need to wait six recessive bits, to let ECU D think that the Error Flag superposition is over and it has entered EOF territory. For example, to generate 16 errors:

	.. code-block:: text

		bb send 0000001111111011111110111111101111111011111110111111101111111011111110111111101111111011111110111111101111111011111110111111101111111
	 
	

	Finally, if you want to put ECU D in Error Passive mode in one shot, a long dominant string also typically works (as long as it is less than 2ms in duration, which is the case here):

	.. code-block:: text

		bb send 000000000000000000000000000000000000000000000000000000000000000000000000000000000000000000000000000000000000000000000000000000000000  

Goodbye IFS0
^^^^^^^^^^^^

Remember when we said that CAN frames must be separated by 11 recessive bits? That is a lie, 10 bits are enough, because according to the CAN specifications **we can just skip IFS0**.
To try this, copy paste a message twice, and remove one bit in the 11-bit recessive streak between them.
Send them to ECU D. You'll notice it does not trigger an error and ECU D happily processes and acknowledges both messages.

.. code-block:: text

	reset D
	silence D
	* Below line to turn OFF: brake 100% then brake 0% *
	bb send 00000101001000001100000100111110100010000010011000001101111011000100011110000100100101110100100111010000111111111111000001010010000011000001000001000001000001000001111000110101000010011100110110000011001100101110101111101001111111111111
	* Below line to turn ON: brake 0% then brake 100% *
	bb send 00000101001000001100000100000100000100000100000111100011010100001001110011011000001100110010111010111110100111111111111000001010010000011000001001111101000100000100110000011011110110001000111100001001001011101001001110100001111111111111


	  
Protocol Level Attacks
----------------------

In this section, we use ECU A to demonstrate attacks that are implemented by tools such as `canhack <https://github.com/kentindell/canhack>`_.
We limit the scope to attacks that can be performed only by interacting with the CAN TX CAN RX pins, but note that some CAN protocol level attack tools may implement more attacks using special hardware such as analog switches (e.g., to force a recessive state even when a dominant bit is sent).

ASAP Spoofing
^^^^^^^^^^^^^^^^

Before using our bitbang module, we can demonstrate what can be done with a regular CAN peripheral.

In the :ref:`interacting_with_CAN` Section, we demonstrated how we can record CAN messages and replay them.
Notably, we recorded the brake message (ID 0x024, normally transmitted by ECU C) and replayed it to demonstrate how we can make the Stop LED light up on ECU D, which can be called an "attack" on the CAN bus, since we try to take over the controls.
However, this "attack" was not very subtle or efficient: because ECU C was still actively transmitting the 0x024 message, whatever value we sent was quickly overwritten. If we sent too many messages, we would generate CAN bus errors.
Therefore, a more elegant solution is needed.

An obvious solution is to not send our custom 0x024 CAN frames at a random timing, but **as soon as the original message transmitted by ECU B is received**, in order to immediately overwrite that previous value in the receiver's memory as soon as possible (ideally, before it impacts the ECU's processing loop).
You could implement this on your computer (in fact, you are invited to try it with your own script), but the latency is likely to be too long to provide satisfiable results, and you might experience some blinking.

You can use the ``asap`` command to instruct ECU A to immediately send a CAN frame when a specific ID is received (and to do this with the highest priority). This ensures that the data from the original CAN frame is overwritten in the receiver memory by your value at the **earliest opportunity**.

For example, reset your RAMN to make sure it is in a known state, then ensure the controls are so that ECU D's Stop LED is OFF (handbrake released and brake pedal at 0%).
Then, enter the CLI mode and type the following command to overwrite the 0x024 brake message with a value of 100%:
	
.. code-block:: text

	asap 024 0FFF

You should observe that:

- The Stop LED lights up, and should not be blinking (unless you are unlucky and the ECU D updated its LED in the ~240 microseconds window needed to transmit our replacement message).
- The Check Engine LED should be off (we do not generate any error).
- Other controls (e.g., lighting and blinkers) are still functional.

To stop the replacing module, simply type:

.. code-block:: text

	asap

Note that this method is still very much detectable:

- ECU B can detect that you are sending a message with an ID that belongs to it.
- ECU D can detect that it is receiving twice as many 0x024 frames as it should.

Flooding the Bus and Exposing Priority Inversions
^^^^^^^^^^^^^^^^^^^^^^^^^^^^^^^^^^^^^^^^^^^^^^^^^

Another common "attack" is a Denial of Service attack that leverages the bus topology of the CAN bus and the arbitration process: if you flood the bus with high-priority messages, you will hog the bus and prevent other ECUs from communicating, thus disabling some features.
Again, you could implement this from your computer, but it is better achieved in real time by ECU A, because we want to make sure that we leave absolutely zero opportunity to talk to other ECUs.

You can use the ``flood`` command to flood the bus with the frame that you provide as argument. If you want to make sure that the bus is entirely flooded, you will need a payload size above 3 bytes.
For example, use CAN ID 0x000 and content 0011223344556677. **For now, do not use IDs actually used by ECUs - this will cause ECUs to enter bus-off mode, which we will discuss later**.

.. code-block:: text

	flood 000 0011223344556677

Observe what happens:

- No control is responsive anymore (no message can have higher priority than 0).
- No CAN error is generated (Check Engine LED off).

Needless to say, this attack is extremely obvious to every ECU, since they receive many more frames than usual.
To stop the bus flooding, simply type ``flood`` again:

.. code-block:: text

	flood

Next, try flooding the bus with ID 0x1A8: this ID is higher than all CAN frames sent by ECU C (notably those representing the brake pedal and shift lever), but lower than some frames sent by ECU B.

.. code-block:: text

	flood 1A8 0011223344556677

Observe what happens now:

- ECU C's controls are still active: you can light up ECU D's Stop LED by moving the brake pedal, and light up the blinkers by moving the joystick left or right.
- ECU B's controls are not active: you cannot control the Stop LED using the handbrake, or the Clearance/Low Beam/High Beam LEDs with the lighting switch.

Why is this happening? We are using an ID that is high enough to let ECU C's messages go through, but not ECU B's messages.

By now, you should be screaming: **something is wrong, the lighting switch's message CAN ID is 0x150, and 0x150 is lower than 0x1A8, so the lighting switch should still work!**
This is a simple case of **priority inversion** due to the default configuration of STM32's CAN peripheral.

RAMN's STM32 microcontroller CAN peripheral is configured in a simple "FIFO" mode: it will transmit the messages in the order in which they are meant to be sent, and because by default auto-retransmission is enabled, it will never give up.
ECU B is trying to send CAN IDs 0x062 (steering), 0x150 (lighting switch), and 0x1d3 (handbrake).
ECU C is trying to send CAN IDs 0x024 (brake), 0x39 (accelerator), 0x77 (shift lever), 0x98 (horn), and 0x1A7 (blinkers).

When we are flooding the bus with 0x1A8, ECU C does not care because all its IDs are below 0x1A7, so ECU C's controls still work.
However, ECU B becomes **stuck trying to send 0x1D3**, which is above 0x1A7 and therefore cannot be sent.
Because ECU B is stuck on ID 0x1D3, it cannot transmit ID 0x150, hence the **priority inversion** (note that this should not happen during normal operations, because the CAN bus is not supposed to be 100% filled like this).

How do we prevent this? The proper answer is to stop using the default "**FIFO mode**" (*FDCAN_TX_FIFO_OPERATION*), and use the "**Queue mode**" (*FDCAN_TX_QUEUE_OPERATION*) instead, which is designed for this exact case.
RAMN does not implement this by default as it would make it more complicated to customize. However, it is possible and easy to implement if your traffic is well defined.

At this point, there is a quick fix that you can try: simply disable auto-retransmission using UDS. Note that this is not ideal, since some frames will be dropped for various reasons (such as lost arbitration), but it can be used to visualize the solution.
To try this, disable auto-retransmission for ECU B and C:

.. code-block:: text

	uds B 31010222000000
	uds C 31010222000000
	
Now, try flooding the bus with different IDs and observe how you can partially disable controls (instead of the full ECUs). **Do not reuse the same IDs as actual controls for now, as we want to avoid errors**. 
For example, the command below will disable all controls except the brake pedal:

.. code-block:: text

	flood 025 0011223344556677

Similarly, the command below will disable only the handbrake:

.. code-block:: text

	flood 1D2 0011223344556677

Bus-off Attacks
^^^^^^^^^^^^^^^

Until now, we have only used IDs not used by actual CAN frames transmitted by ECUs.
If we use an ID normally transmitted by an ECU, we will cause transmission errors and we may force an ECU to enter bus-off mode (which is known as a "**bus-off attack**").

For example, use the joystick to select the "CAN RX MONITOR" screen on ECU A, and observe what happens when you flood the bus with ID 0x24, normally transmitted by ECU C:

.. code-block:: text

	flood 024 0011223344556677
	* wait 1s, then use command below to stop the flooding *
	flood
		
You should observe that all ECU C's controls have become unresponsive, because it has entered bus-off mode due to the CAN Errors (collisions) than happened when it tried to transmit its own CAN frames with ID 0x024.
When you cause an ECU to enter bus-off mode, **all the IDs it normally transmits will stop being transmitted, not just the ID you targeted** (for example, if you target ID 0x1D3, ID 0x62 and ID 0x150 will also stop).

You can also try to make ECU D enter bus-off mode, which will be indicated by a blinking Check Engine LED, by targeting ID 0x1B8 or 1BB, which ECU D normally transmits:

.. code-block:: text

	flood 1b8 0011223344556677
	* wait 1s, then use command below to stop the flooding *
	flood

Generally, the TEC error counter will be incremented by 8 when a transmission error happens, and be decreased by 1 when a successful transmission happens.
There, It only takes 32 successive transmission errors to reach the value of 256 and make the ECU enter bus-off mode.
When auto-retransmission is enabled, this is guaranteed to happen very quickly.

If auto-retransmission is disabled with the UDS command of the previous section, then bus-off will only happen if you cause enough errors.
For example, you can try targeting ID 0x1A7 sent by ECU C, and you will notice that errors happens on the CAN bus (because ECU D's Check Engine LED lights up), but not enough to cause a bus-off.
This is because ECU C is also sending messages 0x024 and 0x039 with a short period (~10ms). Since message 0x1A7 has a long period (100ms), ECU C has enough successful transmissions between 0x1A7 frames to decrease its TEC error counter back to 0.

.. code-block:: text

	reset
	#
	uds C 31010222000000
	flood 1A7 0011223344556677
	* wait 10s, then use command below to stop the flooding *
	flood

However, if you target for example ID 0x39, then the ECU will enter bus-off because successful transmission of 0x024 only is not enough to counter the errors caused by 0x039.

Before moving on, you should also note that:

- Not all CAN errors increase the error counters: for example, the absence of ACK dominant bit when transmitting will not increase the TEC error counter past 128, hence the "screaming ECU" we encountered before.
- You can only target ECUs that are transmitting CAN messages, not receive-only ECUs (since their TEC will always stay at 0).

Jamming
^^^^^^^

If your goal is to induce a bus-off status without being subtle, you can use the ``bb jam`` command to transmit the bitstream "01010101..." for as long as the timeout parameter is set (note that we cannot transmit only zeroes, as the transceiver would disconnect us after about 2ms).

Using this module, we can for example observe that when ECUs are in receive-only mode, they will not go into bus-off mode.
You can confirm that errors are received by ECUs even when they do not transmit, which is why ECU D's Check Engine LED will light up.
ECUs will enter "Error Passive" mode after 128 errors, which you can confirm by using the ``bb send 000000111111`` command and observing ECUs do not send an Error Flag, because we observe 0000001111111 instead of 000000000000 (see :ref:`generating_error`).

.. code-block:: text

	reset
	#
	silence BCD
	bb jam
	bb set trig idle
	bb send 000000111111
	
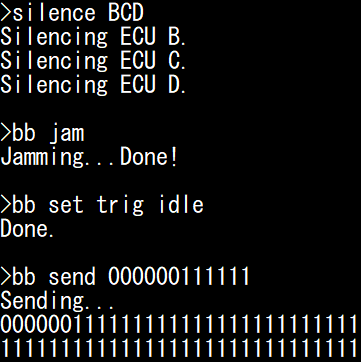
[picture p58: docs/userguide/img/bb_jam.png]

	
Although the ECUs are in Error Passive mode, they are still actively listening and acknowledging valid frames.
You can confirm this by sending the "brake 100%" message and checking that ECU D's LED light up (and the ACK bit is set).
After one valid message is received, the ECU will go back to Error Active mode: you can check this by sending the 000000111111 string again, and observing that this time you observe 000000000000 on the bus (first 6 dominants sent by yourself, 6 others sent by ECUs BCD simultaneously).

.. code-block:: text

	bb send 000001010010000011000001001111101000100000100110000011011110110001000111100001001001011101001001110100001111111111111
	bb send 000000111111

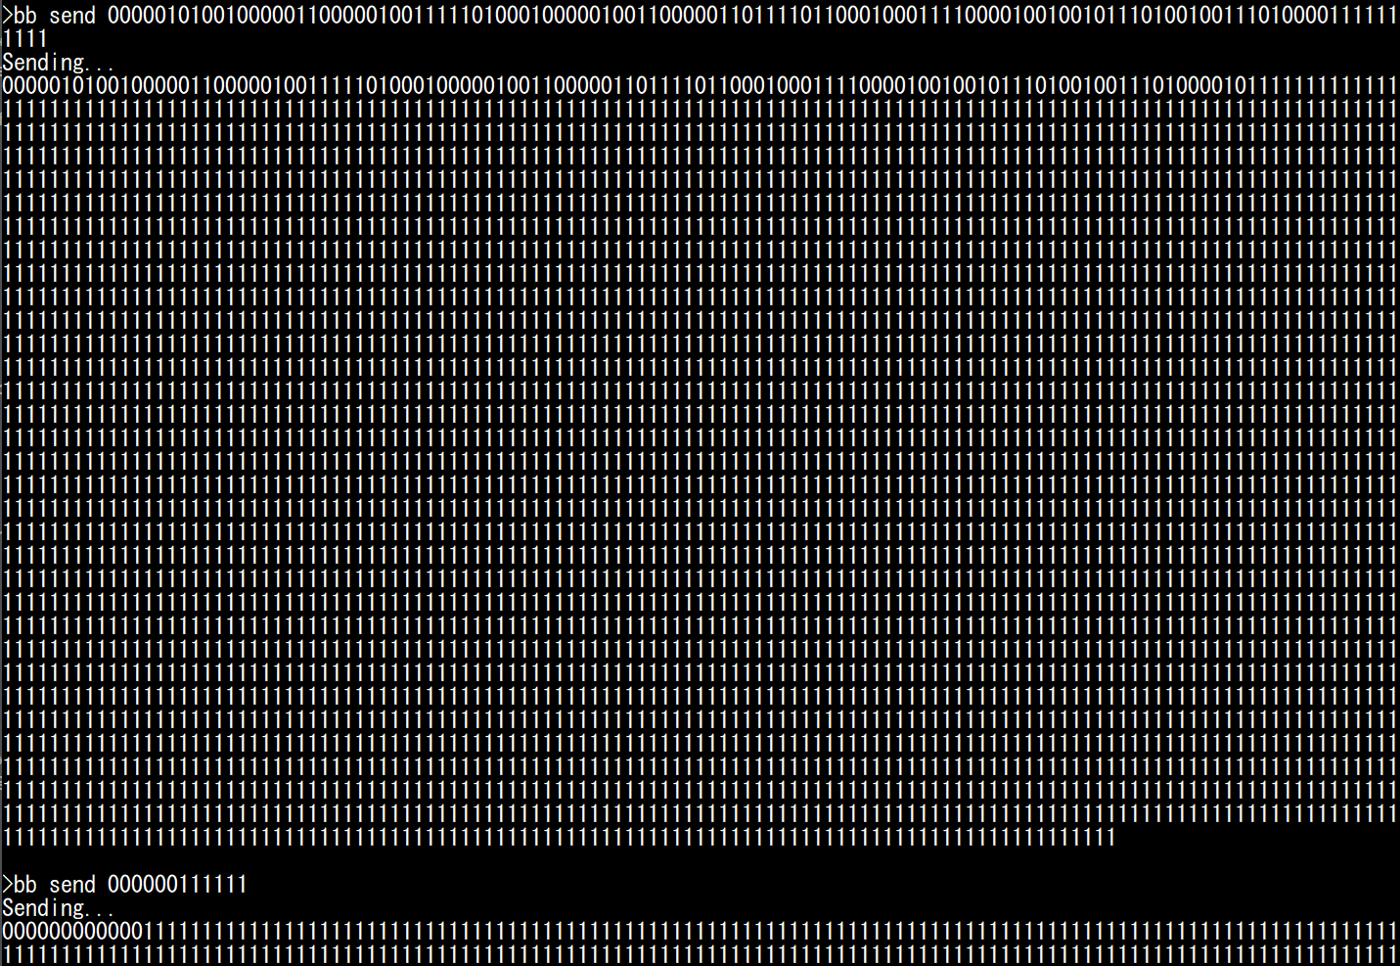
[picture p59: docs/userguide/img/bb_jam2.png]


You can resume communications with the "talk BCD" command. If you jam the bus while the ECUs are active, you will see that they enter bus-off mode.
If auto-retransmit is on (as it is by default), ECUs will enter bus-off mode very shortly after they attempt transmission (because they immediately retry and fail).
You should observe that ECU D's Check Engine LED starts blinking, indicating that in entered bus-off.

.. code-block:: text

	talk BCD
	bb jam

.. warning::

	When an ECU enters bus-off, it will stop **both transmitting and receiving**. This means that commands that rely on CAN (such as UDS commands) will stop working.
	If you have not enabled bus-off auto recovery, you will need to reset the board to make the ECUs listen to you again.

If bus-off auto-recovery is off, it would take a few seconds of jamming to disable ECUs transmitting few messages, such as ECU D.
As a result, if you disable auto-retransmission and use ``bb jam`` with a 500 ms timeout, only ECU B and C, which transmit messages more frequently, will enter bus-off mode.

.. code-block:: text

	reset
	#
	uds B 31010222000000
	uds C 31010222000000
	uds D 31010222000000
	bb set timeout 500
	bb jam

Finally, if you enable bus-off auto-recovery, you will observe that ECU D's Check Engine LED flickers when the jamming is ongoing (indicating that ECU D is trying to enter bus-off), but communications will resume once jamming stops.
According to specifications, this should technically only be allowed after ECUs observe 128 occurrences of 11 recessive bits (the equivalent of 128 valid messages), but it is not automatic with STM32's CAN controllers.

.. code-block:: text

	reset
	#
	uds B 31010222010100
	uds C 31010222010100
	uds D 31010222010100
	bb set timeout 5000
	bb jam

Overloading with Overload Frames
^^^^^^^^^^^^^^^^^^^^^^^^^^^^^^^^

The "jamming" approach (as well as the flooding approach) can allow an attacker to completely stop ongoing communications.
They however have a major drawback: they are both very easily detectable, because they either flood the bus with messages or generate many errors.
 
.. note::

	To be exactly correct, ECUs B/C/D employ hardware filters, so their software is not aware that a bus flooding attack is ongoing, because they are configured to ignore frames with IDs that they do not care about.
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

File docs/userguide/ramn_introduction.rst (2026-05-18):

Introduction
============

This guide is an in-depth introduction to RAMN and how to use it.
It can be used to gain knowledge about automotive systems and prepare for events such as automotive Capture The Flag (CTF) events.
Check the :ref:`quickstart_guide` first to get an overview.

Modern automotive networks typically consist of several Electronic Control Units (ECUs) connected to a common network, using various communication protocols such as Controller Area Network (CAN), CAN with Flexible Data Rate (CAN FD), and Local Interconnect Network (LIN).
RAMN is a set of simple Printed Circuit Boards (PCBs) that emulate such an automotive network, with four ECUs connected to a common CAN FD bus.
Although not as complex as a real vehicle, it can be used as a platform to easily learn about automotive systems and experiment with them.

RAMN Hardware
-------------

RAMN consists of a "main board" and "expansions". Expansions are not strictly required, but can be useful to implement physical interactions.
RAMN has four ECUs: ECU A, ECU B, ECU C, and ECU D. Each ECU can be identified on the main board by looking at the PCB markings.


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

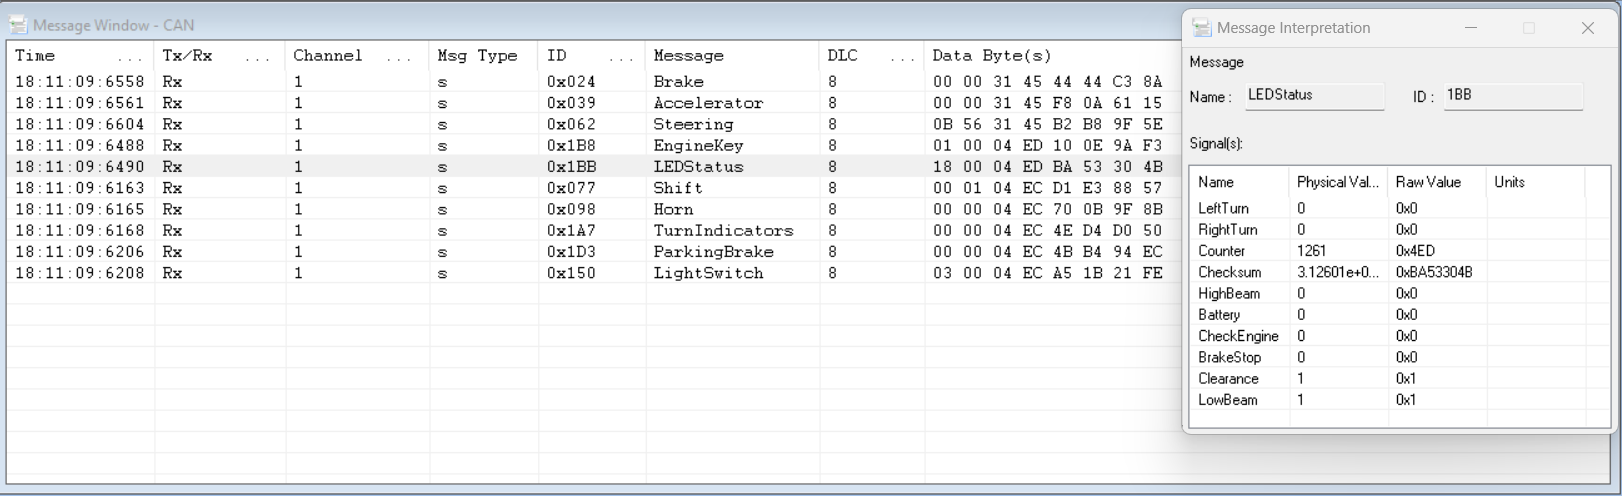
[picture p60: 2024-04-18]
docs/userguide/img/busmaster_dbc2.png

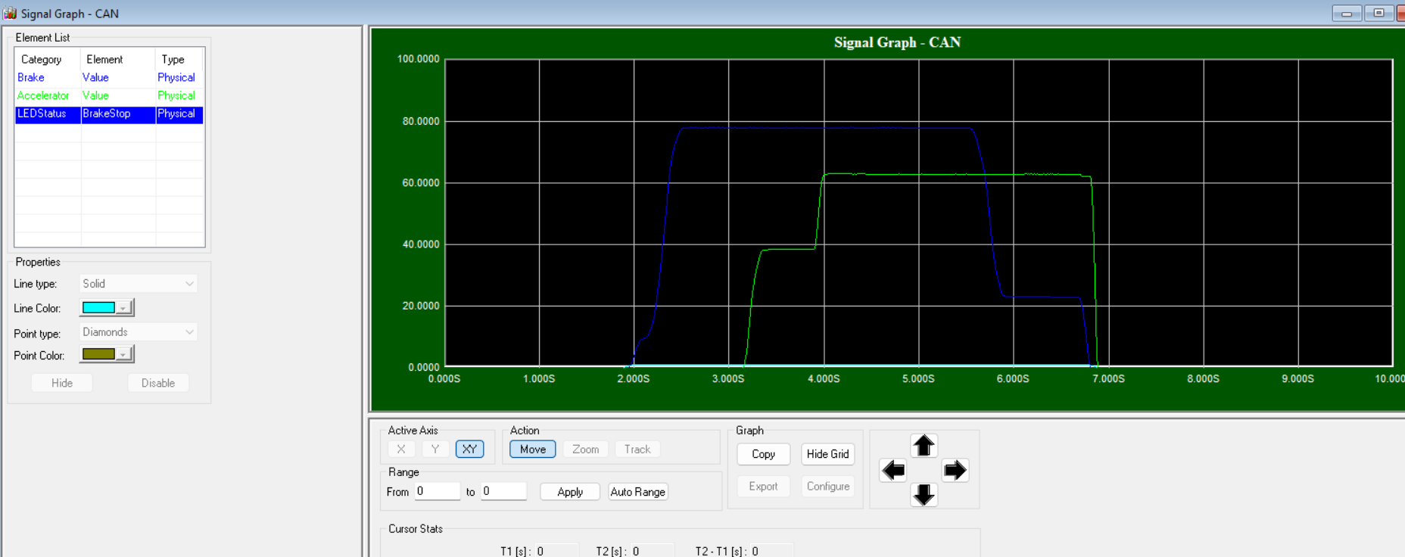
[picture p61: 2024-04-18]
docs/userguide/img/busmaster_dbc4.png

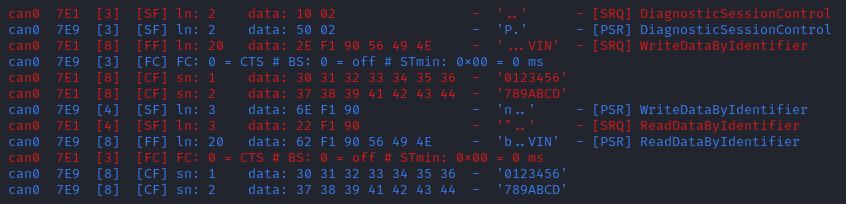
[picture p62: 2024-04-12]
docs/userguide/img/uds_writedatabyid.png

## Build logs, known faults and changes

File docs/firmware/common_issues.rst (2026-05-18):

.. _common_issues:

Troubleshooting
===============

This page contains common troubleshooting approaches for RAMN, mostly to address reflashing and debugging issues.

.. _unreliable_usb:

Unreliable USB
--------------

If you encounter USB issues, try using a different USB port from your computer.
If you are connected to RAMN through a USB hub, try connecting RAMN directly to your computer's USB port instead.

.. _optionbyte_check:

Expected Option Bytes
---------------------

If you have trouble reprogramming or debugging RAMN, use STM32CubeProgrammer to make sure that the option bytes are as below. 

**Configurations are different for ECU A, and for ECU B/C/D.**

**Correct configuration for ECU A Option Bytes**:

.. warning::

	Do not update ECU A's Option Bytes if it does not have a valid firmware (e.g., because programming failed or was interrupted).

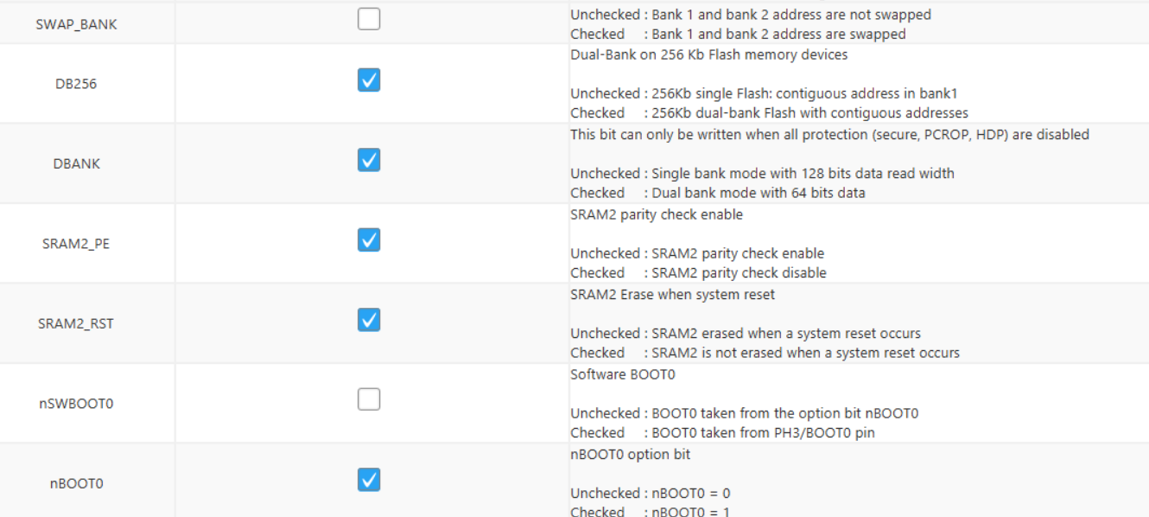
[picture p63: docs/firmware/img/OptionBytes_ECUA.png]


**Correct configuration for ECU B/C/D Option Bytes**:

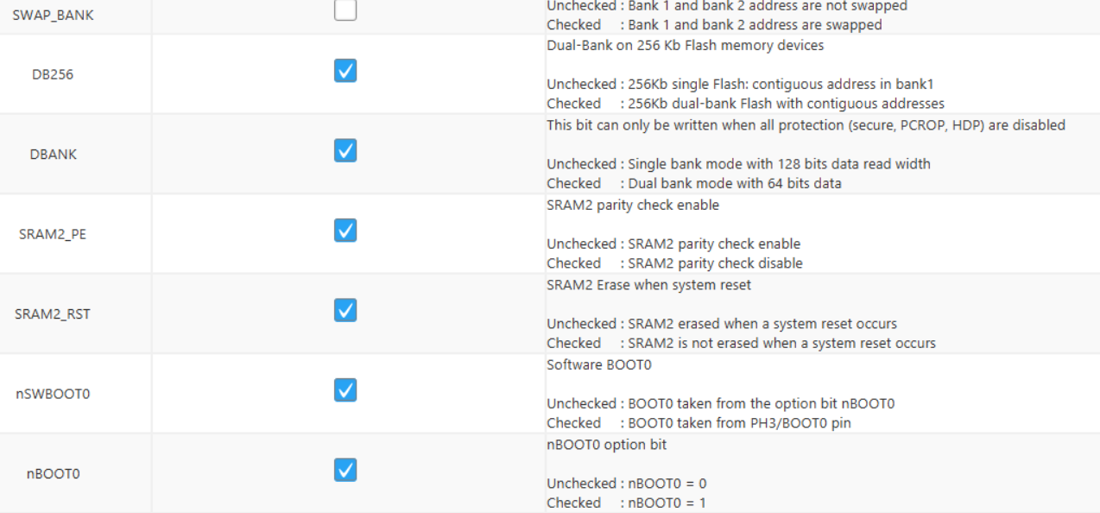
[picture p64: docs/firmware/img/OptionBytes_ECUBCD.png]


**SWAP_BANK** and **DBANK** may be modified when you use UDS reprogramming, but if you are encountering issues, try reverting to the default settings.

The **RDP Option Byte** should be set to **0xAA** to make sure that no memory protection is enabled.

After resetting option bytes, you may need to flash the firmware again.

Failed Debugging
----------------

If you encounter debugging issues with STM32CubeIDE, but you are certain that the JTAG connections are correct (e.g., you can connect using STM32CubeProgrammer), see :ref:`debugging_RAMN`. 

.. _inconsistent_protection:

Inconsistent Memory Protection
------------------------------

You can use the STM32 bootloader to enable memory read and memory write protections. Similarly, you can modify the RDP option byte to enable/disable memory protection.

Problems may arise if you enabled protection with one method, and removed it with another (e.g., if you enabled write protection using the STM32 bootloader, and removed read protection later with JTAG).
The microcontroller may appear as if it is unlocked, but will actually refuse firmware reprogramming or debugging.

If you suspect this issue (because you used memory protection in the past), try running both the "read unlock" and "write unlock" commands using the canboot.py script in the `scripts/STBootloader` folder.
**If your memory protection was inconsistent, those commands may return an error even though they actually succeeded.**

For example, for ECU B:

.. code-block:: powershell

	python canboot.py AUTO B -ru
	python canboot.py AUTO B -wu

Failed Reprogramming over CAN
-----------------------------

If reprogramming over CAN fails, it may be caused by an external CAN adapter that is actively destroying the traffic with error frames (because it does not perform a required baud rate change).
**Before reprogramming over CAN, make sure external CAN adapters are turned off and/or unplugged.**

Driver Issues
-------------

The `DfuSe tool <https://www.st.com/en/development-tools/stsw-stm32080.html>`_ from STMicroelectronics can be used to program ECU A over USB (when ECU A is in DFU mode).
If ECU A is recognized as "DFU in FS Mode" over USB by Windows, but device information is "Unknown" or "Unavailable", you may need to separately install STM32 DFU drivers, which are located in the DFuse installation folder, for example:

:file:`C:\\Program Files (x86)\\STMicroelectronics\\Software\\DfuSe v3.0.6\\Bin\\Driver`

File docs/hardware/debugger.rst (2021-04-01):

Debugger
========

The DEBUGGER expansion is used to easily probe every output of the expansion pin socket, as well as to easily connect a JTAG debugger to the ECU.

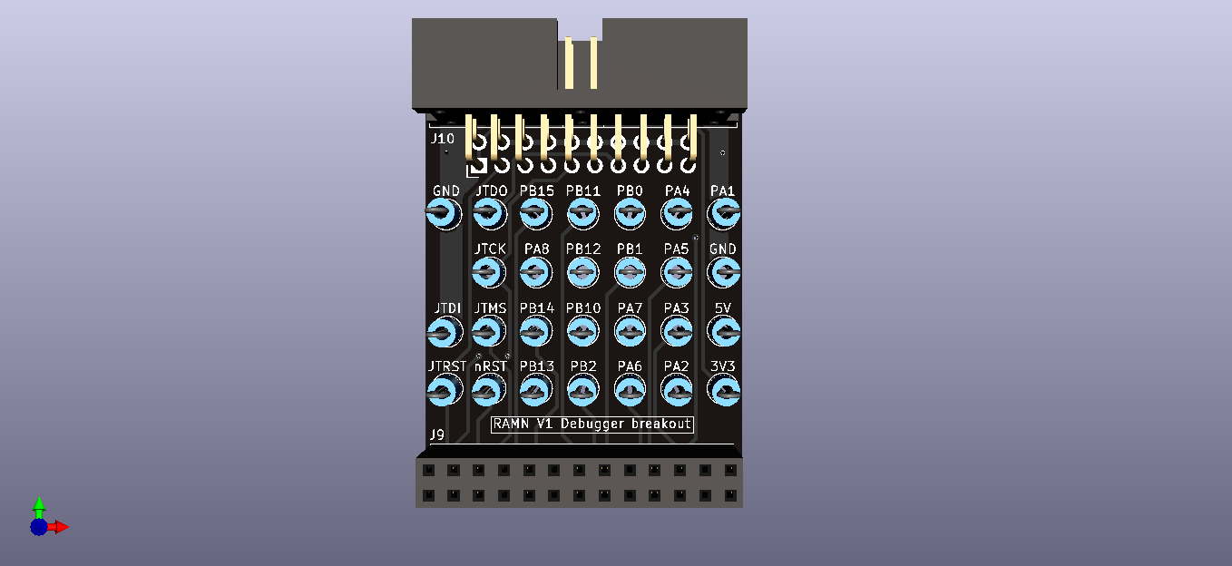
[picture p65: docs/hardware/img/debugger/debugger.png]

   
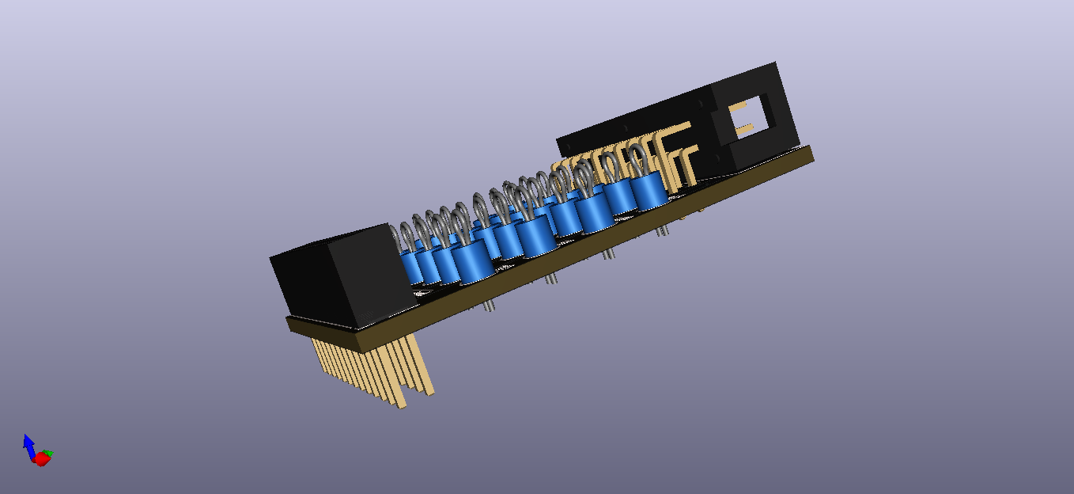
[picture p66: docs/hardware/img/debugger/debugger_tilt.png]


JTAG Debugger
-------------

A `standard 20-pin JTAG connector <https://www.digikey.com/en/products/detail/assmann-wsw-components/AWHW-20A-0202-T/5050385>`_ is present on the debugger expansion. This allows the user to connect a debugger such as the `ST-LINK V2 <https://www.st.com/en/development-tools/st-link-v2.html>`_ to easily develop and debug new firmware for the ECU. 
   
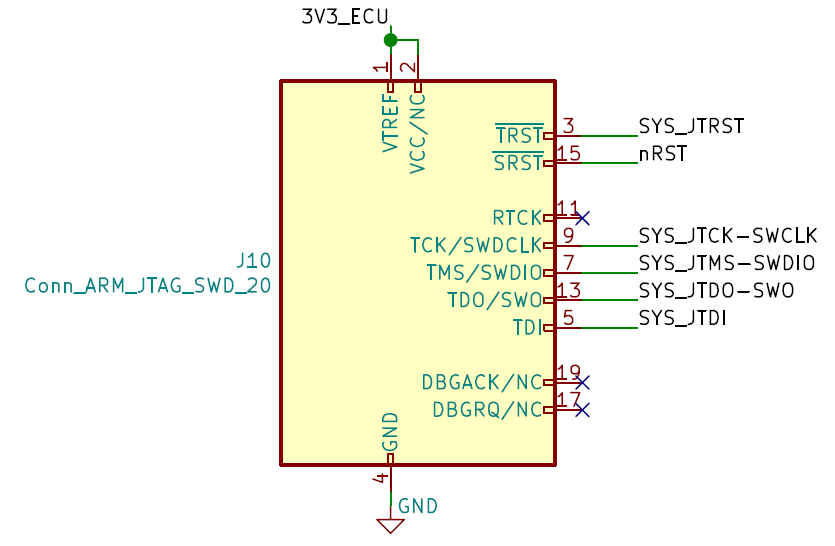
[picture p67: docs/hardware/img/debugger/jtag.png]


	Schematic of the JTAG circuitry
	
Pinout
------
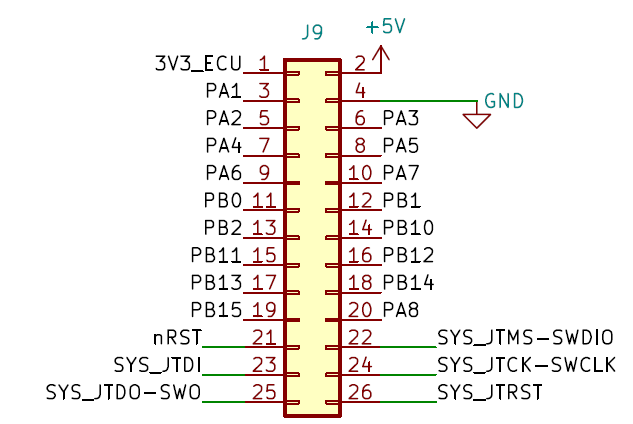
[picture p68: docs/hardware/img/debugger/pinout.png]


	Pinout of the DEBUGGER expansion's connector

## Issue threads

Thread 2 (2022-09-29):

Unable to source several parts for RAMN V1

willgreenfield, 2022-09-29:
Hey Toyota RAMN team,

I'm excited to build a RAMN V1 board, but I ran into some issues with part availability.

Hard to find/unavailable components:
1. ECU: STM32L552CET6 (48 pin)
2. CAN TRX: MCP2558FD-H/SN
3. Crystal: NX3225GD-8MHZ-STD-CRA-3

So, I'm working on modifications to add support for:
1. a more common 100-pin STM32 variant STM32L562VET6
2. both 3V3 and 5V CAN transceivers supporting various IO configurations
3. more common 4-pin crystal oscillator packages

https://github.com/willgreenfield/RAMN_STM32_100pin

willgreenfield, 2022-09-29:
#3 Completed schematic and PCB layout. Attempted to make layout as similar to RAMN V1 as possible.

Closed 2023-08-23.

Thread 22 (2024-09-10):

The following details are required when implementing hardware

cheoljun99, 2024-09-10:
Hello, I am a Korean college student currently studying the implementation of a vehicle hardware simulator. I need the following information to implement the hardware in your project.

Could you kindly answer me?

- What board in single pcs or in panel? If panel, plz advice your prefered panel way, and notice that we have MOQ for panel, which is 5.
- Board material
- TG
- Board thickness
- Solder mask and silkscreen color
- Surface finish
- Copper thickness(inner and outer)
- Via process: tent vias/ plug vias by solder mask ink/expose vias
- If there's any other special requirement, plz let me know at the same time.

CamilleTTT, 2024-10-07:
I saw that you closed the issue, but just in case:

We typically ask for the following:
- FR4 board, 1.6mm thickness. Tg depends on your intended application - the boards do not get very hot in typical operating conditions.
- Flash gold surface finish.
- Black solder mask, white silkscreen (note that some PCB fabs may prefer that you use a green solder mask to achieve required tolerances).
- 35u copper thickness (it's a two-layer board so only outer copper).
- Via process: Whatever the PCB fab recommends. By default the "tent vias" option of KiCAD is selected.
- Special requirement: solder the pin header on the Adafruit screen, if it is required (it is provided unsoldered by Adafruit).

GERBER files are provided only as single pieces. If possible, you should ask the PCB fab to panelized them to reduce cost. Note that component references do not repeat for expansions (1_screens to 5_debugger use the same BOM), but they repeat for the main board (0_ramn), so some fabs may complain if you want to panelize 0_ramn with another board. Therefore it is better to ask for two orders: One for the 0_ramn main board as a single piece, and one for the expansions (1_screens to 5_debugger) as a panel of 5 pieces.

Closed 2024-09-16.

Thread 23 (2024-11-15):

Alternative potentiometer

zbowden, 2024-11-15:
I'm having trouble finding the potentiometer specified. Do you have any suggestions for an alternative to (or place you have sourced) the potentiometer:
Ref Des - RV3
Manufacturer - Alps Alpine
Part Number - RK09D1110C0R

Thanks!

CamilleTTT, 2024-11-18:
Hello!

Indeed, RK09D1110C0R (25mm shaft) appears to be EOL.
Following potentiometers have the same footprint and are currently available on Mouser:
RK09K1110B26 (20mm shaft, linear taper)
RK09K1110A2S (15mm shaft, logarithmic taper)
(Firmware is available for both linear and logarithmic tapers)

We made some PCBs with RK09K1110A2S, due to the shorter shaft the knob tends to fall off more easily but they are perfectly usable.

zbowden, 2024-11-18:
Perfect, thank you. Closing this issue.

Closed 2024-11-18.

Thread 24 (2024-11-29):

How can I add more DTC to RAMN?

AdonaiDiazEsparza, 2024-11-29:
Hi, Im using the RAMN project to develop a "scanner" for DTC in cars with UDS protocol, my only question is how can I "introduce" or add more DTC codes? The intention is to know how the CAN frames are sent when It has more DTC storaged.
I don't know if I'm missing to read something from the documentation... so I'll be waiting for your answer. Thank you and you've been created a great project!

CamilleTTT, 2024-11-30:
Hello!

This is the part of the code that adds DTCs at startup (if no DTC is recorded):
https://github.com/ToyotaInfoTech/RAMN/blob/d8d8874298aa42baafdbf2c3e51a3da159633783/firmware/RAMNV1/Core/Src/main.c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

You can use the functions in ramn_dtc.h to add or clear DTCs.
Note that the implementation is simplified, but we also have an alternative firmware with a better UDS implementation following the standard more closely. If you let me know what features you need, I can try and include them in this repo.

AdonaiDiazEsparza, 2024-11-30:
Hi, thanks for the answer. So I must modify the firmware directly and reflash the RAMN board? Watching the code I think it will be like that 😅
I thought there was a script as tool to set the DTC's. If you can create it, will be so helpfull for the users.

CamilleTTT, 2024-12-02:
I can quickly add a routine control (0x0208) to add arbitrary DTCs. For example, use UDS command "31 01 02 08 <DTC> " to add the specified DTC.
Would that be enough for your needs?

AdonaiDiazEsparza, 2024-12-02:
Okay, yes for sure, it will be helpful. I like this project, if I had more questions Can I send it??

I congratulate you, you have a great project!

CamilleTTT, 2024-12-03:
I just added the feature; you should now be able to add arbitrary DTCs using UDS command `31 01 02 08 <DTC High Byte> <DTC Middle Byte> <DTC Low Byte (FTB)> <Status Byte>`. For now only Status Byte 0x04 is supported, and there is no check for duplicate DTCs.

Feel free to send me questions or report problems at the e-mail address listed on the main page :)

AdonaiDiazEsparza, 2024-12-03:
Thanks!! 🙌

Closed 2024-12-03.

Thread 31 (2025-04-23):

LCD Screen Configurations

KamicDemon, 2025-04-23:
I understand that the compiled firmware available in the repository is configured to work best with the [Adafruit 4313](https://www.digikey.jp/en/products/detail/adafruit-industries-llc/4313/10313904).

I want to buy a few RAMN and outfit the extensions with the cheaper [Adafruit 3533](https://www.digikey.jp/en/products/detail/adafruit-industries-llc/3533/7386265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)

What modifications should I make to the firmware in order for it to support the smaller screen size with the default screen setup? Any advice on this item would be very much appreciated

CamilleTTT, 2025-04-23:
Thank you for opening the issue.

First, If the Adafruit 4313 (240x240 display size) is too expensive, I would recommend going with the Adafruit 4383 (240x135) instead.
If the 4383 is also too expensive and you really want to use the 3533, the main differences are:
- The 3533 uses a ST7735 driver instead of ST7789. The drivers are very similar, but some adjustments might be needed.
- The display size is different, so obviously display coordinates must be updated.

Concretely:

1) Lower the SPI frequency (just in case). This can be done by modifying the line `hspi2.Init.BaudRatePrescaler = SPI_BAUDRATEPRESCALER_4;` with a bigger prescaler such as 8 or 16 (in `main.c`)

2) Address differences between ST7735 and ST7789. This is done by modifying `RAMN_SPI_InitScreen` in `ramn_spi.c`.
I think the only unavailable command with ST7735 used by RAMN is RAMCTRL, so it should be commented out.
Since this command selects data endianness, commenting it out may mean that data endianness should also be updated (so hardcoded colors in `configureColorTheme` in `ramn_screen_utils.c` should be changed from Little Endian to Big Endian).

3) Update `LCD_WIDTH`  and `LCD_HEIGHT` in `ramn_spi.h` with the new size.

4) Update the X and Y display coordinates of each screen.
Obviously, since the 3533 display is a lot smaller, some screens (like live CAN data dumping) may be difficult to implement.
You should update `ramn_screen_manager.c` to only include the screens you need, then update those screens' X and Y coordinates to match your new layout. `ramn_screen_utils.c` should also be updated to adapt to the new size (since it assumes a 240 width).

Note that if you use the Adafruit 4383, steps 1-3 are not needed, and step 4 is easier (since you only need to update the height).
Let me know if you do plan to use the 3533, I do own one and I can quickly check that steps 1-3 have no issue. I think the main challenge is to deal with the small display size, since 240x240 is already challenging...

CamilleTTT, 2025-04-24:
Out of curiosity, I tried both 3533 and 4383.
Both work with the default firmware, but as you can see colors must be redefined in Big Endian for 3533.
Both screens need to be rotated, which can be done by modifying the value of  `LCD_INIT_MADCTL` in `ramn_spi.c`
So really, most of the work is fitting meaningful data in such small screens.

With 3533
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

With 4383
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

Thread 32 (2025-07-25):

! Flashing not working with USB hub

ritikkumar8z, 2025-07-25:
Hi,
When I try to flash the firmware using bootloader.py while the RAMN board is connected through a USB hub, it doesn't detect the board or just hangs. But if I plug it directly into the laptop, it works fine.

Maybe add this info in the docs or handle it in the script?

Thanks!

Closed 2025-08-13.

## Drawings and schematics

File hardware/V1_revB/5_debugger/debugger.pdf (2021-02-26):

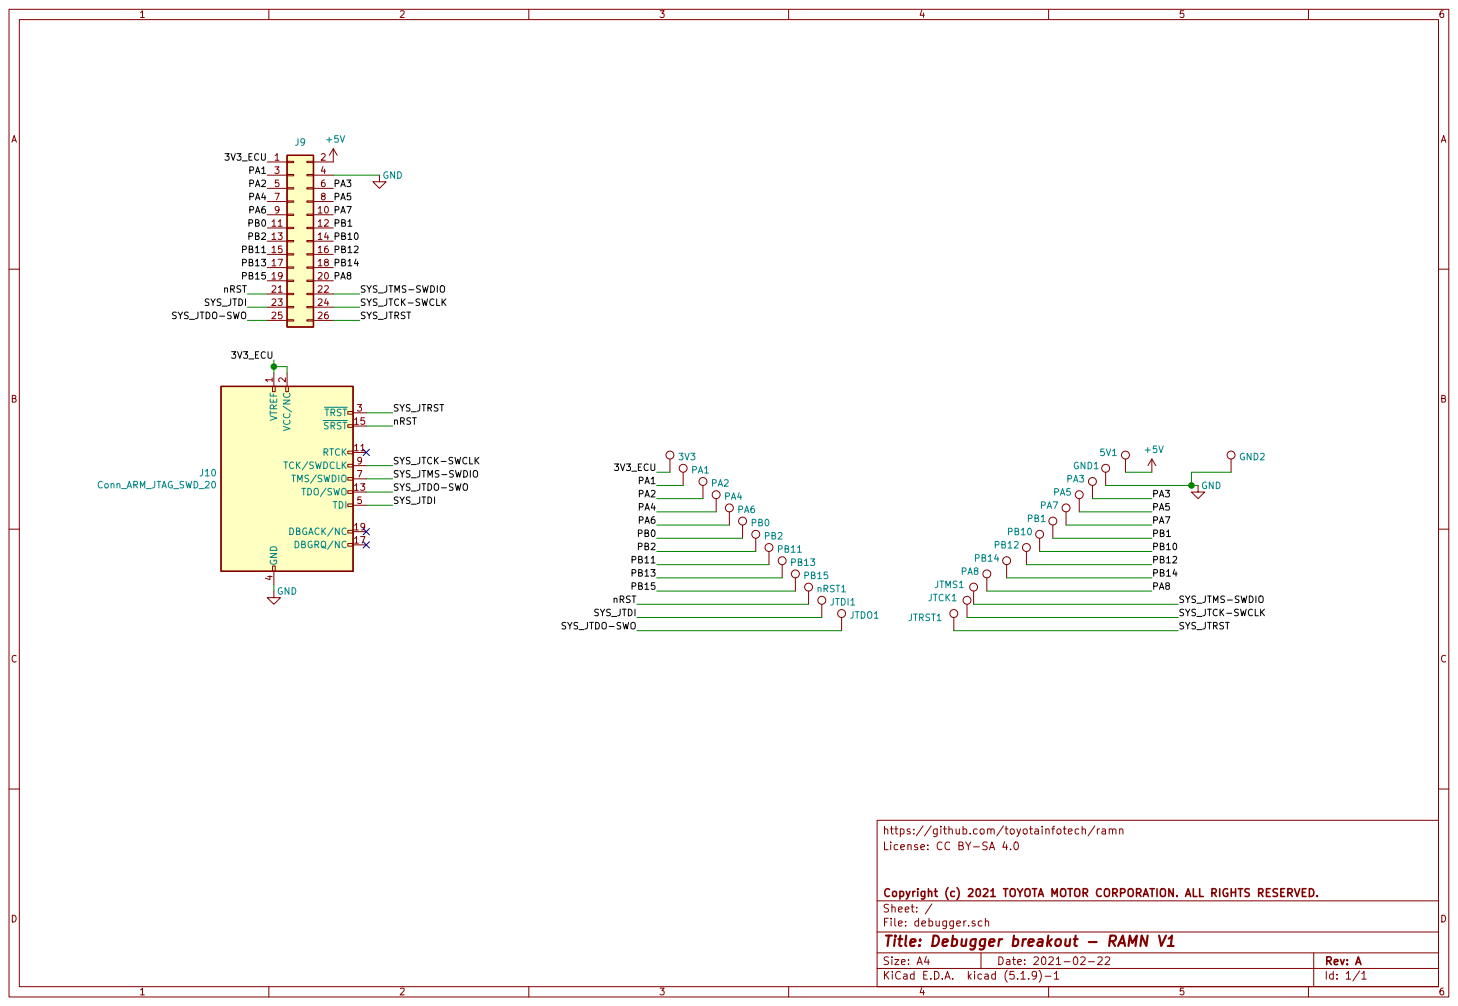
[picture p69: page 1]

1 RTCK 11 TDO/SWO 13 SRST 15 DBGRQ/NC 17 DBGACK/NC 19 VCC/NC

4 TDI 5 TMS/SWDIO 7 TCK/SWDCLK 9

File: debugger.sch Sheet: / Copyright (c) 2021 TOYOTA MOTOR CORPORATION. ALL RIGHTS RESERVED. License: CC BY-SA 4.0

Id: 1/1 Title: Debugger breakout - RAMN V1

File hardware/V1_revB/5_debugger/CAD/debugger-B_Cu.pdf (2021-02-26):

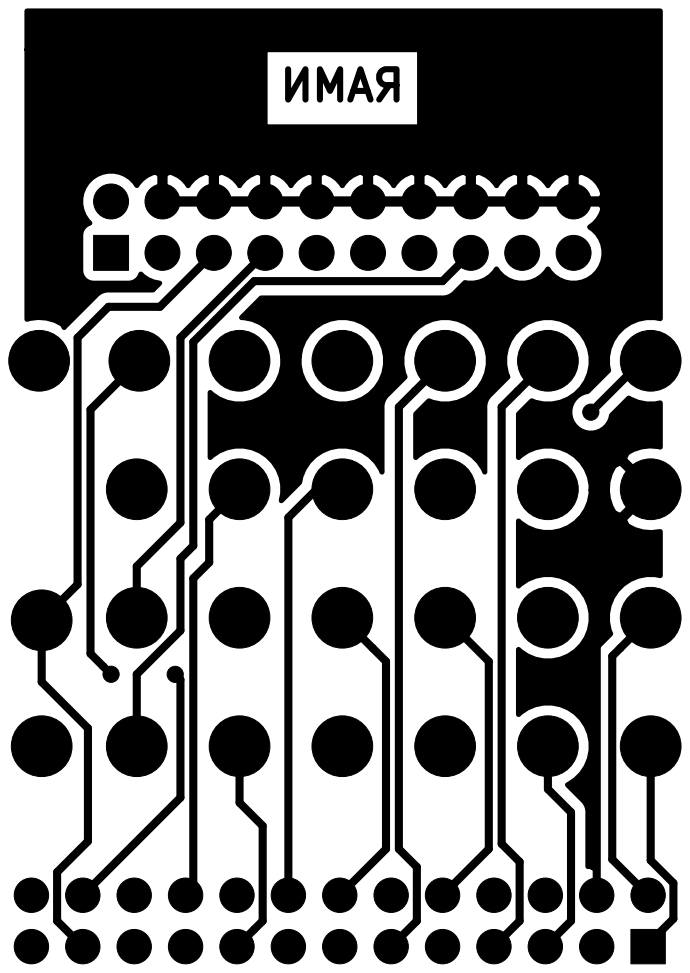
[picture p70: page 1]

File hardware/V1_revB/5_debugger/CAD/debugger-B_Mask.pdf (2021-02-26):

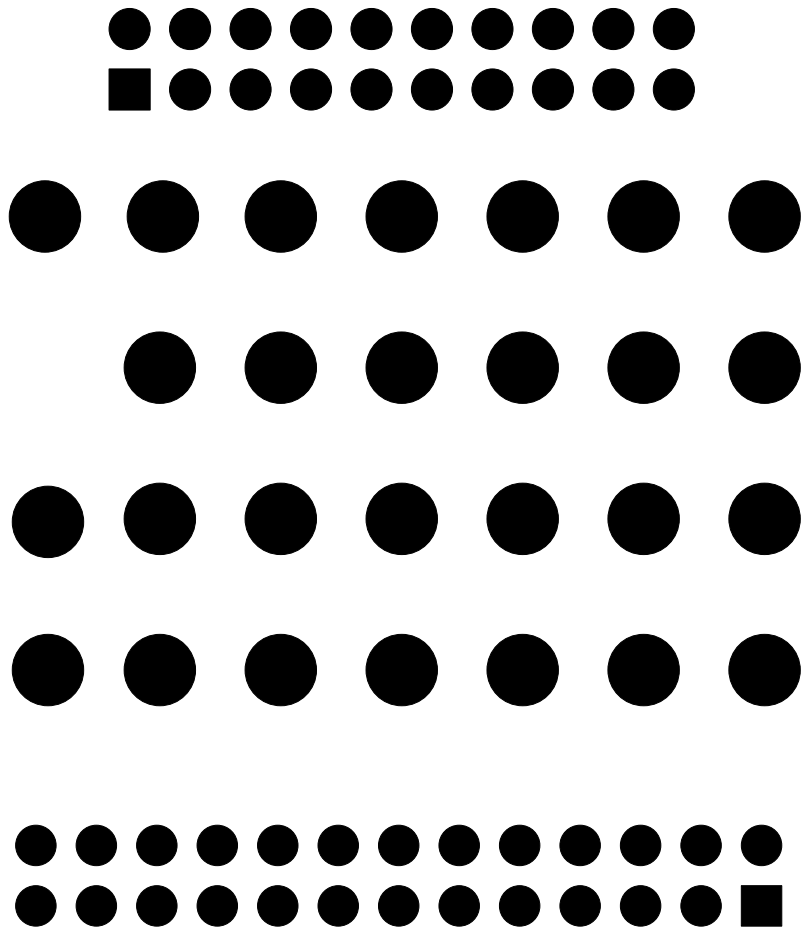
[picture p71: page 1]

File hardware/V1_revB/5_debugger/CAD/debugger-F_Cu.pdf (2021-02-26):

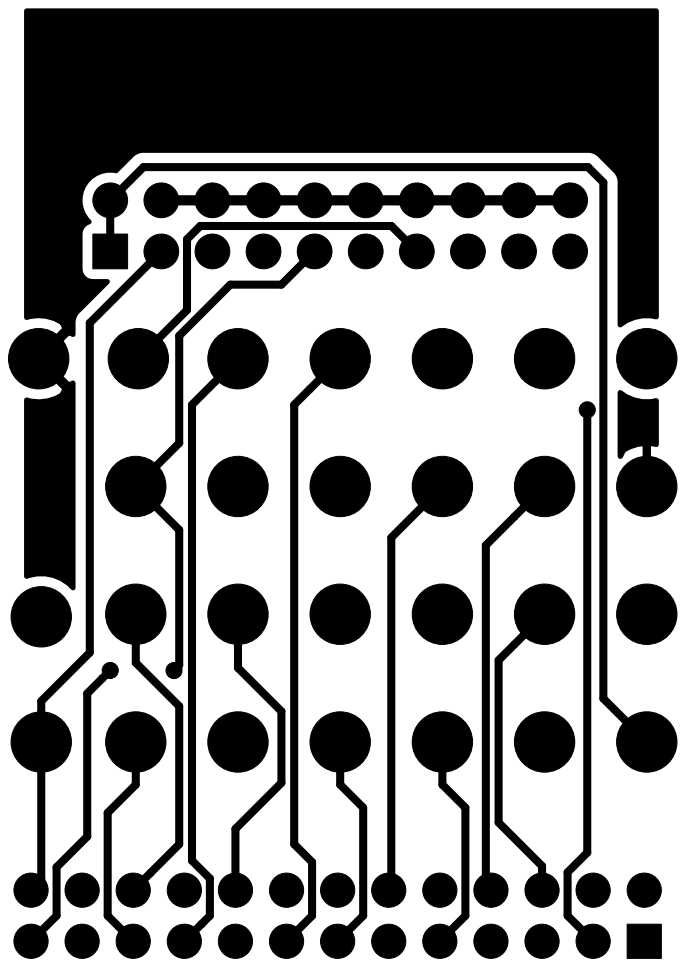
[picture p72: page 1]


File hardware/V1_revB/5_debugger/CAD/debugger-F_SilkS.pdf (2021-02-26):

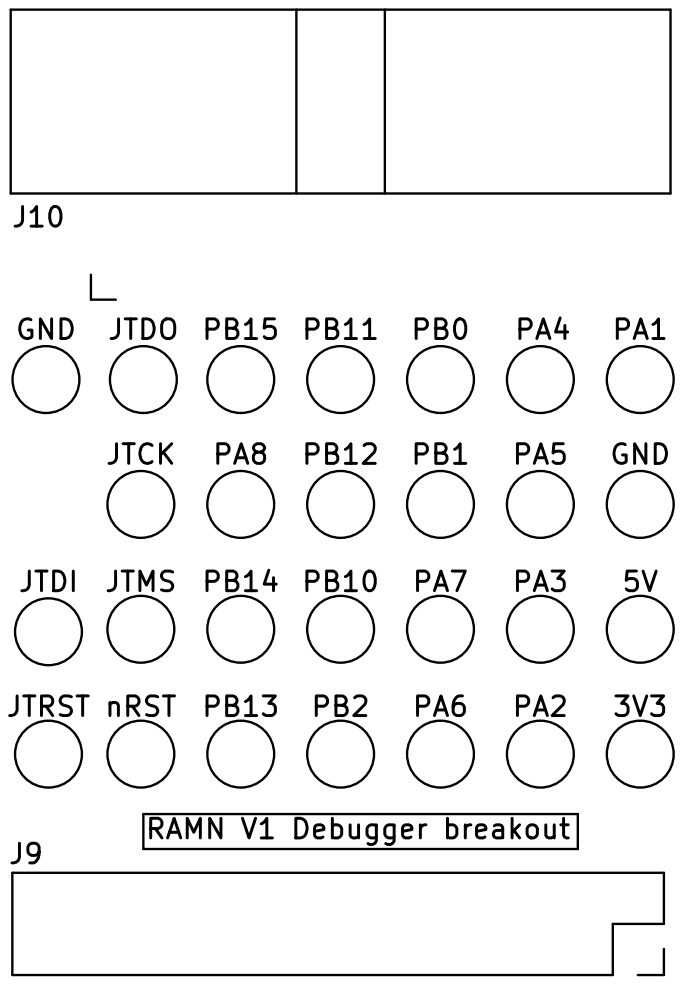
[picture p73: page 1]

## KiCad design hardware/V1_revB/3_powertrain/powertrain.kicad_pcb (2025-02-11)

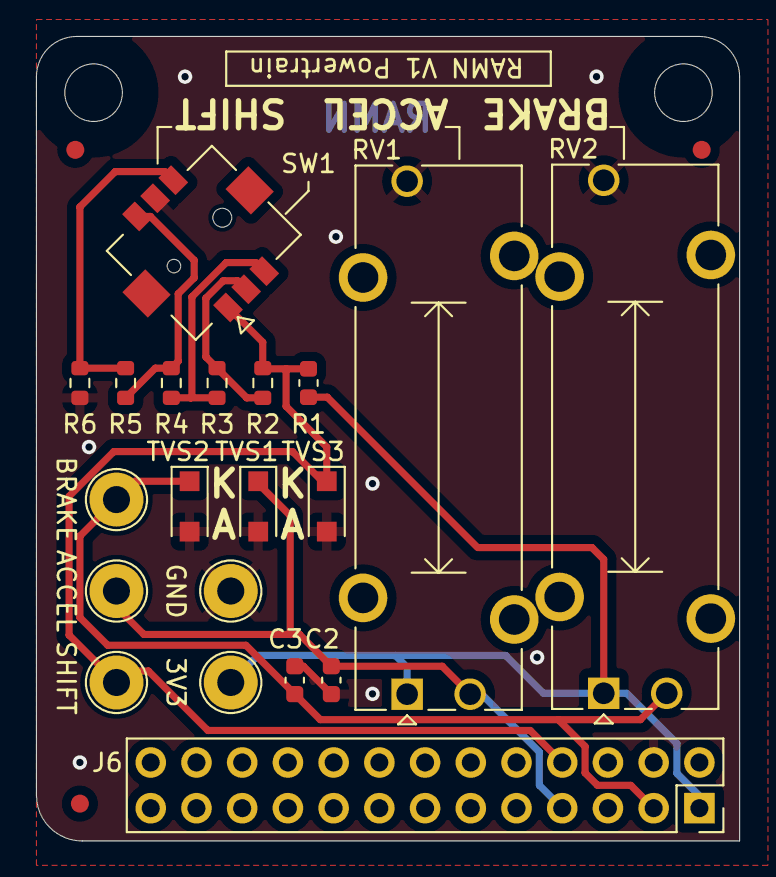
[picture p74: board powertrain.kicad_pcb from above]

Board: 2 copper layers, 39.1 x 44.7 mm, 25 parts (0 on the bottom side), 9 nets.

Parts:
3V3: TestPoint; TestPoint_Loop_D2.54mm_Drill1.5mm_Beaded
ACCEL: TestPoint; TestPoint_Loop_D2.54mm_Drill1.5mm_Beaded
BRAKE: TestPoint; TestPoint_Loop_D2.54mm_Drill1.5mm_Beaded
C2, C3: 100nF; C_0603_1608Metric
FID1, FID2, FID3: Fiducial; Fiducial_1mm_Mask2mm
GND: TestPoint; TestPoint_Loop_D2.54mm_Drill1.5mm_Beaded
H1, H2: MountingHole; MountingHole_3.2mm_M3_ISO7380
J6: PinSocket_2x13_P2.54mm_Vertical
R1, R2, R3, R4, R5, R6: 10k; R_0603_1608Metric
RV1, RV2: R_POT_TRIM_US; Potentiometer_Bourns_PTA1543_Single_Slide
SHIFT: TestPoint; TestPoint_Loop_D2.54mm_Drill1.5mm_Beaded
SW1: SKRHADE010
TVS1, TVS2, TVS3: D_TVS; D_SOD-123F

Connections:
/3V3_ECU: 3V3.1, J6.1, R1.1, RV1.1, RV2.1
Accel: ACCEL.1, C2.1, J6.7, RV1.2, TVS1.1
Brake: BRAKE.1, C3.1, J6.3, RV2.2, TVS2.1
GND: C2.2, C3.2, GND.1, J6.4, R6.2, RV1.3, RV2.3, SW1.5, TVS1.2, TVS2.2, TVS3.2
JOYSTICK: J6.8, R1.2, R2.1, SHIFT.1, SW1.1, TVS3.1
unnamed: R2.2, R3.1, SW1.2
unnamed: R3.2, R4.1, SW1.3
unnamed: R4.2, R5.1, SW1.4
unnamed: R5.2, R6.1, SW1.6

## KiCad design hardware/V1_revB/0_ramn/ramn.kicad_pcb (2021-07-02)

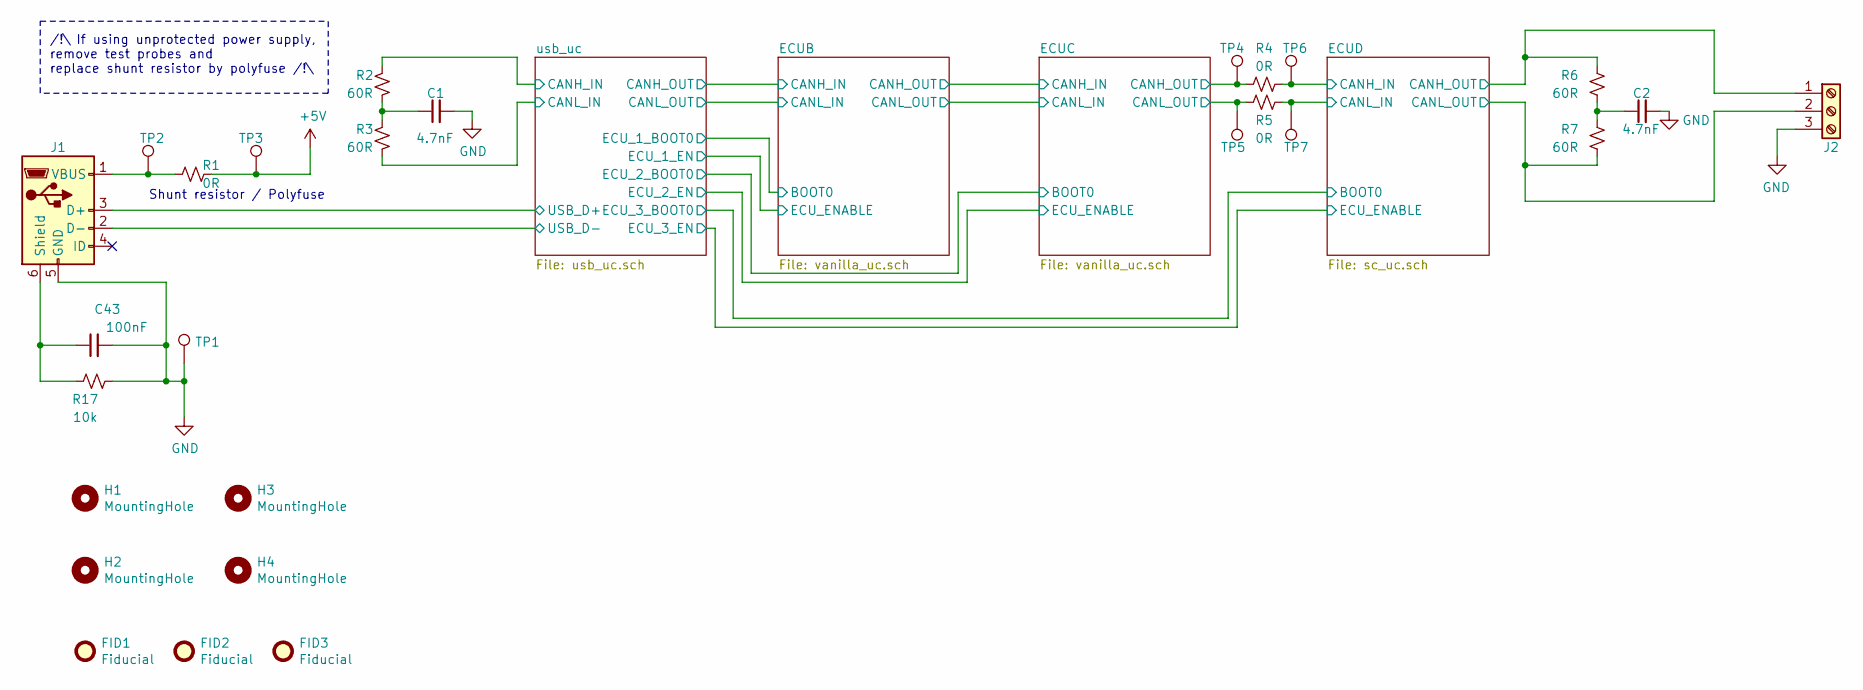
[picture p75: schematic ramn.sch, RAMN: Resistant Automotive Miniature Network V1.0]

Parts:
C1, C2: 4.7nF; C_0603_1608Metric
C43: 100nF; C_0603_1608Metric
FID1, FID2, FID3: Fiducial; Fiducial_1mm_Mask2mm
H1, H2, H3, H4: MountingHole; MountingHole_3.2mm_M3_ISO7380
J1: USB_C_Micro; USB_Micro-B_Wuerth_629105150521
J2: Screw_Terminal_01x03; TerminalBlock_Phoenix_PTSM-0,5-3-2.5-V-THR_1x03_P2.50mm_Ver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
R1, R4, R5: 0R; R_0603_1608Metric
R2, R3, R6, R7: 60R; R_0603_1608Metric
R17: 10k; R_0603_1608Metric
TP1, TP2, TP3, TP4, TP5, TP6, TP7: TestPoint_Loop_D2.54mm_Drill1.5mm_Beaded

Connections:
+5V: R1.1, TP3.1; also elsewhere on the board
/ECUB/CANH_IN: R2.1, R4.2, TP4.1; also elsewhere on the board
/ECUB/CANL_IN: R3.2, R5.2, TP5.1; also elsewhere on the board
/ECUD/CANH_IN: J2.1, R4.1, R6.1, TP6.1; also elsewhere on the board
/ECUD/CANL_IN: J2.2, R5.1, R7.2, TP7.1; also elsewhere on the board
/usb_uc/USB_D+: J1.3 (D+); also elsewhere on the board
/usb_uc/USB_D-: J1.2 (D-); also elsewhere on the board
GND: C1.2, C2.2, C43.2, J1.5 (GND), J2.3, R17.2, TP1.1; also elsewhere on the board
unnamed: C1.1, R2.2, R3.1
unnamed: C2.1, R6.2, R7.1
unnamed: C43.1, J1.6 (Shield), R17.1
unnamed: J1.1 (VBUS), R1.2, TP2.1

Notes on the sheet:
/!\ If using unprotected power supply, remove test probes and replace shunt resistor by polyfuse /!\
Shunt resistor / Polyfuse

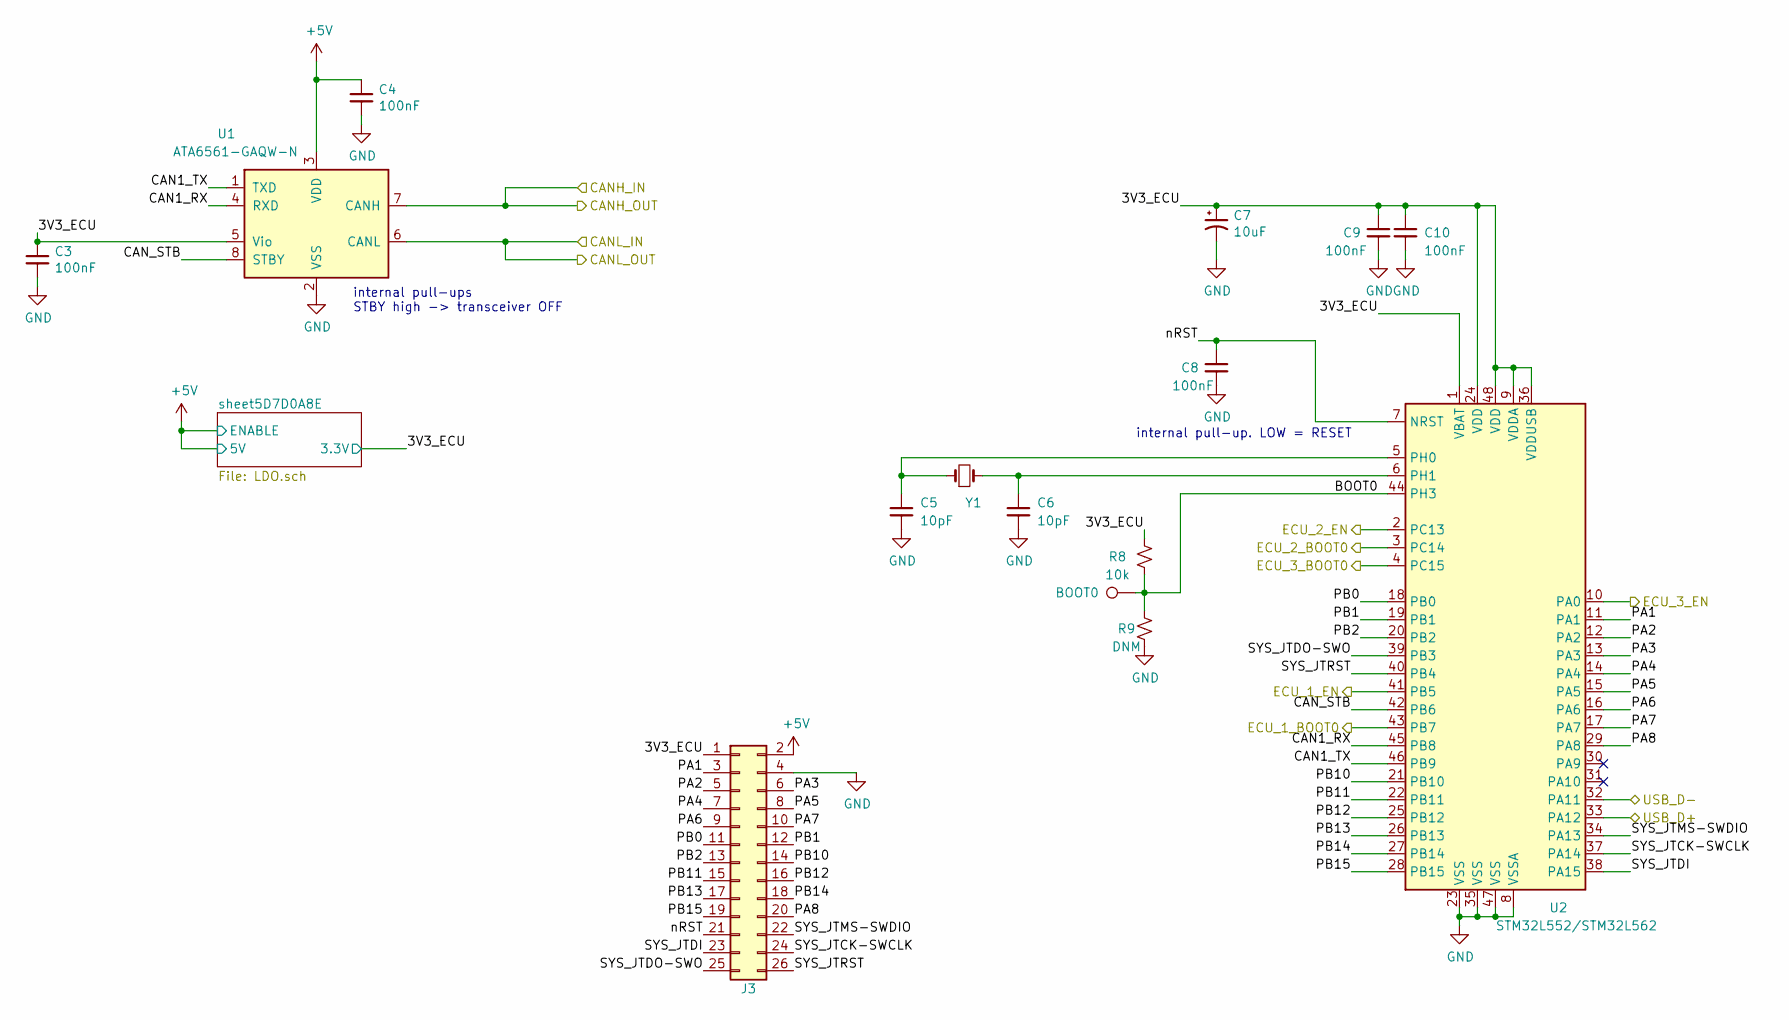
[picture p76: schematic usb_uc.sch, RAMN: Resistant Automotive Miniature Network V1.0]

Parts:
BOOT0: TestPoint_Pad_D1.0mm
C3, C4, C8, C9, C10: 100nF; C_0603_1608Metric
C5, C6: 10pF; C_0603_1608Metric
C7: 10uF; C_1206_3216Metric
J3: PinSocket_2x13_P2.54mm_Vertical
R8: 10k; R_0603_1608Metric
R9: DNM; R_0603_1608Metric
U1: ATA6561-GAQW-N; SOIC-8_3.9x4.9mm_P1.27mm
U2: STM32L552/STM32L562; LQFP-48_7x7mm_P0.5mm
Y1: NX3225GD-8MHZ-STD-CRA-3; SMD-2_3.2x2.5mm

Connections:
+5V: C4.1, J3.2, U1.3 (VDD); also elsewhere on the board
/ECUB/BOOT0: U2.43 (PB7); also elsewhere on the board
/ECUB/CANH_IN: U1.7 (CANH); also elsewhere on the board
/ECUB/CANL_IN: U1.6 (CANL); also elsewhere on the board
/ECUC/BOOT0: U2.3 (PC14); also elsewhere on the board
/ECUD/BOOT0: U2.4 (PC15); also elsewhere on the board
/usb_uc/3V3_ECU: C3.1, C7.1, C9.1, C10.1, J3.1, R8.1, U1.5 (Vio), U2.1 (VBAT), U2.9 (VDDA), U2.24 (VDD), U2.36 (VDDUSB), U2.48 (VDD); also elsewhere on the board
/usb_uc/BOOT0: BOOT0.1, R8.2, R9.1, U2.44 (PH3)
/usb_uc/CAN1_RX: U1.4 (RXD), U2.45 (PB8)
/usb_uc/CAN1_TX: U1.1 (TXD), U2.46 (PB9)
/usb_uc/CAN_STB: U1.8 (STBY), U2.42 (PB6)
/usb_uc/ECU_1_EN: U2.41 (PB5); also elsewhere on the board
/usb_uc/ECU_2_EN: U2.2 (PC13); also elsewhere on the board
/usb_uc/ECU_3_EN: U2.10 (PA0); also elsewhere on the board
/usb_uc/PA1: J3.3, U2.11 (PA1)
/usb_uc/PA2: J3.5, U2.12 (PA2)
/usb_uc/PA3: J3.6, U2.13 (PA3)
/usb_uc/PA4: J3.7, U2.14 (PA4)
/usb_uc/PA5: J3.8, U2.15 (PA5)
/usb_uc/PA6: J3.9, U2.16 (PA6)
/usb_uc/PA7: J3.10, U2.17 (PA7)
/usb_uc/PA8: J3.20, U2.29 (PA8)
/usb_uc/PB0: J3.11, U2.18 (PB0)
/usb_uc/PB1: J3.12, U2.19 (PB1)
/usb_uc/PB2: J3.13, U2.20 (PB2)
/usb_uc/PB10: J3.14, U2.21 (PB10)
/usb_uc/PB11: J3.15, U2.22 (PB11)
/usb_uc/PB12: J3.16, U2.25 (PB12)
/usb_uc/PB13: J3.17, U2.26 (PB13)
/usb_uc/PB14: J3.18, U2.27 (PB14)
/usb_uc/PB15: J3.19, U2.28 (PB15)
/usb_uc/SYS_JTCK-SWCLK: J3.24, U2.37 (PA14)
/usb_uc/SYS_JTDI: J3.23, U2.38 (PA15)
/usb_uc/SYS_JTDO-SWO: J3.25, U2.39 (PB3)
/usb_uc/SYS_JTMS-SWDIO: J3.22, U2.34 (PA13)
/usb_uc/SYS_JTRST: J3.26, U2.40 (PB4)
/usb_uc/USB_D+: U2.33 (PA12); also elsewhere on the board
/usb_uc/USB_D-: U2.32 (PA11); also elsewhere on the board
/usb_uc/nRST: C8.1, J3.21, U2.7 (NRST)
GND: C3.2, C4.2, C5.2, C6.2, C7.2, C8.2, C9.2, C10.2, J3.4, R9.2, U1.2 (VSS), U2.8 (VSSA), U2.23 (VSS), U2.35 (VSS), U2.47 (VSS); also elsewhere on the board
unnamed: C5.1, U2.5 (PH0), Y1.1
unnamed: C6.1, U2.6 (PH1), Y1.2

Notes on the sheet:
internal pull-ups STBY high -> transceiver OFF
internal pull-up. LOW = RESET

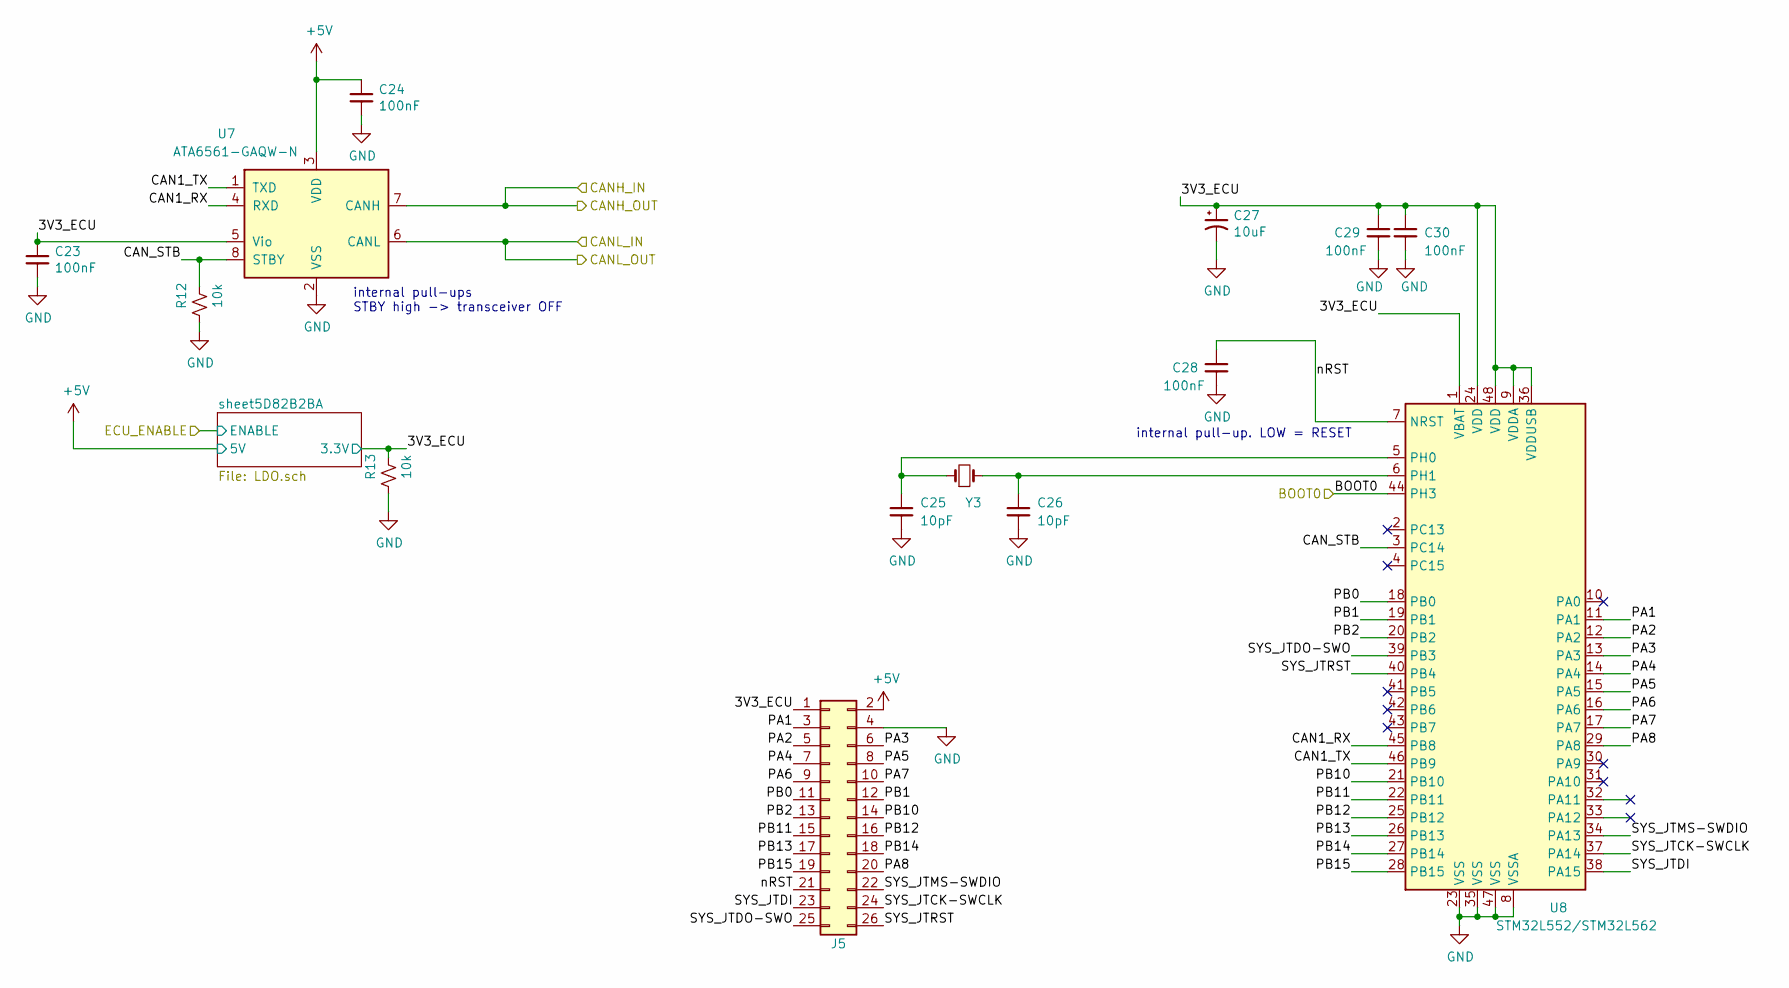
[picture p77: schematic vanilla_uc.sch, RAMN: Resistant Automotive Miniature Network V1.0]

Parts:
C13, C14, C18, C19, C20: 100nF; C_0603_1608Metric
C15, C16: 10pF; C_0603_1608Metric
C17: 10uF; C_1206_3216Metric
J4: PinSocket_2x13_P2.54mm_Vertical
R10, R11: 10k; R_0603_1608Metric
U4: ATA6561-GAQW-N; SOIC-8_3.9x4.9mm_P1.27mm
U5: STM32L552/STM32L562; LQFP-48_7x7mm_P0.5mm
Y2: NX3225GD-8MHZ-STD-CRA-3; SMD-2_3.2x2.5mm

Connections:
+5V: C14.1, J4.2, U4.3 (VDD); also elsewhere on the board
/ECUB/3V3_ECU: C13.1, C17.1, C19.1, C20.1, J4.1, R11.1, U4.5 (Vio), U5.1 (VBAT), U5.9 (VDDA), U5.24 (VDD), U5.36 (VDDUSB), U5.48 (VDD); also elsewhere on the board
/ECUB/BOOT0: U5.44 (PH3); also elsewhere on the board
/ECUB/CAN1_RX: U4.4 (RXD), U5.45 (PB8)
/ECUB/CAN1_TX: U4.1 (TXD), U5.46 (PB9)
/ECUB/CANH_IN: U4.7 (CANH); also elsewhere on the board
/ECUB/CANL_IN: U4.6 (CANL); also elsewhere on the board
/ECUB/CAN_STB: R10.1, U4.8 (STBY), U5.3 (PC14)
/ECUB/PA1: J4.3, U5.11 (PA1)
/ECUB/PA2: J4.5, U5.12 (PA2)
/ECUB/PA3: J4.6, U5.13 (PA3)
/ECUB/PA4: J4.7, U5.14 (PA4)
/ECUB/PA5: J4.8, U5.15 (PA5)
/ECUB/PA6: J4.9, U5.16 (PA6)
/ECUB/PA7: J4.10, U5.17 (PA7)
/ECUB/PA8: J4.20, U5.29 (PA8)
/ECUB/PB0: J4.11, U5.18 (PB0)
/ECUB/PB1: J4.12, U5.19 (PB1)
/ECUB/PB2: J4.13, U5.20 (PB2)
/ECUB/PB10: J4.14, U5.21 (PB10)
/ECUB/PB11: J4.15, U5.22 (PB11)
/ECUB/PB12: J4.16, U5.25 (PB12)
/ECUB/PB13: J4.17, U5.26 (PB13)
/ECUB/PB14: J4.18, U5.27 (PB14)
/ECUB/PB15: J4.19, U5.28 (PB15)
/ECUB/SYS_JTCK-SWCLK: J4.24, U5.37 (PA14)
/ECUB/SYS_JTDI: J4.23, U5.38 (PA15)
/ECUB/SYS_JTDO-SWO: J4.25, U5.39 (PB3)
/ECUB/SYS_JTMS-SWDIO: J4.22, U5.34 (PA13)
/ECUB/SYS_JTRST: J4.26, U5.40 (PB4)
/ECUB/nRST: C18.1, J4.21, U5.7 (NRST)
GND: C13.2, C14.2, C15.2, C16.2, C17.2, C18.2, C19.2, C20.2, J4.4, R10.2, R11.2, U4.2 (VSS), U5.8 (VSSA), U5.23 (VSS), U5.35 (VSS), U5.47 (VSS); also elsewhere on the board
unnamed: C15.1, U5.5 (PH0), Y2.1
unnamed: C16.1, U5.6 (PH1), Y2.2

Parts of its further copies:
C23, C24, C28, C29, C30: 100nF; C_0603_1608Metric
C25, C26: 10pF; C_0603_1608Metric
C27: 10uF; C_1206_3216Metric
J5: PinSocket_2x13_P2.54mm_Vertical
R12, R13: 10k; R_0603_1608Metric
U7: ATA6561-GAQW-N; SOIC-8_3.9x4.9mm_P1.27mm
Y3: NX3225GD-8MHZ-STD-CRA-3; SMD-2_3.2x2.5mm

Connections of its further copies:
+5V: C24.1, J5.2, U7.3 (VDD); also elsewhere on the board
/ECUB/CANH_IN: U7.7 (CANH); also elsewhere on the board
/ECUB/CANL_IN: U7.6 (CANL); also elsewhere on the board
/ECUC/3V3_ECU: C23.1, C27.1, C29.1, C30.1, J5.1, R13.1, U7.5 (Vio); also elsewhere on the board
/ECUC/CAN1_RX: U7.4 (RXD); also elsewhere on the board
/ECUC/CAN1_TX: U7.1 (TXD); also elsewhere on the board
/ECUC/CAN_STB: R12.1, U7.8 (STBY); also elsewhere on the board
/ECUC/PA1: J5.3; also elsewhere on the board
/ECUC/PA2: J5.5; also elsewhere on the board
/ECUC/PA3: J5.6; also elsewhere on the board
/ECUC/PA4: J5.7; also elsewhere on the board
/ECUC/PA5: J5.8; also elsewhere on the board
/ECUC/PA6: J5.9; also elsewhere on the board
/ECUC/PA7: J5.10; also elsewhere on the board
/ECUC/PA8: J5.20; also elsewhere on the board
/ECUC/PB0: J5.11; also elsewhere on the board
/ECUC/PB1: J5.12; also elsewhere on the board
/ECUC/PB2: J5.13; also elsewhere on the board
/ECUC/PB10: J5.14; also elsewhere on the board
/ECUC/PB11: J5.15; also elsewhere on the board
/ECUC/PB12: J5.16; also elsewhere on the board
/ECUC/PB13: J5.17; also elsewhere on the board
/ECUC/PB14: J5.18; also elsewhere on the board
/ECUC/PB15: J5.19; also elsewhere on the board
/ECUC/SYS_JTCK-SWCLK: J5.24; also elsewhere on the board
/ECUC/SYS_JTDI: J5.23; also elsewhere on the board
/ECUC/SYS_JTDO-SWO: J5.25; also elsewhere on the board
/ECUC/SYS_JTMS-SWDIO: J5.22; also elsewhere on the board
/ECUC/SYS_JTRST: J5.26; also elsewhere on the board
/ECUC/nRST: C28.1, J5.21; also elsewhere on the board
GND: C23.2, C24.2, C25.2, C26.2, C27.2, C28.2, C29.2, C30.2, J5.4, R12.2, R13.2, U7.2 (VSS); also elsewhere on the board
unnamed 130: C25.1, Y3.1; also elsewhere on the board
unnamed 131: C26.1, Y3.2; also elsewhere on the board

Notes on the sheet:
internal pull-ups STBY high -> transceiver OFF
internal pull-up. LOW = RESET

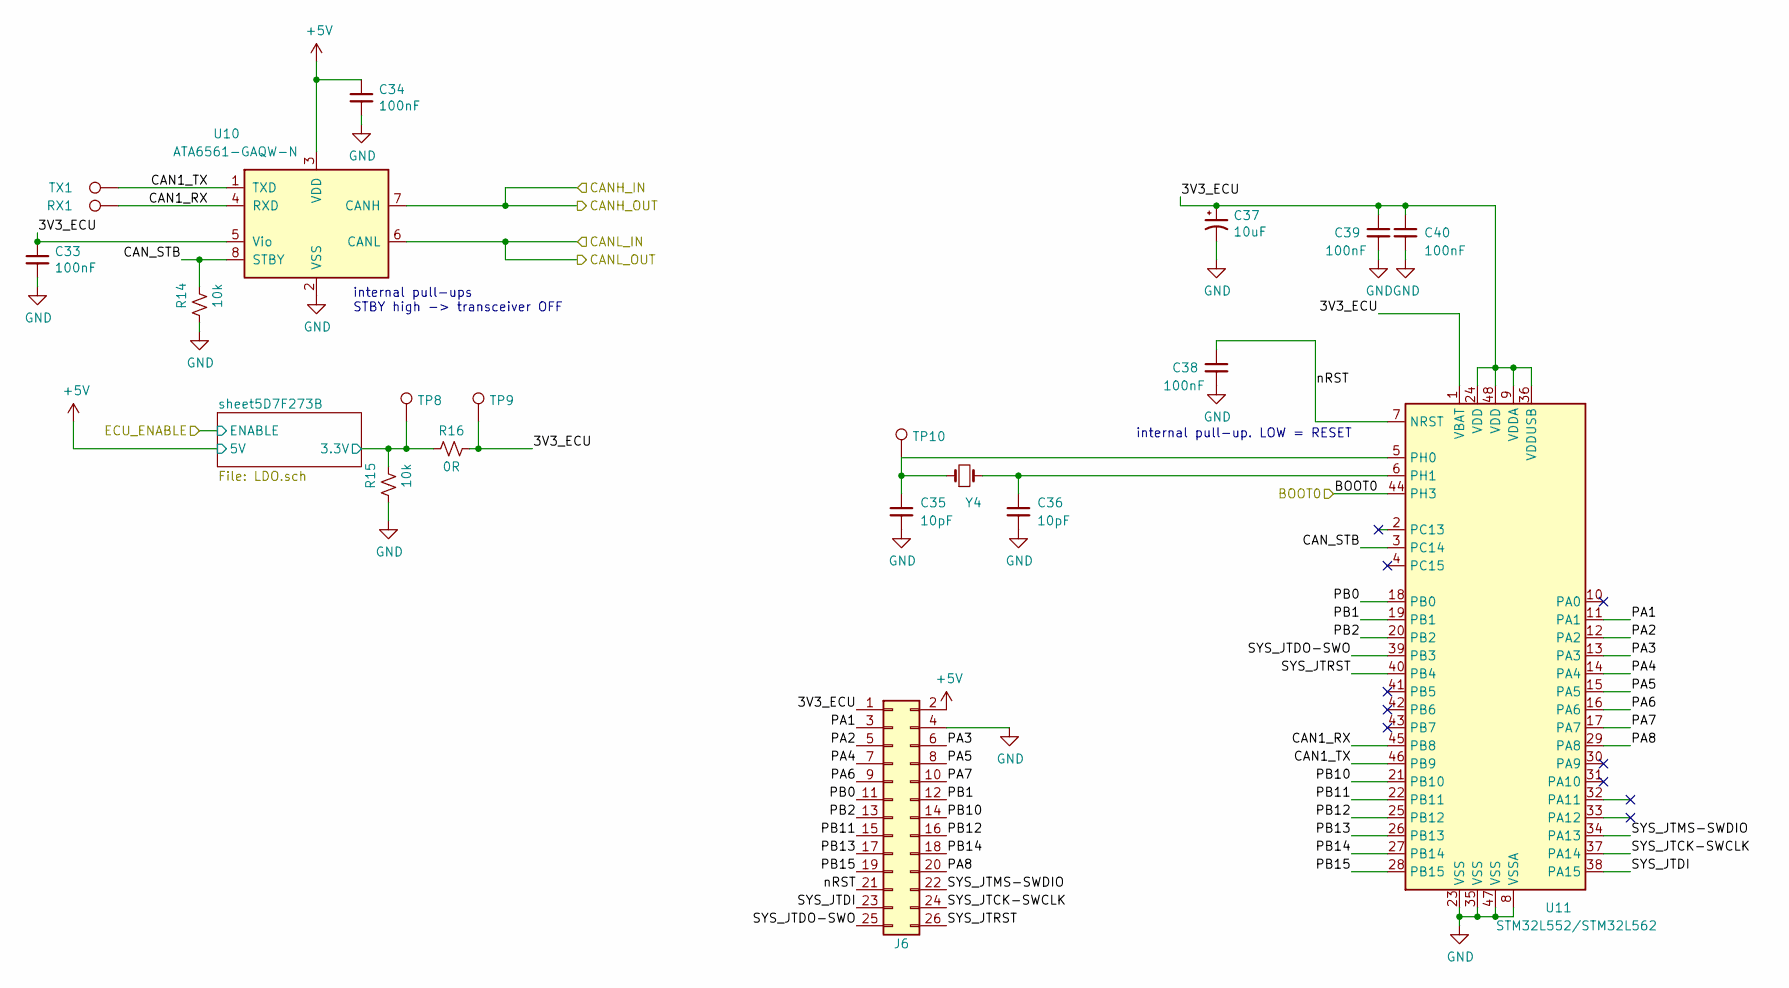
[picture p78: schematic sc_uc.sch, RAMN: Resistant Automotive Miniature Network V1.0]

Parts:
C33, C34, C38, C39, C40: 100nF; C_0603_1608Metric
C35, C36: 10pF; C_0603_1608Metric
C37: 10uF; C_1206_3216Metric
J6: PinSocket_2x13_P2.54mm_Vertical
R14, R15: 10k; R_0603_1608Metric
R16: 0R; R_0603_1608Metric
RX1: TestPoint_Pad_D1.0mm
TP8, TP9, TP10: TestPoint_Loop_D2.54mm_Drill1.5mm_Beaded
TX1: TestPoint_Pad_D1.0mm
U10: ATA6561-GAQW-N; SOIC-8_3.9x4.9mm_P1.27mm
U11: STM32L552/STM32L562; LQFP-48_7x7mm_P0.5mm
Y4: NX3225GD-8MHZ-STD-CRA-3; SMD-2_3.2x2.5mm

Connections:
+5V: C34.1, J6.2, U10.3 (VDD); also elsewhere on the board
/ECUD/3V3_ECU: C33.1, C37.1, C39.1, C40.1, J6.1, R16.1, TP9.1, U10.5 (Vio), U11.1 (VBAT), U11.9 (VDDA), U11.24 (VDD), U11.36 (VDDUSB), U11.48 (VDD)
/ECUD/BOOT0: U11.44 (PH3); also elsewhere on the board
/ECUD/CAN1_RX: RX1.1, U10.4 (RXD), U11.45 (PB8); also elsewhere on the board
/ECUD/CAN1_TX: TX1.1, U10.1 (TXD), U11.46 (PB9); also elsewhere on the board
/ECUD/CANH_IN: U10.7 (CANH); also elsewhere on the board
/ECUD/CANL_IN: U10.6 (CANL); also elsewhere on the board
/ECUD/CAN_STB: R14.1, U10.8 (STBY), U11.3 (PC14)
/ECUD/PA1: J6.3, U11.11 (PA1)
/ECUD/PA2: J6.5, U11.12 (PA2)
/ECUD/PA3: J6.6, U11.13 (PA3)
/ECUD/PA4: J6.7, U11.14 (PA4)
/ECUD/PA5: J6.8, U11.15 (PA5)
/ECUD/PA6: J6.9, U11.16 (PA6)
/ECUD/PA7: J6.10, U11.17 (PA7)
/ECUD/PA8: J6.20, U11.29 (PA8)
/ECUD/PB0: J6.11, U11.18 (PB0)
/ECUD/PB1: J6.12, U11.19 (PB1)
/ECUD/PB2: J6.13, U11.20 (PB2)
/ECUD/PB10: J6.14, U11.21 (PB10)
/ECUD/PB11: J6.15, U11.22 (PB11)
/ECUD/PB12: J6.16, U11.25 (PB12)
/ECUD/PB13: J6.17, U11.26 (PB13)
/ECUD/PB14: J6.18, U11.27 (PB14)
/ECUD/PB15: J6.19, U11.28 (PB15)
/ECUD/SYS_JTCK-SWCLK: J6.24, U11.37 (PA14)
/ECUD/SYS_JTDI: J6.23, U11.38 (PA15)
/ECUD/SYS_JTDO-SWO: J6.25, U11.39 (PB3)
/ECUD/SYS_JTMS-SWDIO: J6.22, U11.34 (PA13)
/ECUD/SYS_JTRST: J6.26, U11.40 (PB4)
/ECUD/nRST: C38.1, J6.21, U11.7 (NRST)
/ECUD/sheet5D7F273B/3.3V: R15.1, R16.2, TP8.1; also elsewhere on the board
GND: C33.2, C34.2, C35.2, C36.2, C37.2, C38.2, C39.2, C40.2, J6.4, R14.2, R15.2, U10.2 (VSS), U11.8 (VSSA), U11.23 (VSS), U11.35 (VSS), U11.47 (VSS); also elsewhere on the board
unnamed: C35.1, TP10.1, U11.5 (PH0), Y4.1
unnamed: C36.1, U11.6 (PH1), Y4.2

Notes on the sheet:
internal pull-ups STBY high -> transceiver OFF
internal pull-up. LOW = RESET

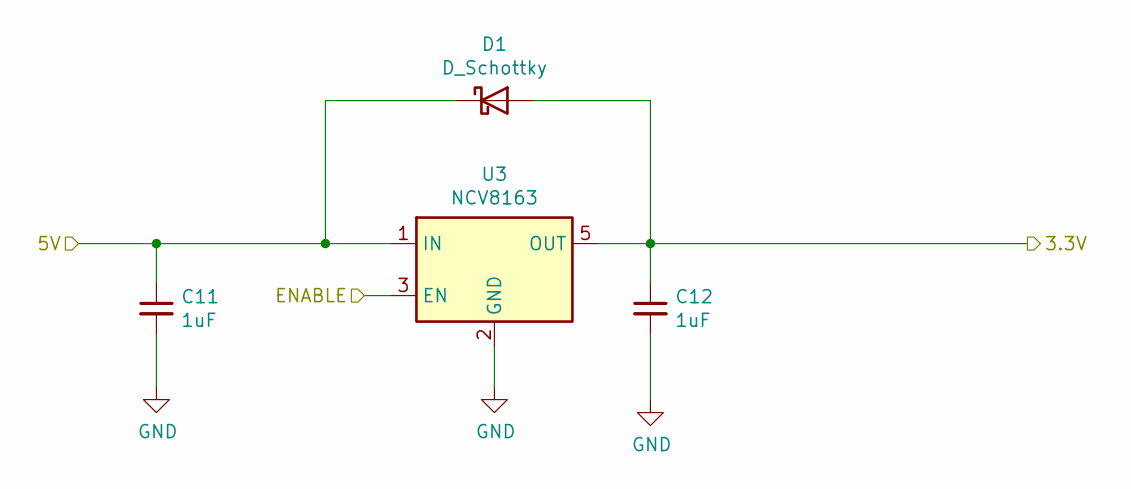
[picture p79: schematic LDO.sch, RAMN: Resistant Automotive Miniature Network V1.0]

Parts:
C11, C12: 1uF; C_1206_3216Metric
D1: D_Schottky; D_SOD-523
U3: NCV8163; TSOP-5_1.65x3.05mm_P0.95mm

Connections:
+5V: C11.1, D1.1 (K), U3.1 (IN), U3.3 (EN); also elsewhere on the board
/usb_uc/3V3_ECU: C12.1, D1.2 (A), U3.5 (OUT); also elsewhere on the board
GND: C11.2, C12.2, U3.2 (GND); also elsewhere on the board

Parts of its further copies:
C21, C22, C31, C32, C41, C42: 1uF; C_1206_3216Metric
D2, D3, D4: D_Schottky; D_SOD-523
U6, U9, U12: NCV8163; TSOP-5_1.65x3.05mm_P0.95mm

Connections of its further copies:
+5V: C21.1, C31.1, C41.1, D2.1 (K), D3.1 (K), D4.1 (K), U6.1 (IN), U9.1 (IN), U12.1 (IN); also elsewhere on the board
/ECUB/3V3_ECU: C22.1, D2.2 (A), U6.5 (OUT); also elsewhere on the board
/ECUC/3V3_ECU: C32.1, D3.2 (A), U9.5 (OUT); also elsewhere on the board
/ECUD/sheet5D7F273B/3.3V: C42.1, D4.2 (A), U12.5 (OUT); also elsewhere on the board
/usb_uc/ECU_1_EN: U6.3 (EN); also elsewhere on the board
/usb_uc/ECU_2_EN: U9.3 (EN); also elsewhere on the board
/usb_uc/ECU_3_EN: U12.3 (EN); also elsewhere on the board
GND: C21.2, C22.2, C31.2, C32.2, C41.2, C42.2, U6.2 (GND), U9.2 (GND), U12.2 (GND); also elsewhere on the board

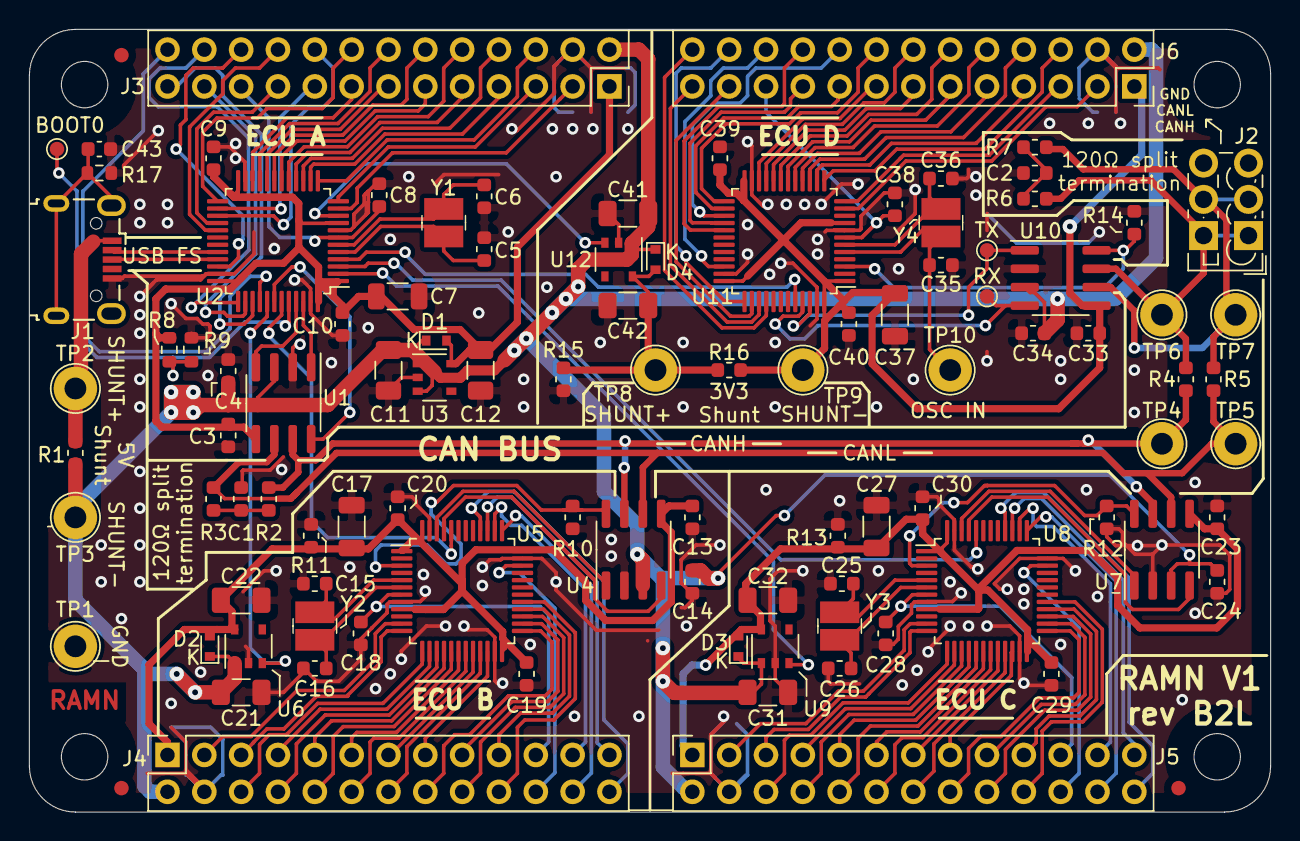
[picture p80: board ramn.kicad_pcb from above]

Board: 2 copper layers, 85.6 x 54.0 mm, 106 parts (0 on the bottom side), 136 nets.

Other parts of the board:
RX: TestPoint_Pad_D1.0mm
TX: TestPoint_Pad_D1.0mm
U8: STM32L443CCTx; LQFP-48_7x7mm_P0.5mm

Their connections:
/ECUC/3V3_ECU: U8.1, U8.9, U8.24, U8.36, U8.48; also elsewhere on the board
/ECUC/BOOT0: U8.44; also elsewhere on the board
/ECUC/CAN1_RX: U8.45; also elsewhere on the board
/ECUC/CAN1_TX: U8.46; also elsewhere on the board
/ECUC/CAN_STB: U8.3; also elsewhere on the board
/ECUC/PA1: U8.11; also elsewhere on the board
/ECUC/PA2: U8.12; also elsewhere on the board
/ECUC/PA3: U8.13; also elsewhere on the board
/ECUC/PA4: U8.14; also elsewhere on the board
/ECUC/PA5: U8.15; also elsewhere on the board
/ECUC/PA6: U8.16; also elsewhere on the board
/ECUC/PA7: U8.17; also elsewhere on the board
/ECUC/PA8: U8.29; also elsewhere on the board
/ECUC/PB0: U8.18; also elsewhere on the board
/ECUC/PB1: U8.19; also elsewhere on the board
/ECUC/PB2: U8.20; also elsewhere on the board
/ECUC/PB10: U8.21; also elsewhere on the board
/ECUC/PB11: U8.22; also elsewhere on the board
/ECUC/PB12: U8.25; also elsewhere on the board
/ECUC/PB13: U8.26; also elsewhere on the board
/ECUC/PB14: U8.27; also elsewhere on the board
/ECUC/PB15: U8.28; also elsewhere on the board
/ECUC/SYS_JTCK-SWCLK: U8.37; also elsewhere on the board
/ECUC/SYS_JTDI: U8.38; also elsewhere on the board
/ECUC/SYS_JTDO-SWO: U8.39; also elsewhere on the board
/ECUC/SYS_JTMS-SWDIO: U8.34; also elsewhere on the board
/ECUC/SYS_JTRST: U8.40; also elsewhere on the board
/ECUC/nRST: U8.7; also elsewhere on the board
/ECUD/CAN1_RX: RX.1; also elsewhere on the board
/ECUD/CAN1_TX: TX.1; also elsewhere on the board
GND: U8.8, U8.23, U8.35, U8.47; also elsewhere on the board
unnamed 130: U8.5; also elsewhere on the board
unnamed 131: U8.6; also elsewhere on the board

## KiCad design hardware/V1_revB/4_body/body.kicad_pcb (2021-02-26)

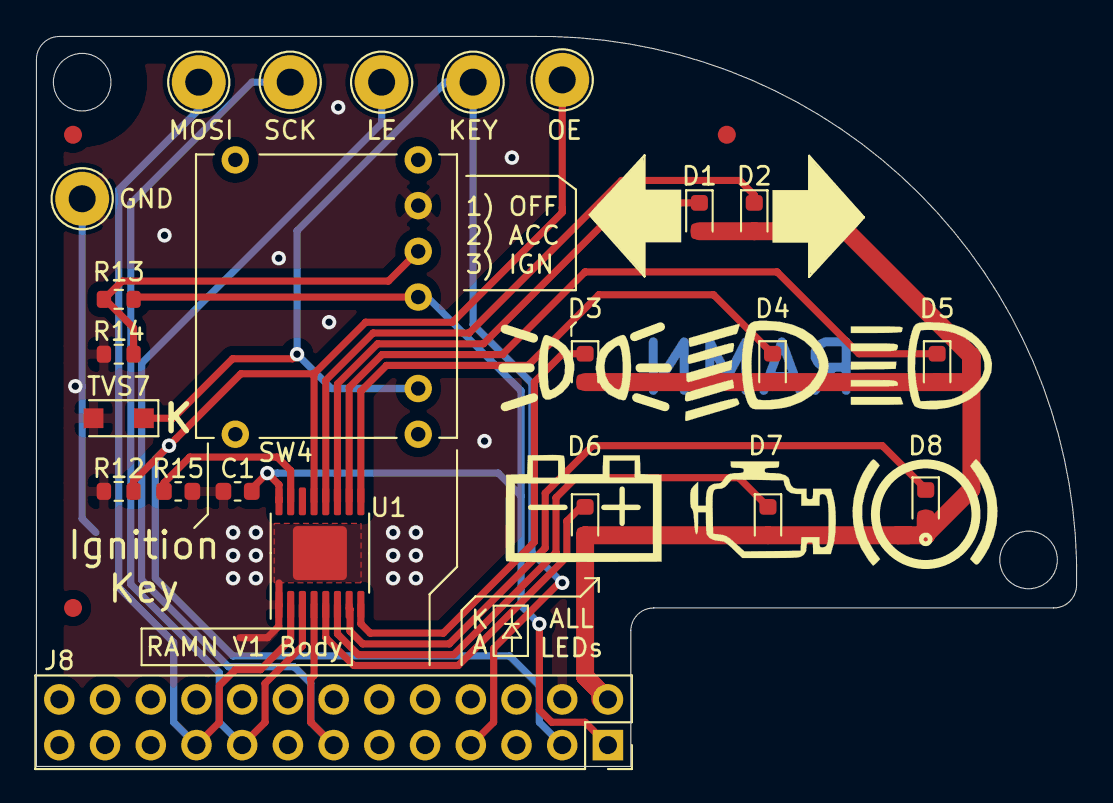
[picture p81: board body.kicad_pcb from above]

Board: 2 copper layers, 57.8 x 40.6 mm, 28 parts (0 on the bottom side), 18 nets.

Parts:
C1: 100nF; C_0603_1608Metric
D1, D2, D3, D4, D5, D6, D7, D8: LED; LED_0603_1608Metric
FID1, FID2, FID3: Fiducial; Fiducial_1mm_Mask2mm
GND: TestPoint; TestPoint_Loop_D2.54mm_Drill1.5mm_Beaded
H5, H6: MountingHole; MountingHole_3.2mm_M3_ISO7380
J8: PinSocket_2x13_P2.54mm_Vertical
KEY: TestPoint; TestPoint_Loop_D2.54mm_Drill1.5mm_Beaded
LE: TestPoint; TestPoint_Loop_D2.54mm_Drill1.5mm_Beaded
MOSI: TestPoint; TestPoint_Loop_D2.54mm_Drill1.5mm_Beaded
OE: TestPoint; TestPoint_Loop_D2.54mm_Drill1.5mm_Beaded
R12, R13, R14: 10k; R_0603_1608Metric
R15: 1.8k; R_0603_1608Metric
SCK: TestPoint; TestPoint_Loop_D2.54mm_Drill1.5mm_Beaded
SW4: SK14EG13
TVS7: D_TVS; D_SOD-123F
U1: STP08CP05XT; HTSSOP-16-1EP_4.4x5mm_P0.65mm_EP3x3mm

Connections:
+5V: D1.2, D2.2, D3.2, D4.2, D5.2, D6.2, D7.2, D8.2, J8.2
/3V3_ECU: C1.1, J8.1, R13.2, SW4.3, U1.16
GND: C1.2, GND.1, J8.4, R12.1, R14.1, R15.1, SW4.1, TVS7.2, U1.1, U1.17
Key: J8.7, KEY.1, SW4.C1, TVS7.1
LE: J8.13, LE.1, U1.4
MOSI: J8.19, MOSI.1, U1.2
unnamed: D1.1, U1.11
unnamed: D2.1, U1.12
unnamed: D3.1, U1.8
unnamed: D4.1, U1.9
unnamed: D5.1, U1.10
unnamed: D6.1, U1.5
unnamed: D7.1, U1.6
unnamed: D8.1, U1.7
unnamed: R13.1, R14.2, SW4.2
unnamed: R15.2, U1.15
OE: J8.3, OE.1, R12.2, U1.13
SCK: J8.17, SCK.1, U1.3

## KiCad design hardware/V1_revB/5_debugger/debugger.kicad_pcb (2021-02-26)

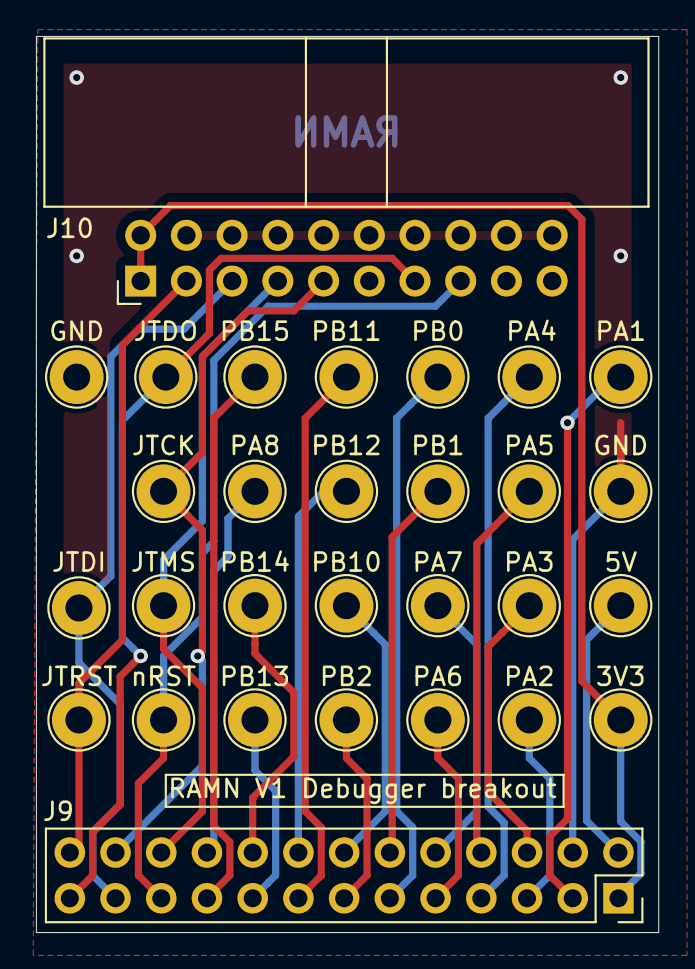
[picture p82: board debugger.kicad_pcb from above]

Board: 2 copper layers, 34.6 x 49.8 mm, 29 parts (0 on the bottom side), 26 nets.

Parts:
3V3, 5V: TestPoint; TestPoint_Loop_D2.54mm_Drill1.5mm_Beaded
GND: TestPoint; TestPoint_Loop_D2.54mm_Drill1.5mm_Beaded
GND#2: TestPoint; TestPoint_Loop_D2.54mm_Drill1.5mm_Beaded
J9: PinSocket_2x13_P2.54mm_Vertical
J10: Conn_ARM_JTAG_SWD_20; IDC-Header_2x10_P2.54mm_Horizontal
JTCK: TestPoint; TestPoint_Loop_D2.54mm_Drill1.5mm_Beaded
JTDI: TestPoint; TestPoint_Loop_D2.54mm_Drill1.5mm_Beaded
JTDO: TestPoint; TestPoint_Loop_D2.54mm_Drill1.5mm_Beaded
JTMS: TestPoint; TestPoint_Loop_D2.54mm_Drill1.5mm_Beaded
JTRST: TestPoint; TestPoint_Loop_D2.54mm_Drill1.5mm_Beaded
PA1, PA2, PA3, PA4, PA5, PA6, PA7, PA8: TestPoint; TestPoint_Loop_D2.54mm_Drill1.5mm_Beaded
PB0, PB1, PB2, PB10, PB11, PB12, PB13, PB14, PB15: TestPoint; TestPoint_Loop_D2.54mm_Drill1.5mm_Beaded
nRST: TestPoint; TestPoint_Loop_D2.54mm_Drill1.5mm_Beaded

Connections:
+5V: 5V.1, J9.2
/3V3_ECU: 3V3.1, J9.1, J10.1, J10.2
/PA1: J9.3, PA1.1
/PA2: J9.5, PA2.1
/PA3: J9.6, PA3.1
/PA4: J9.7, PA4.1
/PA5: J9.8, PA5.1
/PA6: J9.9, PA6.1
/PA7: J9.10, PA7.1
/PA8: J9.20, PA8.1
/PB0: J9.11, PB0.1
/PB1: J9.12, PB1.1
/PB2: J9.13, PB2.1
/PB10: J9.14, PB10.1
/PB11: J9.15, PB11.1
/PB12: J9.16, PB12.1
/PB13: J9.17, PB13.1
/PB14: J9.18, PB14.1
/PB15: J9.19, PB15.1
/SYS_JTCK-SWCLK: J9.24, J10.9, JTCK.1
/SYS_JTDI: J9.23, J10.5, JTDI.1
/SYS_JTDO-SWO: J9.25, J10.13, JTDO.1
/SYS_JTMS-SWDIO: J9.22, J10.7, JTMS.1
/SYS_JTRST: J9.26, J10.3, JTRST.1
/nRST: J9.21, J10.15, nRST.1
GND: GND.1, GND#2.1, J9.4, J10.4, J10.6, J10.8, J10.10, J10.12, J10.14, J10.16, J10.18, J10.20

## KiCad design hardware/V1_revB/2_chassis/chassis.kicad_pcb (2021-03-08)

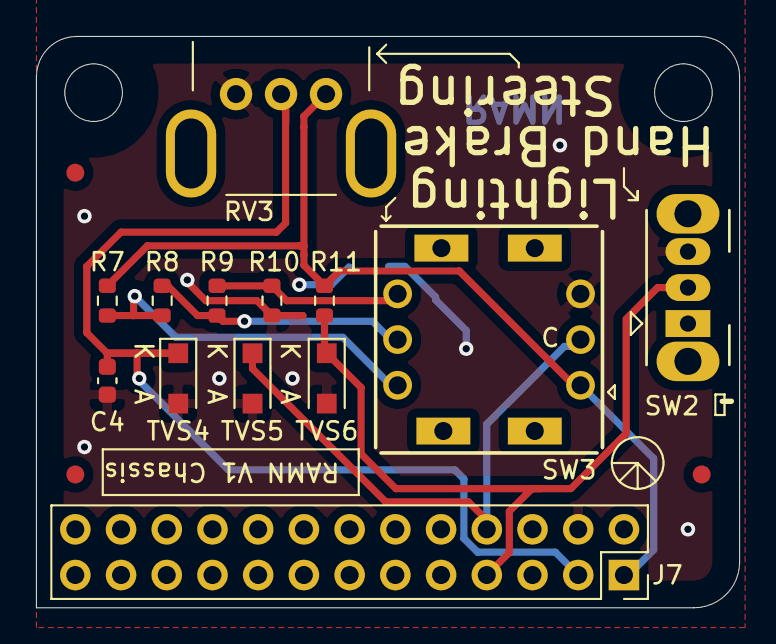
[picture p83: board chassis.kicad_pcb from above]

Board: 2 copper layers, 39.1 x 31.7 mm, 18 parts (0 on the bottom side), 8 nets.

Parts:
C4: 100nF; C_0603_1608Metric
FID1, FID2, FID3: Fiducial; Fiducial_1mm_Mask2mm
H3, H4: MountingHole; MountingHole_3.2mm_M3_ISO7380
J7: PinSocket_2x13_P2.54mm_Vertical
R7, R8, R9, R10, R11: 10k; R_0603_1608Metric
RV3: R_POT_TRIM_US; RK09K1110A2S
SW2: SW_CuK_OS102011MA1QN1_SPDT_Angled
SW3: NKK_NR01; NR01
TVS4, TVS5, TVS6: D_TVS; D_SOD-123F

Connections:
/3V3_ECU: J7.1, R7.1, R11.2, RV3.1, SW3.1
GND: C4.2, J7.4, R10.2, RV3.3, SW2.3, SW3.5, TVS4.2, TVS5.2, TVS6.2
Lamp: J7.8, SW3.3, TVS5.1
unnamed: R7.2, R8.1, SW3.2
unnamed: R8.2, R9.1, SW3.4
unnamed: R9.2, R10.1, SW3.6
SW1: J7.7, R11.1, SW2.2, TVS6.1
Wheel: C4.1, J7.3, RV3.2, TVS4.1

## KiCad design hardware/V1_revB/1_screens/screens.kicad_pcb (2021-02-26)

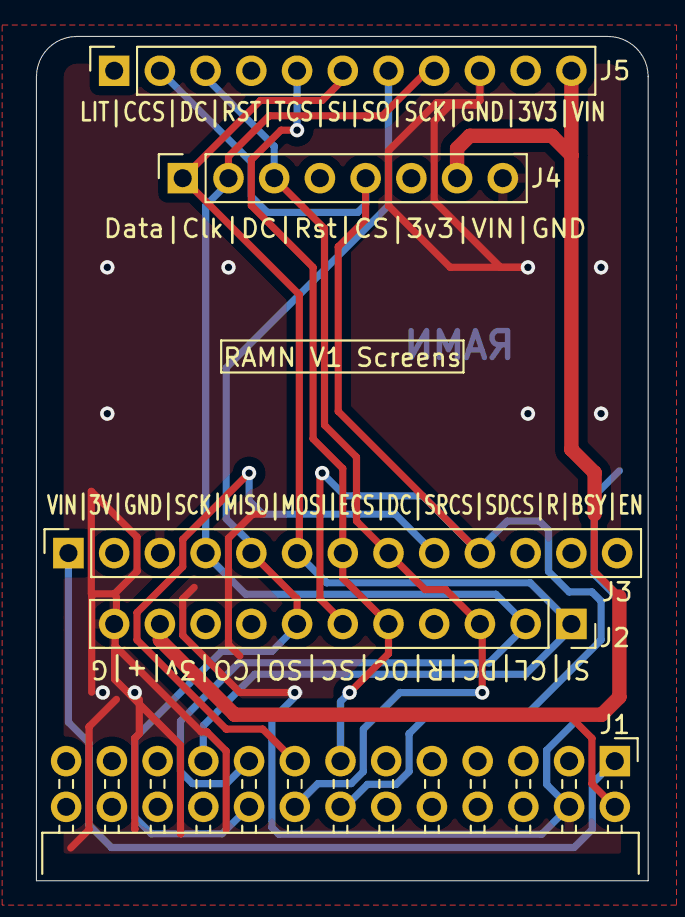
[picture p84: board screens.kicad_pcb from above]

Board: 2 copper layers, 34.0 x 46.9 mm, 5 parts (0 on the bottom side), 10 nets.

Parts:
J1: PinHeader_2x13_P2.54mm_Horizontal
J2: 1431; PinSocket_1x11_P2.54mm_Vertical
J3: 4086; PinSocket_1x13_P2.54mm_Vertical
J4: 326; PinSocket_1x08_P2.54mm_Vertical
J5: 4383; PinSocket_1x11_P2.54mm_Vertical

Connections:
+5V: J1.2, J2.10, J4.7, J5.11
/3V3_ECU: J1.1, J3.1
DC: J1.16, J2.3, J3.8, J4.3, J5.3
GND: J1.4, J2.11, J3.3, J4.8, J5.9
LCD_CS: J1.13, J2.5, J3.7, J5.5
MISO: J1.18, J2.7, J3.5, J5.7
MOSI: J1.19, J2.1, J3.6, J4.1, J5.6
SCK: J1.17, J2.2, J3.4, J4.2, J5.8
SD_CS: J1.14, J2.6, J3.10, J4.5, J5.2
SRAM_CS: J1.15, J3.9

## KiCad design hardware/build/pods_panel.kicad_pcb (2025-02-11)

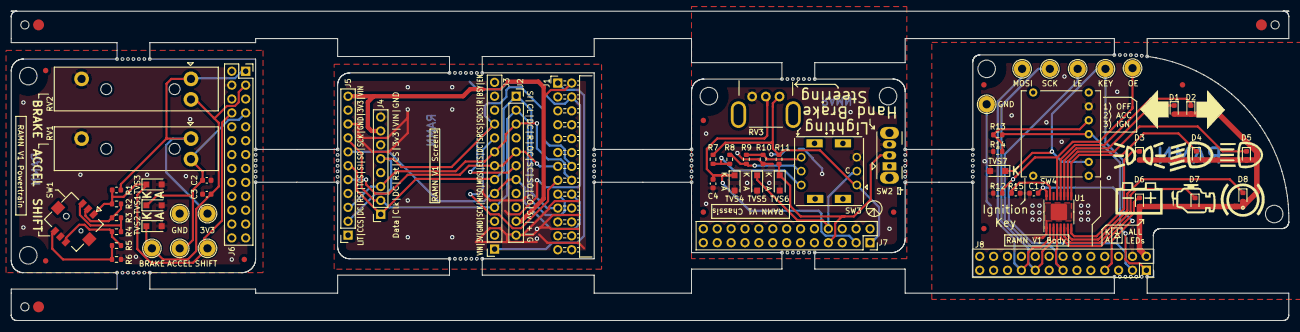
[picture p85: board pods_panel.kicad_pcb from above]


Board: 2 copper layers, 233.6 x 56.6 mm, 183 parts (3 on the bottom side), 45 nets.

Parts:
3V3: TestPoint; TestPoint_Loop_D2.54mm_Drill1.5mm_Beaded
ACCEL: TestPoint; TestPoint_Loop_D2.54mm_Drill1.5mm_Beaded
BRAKE: TestPoint; TestPoint_Loop_D2.54mm_Drill1.5mm_Beaded
C1, C2, C3, C4: 100nF; C_0603_1608Metric
D1, D2, D3, D4, D5, D6, D7, D8: LED; LED_0603_1608Metric
FID1, FID1#2, FID1#3, FID2, FID2#2, FID2#3, FID3, FID3#2, FID3#3: Fiducial; Fiducial_1mm_Mask2mm
GND: TestPoint; TestPoint_Loop_D2.54mm_Drill1.5mm_Beaded
GND#2: TestPoint; TestPoint_Loop_D2.54mm_Drill1.5mm_Beaded
H1, H2, H3, H4, H5, H6: MountingHole; MountingHole_3.2mm_M3_ISO7380
J1: PinHeader_2x13_P2.54mm_Horizontal
J2: 1431; PinSocket_1x11_P2.54mm_Vertical
J3: 4086; PinSocket_1x13_P2.54mm_Vertical
J4: 326; PinSocket_1x08_P2.54mm_Vertical
J5: 4383; PinSocket_1x11_P2.54mm_Vertical
J6, J7, J8: PinSocket_2x13_P2.54mm_Vertical
KEY: TestPoint; TestPoint_Loop_D2.54mm_Drill1.5mm_Beaded
KiKit_FID_B_1, KiKit_FID_B_2, KiKit_FID_B_3: Fiducial
KiKit_FID_T_1, KiKit_FID_T_2, KiKit_FID_T_3: Fiducial
KiKit_MB_1_1, KiKit_MB_1_2, KiKit_MB_1_3, KiKit_MB_1_4, KiKit_MB_1_5, KiKit_MB_1_6, KiKit_MB_1_7, KiKit_MB_2_1, KiKit_MB_2_2, KiKit_MB_2_3, KiKit_MB_2_4, KiKit_MB_2_5, KiKit_MB_2_6, KiKit_MB_2_7, KiKit_MB_3_1, KiKit_MB_3_2, KiKit_MB_3_3, KiKit_MB_3_4, KiKit_MB_3_5, KiKit_MB_3_6, KiKit_MB_3_7, KiKit_MB_4_1, KiKit_MB_4_2, KiKit_MB_4_3, KiKit_MB_4_4, KiKit_MB_4_5, KiKit_MB_4_6, KiKit_MB_4_7, KiKit_MB_5_1, KiKit_MB_5_2, KiKit_MB_5_3, KiKit_MB_5_4, KiKit_MB_5_5, KiKit_MB_5_6, KiKit_MB_5_7, KiKit_MB_6_1, KiKit_MB_6_2, KiKit_MB_6_3, KiKit_MB_6_4, KiKit_MB_6_5, KiKit_MB_6_6, KiKit_MB_6_7, KiKit_MB_7_1, KiKit_MB_7_2, KiKit_MB_7_3, KiKit_MB_7_4, KiKit_MB_7_5, KiKit_MB_7_6, KiKit_MB_7_7, KiKit_MB_8_1, KiKit_MB_8_2, KiKit_MB_8_3, KiKit_MB_8_4, KiKit_MB_8_5, KiKit_MB_8_6, KiKit_MB_8_7, KiKit_MB_9_1, KiKit_MB_9_2, KiKit_MB_9_3, KiKit_MB_9_4, KiKit_MB_9_5, KiKit_MB_9_6, KiKit_MB_9_7, KiKit_MB_10_1, KiKit_MB_10_2, KiKit_MB_10_3, KiKit_MB_10_4, KiKit_MB_10_5, KiKit_MB_10_6, KiKit_MB_10_7, KiKit_MB_11_1, KiKit_MB_11_2, KiKit_MB_11_3, KiKit_MB_11_4, KiKit_MB_11_5, KiKit_MB_11_6, KiKit_MB_11_7, KiKit_MB_12_1, KiKit_MB_12_2, KiKit_MB_12_3, KiKit_MB_12_4, KiKit_MB_12_5, KiKit_MB_12_6, KiKit_MB_12_7, KiKit_MB_13_1, KiKit_MB_13_2, KiKit_MB_13_3, KiKit_MB_13_4, KiKit_MB_13_5, KiKit_MB_13_6, KiKit_MB_13_7, KiKit_MB_14_1, KiKit_MB_14_2, KiKit_MB_14_3, KiKit_MB_14_4, KiKit_MB_14_5, KiKit_MB_14_6, KiKit_MB_14_7: NPTH
KiKit_TO_1, KiKit_TO_2, KiKit_TO_3: NPTH
LE: TestPoint; TestPoint_Loop_D2.54mm_Drill1.5mm_Beaded
MOSI: TestPoint; TestPoint_Loop_D2.54mm_Drill1.5mm_Beaded
OE: TestPoint; TestPoint_Loop_D2.54mm_Drill1.5mm_Beaded
R1, R2, R3, R4, R5, R6, R7, R8, R9, R10, R11, R12, R13, R14: 10k; R_0603_1608Metric
R15: 1.8k; R_0603_1608Metric
RV1, RV2: R_POT_TRIM_US; RS15111A900B
RV3: R_POT_TRIM_US; RK09K1110A2S
SCK: TestPoint; TestPoint_Loop_D2.54mm_Drill1.5mm_Beaded
SHIFT: TestPoint; TestPoint_Loop_D2.54mm_Drill1.5mm_Beaded
SW1: SKRHADE010
SW2: SW_CuK_OS102011MA1QN1_SPDT_Angled
SW3: NKK_NR01; NR01
SW4: SK14EG13
TVS1, TVS2, TVS3, TVS4, TVS5, TVS6, TVS7: D_TVS; D_SOD-123F
U1: STP08CP05XT; HTSSOP-16-1EP_4.4x5mm_P0.65mm_EP3x3mm

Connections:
Board_0-+5V: D1.2, D2.2, D3.2, D4.2, D5.2, D6.2, D7.2, D8.2, J8.2
Board_0-/3V3_ECU: C1.1, J8.1, R13.2, SW4.3, U1.16
Board_0-GND: C1.2, GND.1, J8.4, R12.1, R14.1, R15.1, SW4.1, TVS7.2, U1.1, U1.17
Board_0-Key: J8.7, KEY.1, SW4.C1, TVS7.1
Board_0-LE: J8.13, LE.1, U1.4
Board_0-MOSI: J8.19, MOSI.1, U1.2
Board_0-Net-(D1-Pad1): D1.1, U1.11
Board_0-Net-(D2-Pad1): D2.1, U1.12
Board_0-Net-(D3-Pad1): D3.1, U1.8
Board_0-Net-(D4-Pad1): D4.1, U1.9
Board_0-Net-(D5-Pad1): D5.1, U1.10
Board_0-Net-(D6-Pad1): D6.1, U1.5
Board_0-Net-(D7-Pad1): D7.1, U1.6
Board_0-Net-(D8-Pad1): D8.1, U1.7
Board_0-Net-(R13-Pad1): R13.1, R14.2, SW4.2
Board_0-Net-(R15-Pad2): R15.2, U1.15
Board_0-OE: J8.3, OE.1, R12.2, U1.13
Board_0-SCK: J8.17, SCK.1, U1.3
Board_1-+5V: J1.2, J2.10, J4.7, J5.11
Board_1-/3V3_ECU: J1.1, J3.1
Board_1-DC: J1.16, J2.3, J3.8, J4.3, J5.3
Board_1-GND: J1.4, J2.11, J3.3, J4.8, J5.9
Board_1-LCD_CS: J1.13, J2.5, J3.7, J5.5
Board_1-MISO: J1.18, J2.7, J3.5, J5.7
Board_1-MOSI: J1.19, J2.1, J3.6, J4.1, J5.6
Board_1-SCK: J1.17, J2.2, J3.4, J4.2, J5.8
Board_1-SD_CS: J1.14, J2.6, J3.10, J4.5, J5.2
Board_1-SRAM_CS: J1.15, J3.9
Board_2-/3V3_ECU: 3V3.1, J6.1, R1.1, RV1.1, RV2.1
Board_2-Accel: ACCEL.1, C2.1, J6.7, RV1.2, TVS1.1
Board_2-Brake: BRAKE.1, C3.1, J6.3, RV2.2, TVS2.1
Board_2-GND: C2.2, C3.2, GND#2.1, J6.4, R6.2, RV1.3, RV2.3, SW1.5, TVS1.2, TVS2.2, TVS3.2
Board_2-JOYSTICK: J6.8, R1.2, R2.1, SHIFT.1, SW1.1, TVS3.1
Board_2-Net-(R2-Pad2): R2.2, R3.1, SW1.2
Board_2-Net-(R3-Pad2): R3.2, R4.1, SW1.3
Board_2-Net-(R4-Pad2): R4.2, R5.1, SW1.4
Board_2-Net-(R5-Pad2): R5.2, R6.1, SW1.6
Board_3-/3V3_ECU: J7.1, R7.1, R11.2, RV3.1, SW3.1
Board_3-GND: C4.2, J7.4, R10.2, RV3.3, SW2.3, SW3.5, TVS4.2, TVS5.2, TVS6.2
Board_3-Lamp: J7.8, SW3.3, TVS5.1
Board_3-Net-(R7-Pad2): R7.2, R8.1, SW3.2
Board_3-Net-(R8-Pad2): R8.2, R9.1, SW3.4
Board_3-Net-(R10-Pad1): R9.2, R10.1, SW3.6
Board_3-SW1: J7.7, R11.1, SW2.2, TVS6.1
Board_3-Wheel: C4.1, J7.3, RV3.2, TVS4.1

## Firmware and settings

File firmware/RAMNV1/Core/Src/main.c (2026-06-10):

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
/* Includes ------------------------------------------------------------------*/
#include "main.h"
#include "cmsis_os.h"

/* USER CODE BEGIN Includes */
#include "queue.h"
#include "stm32l5xx_hal_rng.h" // contains RNG peripheral error codes
#include "ramn_debug.h"
#ifdef ENABLE_USB
#include "ramn_usb.h"
#endif

#ifdef ENABLE_CDC
#include "ramn_cdc.h"
#endif

#ifdef ENABLE_GSUSB
#include "ramn_gsusb.h"
#endif

#include "ramn_spi.h"
#include "ramn_canfd.h"
#include "ramn_trng.h"
#include "ramn_ecucontrol.h"
#include "ramn_dbc.h"
#include "ramn_simulator.h"
#include "ramn_sensors.h"
#include "ramn_actuators.h"
#include "ramn_crc.h"
#if defined(ENABLE_DIAG)
#include "ramn_diag.h"
#endif
#if defined(ENABLE_SCREEN)
#include "ramn_screen_manager.h"
#endif
#if defined(ENABLE_MINICTF)
#include "ramn_ctf.h"
#endif
#include "ramn_customize.h"
#ifdef ENABLE_UART
#include "ramn_uart.h"
#endif
#include "usb_device.h"
#include "usbd_gsusb_if.h"
#ifdef TARGET_ECUA
#include "ramn_memory.h"
#endif
#ifdef ENABLE_EEPROM_EMULATION
#include "ramn_dtc.h"
#endif
/* USER CODE END Includes */

typedef StaticTask_t osStaticThreadDef_t;
/* USER CODE BEGIN PTD */
typedef StaticQueue_t osStaticMessageQDef_t;
/* USER CODE END PTD */

ADC_HandleTypeDef hadc1;
DMA_HandleTypeDef hdma_adc1;

CRC_HandleTypeDef hcrc;

FDCAN_HandleTypeDef hfdcan1;

I2C_HandleTypeDef hi2c2;

IWDG_HandleTypeDef hiwdg;

UART_HandleTypeDef hlpuart1;

RNG_HandleTypeDef hrng;

SPI_HandleTypeDef hspi2;
DMA_HandleTypeDef hdma_spi2_tx;
DMA_HandleTypeDef hdma_spi2_rx;

TIM_HandleTypeDef htim2;
TIM_HandleTypeDef htim6;
TIM_HandleTypeDef htim7;
TIM_HandleTypeDef htim16;
TIM_HandleTypeDef htim17;

PCD_HandleTypeDef hpcd_USB_FS;

/* Definitions for RAMN_ReceiveUSB */
osThreadId_t RAMN_ReceiveUSBHandle;
const osThreadAttr_t RAMN_ReceiveUSB_attributes = {
  .name = "RAMN_ReceiveUSB",
  .priority = (osPriority_t) osPriorityNormal,
  .stack_size = 256 * 4
};
/* Definitions for RAMN_ReceiveCAN */
osThreadId_t RAMN_ReceiveCANHandle;
uint32_t RAMN_ReceiveCANBuffer[ 256 ];
osStaticThreadDef_t RAMN_ReceiveCANControlBlock;
const osThreadAttr_t RAMN_ReceiveCAN_attributes = {
  .name = "RAMN_ReceiveCAN",
  .stack_mem = &RAMN_ReceiveCANBuffer[0],
  .stack_size = sizeof(RAMN_ReceiveCANBuffer),
  .cb_mem = &RAMN_ReceiveCANControlBlock,
  .cb_size = sizeof(RAMN_ReceiveCANControlBlock),
  .priority = (osPriority_t) osPriorityNormal,
};
/* Definitions for RAMN_SendCAN */
osThreadId_t RAMN_SendCANHandle;
uint32_t RAMN_SendCANBuffer[ 256 ];
osStaticThreadDef_t RAMN_SendCANControlBlock;
const osThreadAttr_t RAMN_SendCAN_attributes = {
  .name = "RAMN_SendCAN",
  .stack_mem = &RAMN_SendCANBuffer[0],
  .stack_size = sizeof(RAMN_SendCANBuffer),
  .cb_mem = &RAMN_SendCANControlBlock,
  .cb_size = sizeof(RAMN_SendCANControlBlock),
  .priority = (osPriority_t) osPriorityHigh,
};
/* Definitions for RAMN_Periodic */
osThreadId_t RAMN_PeriodicHandle;
uint32_t RAMN_PeriodicBuffer[ 256 ];
osStaticThreadDef_t RAMN_PeriodicControlBlock;
const osThreadAttr_t RAMN_Periodic_attributes = {
  .name = "RAMN_Periodic",
  .stack_mem = &RAMN_PeriodicBuffer[0],
  .stack_size = sizeof(RAMN_PeriodicBuffer),
  .cb_mem = &RAMN_PeriodicControlBlock,
  .cb_size = sizeof(RAMN_PeriodicControlBlock),
  .priority = (osPriority_t) osPriorityAboveNormal,
};
/* Definitions for RAMN_ErrorTask */
osThreadId_t RAMN_ErrorTaskHandle;
uint32_t RAMN_ErrorTaskBuffer[ 256 ];
osStaticThreadDef_t RAMN_ErrorTaskControlBlock;
const osThreadAttr_t RAMN_ErrorTask_attributes = {
  .name = "RAMN_ErrorTask",
  .stack_mem = &RAMN_ErrorTaskBuffer[0],
  .stack_size = sizeof(RAMN_ErrorTaskBuffer),
  .cb_mem = &RAMN_ErrorTaskControlBlock,
  .cb_size = sizeof(RAMN_ErrorTaskControlBlock),
  .priority = (osPriority_t) osPriorityRealtime1,
};
/* Definitions for RAMN_DiagRX */
osThreadId_t RAMN_DiagRXHandle;
uint32_t RAMN_DiagRXBuffer[ 256 ];
osStaticThreadDef_t RAMN_DiagRXControlBlock;
const osThreadAttr_t RAMN_DiagRX_attributes = {
  .name = "RAMN_DiagRX",
  .stack_mem = &RAMN_DiagRXBuffer[0],
  .stack_size = sizeof(RAMN_DiagRXBuffer),
  .cb_mem = &RAMN_DiagRXControlBlock,
  .cb_size = sizeof(RAMN_DiagRXControlBlock),
  .priority = (osPriority_t) osPriorityBelowNormal,
};
/* Definitions for RAMN_DiagTX */
osThreadId_t RAMN_DiagTXHandle;
uint32_t RAMN_DiagTXBuffer[ 256 ];
osStaticThreadDef_t RAMN_DiagTXControlBlock;
const osThreadAttr_t RAMN_DiagTX_attributes = {
  .name = "RAMN_DiagTX",
  .stack_mem = &RAMN_DiagTXBuffer[0],
  .stack_size = sizeof(RAMN_DiagTXBuffer),
  .cb_mem = &RAMN_DiagTXControlBlock,
  .cb_size = sizeof(RAMN_DiagTXControlBlock),
  .priority = (osPriority_t) osPriorityLow7,
};
/* Definitions for RAMN_SendUSB */
osThreadId_t RAMN_SendUSBHandle;
const osThreadAttr_t RAMN_SendUSB_attributes = {
  .name = "RAMN_SendUSB",
  .priority = (osPriority_t) osPriorityRealtime,
  .stack_size = 256 * 4
};
/* Definitions for RAMN_RxTask2 */
osThreadId_t RAMN_RxTask2Handle;
const osThreadAttr_t RAMN_RxTask2_attributes = {
  .name = "RAMN_RxTask2",
  .priority = (osPriority_t) osPriorityHigh1,
  .stack_size = 512 * 4
};
/* Definitions for RAMN_TxTask2 */
osThreadId_t RAMN_TxTask2Handle;
const osThreadAttr_t RAMN_TxTask2_attributes = {
  .name = "RAMN_TxTask2",
  .priority = (osPriority_t) osPriorityHigh2,
  .stack_size = 256 * 4
};
/* USER CODE BEGIN PV */

#ifdef ENABLE_GSUSB
/* Definitions for RAMN_GSUSB_RecvQueue */
osMessageQueueId_t RAMN_GSUSB_RecvQueueHandle;
__attribute__ ((section (".buffers"))) uint8_t RAMN_GSUSB_RecvQueueBuffer[ GSUSB_RECV_QUEUE_SIZE * sizeof( uint32_t ) ];
osStaticMessageQDef_t RAMN_GSUSB_RecvQueueControlBlock;
const osMessageQueueAttr_t RAMN_GSUSB_RecvQueue_attributes = {
		.name = "RAMN_GSUSB_RecvQueue",
		.cb_mem = &RAMN_GSUSB_RecvQueueControlBlock,
		.cb_size = sizeof(RAMN_GSUSB_RecvQueueControlBlock),
		.mq_mem = &RAMN_GSUSB_RecvQueueBuffer,
		.mq_size = sizeof(RAMN_GSUSB_RecvQueueBuffer)
};
/* Definitions for RAMN_GSUSB_PoolQueue */
osMessageQueueId_t RAMN_GSUSB_PoolQueueHandle;
__attribute__ ((section (".buffers"))) uint8_t RAMN_GSUSB_PoolQueueBuffer[ GSUSB_POOL_QUEUE_SIZE * sizeof( uint32_t ) ];
osStaticMessageQDef_t RAMN_GSUSB_PoolQueueControlBlock;
const osMessageQueueAttr_t RAMN_GSUSB_PoolQueue_attributes = {
		.name = "RAMN_GSUSB_PoolQueue",
		.cb_mem = &RAMN_GSUSB_PoolQueueControlBlock,
		.cb_size = sizeof(RAMN_GSUSB_PoolQueueControlBlock),
		.mq_mem = &RAMN_GSUSB_PoolQueueBuffer,
		.mq_size = sizeof(RAMN_GSUSB_PoolQueueBuffer)
};
/* Definitions for RAMN_GSUSB_SendQueue */
osMessageQueueId_t RAMN_GSUSB_SendQueueHandle;
__attribute__ ((section (".buffers"))) uint8_t RAMN_GSUSB_SendQueueBuffer[ GSUSB_SEND_QUEUE_SIZE * sizeof( uint32_t ) ];
osStaticMessageQDef_t RAMN_GSUSB_SendQueueControlBlock;
const osMessageQueueAttr_t RAMN_GSUSB_SendQueue_attributes = {
		.name = "RAMN_GSUSB_SendQueue",
		.cb_mem = &RAMN_GSUSB_SendQueueControlBlock,
		.cb_size = sizeof(RAMN_GSUSB_SendQueueControlBlock),
		.mq_mem = &RAMN_GSUSB_SendQueueBuffer,
		.mq_size = sizeof(RAMN_GSUSB_SendQueueBuffer)
};
#endif

#if defined(ENABLE_CDC)

// Stream buffer for USB RX data, filled by ISR and emptied by receiving task.
static StaticStreamBuffer_t USB_RX_BUFFER_STRUCT;
__attribute__ ((section (".buffers")))  static uint8_t USB_RX_BUFFER[USB_RX_BUFFER_SIZE];
StreamBufferHandle_t USBD_RxStreamBufferHandle;

// Stream buffer for USB TX data, filled by transmitting task(s).
static StaticStreamBuffer_t USB_TX_BUFFER_STRUCT;
__attribute__ ((section (".buffers")))  static uint8_t USB_TX_BUFFER[USB_TX_BUFFER_SIZE];
StreamBufferHandle_t USBD_TxStreamBufferHandle;

// Intermediary buffer to empty USB_TX_BUFFER and pass it to CDC drivers (data currently being transmitted over USB).
__attribute__ ((section (".buffers")))  uint8_t USBIntermediateTxBuffer[APP_TX_DATA_SIZE];

// Holds currently processed (slcan) USB command.
__attribute__ ((section (".buffers")))  uint8_t USBRxBuffer[USB_COMMAND_BUFFER_SIZE];

// Holds currently processed (slcan) USB command's answer (Used by CAN receiving task).
__attribute__ ((section (".buffers")))  uint8_t slCAN_USBTxBuffer[0x200];

#endif

#if defined(ENABLE_UART)

// Stream buffer for UART RX data, filled by ISR and emptied by receiving task.
static StaticStreamBuffer_t UART_RX_BUFFER_STRUCT;
__attribute__ ((section (".buffers")))  static uint8_t UART_RX_BUFFER[UART_RX_BUFFER_SIZE];
StreamBufferHandle_t UART_RxStreamBufferHandle;

// Stream buffer for UART TX data, filled by transmitting task(s).
static StaticStreamBuffer_t UART_TX_BUFFER_STRUCT;
__attribute__ ((section (".buffers")))  static uint8_t UART_TX_BUFFER[UART_TX_BUFFER_SIZE];
StreamBufferHandle_t UART_TxStreamBufferHandle;

// Holds command currently being received over UART, used by ISR
__attribute__ ((section (".buffers"))) static uint8_t  UART_recvBuf[UART_RX_COMMAND_BUFFER_SIZE];

// Holds data currently being transmitted over UART, used as an argument to HAL library.
__attribute__ ((section (".buffers")))  uint8_t UARTIntermediateTxBuffer[UART_TX_COMMAND_BUFFER_SIZE];

// Holds data currently being processed, used by receiving task.
__attribute__ ((section (".buffers")))  uint8_t UARTRxBuffer[UART_RX_COMMAND_BUFFER_SIZE];

// Buffer to receive next UART char, used by ISR.
static uint8_t uart_rx_data[1];

// Current index of uart command.
static uint16_t uart_current_index = 0;

#endif

static RAMN_Bool_t USB_CLI_ENABLE;

#if defined(ENABLE_I2C)
__attribute__ ((section (".buffers"))) uint8_t i2c_rxBuf[I2C_RX_BUFFER_SIZE];
__attribute__ ((section (".buffers"))) uint8_t i2c_txBuf[I2C_TX_BUFFER_SIZE] = {'R', 'A', 'M', 'N'};
#endif

#if defined(ENABLE_DIAG)

// Holds currently processed Diag Command from CAN.
// Aligned to enable easy shell code execution. Sized to the ISO-TP buffers so a full reassembled
// request fits (+2 headroom for the zero-terminator some routines write at data[size]).
__attribute__ ((section (".buffers"), aligned(4)))  uint8_t diagRxbuf[ISOTP_RXBUFFER_SIZE+2];
// Holds currently generated Diag Command Answer for CAN (sized to the ISO-TP TX buffer).
__attribute__ ((section (".buffers")))  uint8_t diagTxbuf[ISOTP_TXBUFFER_SIZE+2];

#endif

// Buffers for UDS commands, only allocated if enabled.
#if defined(ENABLE_UDS)

static StaticStreamBuffer_t UDS_ISOTP_RX_BUFFER_STRUCT;
__attribute__ ((section (".buffers")))  static uint8_t UDS_ISOTP_RX_BUFFER[UDS_ISOTP_RX_BUFFER_SIZE];

static StaticStreamBuffer_t UDS_ISOTP_TX_BUFFER_STRUCT;
__attribute__ ((section (".buffers")))  static uint8_t UDS_ISOTP_TX_BUFFER[UDS_ISOTP_RX_BUFFER_SIZE];

#endif

// Buffers for KWP commands, only allocated if enabled.
#if defined(ENABLE_KWP)

static StaticStreamBuffer_t KWP_ISOTP_RX_BUFFER_STRUCT;
__attribute__ ((section (".buffers"))) static uint8_t KWP_ISOTP_RX_BUFFER[KWP_ISOTP_RX_BUFFER_SIZE];

static StaticStreamBuffer_t KWP_ISOTP_TX_BUFFER_STRUCT;
__attribute__ ((section (".buffers"))) static uint8_t KWP_ISOTP_TX_BUFFER[KWP_ISOTP_TX_BUFFER_SIZE];

#endif

// Buffers for XCP commands, only allocated if enabled.
#if defined(ENABLE_XCP)

static StaticStreamBuffer_t XCP_RX_BUFFER_STRUCT;
__attribute__ ((section (".buffers"))) static uint8_t XCP_RX_BUFFER[XCP_RX_BUFFER_SIZE];

static StaticStreamBuffer_t XCP_TX_BUFFER_STRUCT;
__attribute__ ((section (".buffers"))) static uint8_t XCP_TX_BUFFER[XCP_RX_BUFFER_SIZE];

#endif

// Buffers for CAN Messages.
static StaticStreamBuffer_t CAN_RX_BUFFER_STRUCT;
__attribute__ ((section (".buffers")))  static uint8_t CAN_RX_BUFFER[CAN_RX_BUFFER_SIZE];

static StaticStreamBuffer_t CAN_TX_BUFFER_STRUCT;
__attribute__ ((section (".buffers")))  static uint8_t CAN_TX_BUFFER[CAN_TX_BUFFER_SIZE];

// Handle for diag stream buffers, even unallocated ones.
StreamBufferHandle_t UdsRxDataStreamBufferHandle;
StreamBufferHandle_t UdsTxDataStreamBufferHandle;

StreamBufferHandle_t KwpRxDataStreamBufferHandle;
StreamBufferHandle_t KwpTxDataStreamBufferHandle;

StreamBufferHandle_t XcpRxDataStreamBufferHandle;
StreamBufferHandle_t XcpTxDataStreamBufferHandle;

// Header for RTR answers
FDCAN_TxHeaderTypeDef RTRTxHeader;
uint8_t RTRTxData[8];

uint8_t g_autoRecoverBusOff;


/* USER CODE END PV */

void SystemClock_Config(void);
static void MX_GPIO_Init(void);
static void MX_DMA_Init(void);
static void MX_ICACHE_Init(void);
static void MX_RNG_Init(void);
static void MX_FDCAN1_Init(void);
static void MX_SPI2_Init(void);
static void MX_ADC1_Init(void);
static void MX_IWDG_Init(void);
static void MX_CRC_Init(void);
static void MX_I2C2_Init(void);
static void MX_LPUART1_UART_Init(void);
static void MX_USB_PCD_Init(void);
static void MX_TIM7_Init(void);
static void MX_TIM6_Init(void);
static void MX_TIM16_Init(void);
static void MX_TIM17_Init(void);
static void MX_TIM2_Init(void);
void RAMN_ReceiveUSBFunc(void *argument);
void RAMN_ReceiveCANFunc(void *argument);
void RAMN_SendCANFunc(void *argument);
void RAMN_PeriodicTaskFunc(void *argument);
void RAMN_ErrorTaskFunc(void *argument);
void RAMN_DiagRXFunc(void *argument);
void RAMN_DiagTXFunc(void *argument);
void RAMN_SendUSBFunc(void *argument);
void RAMN_RxTask2Func(void *argument);
void RAMN_TxTask2Func(void *argument);

/* USER CODE BEGIN 0 */

#if defined(GENERATE_RUNTIME_STATS)
volatile unsigned long ulHighFrequencyTimerTicks;

void configureTimerForRunTimeStats(void) {
	ulHighFrequencyTimerTicks = 0U;
	HAL_TIM_Base_Start_IT(&htim7);
}

unsigned long getRunTimeCounterValue(void) {
	return ulHighFrequencyTimerTicks;
}
#endif
/* USER CODE END 0 */

/**
  * @brief  The application entry point.
  * @retval int
  */
int main(void)
{

  /* USER CODE BEGIN 1 */

	// Ensure proper configuration of VTOR or program does not work correctly after live booting from DFU bootloader
	__disable_irq();
	SCB->VTOR = FLASH_BASE_NS;
	__DSB();
	__enable_irq();
  /* USER CODE END 1 */

  /* MCU Configuration--------------------------------------------------------*/

  /* Reset of all peripherals, Initializes the Flash interface and the Systick. */
  HAL_Init();

  /* USER CODE BEGIN Init */

#if defined(TARGET_ECUA)
#ifndef HARDWARE_BOOT0_CONTROL
	// Check that ECU A BOOT option bytes are properly configured to hardware BOOT0, which should be pulled-up by default.
	RAMN_FLASH_ConfigureOptionBytesApplicationMode();
#endif
#endif

#if defined(MEMORY_AUTOLOCK)
	if(RAMN_FLASH_isMemoryProtected() == False) RAMN_FLASH_ConfigureRDPOptionByte(RDP_OPTIONBYTE);
#endif

  /* USER CODE END Init */

  /* Configure the system clock */
  SystemClock_Config();

  /* Initialize all configured peripherals */
  MX_GPIO_Init();
  MX_DMA_Init();
  MX_ICACHE_Init();
  MX_RNG_Init();
  MX_FDCAN1_Init();
  MX_SPI2_Init();
  MX_ADC1_Init();
  MX_IWDG_Init();
  MX_CRC_Init();
  MX_I2C2_Init();
  MX_LPUART1_UART_Init();
  MX_USB_PCD_Init();
  MX_TIM7_Init();
  MX_TIM6_Init();
  MX_TIM16_Init();
  MX_TIM17_Init();
  MX_TIM2_Init();
  /* USER CODE BEGIN 2 */

#ifdef START_IN_CLI_MODE
	USB_CLI_ENABLE = 1U;
#else
	USB_CLI_ENABLE = 0U;
#endif

#if defined(ENABLE_CDC)
	USBD_RxStreamBufferHandle   = xStreamBufferCreateStatic(USB_RX_BUFFER_SIZE,sizeof(uint8_t),USB_RX_BUFFER,&USB_RX_BUFFER_STRUCT);
	USBD_TxStreamBufferHandle   = xStreamBufferCreateStatic(USB_TX_BUFFER_SIZE,sizeof(uint8_t),USB_TX_BUFFER,&USB_TX_BUFFER_STRUCT);
#endif

#if defined(ENABLE_UART)
	UART_RxStreamBufferHandle   = xStreamBufferCreateStatic(UART_RX_BUFFER_SIZE,sizeof(uint8_t),UART_RX_BUFFER,&UART_RX_BUFFER_STRUCT);
	UART_TxStreamBufferHandle   = xStreamBufferCreateStatic(UART_TX_BUFFER_SIZE,sizeof(uint8_t),UART_TX_BUFFER,&UART_TX_BUFFER_STRUCT);
#endif

#if defined(ENABLE_UDS)
	UdsRxDataStreamBufferHandle = xStreamBufferCreateStatic(UDS_ISOTP_RX_BUFFER_SIZE,sizeof(uint8_t),UDS_ISOTP_RX_BUFFER,&UDS_ISOTP_RX_BUFFER_STRUCT);
	UdsTxDataStreamBufferHandle = xStreamBufferCreateStatic(UDS_ISOTP_TX_BUFFER_SIZE,sizeof(uint8_t),UDS_ISOTP_TX_BUFFER,&UDS_ISOTP_TX_BUFFER_STRUCT);
#endif
#if defined(ENABLE_KWP)
	KwpRxDataStreamBufferHandle = xStreamBufferCreateStatic(KWP_ISOTP_RX_BUFFER_SIZE,sizeof(uint8_t),KWP_ISOTP_RX_BUFFER,&KWP_ISOTP_RX_BUFFER_STRUCT);
	KwpTxDataStreamBufferHandle = xStreamBufferCreateStatic(KWP_ISOTP_TX_BUFFER_SIZE,sizeof(uint8_t),KWP_ISOTP_TX_BUFFER,&KWP_ISOTP_TX_BUFFER_STRUCT);
#endif
#if defined(ENABLE_XCP)
	XcpRxDataStreamBufferHandle = xStreamBufferCreateStatic(XCP_RX_BUFFER_SIZE,sizeof(uint8_t),XCP_RX_BUFFER,&XCP_RX_BUFFER_STRUCT);
	XcpTxDataStreamBufferHandle = xStreamBufferCreateStatic(XCP_TX_BUFFER_SIZE,sizeof(uint8_t),XCP_TX_BUFFER,&XCP_TX_BUFFER_STRUCT);
#endif

	CANRxDataStreamBufferHandle = xStreamBufferCreateStatic(CAN_RX_BUFFER_SIZE,sizeof(uint8_t),CAN_RX_BUFFER,&CAN_RX_BUFFER_STRUCT);
	CANTxDataStreamBufferHandle = xStreamBufferCreateStatic(CAN_TX_BUFFER_SIZE,sizeof(uint8_t),CAN_TX_BUFFER,&CAN_TX_BUFFER_STRUCT);

#if defined(TARGET_ECUA)
	// Make sure other ECUs are turned off.
	RAMN_ECU_SetEnableAll(0U);
	// Make sure BOOT0 is low (application mode).
	RAMN_ECU_SetBoot0All(0U);
#endif

#if defined(ENABLE_SPI) && !defined(ENABLE_SCREEN) //if screen is enabled, we initialize it in the screen module.
	RAMN_SPI_Init(&hspi2, &RAMN_PeriodicHandle);
#endif

#if defined(ENABLE_EEPROM_EMULATION)
	RAMN_EEPROM_Init();
#endif

#if defined(ENABLE_DIAG)
	RAMN_DIAG_Init(xTaskGetTickCount(),&RAMN_DiagRXHandle, &UdsRxDataStreamBufferHandle, &KwpRxDataStreamBufferHandle, &XcpRxDataStreamBufferHandle);
#endif

	RAMN_RNG_Init(&hrng);
	RAMN_CRC_Init(&hcrc);
	RAMN_FDCAN_Init(&hfdcan1,&RAMN_SendCANHandle,&RAMN_ErrorTaskHandle);

#ifdef USE_TRNG_BUFFER
	// Enable TRNG module
	if (HAL_RNG_GenerateRandomNumber_IT(&hrng) != HAL_OK)
	{
#ifdef HANG_ON_ERRORS
		Error_Handler();
#endif
	}
#endif

	// Automatically add a DTC if none is stored in memory
#ifdef ENABLE_EEPROM_EMULATION
	uint32_t dtcCnt = 0U;

	if (RAMN_DTC_GetNumberOfDTC(&dtcCnt) == RAMN_OK)
	{
		if (dtcCnt == 0U)
		{
			// No DTC, add one per ECU
#ifdef TARGET_ECUA
			uint32_t dtcVal = 0x3u << 30; // 0b11 << 30, "11" for network ("U")
			dtcVal |= 0x0029 << 16; // Bus A Performance, FTB 0
#elif defined(TARGET_ECUB)
			uint32_t dtcVal = 0x1u << 30; // 0b01 << 30,  "01" for chassis ("C")
			dtcVal |= 0x0563 << 16; // Calibration ROM Checksum Error, FTB 0
#elif defined(TARGET_ECUC)
			uint32_t dtcVal = 0x0u << 30; // 0b00 << 30, "00" for powertrain ("P")
			dtcVal |= 0x0172 << 16; // System too Rich, FTB 0
#elif defined(TARGET_ECUD)
			uint32_t dtcVal = 0x2u << 30; // 0b10 << 30, "10" for body ("B")
			dtcVal |= 0x0091 << 16; // Active switch wrong state, FTB 0
#endif
			dtcVal |= 1 << 2; //mark DTC as pending.
			RAMN_DTC_AddNew(dtcVal);
		}
	}
#endif
  /* USER CODE END 2 */

  /* Init scheduler */
  osKernelInitialize();

  /* USER CODE BEGIN RTOS_MUTEX */
	/* add mutexes, ... */
  /* USER CODE END RTOS_MUTEX */

  /* USER CODE BEGIN RTOS_TIMERS */
	/* start timers, add new ones, ... */
  /* USER CODE END RTOS_TIMERS */

  /* USER CODE BEGIN RTOS_QUEUES */
#ifdef ENABLE_GSUSB
	/* creation of RAMN_GSUSB_RecvQueue */
	RAMN_GSUSB_RecvQueueHandle = osMessageQueueNew (GSUSB_RECV_QUEUE_SIZE, sizeof(uint32_t), &RAMN_GSUSB_RecvQueue_attributes);

	/* creation of RAMN_GSUSB_PoolQueue */
	RAMN_GSUSB_PoolQueueHandle = osMessageQueueNew (GSUSB_POOL_QUEUE_SIZE, sizeof(uint32_t), &RAMN_GSUSB_PoolQueue_attributes);

	/* creation of RAMN_GSUSB_SendQueue */
	RAMN_GSUSB_SendQueueHandle = osMessageQueueNew (GSUSB_SEND_QUEUE_SIZE, sizeof(uint32_t), &RAMN_GSUSB_SendQueue_attributes);
#endif

#ifdef ENABLE_USB
	MX_USB_Device_Init();
#endif
  /* USER CODE END RTOS_QUEUES */

  /* Create the thread(s) */
  /* creation of RAMN_ReceiveUSB */
  RAMN_ReceiveUSBHandle = osThreadNew(RAMN_ReceiveUSBFunc, NULL, &RAMN_ReceiveUSB_attributes);

  /* creation of RAMN_ReceiveCAN */
  RAMN_ReceiveCANHandle = osThreadNew(RAMN_ReceiveCANFunc, NULL, &RAMN_ReceiveCAN_attributes);

  /* creation of RAMN_SendCAN */
  RAMN_SendCANHandle = osThreadNew(RAMN_SendCANFunc, NULL, &RAMN_SendCAN_attributes);

  /* creation of RAMN_Periodic */
  RAMN_PeriodicHandle = osThreadNew(RAMN_PeriodicTaskFunc, NULL, &RAMN_Periodic_attributes);

  /* creation of RAMN_ErrorTask */
  RAMN_ErrorTaskHandle = osThreadNew(RAMN_ErrorTaskFunc, NULL, &RAMN_ErrorTask_attributes);

  /* creation of RAMN_DiagRX */
  RAMN_DiagRXHandle = osThreadNew(RAMN_DiagRXFunc, NULL, &RAMN_DiagRX_attributes);

  /* creation of RAMN_DiagTX */
  RAMN_DiagTXHandle = osThreadNew(RAMN_DiagTXFunc, NULL, &RAMN_DiagTX_attributes);

  /* creation of RAMN_SendUSB */
  RAMN_SendUSBHandle = osThreadNew(RAMN_SendUSBFunc, NULL, &RAMN_SendUSB_attributes);

  /* creation of RAMN_RxTask2 */
  RAMN_RxTask2Handle = osThreadNew(RAMN_RxTask2Func, NULL, &RAMN_RxTask2_attributes);

  /* creation of RAMN_TxTask2 */
  RAMN_TxTask2Handle = osThreadNew(RAMN_TxTask2Func, NULL, &RAMN_TxTask2_attributes);

  /* USER CODE BEGIN RTOS_EVENTS */
	/* add events, ... */
  /* USER CODE END RTOS_EVENTS */

  /* Start scheduler */
  osKernelStart();

  /* We should never get here as control is now taken by the scheduler */

  /* Infinite loop */
  /* USER CODE BEGIN WHILE */
	while (1)
	{
    /* USER CODE END WHILE */

    /* USER CODE BEGIN 3 */
	}
  /* USER CODE END 3 */
}

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
/* USER CODE BEGIN 4 */

#ifdef ENABLE_I2C

void HAL_I2C_SlaveRxCpltCallback(I2C_HandleTypeDef *hi2c)
{
	if (hi2c != 0)
	{
		RAMN_CUSTOM_ReceiveI2C(i2c_rxBuf, I2C_RX_BUFFER_SIZE);
	}
}

void HAL_I2C_SlaveTxCpltCallback(I2C_HandleTypeDef *hi2c)
{
	if (hi2c != 0)
	{

	}
}

void HAL_I2C_AddrCallback(I2C_HandleTypeDef *hi2c, uint8_t transferDirect, uint16_t AddrMatchCode)
{
	if (hi2c != 0U)
	{
		if (transferDirect == I2C_DIRECTION_TRANSMIT)
		{
			if (HAL_I2C_Slave_Sequential_Receive_IT(hi2c, i2c_rxBuf, I2C_RX_BUFFER_SIZE, I2C_FIRST_AND_LAST_FRAME) != HAL_OK) Error_Handler();
		}
		else if (transferDirect == I2C_DIRECTION_RECEIVE)
		{
			RAMN_CUSTOM_PrepareTransmitDataI2C(i2c_txBuf, I2C_TX_BUFFER_SIZE);
			if (HAL_I2C_Slave_Sequential_Transmit_IT(hi2c, i2c_txBuf, I2C_TX_BUFFER_SIZE, I2C_FIRST_AND_LAST_FRAME) != HAL_OK) Error_Handler();
		}
		else Error_Handler();
	}
}
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

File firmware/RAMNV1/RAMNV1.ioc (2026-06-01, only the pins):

Mcu.UserName=STM32L562CETx
PA0.GPIO_Label=ECUD_EN
PA0.Signal=GPIO_Output
PA1.Signal=ADCx_IN6
PA11.Signal=USB_DM
PA12.Signal=USB_DP
PA2.Signal=LPUART1_TX
PA3.Signal=LPUART1_RX
PA4.Signal=ADCx_IN9
PA5.Signal=ADCx_IN10
PA8.GPIO_Label=Other_nCS
PA8.Signal=GPIO_Output
PA9.GPIO_Label=HW_TYPE
PA9.Signal=GPIO_Input
PB10.Signal=I2C2_SCL
PB11.Signal=I2C2_SDA
PB12.GPIO_Label=LCD_DC
PB12.Signal=GPIO_Output
PB13.Signal=SPI2_SCK
PB14.Signal=SPI2_MISO
PB15.Signal=SPI2_MOSI
PB2.GPIO_Label=LCD_nCS
PB2.Signal=GPIO_Output
PB5.GPIO_Label=ECUB_EN
PB5.Signal=GPIO_Output
PB6.GPIO_Label=FDCAN1_STB
PB6.Signal=GPIO_Output
PB7.GPIO_Label=ECUB_BOOT0
PB7.Signal=GPIO_Output
PB8.Signal=FDCAN1_RX
PB9.Signal=FDCAN1_TX
PC13.GPIO_Label=ECUC_EN
PC13.Signal=GPIO_Output
PH3-BOOT0.GPIO_Label=SELF_BOOT0
PH3-BOOT0.Signal=GPIO_Input

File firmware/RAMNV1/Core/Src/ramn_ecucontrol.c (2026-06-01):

/*
 * ramn_ecucontrol.c
  ******************************************************************************
  * @attention
  *
  * <h2><center>&copy; Copyright (c) 2025 TOYOTA MOTOR CORPORATION.
  * ALL RIGHTS RESERVED.</center></h2>
  *
  * This software component is licensed by TOYOTA MOTOR CORPORATION under BSD 3-Clause license,
  * the "License"; You may not use this file except in compliance with the
  * License. You may obtain a copy of the License at:
  *                        opensource.org/licenses/BSD-3-Clause
  *
  ******************************************************************************
 */

#include "ramn_ecucontrol.h"

#if defined(TARGET_ECUA)

void RAMN_ECU_SetEnable(char ecuName, uint8_t state)
{
	if 		(ecuName == 'B') HAL_GPIO_WritePin(ECUB_EN_GPIO_Port, ECUB_EN_Pin,state);
	else if (ecuName == 'C') HAL_GPIO_WritePin(ECUC_EN_GPIO_Port, ECUC_EN_Pin,state);
	else if (ecuName == 'D') HAL_GPIO_WritePin(ECUD_EN_GPIO_Port, ECUD_EN_Pin,state);
}

void RAMN_ECU_SetBoot0(char ecuName, uint8_t state)
{
	if 		(ecuName == 'B') HAL_GPIO_WritePin(ECUB_BOOT0_GPIO_Port, ECUB_BOOT0_Pin, state);
	else if (ecuName == 'C') HAL_GPIO_WritePin(ECUC_BOOT0_GPIO_Port, ECUC_BOOT0_Pin, state);
	else if (ecuName == 'D') HAL_GPIO_WritePin(ECUD_BOOT0_GPIO_Port, ECUD_BOOT0_Pin, state);
}

void RAMN_ECU_SetEnableAll(uint8_t state)
{
	RAMN_ECU_SetEnable('B',state);
	RAMN_ECU_SetEnable('C',state);
	RAMN_ECU_SetEnable('D',state);
}

void RAMN_ECU_SetBoot0All(uint8_t state)
{
	RAMN_ECU_SetBoot0('B',state);
	RAMN_ECU_SetBoot0('C',state);
	RAMN_ECU_SetBoot0('D',state);
}

void RAMN_ECU_SetDefaultState(void)
{
	RAMN_ECU_SetBoot0All(GPIO_PIN_RESET);
	osDelay(10); // Add small delay to make sure ECUs boot with BOOT0 pin set low.
	RAMN_ECU_SetEnableAll(GPIO_PIN_SET);
}

RAMN_Bool_t RAMN_ECU_IsHardWareVariant()
{
	if (HAL_GPIO_ReadPin(HW_TYPE_GPIO_Port, HW_TYPE_Pin) == GPIO_PIN_RESET)
	{
		return True;
	}
	else return False;
}

#endif

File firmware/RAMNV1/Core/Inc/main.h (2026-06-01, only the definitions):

#define ECUC_EN_Pin GPIO_PIN_13
#define ECUC_EN_GPIO_Port GPIOC
#define ECUC_BOOT0_Pin GPIO_PIN_14
#define ECUC_BOOT0_GPIO_Port GPIOC
#define ECUD_BOOT0_Pin GPIO_PIN_15
#define ECUD_BOOT0_GPIO_Port GPIOC
#define ECUD_EN_Pin GPIO_PIN_0
#define ECUD_EN_GPIO_Port GPIOA
#define LCD_nCS_Pin GPIO_PIN_2
#define LCD_nCS_GPIO_Port GPIOB
#define LCD_DC_Pin GPIO_PIN_12
#define LCD_DC_GPIO_Port GPIOB
#define Other_nCS_Pin GPIO_PIN_8
#define Other_nCS_GPIO_Port GPIOA
#define HW_TYPE_Pin GPIO_PIN_9
#define HW_TYPE_GPIO_Port GPIOA
#define ECUB_EN_Pin GPIO_PIN_5
#define ECUB_EN_GPIO_Port GPIOB
#define FDCAN1_STB_Pin GPIO_PIN_6
#define FDCAN1_STB_GPIO_Port GPIOB
#define ECUB_BOOT0_Pin GPIO_PIN_7
#define ECUB_BOOT0_GPIO_Port GPIOB
#define SELF_BOOT0_Pin GPIO_PIN_3
#define SELF_BOOT0_GPIO_Port GPIOH
#define HARDWARE_UNIQUE_ID_ADDRESS ((uint32_t*)0x0BFA0590)

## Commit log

2020-12-04 Added hardware files for BETA version
    [microcar_head-B_Cu.gbr, microcar_head-B_Mask.gbr, microcar_head-B_Paste.gbr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]
2020-12-04 updated folder names
    [microcar_head-B_Cu.gbr, microcar_head-B_Mask.gbr, microcar_head-B_Paste.gbr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]
2020-12-07 added external memory design files
    [microcar_head-B_Cu.gbr, microcar_head-B_Mask.gbr, microcar_head-B_Paste.gbr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]
2020-12-07 added firmware
    [RAMN_V1B_ECU.cfg, RAMN_V1B_GW Debug.cfg]
2020-12-28 Added kicad files
    [LDO.sch, body.kicad_pcb, body.sch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]
2021-02-26 Added V1 files
    Added V1 design files, including BOM and ECU pinout.
    Compared to the Beta version, the V1 has a better layout (less acid traps, more space from edge, fiducial marks, etc.) and minimal ESD protections (on potentiometers and switches).
    We had to replace some components with newer components easier to obtain.
    An alternative 4-layer version with additional protections (polyfuse, ESD protection on USB and CAN-bus) has also been added, and we might test it in the future.
    [LDO.sch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]
2021-03-08 fixed minor plating issue in chassis PCB's steering wheel potentiometer
    [chassis-B_Cu.gbr, chassis-B_Mask.gbr, chassis-Edge_Cuts.gbr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]
2021-07-02 Added initial V1 Firmware and Scripts
    - Minor hardware fixes
    - Minor documentation fixes
    [LDO.sch, RAMN_V1B_ECU.cfg, RAMN_V1B_GW Debug.cfg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]
2022-09-06 Minor changes
    - Changed timing and buffer size for some functions.
    - Added function to automatically detect RAMN board COM port for STBootloader scripts.
    - Changed USB error processing to automatically close slcan port.
    - Fixed typos in some variables names and comments.
    - Replaced logarithmic sensor by linear sensor.
    - Updated HAL library and drivers with latest versions.
    - Changed FDCAN controller clock to 40MHz instead of 20MHz.
    - Added default filtering of extended CAN IDs.
    [RAMNV1.ioc, main.c, main.h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]
2022-09-29 Initial Upload of STM32 100pin and universal CAN mod
    Uploaded variation of RAMN V1 with hardware support for chips currently available on the market:
    1. STM32L562VET6 (a 100pin variant of the original RAMN ECU)
    2. 3V3 or 5V CAN TRX compatibility w/ optional io
    [BOM.csv, LDO.kicad_sch, ramn.kicad_pcb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]
2022-09-29 Generated Gerber Files
    [ramn.kicad_pcb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]
2022-09-29 Removed OSC_IN Test Point
    Test point removed to prevent - --increased capacitance and noise on the high-frequency crystal oscillator line. Can hook up oscilloscope directly to crystal's capacitor when needed.
    [ramn.kicad_pcb, ramn.kicad_sch, sc_uc.kicad_sch]
2022-09-30 Updated gerber, minor changes
    - re-generated gerber files with protel file extensions
    - updated data and version on schematics
    [ramn.kicad_pcb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]
2022-09-30 Added Drill files to /gerber
    [ramn-NPTH.drl, ramn-PTH.drl]
2022-10-03 Schematic wiring fix, added part numbers
    - Fixed missing connections between VREF+ and VDDA, VREF- and VSSA on all ECUs
    - Added component part numbers for crystal and CAN trx to schematic
    [LDO.kicad_sch, ramn.kicad_pcb, ramn.kicad_sch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]
2023-08-10 build all with github actions
    using primarily xanderhendriks/action-build-stm32cubeide@v7.0 and the recipe in the BUILD_Clean_X.bat files
2023-10-27 Electrical Fix
    - Fixed missing VREF+/- connections on ECUs
    - Updated version number to V1.1
    - Updated Gerbers
    - Updated schematic PDF
    [BOM.csv, BOM.xlsx, LDO.kicad_sch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]
2023-12-07 Updated 100-Pin Variant BOM.xlsx
    Fixed document sensitivity tag on V100P BOM.xlsx from "protected" to "Public"
    [BOM.xlsx]
2023-12-11 uds LinkControl fixes
    * fix of baudrate settings for '6' 500K and '8' 1M
    * fix of LinkControl 'apply' subfunction to require only 2bytes, not 3 like 'set' subfunction
    update in response to review feedback:
    * keep a length check before data[1] dereference
    [ramn_canfd.c]
2024-02-20 Updated schematics to show BOOT0 resistor settings for STM32L5 microcontrollers
    [LDO.sch, ramn.sch, sc_uc.sch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]
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2024-02-20 Added folder for KiCAD7 schematics of V1
    [LDO.kicad_sch, ramn.kicad_pcb, ramn.kicad_sch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]
2024-02-20 Fixed board setup for DRC to match KiCAD 5 settings
    [ramn.kicad_pcb]
2024-02-20 Added Folder for revC creation (KiCAD7)
    [LDO.kicad_sch, ramn.kicad_pcb, ramn.kicad_sch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]
2024-02-20 Added revC
    [LDO.kicad_sch, ramn.kicad_pcb, ramn.kicad_sch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]
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2024-03-01 Added firmware files and fixed ramn_config.h
    [ramn_config.h]
2024-03-08 removed revB KiCAD7 version
    [LDO.kicad_sch, ramn.kicad_pcb, ramn.kicad_sch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]
2024-03-08 renamed revC folder
    [LDO.kicad_sch, ramn.kicad_pcb, ramn.kicad_sch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]
2024-03-08 removed BETA folder
    [LDO.sch, body.kicad_pcb, body.sch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]
2024-03-08 renamed V1 folder
    [LDO.sch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]
2024-03-08 removed 4-layer version
    [LDO.sch, ramn.sch, sc_uc.sch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]
2024-03-29 Added UDS routine to reset BOOT0 option bytes.
    Added routine to salvage a board on which the wrong firmware was installed, by allowing user to reset the BOOT0 option byte of an ECU with a UDS command. This is mainly for when a user wrongly flashes ECU A firmware to ECU B/C/D and the ECUs now refuse to go into bootloader mode.
2024-03-29 Fixed UDS services (Reset/Link Control) that did not answer before executing (e.g., resetting before sending a positive answer)
    [main.c]
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2024-03-29 fixed check engine LED not lighting up properly
    [ramn_config.h]
2024-03-29 reverted config to ECU A by default
    [ramn_config.h]
2024-04-05 Added Routine Control to enable/disable self-driving algorithm support.
    Self-driving features can be enabled/disabled using Routine Control 0x0207.
    They are disabled by default.
    This prevents the board from ignoring physical controls when the CAN bus is fuzzed (and the ECUs try to interpret self-driving commands instead of controls)
2024-04-05 Changed default CAN Endian to Big Endian
    Undefine USE_BIG_ENDIAN_CAN to revert to Little Endian CAN messages.
    [ramn_config.h]
2024-04-05 Fixed bug when sending RTR message, separated "TXQ full" from other errors.
    [ramn_canfd.c]
2024-04-05 Added RTR feature: ECUs now answer to RTR frames with IDs 0x700 to 0x703 with their hardware ID.
2024-04-05 reverted to logarithmic potentiometer as default
    [ramn_config.h]
2024-04-05 Added feature to let ECU A include slcan messages in its DBC processing.
    This allows updating the values shown on screen when they are sent over slcan (and are technically not received by ECU A from CAN, since ECU A is the sender).
    This does not cover UDS messages and answer to RTR frames.
    Note that ECU A may update the values on screen slightly before the corresponding messages are sent on the CAN bus.
2024-04-17 Added software CRC32; replaced the "random" part of CAN payload with CRC of bytes 0 to 4
    Also updated to latest stm32cubeIDE
    [RAMNV1.ioc, main.c, ramn_crc.c]
2024-04-18 Fixed chip8 screen desync when updating theme in the middle of a game
    [ramn_chip8.h]
2024-04-18 Improved error reporting in slcan
    [main.c, ramn_canfd.c, ramn_canfd.h]
2024-04-18 fixed bug on slcan interface
    [main.c]
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2024-04-19 enabled error report on OBD-II (not standard)
    [main.c]
2024-04-23 Added CAD files
    [ramn-B_Cu.gbr, ramn-B_Mask.gbr, ramn-Edge_Cuts.gbr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]
2024-05-20 Updated minictf to avoid activation during fuzzing
    [ramn_config.h]
2024-06-17 Fixed compile errors when some compile flags are disabled
    [main.c, ramn_config.h]
2024-06-17 fixed SPI screen draw function bug for large image buffers
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2024-07-09 archived 100pin variant
    [BOM.xlsx, LDO.kicad_sch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]
2024-08-14 temporarily removed revC to avoid confusion.
    [LDO.kicad_sch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]
2024-08-16 Ensure no overflow when reading from USB connection
    A check may be performed by the USB ISR that prevents an overflow, but in case it is insufficient and to prevent future vulnerabilities by code changes, a check is added here to ensure an overflow into USBRxBuffer is not possible.
    [main.c]
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2024-10-17 Fixed miniCTF and UDS bugs
    [main.c, ramn_config.h]
2024-12-03 Added Routine Control to add arbitrary DTCs (0x0208)
    Currently only accepting DTC Status byte 0x04.
2025-01-27 Added past CTFs data
    [flag1_sdcard_log.csv, flag2_sdcard_log.csv]
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2025-01-29 add instructions for PCBWay re-orders
    [bom.xlsx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]
2025-01-29 3_powertrain: import changes for the pot sliders available from PCBway
    [powertrain.kicad_pcb]
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2025-01-29 hardware, orders: update expansions panel bom to match current re-order and remove reference and original BOMs since these are in the archive now
    [bom.xlsx]
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2025-01-29 hardware, ordering: add a picture and note on how to order less than 5 assemblies
2025-01-29 hardware, ordering: update all the generated CAD and Gerber files due to change to 3_powertrain for easier ordering of slider pots
    [powertrain-B_Cu.gbr, powertrain-B_Mask.gbr, powertrain-Edge_Cuts.gbr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]
2025-01-29 hardware, ordering: update 0_ramn orders BOM to correct C11 C12 C21 C22 C31 C32 C41 C42 to 1206 part
    [bom.xlsx]
2025-01-30 hardware, ordering: remove knobs from expansion panel bom
    [bom.xlsx]
2025-01-31 Updated memory layout to make RAM protection possible.
    - Also updated to latest STM32CubeIDE version
2025-01-31 Added protection in case someone flashes ECUA.hex by mistake to another ECU (in which case, it does not overwrite option bytes anymore)
    [RAMNV1.ioc, main.c, main.h]
2025-02-02 Added Routine Control to execute arbitrary ARM shellcode
    You can experiment writing ARM shellcode using https://shell-storm.org/online/Online-Assembler-and-Disassembler/ . You can only use ARM (thumb) mode.
    CAN data should be in the same order as "Assembly - Little Endian" window. For example:
    Use [0x01, 0xBE] to force breakpoint 1 (BKPT #1) and halt execution in the debugger.
    Use [0x70, 0x47] to return from shellcode and resume execution (assuming important registers still have their original values).
    Nop is [0x00, 0xBF].
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2025-02-18 orders, pcbway: update pods panel bom to reflect new parts availability from PCBWay (all parts are now available)
    [bom.xlsx]
2025-02-19 add prescaler reset on 's' command
    [ramn_cdc.c]
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2025-02-27 Renamed define to avoid confusion
    [ramn_config.h]
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2025-03-03 hardware, orders: fix 0_ramn expansion sockets: do not mark DNP
    [bom.xlsx]
2025-03-24 gs_usb: fix send of 76bytes from cantact python-can driver. use full GSUSB_RX_DATA_SIZE buffer for receive from host
2025-03-24 gsusb, ramn_config: switch VID/PID by default when ENABLE_GSUSB. needed for both linux driver and python-can driver
2025-04-01 gs_usb: fix CAN recv in gs_usb only configuration due to misplaced #endif
    [main.c]
2025-05-23 Fixed UDS functional addressing issues
    [ramn_canfd.c]
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2025-08-01 Enabled USB debug by default, removed automatic CAN Error register dump
    [main.c, ramn_config.h, ramn_debug.c]
2025-08-01 fixed slcan baudrate settings bug
    [ramn_canfd.c, ramn_canfd.h]
2026-03-06 create g_autoRecoverBusOff variable instead of preprocessor macro
    "automatic recovery from bus-off" setting no longer a preprocessor define macro but a variable that can be changed after boot.
    [main.c, main.h]
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2026-03-06 Added include to prevent build fail without UDS
    [main.c]
2026-03-06 gs_usb: fix compat with AMD xHCI USB
    The AMD xHCI USB host is very very picky . About timings, and
    descriptors and ... well everything.
    This commit gets RAMN gs_usb up to the strict requirements enforeced by
    AMD xHCI. Still works on other Intel USB as well.
    * Fix STM32 HAL USB PCD concurrency bug by adding IRQ-safe critical sections
    * Handle lock failure edge case: re-enable IRQ before returning HAL_BUSY
    * Move USB concurrency fix to usbd_conf.c with USER CODE block protection
    * Fix USB PCD concurrency: add __HAL_LOCK with IRQ critical sections in HAL driver
    * Fix EP2 OUT descriptor: wMaxPacketSize 128->64 for Full-Speed USB compliance
    * Add IAD for GS_USB+DFU interfaces for AMD xHCI compa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
    [ramn_config.h]
2026-03-08 build: be quiet unless there's a problem
    command line builds just print the 4x 'build done 0 errors, 0 warnings'
    lines (one for each ECU)
    CI builds are still noisy
2026-03-10 Use Check Engine LED to report ECU D CAN bus errors
2026-03-10 Added argument to USB CLI command "reset"
    [ramn_cdc.c]
2026-03-22 fix warnings in bitbanging stuff
    [ramn_bitbang.c, ramn_cdc.c]
2026-03-30 Changed command name "replace" to "asap"
    [ramn_cdc.c]
2026-03-31 minor bug fixes, new help page, updated binaries.
    [main.c, ramn_cdc.c]
2026-04-08 fix uart build by disabling CDC
2026-04-08 fix no_extras build by guarding SPI client on all ECUs
2026-04-08 fix kwp build by correcting typos and adjusting buffer sizes
    [main.c, ramn_config.h, ramn_vehicle_specific.h]
2026-04-08 fix kwp build by setting smaller buffer
    [ramn_config.h]
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2026-04-20 firmware: restore joystick decoding in non-J1939 mode
    Restore joystick decoding in standard CAN mode by re-adding the decoding call in CAN_SIM_CONTROL_SHIFT_CANID case. Also fixed a misplaced J1939 guard that was preventing JOYSTICK_BUTTONS from being received even if sent.
    [main.h]
2026-05-14 fixed lighting switch not accepting leftmost position
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2026-06-01 Added compile flag to prevent option byte overwrite
    [main.c, ramn_config.h]
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2026-06-02 fix: encode lighting switch payload in first byte for non-J1939 mode
    The COMMAND_LIGHTS_MASK was 0xFFFF which triggered the USE_BIG_ENDIAN_CAN
    byte-swap in PACK_SIGNAL, placing the value in byte 1 instead of byte 0.
    Changed mask to 0xFF and encode/decode to single-byte operations, matching
    the DBC definition (SG_ Value : 2|3@0+ in byte 0 of CAN ID 0x150).
    Added test_lighting_switch_encoding.py that builds with USE_BIG_ENDIAN_CAN
    to verify the on-wire encoding matches the DBC file.
    [ramn_signal_defs.h]
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2026-06-03 Removed binary constants to avoid warnings
    [main.c]
2026-06-03 fixed no_uds build issue
    [main.c]
2026-06-03 fixed build issues on alternative firmware configurations
    [ramn_bitbang.c]
2026-06-03 fixed uart receive bug
    [main.c]
2026-06-03 fixed "check engine" LED not lighting up in self driving mode
    [ramn_signal_defs.h]
2026-06-03 ci: restore multi-version CubeIDE builds with prepare/warm_cache matrix
    - Add `prepare` job that reads _version.sh default tag, merges with
    CUBEIDE_EXTRA_TAGS env (space-separated, currently "15.0"), deduplicates,
    and outputs a JSON array for downstream matrix expansion.
    - Convert `warm_cache` to a matrix job that caches each Docker image.
    - Add `cubeide_docker_tag` matrix dimension to `build_all` so it builds
    across all declared versions.
    - `macro_coverage` uses the _version.sh default tag only.
    - Artifact names now include the Docker tag to avoid collisions.
    - `commit_firmware` downloads firmware built with the default tag.
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2026-06-08 Revert "Updated shift joystick voltage thresholds"
    This reverts commit c95824383647f7ffb994a6cab9d79b0bf681dbd1.
2026-06-08 Revert "Added potentiometer low pass filters"
    This reverts commit a7917a197d5d7cef7975de47ef7b647ad4342bee.
2026-06-22 Fix USB serial corruption under bidirectional CDC load
    Two USB defects surfaced under simultaneous device->host and host->device
    CDC traffic.
    1. PMA buffer overlap (root cause), usbd_conf.c: on the STM32L5 the packet
    memory is byte-addressed (PMA_ACCESS == 1), so each endpoint must advance
    by its full packet size. The code advanced by PACKET_SIZE/2 (a leftover
    from word-indexed F1/F3 PMA), under-allocating every endpoint and making
    CDC_IN and CDC_OUT overlap by 32 bytes. Under full-duplex load the two
    directions overwrote each other's PMA. Advance by the full packet size and
    raise the size guard to the real PMA capacity (1024).
    2. Zero-copy TX buffer reuse, ramn_usb.c: th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

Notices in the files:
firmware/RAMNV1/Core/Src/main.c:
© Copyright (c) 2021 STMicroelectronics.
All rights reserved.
